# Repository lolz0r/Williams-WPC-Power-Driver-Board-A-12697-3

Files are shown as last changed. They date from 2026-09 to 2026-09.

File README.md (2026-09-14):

# Williams WPC power/driver replacement

> **WARNING: These are unverified, experimental boards. Use at your own risk.**
> No variant has been physically validated or qualified for production. Simulation
> results, CAD checks and manufacturing files do not establish safe or reliable
> operation. Errors may damage the board, connected equipment or pinball machine.
> Independently review the design and complete first-article testing before use.

This project develops a modern replacement for the Williams **A-12697-3 WPC
Power/Driver Board**, with **Star Trek: The Next Generation L7** as the documented
compatibility and emulation target. It provides rectified supplies, regulated
5 V and 12 V rails, 28 coil/flasher outputs, an 8×8 lamp matrix and five general
illumination triac channels. The board has no firmware. Compatibility with every
A-12697 installation has not been established.

## Variants and sourcing options

| Location | What it contains | Quantity and status |
| --- | --- | --- |
| [JLC-100](variants/jlcpcb-100/README.md) | Latest separate native KiCad variant, derived from JLC-3 with stocked alternative parts, mixed SMT/through-hole assembly files and connector-orientation guides. | Electronics selected for **100 boards plus spares**, using dated JLCPCB inventory snapshots. Experimental; software checks pass, physical and assembler acceptance gates remain open. |
| [JLC-3](variants/jlcpcb/README.md) | Earlier JLCPCB prototype with TPS552892 buck-boost supplies. Its CAD and exports are independent of JLC-100. | Prototype revision with procurement shortfalls. Its standard upload pair covers SMT; through-hole/manual parts and hardware use separate lists. |
| [DigiKey one-board sourcing proposal](variants/jlcpcb-100/output/digikey-1/README.md) | Alternative procurement BOM and itemized USD pricing based on the JLC-100 design. **This is not another released PCB or CPL.** | **One board, no production spares.** Some parts are proposed substitutes requiring engineering review; F115 remains unresolved and unpriced. |
| [Original cost-reduced project](docs/RELEASE_STATUS.md) at the repository root | Preserved parent CAD, earlier regulator design, simulation work and release-candidate exports. | Earlier engineering candidate with its own unresolved verification gates. Root `output/` does not contain the JLC-100 variant. |

Choose the variant first, then use its matching CAD, Gerbers, BOM and CPL.
Substitutions, packages and placement rotations differ between variants.
JLC-1/JLC-2 archives under `variants/jlcpcb/output/` are historical snapshots.

## JLC-100: Gerbers, BOM and centroids

For the latest JLCPCB variant, start with these files:

| File | Purpose |
| --- | --- |
| [Gerbers and drills ZIP](variants/jlcpcb-100/output/release-candidate/gerbers-and-drills.zip) | Bare-board fabrication layers and plated/non-plated drills. |
| [Combined electronics BOM.csv](variants/jlcpcb-100/output/release-candidate/jlcpcb-assembly/BOM.csv) | JLCPCB upload BOM covering all SMT and through-hole electronics, holders and fuse cartridges. |
| [Matching CPL.csv](variants/jlcpcb-100/output/release-candidate/jlcpcb-assembly/CPL.csv) | Matching component centers and corrected supplier placement rotations. Use with the combined BOM above. |
| [BOM/CPL bundle ZIP](variants/jlcpcb-100/output/wpc-JLC-100-BOM-CPL.zip) | Combined upload pair with assembly reference material. |
| [Complete prototype package ZIP](variants/jlcpcb-100/output/wpc-sttng-JLC-100-prototype.zip) | Native CAD, fabrication and assembly outputs, sourcing and recorded verification evidence. |
| [Complete components BOM](variants/jlcpcb-100/output/release-candidate/bom/all-components.csv) | Human-readable assembly/procurement record, including external hardware and zero-quantity DNP/board features. |
| [100-board electronics purchase BOM](variants/jlcpcb-100/output/release-candidate/bom/jlc-electronics-purchase.csv) | Order quantities and stock evidence, including procurement spares. This is not the upload BOM. |
| [External hardware BOM](variants/jlcpcb-100/output/release-candidate/bom/external-hardware.csv) | Heatsinks, screws, nuts and thermal paste for separate procurement and manual fitting. |
| [Native KiCad PCB](variants/jlcpcb-100/wpc_power_driver_cost.kicad_pcb), [schematic](variants/jlcpcb-100/wpc_power_driver_cost.kicad_sch) and [assembly preview](variants/jlcpcb-100/output/release-candidate/3d/perspective.png) | Source design and nominal assembled geometry. |

The combined upload pair describes **one board**. Select the production quantity
in the assembly order; do not multiply CPL entries or include purchasing spares
as placements. There are **440 electronic pieces per board: 345 SMT, 82 soldered
through-hole pieces and 13 inserted fuse cartridges**, grouped into 69 catalog
parts. J115 is purchased as two six-position headers. Separate fuse holders and
cartridges account for the other expanded references.

Read the [upload and manual-assembly instructions](variants/jlcpcb-100/docs/JLCPCB_UPLOAD.md)
and provide the [PCBA remarks](variants/jlcpcb-100/output/release-candidate/jlcpcb-assembly/PCBA-remark.txt).
The cartridge CPL entries use a documented 0.3 mm selection offset for stacked
parts; their physical centers remain at the holders. Heatsinks, fasteners and
paste are in the complete BOM but require separate sourcing and assembly
agreement. An accepted electronics upload alone does not establish complete
mechanical assembly.

Use the [connector orientation guide](variants/jlcpcb-100/output/release-candidate/jlcpcb-assembly/connector-orientation-guide.pdf)
and [preview review notes](variants/jlcpcb-100/docs/CONNECTOR_PREVIEW_REVIEW.md)
to resolve supplier-library discrepancies. The current CPL includes U1 = 90°,
U2/U3 = 270°, J110 = 180° and J113 = 90°; do not apply those offsets again.
J120/J121/J126 are present as C592598 / TE 1-640445-3 and need explicit part
selection and the documented header preparation. Several connector and rectifier
orientations still require assembler review.

For SMT-only work, use the separate [SMT BOM](variants/jlcpcb-100/output/release-candidate/bom/jlc-smt-bom.csv)
and [SMT CPL](variants/jlcpcb-100/output/release-candidate/assembly/jlc-smt-cpl.csv),
with the [through-hole/manual BOM](variants/jlcpcb-100/output/release-candidate/bom/jlc-through-hole-manual.csv)
for the remaining electronics. Generic engineering position reports are not the
assembly upload pair.

The JLC-100 fabrication specification is **four layers, 1.6 mm nominal FR-4,
2 oz finished outer copper / 1 oz inner copper** (70/35/35/70 µm), ENIG and at
least 20 µm finished plated-hole barrel copper. The outline is
449.152 × 272.910 mm. See [FABRICATION.txt](variants/jlcpcb-100/output/release-candidate/FABRICATION.txt)
and [READINESS.json](variants/jlcpcb-100/output/release-candidate/READINESS.json)
for the exact requirements and outstanding gates.

## DigiKey: one-board BOM and pricing

- [DigiKey BOM.csv](variants/jlcpcb-100/output/digikey-1/DigiKey-BOM.csv): original
  and proposed parts, order numbers, references, required/purchase quantities,
  through-hole parts, hardware and substitution notes.
- [Itemized pricing.csv](variants/jlcpcb-100/output/digikey-1/DigiKey-pricing.csv):
  per-part USD prices, quantity breaks, stock snapshots, product source links,
  extended costs and subtotal/complete-total rows.
- [Totals.csv](variants/jlcpcb-100/output/digikey-1/DigiKey-totals.csv): category
  subtotals, minimum-purchase overhead and missing-cost status.
- [DigiKey package ZIP](variants/jlcpcb-100/output/DigiKey-one-board.zip) and
  [sourcing explanation](variants/jlcpcb-100/output/digikey-1/README.md).

The September 14, 2026 estimate has a **$405.60 USD priced purchase subtotal**,
including minimum hardware purchase quantities. Parts allocated to one board
account for $363.30, including one complete thermal-paste syringe; $42.30 is
minimum-purchase excess. Freight, taxes, tariffs, PCB fabrication and assembly
are additional.

**This is a partial estimate: 78 of 79 required procurement lines are priced.**
F115's 0.75 A ceramic time-delay fuse remains required and unpriced, so the final
complete-BOM total is blank. The 28 priced candidate/accessory lines require
engineering review; the JLC-100 SPICE results do not qualify these substitutions.
No DigiKey-specific PCB, Gerbers or CPL has been released.

## Verification and reproduction

JLC-100 retains 230 passing ngspice engineering cases and recorded CAD,
manufacturing, inventory and assembly-file checks. These use engineering models,
including an averaged supply controller. They do not establish physical thermal,
fault, startup, harness-fit or production performance. Stock snapshots are not
reservations. Supplier part selection and manual operations remain review items.

See the variant's [simulation scope](variants/jlcpcb-100/docs/SPICE_SCOPE.md),
[inventory and assembly notes](variants/jlcpcb-100/docs/INVENTORY_AND_ASSEMBLY.md),
[first-article procedure](variants/jlcpcb-100/docs/FIRST_ARTICLE.md), and
[accepted verification manifest](variants/jlcpcb-100/output/release-candidate/reports/verification-manifest.json).
The later [native connector-tab audit](variants/jlcpcb-100/output/verification/revision/native-connector-tabs.json)
checks 37 single-row connector wall directions in nominal CAD; J113 and physical
cable compatibility retain the documented limitations. That audit and the
DigiKey proposal are additional repository records outside the existing complete
prototype ZIP.

Each variant's routed native PCB is authoritative. Open it with its adjacent
schematics, local symbols, footprints and models. Historical placement generators
and one-time migrations must not overwrite the routed source. Follow the chosen
variant's README and verification instructions when regenerating exports.

The large catalog-search cache is retained as lossless gzip; see the
[research storage notes](variants/jlcpcb-100/research/README.md) to unpack it.

The DigiKey CSVs can be regenerated from their saved pricing facts at the
repository root:

```sh
python3 variants/jlcpcb-100/tools/build_digikey_one_board.py
```

For the preserved parent project, use its [release status](docs/RELEASE_STATUS.md),
[verification instructions](docs/VERIFICATION.md), [Gerbers](output/release-candidate/gerbers-and-drills.zip),
[purchase BOM](output/release-candidate/bom/purchase-bom.csv),
[schematic PDF](output/release-candidate/schematic/schematic.pdf) and
[fabrication specification](output/release-candidate/FABRICATION.txt).
Older root exports directly under `output/` are superseded by the parent's
`output/release-candidate/`. The [historical design narrative](docs/HISTORICAL_DESIGN.md)
records earlier selections and estimates.

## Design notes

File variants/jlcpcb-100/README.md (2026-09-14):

# JLC-100 inventory variant

> **WARNING: These are unverified, experimental boards. Use at your own risk.**
> No physical board has been validated or qualified for production. Passing
> simulation and CAD checks do not establish safe or reliable operation. Errors
> can damage connected equipment; independently review and test a first article.

See the [repository overview](../../README.md) for the preserved parent project,
the earlier [JLC-3 prototype](../jlcpcb/README.md), and the separate
[one-board DigiKey sourcing proposal](output/digikey-1/README.md).

An independent KiCad variant of JLC-3, with electronics selected from public JLCPCB stock for **100 boards plus spares**. The original source files are preserved. Gerbers, drills, BOMs, centroids, schematic/assembly PDFs and a STEP assembly are generated from the updated native design.

**Status: software-checked engineering prototype.** The electronics stock audit passes; required heatsinks, fasteners and thermal paste are external purchases. These items are included in the complete assembly BOM, with heatsinks and fasteners represented in the assembly models. No stock is reserved, and no order has been placed. Physical first-article qualification remains necessary before committing the full run.

- [Complete package](output/wpc-sttng-JLC-100-prototype.zip)
- [Gerbers and drills](output/release-candidate/gerbers-and-drills.zip)
- **[JLCPCB combined SMT + through-hole BOM](output/release-candidate/jlcpcb-assembly/BOM.csv)** and **[matching CPL](output/release-candidate/jlcpcb-assembly/CPL.csv)**
- [BOM/CPL download bundle](output/wpc-JLC-100-BOM-CPL.zip) and [upload/manual assembly instructions](docs/JLCPCB_UPLOAD.md)
- [Complete procurement and hardware record](output/release-candidate/bom/all-components.csv)
- [100-board electronics purchasing BOM](output/release-candidate/bom/jlc-electronics-purchase.csv)
- [Optional SMT-only BOM](output/release-candidate/bom/jlc-smt-bom.csv) and [SMT centroids](output/release-candidate/assembly/jlc-smt-cpl.csv)
- [Through-hole/manual BOM](output/release-candidate/bom/jlc-through-hole-manual.csv) and [engineering placement details](output/release-candidate/assembly/electronics-placement-details.csv)
- [Native board](wpc_power_driver_cost.kicad_pcb), [schematic](wpc_power_driver_cost.kicad_sch) and [assembly preview](output/release-candidate/3d/perspective.png)

For the requested complete electronics assembly, use the combined BOM/CPL pair above. It describes one board and contains 440 matching references, including both J115 headers and separate fuse cartridges/holders. Select 100 boards in the assembly order; procurement spares are not extra placements. Copy [PCBA-remark.txt](output/release-candidate/jlcpcb-assembly/PCBA-remark.txt) into the order remarks: the cartridge CPL entries have a documented 0.3 mm selection offset for stacked assembly. The prior `all-electronics-positions.csv` filename now aliases the valid combined CPL; it must be paired with the new combined BOM. The [local upload audit](output/release-candidate/reports/jlc-assembly-check.json) checks file coverage, centers and library orientation evidence; live JLCPCB import and assembly acceptance have not been tested.

The design has **426 populated electronic references: 345 SMT and 81 through-hole**. Purchasing includes **440 electronic pieces per board**, accounting for separate fuse holders and the two-piece J115 header. Of the SMT placements, **204 are Basic**. All 69 electronic catalog codes pass a quantity check of 100 times per-board usage plus the larger of 10 pieces or 5% spares. The September 13, 2026 Pacific / September 14 UTC snapshots use the smaller of public stock and orderable quantity. The estimated electronics cost including spares is **US$8,524.49**; PCB fabrication, assembly, external hardware, shipping and tax are additional.

In assembly terms, those 440 purchased pieces are **345 SMT, 82 soldered
through-hole pieces and 13 inserted fuse cartridges**. The 81 native through-hole
references combine some holders/cartridges and represent J115 as one reference.
The [external hardware BOM](output/release-candidate/bom/external-hardware.csv)
adds heatsinks, fasteners and thermal paste; these require separate procurement
and agreement on fitting them.

The [connector orientation guide](output/release-candidate/jlcpcb-assembly/connector-orientation-guide.pdf)
and [preview review notes](docs/CONNECTOR_PREVIEW_REVIEW.md) explain the remaining
supplier-library/manual assembly gates. Current CPL rotations include U1 = 90°,
U2/U3 = 270°, J110 = 180° and J113 = 90°. The subsequent
[native connector-tab audit](output/verification/revision/native-connector-tabs.json)
checks 37 single-row headers in nominal CAD; J113 and physical cable fit retain
the documented limitations. This later audit is in the repository, outside the
existing complete prototype ZIP.

## Separate DigiKey estimate: one board

- [DigiKey BOM.csv](output/digikey-1/DigiKey-BOM.csv)
- [Itemized prices and total rows.csv](output/digikey-1/DigiKey-pricing.csv)
- [Cost breakdown.csv](output/digikey-1/DigiKey-totals.csv)
- [DigiKey ZIP](output/DigiKey-one-board.zip) and [scope/limitations](output/digikey-1/README.md)

This procurement proposal assumes **one board with no production spares**. Its
priced purchase subtotal is **$405.60 USD**, including minimum hardware order
quantities. It prices 78 of 79 required lines; F115's 0.75 A ceramic time-delay
fuse remains unresolved and unpriced. Proposed substitutes are flagged for
engineering review and are not qualified by the JLC-100 simulations. The proposal
does not change this variant's PCB, Gerbers or JLCPCB BOM/CPL.

## Recorded verification

The accepted verification contains **230 passing ngspice engineering cases**, covering supply startup/load/restart/prebias and tolerances, replayed drivers, GI, blanking, capacitor ripple and rectifier startup. Native ERC has zero violations. PCB DRC has zero errors, zero unconnected items and zero schematic parity issues; 178 warnings have documented dispositions. Independent Gerber/drill/BOM checks pass 7,909 checks; the inventory design audit passes 219 and the controller land-pattern audit passes 152. The mechanical review reports no collisions or missing models. Eight simultaneous rectifier thermal sensitivity cases pass their stated screening targets (SMT maximum 119.4°C; through-hole maximum 141.2°C at 50°C ambient).

The stiffest simulated crest-start case reaches **244.8 A in one rectifier leg against its 250 A single-pulse rating**. Real winding impedance, hot/cold starts, current sharing, loaded supply waveforms, thermal boundaries and harness fit require measurement. The SPICE models are engineering fits, including an averaged supply controller; they do not establish production qualification. Several stocked connectors need documented trimming/key preparation, and F112 is a soldered time-lag fuse.

Read [inventory and assembly instructions](docs/INVENTORY_AND_ASSEMBLY.md), [simulation scope](docs/SPICE_SCOPE.md), [first-article procedure](docs/FIRST_ARTICLE.md), [DRC warning review](docs/DRC_WARNING_REVIEW.md) and [original project audit](docs/ORIGINAL_PROJECT_AUDIT.md). The package contains dated stock evidence, exact model/deck/log files and checksums. `output/release-candidate/reports/verification-manifest.json` identifies accepted evidence; earlier rejected trials in the working tree are not accepted results.

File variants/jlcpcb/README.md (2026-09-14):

# JLC-3 prototype revision

> **WARNING: These are unverified, experimental boards. Use at your own risk.**
> No physical board has been validated or qualified for production. Simulation
> and CAD checks do not establish safe operation; errors can damage connected
> equipment. Complete independent review and first-article testing before use.

This is the earlier JLC-3 prototype. The separate [JLC-100 variant](../jlcpcb-100/README.md)
contains the later 100-board inventory selection and combined SMT/through-hole
BOM/CPL. See the [repository overview](../../README.md) for all variants and the
[one-board DigiKey proposal](../jlcpcb-100/output/digikey-1/README.md) for separate pricing.
Use files from one variant together; this directory's SMT pair is not the
JLC-100 mixed-assembly pair.

The current board uses TPS552892 buck-boost supplies and a reworked regulator layout.
See [prototype build and verification](docs/PROTOTYPE_JLC3.md) and
[release status](docs/RELEASE_STATUS.md).

Use these matching current exports:

- [Complete JLC-3 prototype package](output/wpc-sttng-JLC-3-prototype.zip)
- [Gerbers and drills](output/release-candidate/gerbers-and-drills.zip)
- [JLCPCB SMT BOM](output/release-candidate/bom/jlc-smt-bom.csv)
- [JLCPCB SMT centroids / CPL](output/release-candidate/assembly/jlc-smt-cpl.csv)
- [Through-hole/manual parts](output/release-candidate/bom/jlc-through-hole-manual.csv)
- [Complete components BOM](output/release-candidate/bom/all-components.csv),
  [electronics purchase BOM](output/release-candidate/bom/jlc-electronics-purchase.csv)
  and [external heatsinks/fasteners/paste](output/release-candidate/bom/external-hardware.csv)

`READINESS.json` and `SHA256.json` identify the exact validated output.
Older JLC-1/JLC-2 archives are historical. The original project at the repository root remains preserved.

For JLC-3 export/verification, run `tools/export_release.py`,
`tools/export_jlc_bom.py`, `tools/verify_release.py`,
`tools/verify_variant_source.py`, `tools/verify_regulator_fixtures.py`,
`tools/summarize_prototype.py`, `tools/verify_ryq.py`, then
`tools/package_prototype.py` with the project dependencies installed.
The simulator evidence is retained under `output/verification/prototype-readiness`.
Old generator and packaging commands in the historical section below describe JLC-2.

JLCPCB assembly needs the [flagged short-stock parts](output/release-candidate/bom/procurement-shortfalls.csv)
sourced before assembly. The bare-board fabrication package is complete.

---

## Historical JLC-2 notes

The following describes the previous revision. Links into `output/release-candidate/`
now resolve to the current JLC-3 export; use the dated JLC-2 archives for the older
snapshot. Historical quantities and component choices below do not describe JLC-100.

# WPC power/driver board — JLC-2

**JLCPCB electronics redesign, 2026-09-11. Engineering review candidate; not production qualified.**

This is a separate version of the STTNG L7 / Williams A-12697-3 replacement. All populated electronics have purchasable JLCPCB catalog matches. Heatsinks, fasteners and thermal paste retain their existing specifications and may come from other suppliers, as requested. The parent board and schematics are preserved.

JLC-2 includes the flasher-clamp correction found in the additional pre-spin review. **Hold an assembled prototype order:** regulator voltage/backfeed findings and lamp-matrix numerical convergence remain unresolved. The [latest analog-review addendum](docs/CONTINUED_ANALOG_REVIEW.md) establishes convergence of the selected coil replay and adds source-headroom and CPU switch-margin checks. The [earlier verification report](docs/PRESPIN_VERIFICATION.md) retains the original results and failures. Physical fit, thermal and fault qualification also remain open.

## Files to use

- [Native KiCad board](wpc_power_driver_cost.kicad_pcb), [project](wpc_power_driver_cost.kicad_pro) and [schematic](wpc_power_driver_cost.kicad_sch). Project-local symbols, footprints and STEP models are included.
- [Complete review archive](output/JLC-2-review.zip) and [native CAD archive](output/JLC-2-native-cad.zip).
- [Schematic PDF](output/release-candidate/schematic/schematic.pdf), [assembly drawing](output/release-candidate/assembly/assembly.pdf), [STEP assembly](output/release-candidate/3d/board.step), [top](output/release-candidate/3d/top.png) and [perspective](output/release-candidate/3d/perspective.png) renders.
- [Electronic purchase BOM](output/release-candidate/bom/jlc-electronics-purchase.csv). Upload the [SMT BOM](output/release-candidate/bom/jlc-smt-bom.csv) together with the [SMT placement file](output/release-candidate/assembly/jlc-smt-cpl.csv). Through-hole/manual parts and external hardware have separate lists in the same BOM directory.
- [Gerbers and drills](output/release-candidate/gerbers-and-drills.zip), [fabrication specification](output/release-candidate/FABRICATION.txt), [readiness](output/release-candidate/READINESS.json) and [verification report](docs/VERIFICATION.md).

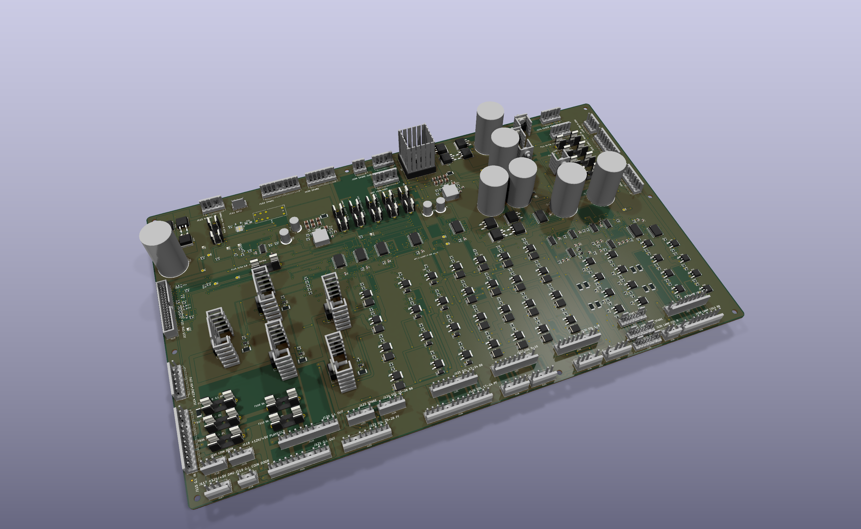
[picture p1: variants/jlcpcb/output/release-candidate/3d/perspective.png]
JLC-2 perspective


## What changed

| Change | Reason |
|---|---|
| SR1/SR2 replaced by R310–R325, sixteen Basic 4.7 kΩ 0805 resistors | Remove the Extended SIP arrays while preserving all sixteen used pull-up connections. The two unused array elements are omitted. New routing connects to the existing bus and +5 V copper. |
| Common 0805 resistors, 100 nF/10 nF/33 nF capacitors, LEDs and signal diodes use Basic parts | Preserve the required values, ratings and packages. |
| Eight flasher clamp diodes use Basic MDD M7 | Retain 1 A / 1000 V SMA rectifiers; additional SPICE wiring-inductance and temperature sensitivities included. |
| R192 changes from 270 Ω to Basic 470 Ω | Reuse an existing Basic value; +5 V LED current remains 4.95–7.74 mA over the checked voltage/tolerance range. Expect reduced brightness. |
| HCT buffers/latches use TI SN74HCT240DWR / SN74HCT574DWR | JLCPCB sourcing while retaining TTL input thresholds. HC parts are not equivalent at this interface. TI worst-case timing was checked. |
| C2/C4/C9/C12 use Panasonic EEU-FR1E331B | The **B suffix provides factory-formed 5 mm lead spacing**, matching the PCB. The 8 × 11.5 mm body model replaces the oversized model; pad positions and the conservative 10 mm courtyard are retained. |
| Molex ordering-number aliases resolved to purchasable listings | Same connector identities and geometry; consignment-only listings were rejected. |
| SOL21–SOL28 diode cathodes connected to +20 V on the board | STTNG leaves these tieback pins open. The added copper prevents the flasher harness from relying on MOSFET avalanche. No components added. |
| JLC-2 labels and portable libraries/models | Clearly identify the new revision and open it without the old Mac installation. |

Existing components retain their positions and pad geometry. JLC-2 merges SOL21–SOL28_TB into +20 V; other existing pad nets remain unchanged. The board remains 449.152 × 272.910 mm, four layers, 1.6 mm nominal, with **70/35/35/70 µm finished copper**, ENIG and at least 20 µm finished plated-barrel copper. Mounting geometry and the cooling arrangement are retained. R319 was relocated after an independent 3D check detected contact with the conservative fuse-holder envelope; the final model has no reported intersections.

## Sourcing result

| Inventory | Count |
|---|---:|
| Populated electronic references in the native design | 405 |
| SMT placements | 330 |
| Basic placements / distinct Basic codes | 194 / 15 |
| Extended SMT placements | 136 |
| Distinct Extended codes, including through-hole parts | 54 |
| Total distinct JLCPCB codes | 69 |
| Purchased electronic units, including separate fuse clips | 435 |

All 69 public listings were checked for `isBuyComponent=1`, exact normalized ordering-number match and Basic/Extended classification. A listing is not a reservation or assembly quote. **Twelve types need preorder or replenishment for one board**, including the 28 solenoid MOSFETs, large reservoir capacitors, bridge diodes and 32 fuse clips. Quantities, snapshot stock, dates and catalog links are recorded in the purchase BOM and [sourcing audit](output/release-candidate/reports/jlc-sourcing.json).

Extended parts remain where a suitable Basic replacement was not established: the 100 V logic-level power MOSFETs, rated rectifiers and reservoirs, HCT logic, regulators, precision feedback/UVLO resistors, C0G compensation capacitors, exact connectors and fuses. The Basic 470 pF candidates found were X7R, not the selected C0G compensation part. This is a documented selection, not a proof of the lowest possible cost across every future catalog entry.

## Assembly and qualification

The SMT upload pair covers only the 330 SMT references. Use [through-hole/manual BOM](output/release-candidate/bom/jlc-through-hole-manual.csv), [32 clip centers](output/release-candidate/assembly/fuse-clip-centers.csv) and [external hardware BOM](output/release-candidate/bom/external-hardware.csv) for the remaining assembly. F101/F102 take two clips each and **no cartridge**; F103–F116 take two clips plus the specified cartridge. There are fourteen cartridges total. Do not double-count the clips from the generic BOM.

JLCPCB's actual assembly preview must confirm rotation, polarity, pin 1, body centers and exposed-pad stencil treatment. CPL coordinates use the same absolute origin as the Gerbers, with negative Y and normalized native KiCad rotations. No order, upload or supplier message has been submitted.

Follow the retained [connector-key schedule](docs/ASSEMBLY_NOTES.md) and [first-article procedure](docs/ASSEMBLY_AND_FIRST_ARTICLE.md). **STTNG only:** J122 pins 5, 6, 8, 9 and J126 pins 10–13 now carry +20 V as flasher-clamp returns. These pins are unused in the STTNG harness; J126 pin 9 remains the key. Do not connect a different-voltage tieback harness. J106/J111 also retain the parent design's differences; this is not a universal A-12697 replacement. Nominal or conservative CAD envelopes cannot establish cabinet fit, harness access, screw engagement or tolerance clearance. The generic fuse-holder envelope is deliberately conservative and is not an exact Keystone 3517 solid model.

The routed native PCB is authoritative. Do not rerun the historical placement/project generators or one-time migration tools over it. `parts-selection-draft.json`, research alternatives and `docs/baseline/` are historical working material, not the purchasing or release authority.

Primary substitution references: [Panasonic formed-lead capacitor](https://industrial.panasonic.com/tw/products/pt/aluminum-cap-lead/models/EEUFR1E331B), [MDD M7](https://www.microdiode.com/uploadfiles/PDF/M1-THRU-M7-SMA.pdf), [TI HCT240](https://www.ti.com/lit/ds/symlink/sn74hct240.pdf), [TI HCT574](https://www.ti.com/lit/ds/symlink/sn74hct574.pdf). Every selected JLCPCB listing is linked in the purchase BOM.

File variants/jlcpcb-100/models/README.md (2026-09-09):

# Mechanical models

`tools/make_mechanical_models.py` generates project STEP envelopes using OpenCascade.
They are dimensional review aids, not manufacturer production CAD. Fin slots, lead
bends, fastener threads and nut profiles are simplified. Native KiCad component
models are resolved from the installed KiCad library; those models retain their
upstream licenses. No manufacturer CAD or vendor SPICE redistribution is implied.

Controlled dimensions come from TDK B41252, Nichicon LLS, Bourns SRP1265A, Molex
SDA-41791 and Boyd board-level cooling drawings. Current selected heatsinks are
577202B00000G, 7020BG and 6223BG. Older 7019/6224/5771 envelopes are historical
experiments and are not selected by the current board. Hardware envelopes include
M3×8, M3×12 and M4×16 screws/nuts. The native TO-220 leads are untrimmed.

The 3.96 mm headers now use dimensioned KK396 envelopes instead of scaled KK254
models. Stock full-pin headers still need OEM key-pin preparation. Models describe
nominal geometry; component tolerance, cabinet fit, solder and mating-harness access
are separate checks. See `docs/ASSEMBLY_AND_FIRST_ARTICLE.md`.

J113 uses the project N2534-6002-RB nominal envelope, including solder standoff.
`tools/connector_keys.py --models` makes keyed header variants by removing the
specified pin column. KK254 variants derive from the installed KiCad Connector_Molex
models; KK396 variants derive from the project dimensioned envelopes.
The original full-pin models remain available as manufacturing stock-part references.

The M4 hardware head envelope (7.6 mm diameter × 3.0 mm) conservatively bounds the selected Kanebridge MJ416MPP head (6.75 × 2.60 mm); shaft remains M4 × 16 mm.

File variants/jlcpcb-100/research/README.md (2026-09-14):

# Research snapshots

The selected-part evidence, inventory searches, orientation records and DigiKey
pricing facts are retained here. These are dated research inputs, not stock
reservations or component qualification.

The broad catalog-search cache is stored losslessly as
[search-index.json.gz](search-index.json.gz), because its uncompressed JSON exceeds
GitHub's regular-Git file-size limit. [search-index-storage.json](search-index-storage.json)
records both sizes and SHA-256 hashes. The uncompressed local copy is ignored.

To restore the JSON when needed, run from the repository root:

```sh
gzip -dk variants/jlcpcb-100/research/search-index.json.gz
```

The committed release artifacts and their selected-part evidence retain their
existing names and hashes. The compressed cache does not change the PCB, BOM,
CPL, Gerbers or recorded simulation results.

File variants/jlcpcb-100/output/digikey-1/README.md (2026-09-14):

# DigiKey sourcing estimate — one board

> **WARNING: These are unverified, experimental boards. Use at your own risk.**
> This sourcing proposal does not qualify the board or its substitute components.
> Independent engineering review and physical first-article testing are required.

Prepared 2026-09-14 in USD for **one populated board, without production spares**,
using the current `variants/jlcpcb-100` design as the source. The original variant
name does not change this quote's board quantity.

- [DigiKey-BOM.csv](DigiKey-BOM.csv): quantities, original and selected parts,
  DigiKey order numbers, all electronic references, hardware, and review notes.
- [DigiKey-pricing.csv](DigiKey-pricing.csv): itemized prices and purchase costs,
  followed by a priced subtotal and the unresolved complete-total row.
- [DigiKey-totals.csv](DigiKey-totals.csv): category subtotals, minimum-purchase
  overhead, exclusions, and completeness status.
- [source-reference-coverage.csv](source-reference-coverage.csv): maps every row
  in the source BOM to this sourcing BOM.
- [validation.json](validation.json): quantity, price and coverage checks, with
  hashes of the unchanged PCB and release inputs.

## Cost and completeness

| Amount | USD |
| --- | ---: |
| Priced electronics, including candidates | 300.65 |
| Hardware purchase quantities | 78.24 |
| One 3mL thermal-paste syringe | 14.33 |
| Added fuse-holder covers | 12.38 |
| **Priced purchase subtotal** | **405.60** |
| Parts allocated to one board, including the full paste syringe | 363.30 |
| Minimum-purchase excess included in the purchase subtotal | 42.30 |
| **Complete BOM total** | **Unresolved** |

**78 of 79 required procurement lines are priced. F115 is still required and
unpriced.** The specified Reomax 5.250.0750A is a 0.75A ceramic time-delay 5x20mm
fuse. No DigiKey replacement matching that requirement was verified. The
Littelfuse 0239.750TXP has a glass body and only 35A breaking capacity, so it was
excluded. Its price is not silently used to fill the gap. Compare the
[original Reomax specification](https://wmsc.lcsc.com/wmsc/upload/file/pdf/v2/lcsc/2303300930_Reomax-BTC0750_C5381743.pdf)
with the [DigiKey listing for the rejected fuse](https://www.digikey.com/en/products/detail/littelfuse-inc/0239-750TXP/3424896).

Prices are estimates from public DigiKey US product pages retrieved on
2026-09-14. The pages are cached, and their crawl ages are recorded per line.
They are not a live checkout quote or reserved inventory. All 78 priced lines
show sufficient stock for their purchase quantities in the recorded snapshots.
Every item includes its supporting product URL. Tax, tariffs, freight, fees,
PCB fabrication, assembly labor, tooling, and other process consumables are
excluded.

The five screw/nut lines have lowest published price tiers of 100 pieces. Their
purchase quantities are 100 each, even though the board uses only 1–9 of each.
The excess is reusable hardware stock. Other lines use the exact required
quantity, without rounding up to obtain price breaks. Cut tape is selected for
SMT parts; no Digi-Reel fee is included. Line amounts are rounded to cents using
decimal arithmetic before totals are summed.

## Design coverage and substitution limits

The source design has 440 purchased electronic units: **345 SMT, 82 soldered
through-hole units, and 13 fuse cartridges**. The BOM also includes 30 original
hardware pieces and one thermal-paste syringe provision. J115 buys two headers,
represented as J115A and J115B. There are 23 DNP or fabricated board features
shown with zero purchase quantity; those are excluded from pricing.

The proposed SCHURTER 0031.8201 holders need **15 separate 0853.0551 covers**,
including covers for the two empty holders. Their pairing is documented in the
[SCHURTER OGN drawing](https://media.digikey.com/pdf/Data%20Sheets/Schurter%20PDFs/DS_486_Fuseholders.pdf).
Fit to the existing Hongju footprint and surrounding parts still needs review.

There are 28 priced candidate/accessory lines and one unresolved requirement.
Candidates include replacement resistors, capacitors, diodes, LEDs, a transistor,
triacs, fuses, fuse holders, the J113 header, and the M4 screw. Their original
parts remain visible alongside the proposed DigiKey parts. The detailed review
requirements are in the BOM's Notes column.

Specific sourcing decisions:

- The original 10uF Samsung capacitor has zero stock in the retrieved product
  snapshot; a Taiyo Yuden 10uF/50V/X7R/1210 candidate is priced.
- The original BTA08-600CRG product page showed two units, despite a conflicting
  search snapshot showing 2002. The quote instead prices five BTA08-800CRG
  candidates. Review all trigger quadrants, pin/tab drawing and thermal ratings.
- F112 uses the proposed Bel Fuse 0680H7000-05, rated 7A and 125VAC/125VDC, with a
  slow-blow response. Time-current and protection coordination remain unverified.
  The initially considered Littelfuse 0454007.MR was rejected because its AC
  rating is 72V.
- D101–D104 use a proposed STPS40150CT 150V Schottky pair. Forward-loss and thermal
  performance must be checked against the original 100V part and its heatsink.
- Existing connector trimming/key-pin preparation and BR3 lead forming remain
  necessary where the original selected part is retained. The different J113
  housing needs its own fit and cable check.

This is a **sourcing proposal**, not a new released PCB variant. The existing
SPICE results qualify the existing modeled design and do not establish that
these proposed substitutions are equivalent. No PCB, Gerber, JLC BOM, or CPL was
changed, and no new DigiKey-specific CPL is implied. Engineering review and any
necessary design changes precede using these candidates for assembly.

Regenerate from the saved sourcing facts with:

```sh
python variants/jlcpcb-100/tools/build_digikey_one_board.py
```

Research inputs are in `variants/jlcpcb-100/research/digikey-1/`.

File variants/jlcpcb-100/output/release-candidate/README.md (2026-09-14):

# JLC-100 engineering prototype package

For complete SMT and through-hole electronics assembly, upload `jlcpcb-assembly/BOM.csv` and `jlcpcb-assembly/CPL.csv` with `gerbers-and-drills.zip`. The matching pair contains all 440 electronic pieces per board (345 SMT plus 95 THT/inserted parts). Use `jlcpcb-assembly/PCBA-remark.txt` and `placement-map.csv` for separate fuse holders/cartridges and prepared connectors. Read `docs/JLCPCB_UPLOAD.md` before confirming the assembly preview. JLCPCB live import/assembly acceptance has not been tested here.

The complete September 14 orientation audit changes 76 SMT and 18 further connector angles relative to the last uploaded CPL. U1=90°, U2/U3=270°, J110=180° (inward friction wall), J113 remains 90°. `jlcpcb-assembly/connector-orientation-guide.pdf` shows all 39 purchased headers, physical pin 1, tab/notch direction and removed key posts. `component-orientation-check.csv` covers all 440 entries / 69 purchased codes. `orientation-change-log.csv` records the exact delta. The corrected native connector models retain unused posts and remove only the explicit key post.

Unresolved supplier data is explicitly flagged: 15 headers have conflicting pad/model orientations, ten C505166 headers lack 3D housings, three C592598 headers have no public library, D101–D104 have invalid supplier 3D frames, and BR3 requires native polarity/formed-lead placement. The assembler must resolve these against the native guide before manufacture. J120/J121/J126 also require selection of the matched C592598 row and manual preparation. See `docs/CONNECTOR_PREVIEW_REVIEW.md`.

`bom/all-components.csv` is the human-readable complete assembly record, including external heatsinks/fasteners/paste. The 100-board purchasing list is `bom/jlc-electronics-purchase.csv`. These procurement records are not the upload BOM. Heatsinks and fasteners also appear in CAD assembly models; their procurement and fitting require a manual quotation. SMT-only exports remain available under `bom/jlc-smt-bom.csv` and `assembly/jlc-smt-cpl.csv`.

Read `READINESS.json`, `docs/INVENTORY_AND_ASSEMBLY.md`, `docs/SPICE_SCOPE.md` and `reports/verification-manifest.json`. This package passes the recorded software checks; it is not qualified for an untested 100-board production run. Stock is a public dated snapshot, not a reservation. No order has been placed.

The `cad/` project contains the actual selected parts, including all through-hole parts, individually annotated parallel capacitors, fuseholder fields and the two-piece J115. Library footprints/models are local. The accepted simulation reports retain their original run hashes and explicit engineering-model limitations.

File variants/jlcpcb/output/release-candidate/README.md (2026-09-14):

# JLC-3 controlled prototype

Upload the matching `gerbers-and-drills.zip`, `bom/jlc-smt-bom.csv` and
`assembly/jlc-smt-cpl.csv` to JLCPCB. See `READINESS.json` and
`docs/PROTOTYPE_JLC3.md` for build scope, settings and first-article checks.
Through-hole/manual parts and hardware are listed separately in `bom/`.
Editable KiCad 10 sources, libraries and models are in `cad/`.
This package supports building a test prototype; physical qualification remains to be performed.

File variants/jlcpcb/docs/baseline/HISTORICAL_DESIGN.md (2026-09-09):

# Historical design narrative — superseded

Use [RELEASE_STATUS.md](RELEASE_STATUS.md) for current parts, limits and verification.
The following narrative is retained as development history, not build instructions.

# WPC Power Driver Board - cost-optimised modern version

**Current revision (2026-09-08): [release status and verification evidence](RELEASE_STATUS.md).**
The schematic/PCB mismatches have been repaired and the board now specifies **2 oz finished outer / 1 oz inner copper**.
Updated manufacturing files and native 3D renders are in `output/release-candidate/`.
**This is an unreleased engineering candidate:** regulator reverse-current, thermal and physical qualification gates remain open.
The complete review archive is `output/wpc-sttng-engineering-candidate.zip`; see
[reproduction instructions](VERIFICATION.md) and [component sourcing](SOURCING_REVIEW.md).
J106 and J111 differences prevent a universal drop-in compatibility claim.

The remaining sections document the original cost-reduction design and earlier revisions;
component choices, dimensions and verification claims below are superseded where the current release status differs.

A cost-reduced variant of `../wpc_power_driver_modern/` (the modern-component functional replacement for the Williams WPC Power Driver
Board **A-12697-3**).  Same 449.2 x 272.9 mm outline, every connector, fuse, bridge rectifier, big capacitor and mounting hole in its
original position and with the original pin-outs, so it still drops into a WPC cabinet with the original harness.  The design goal was a
**quantity-100 parts cost of about 105-115 USD** with **no Chinese-brand parts** (DigiKey/Mouser-stocked Infineon, TI, Nexperia, Vishay,
Diodes Inc, Toshiba, ST, Rubycon, Nichicon, Panasonic, Molex, 3M, Littelfuse, Keystone, Bourns, Yageo, Samsung, Lite-On) and **robust
margins kept** (SPICE-verified, see below).

**Machine-level review (2026-09-06)**: the board was then checked against the real WPC interface of a *Star Trek: The Next Generation*
machine - the WPC schematic manual 16-9834.2, the STTNG operations manual, pinwiki, PinMAME and FreeWPC (`docs/WPC_INTERFACE_FINDINGS.md`,
every fact with its source).  Four of the design's interface assumptions were wrong and have been corrected: the ribbon data bus is
**active low**, the **J113 pin-out** was invented, the **"+50 V" rail is ~70 V DC**, and the **+12 V topology** (regulated from +20 V through the
3/4 A fuse to everything) did not match the machine.  See "Interface findings and corrections" below.

Everything is script-generated with the same tool-chain as the modern board: `python3 tools/gen_project.py` (schematics, `.kicad_pro`,
netlist), `NO_ZONES=1 python3 tools/gen_pcb.py` (placed board), `python3 tools/bom_report.py` (BOM + cost roll-up),
`flatpak run --command=python3 org.kicad.KiCad tools/spice/run_all.py` and `python3 tools/spice/compare.py` (SPICE suite + comparison).
Design: `tools/design_cost.py`, sourcing table: `tools/sourcing.py`, placement: `tools/placement_cost.py`.

## What changed versus the modern board, and why

| block | modern board | cost board | why / effect |
|---|---|---|---|
| solenoid / flasher MOSFETs (28) | IRLB4030PBF TO-220 (100 V, 4.3 mOhm) | **Infineon IRLR3110ZTRPBF** DPAK (100 V, 14 mOhm @10 V / 16 mOhm @4.5 V, logic level), same 100 R gate / 10 k pull-down / SMA-SMC tie-back | reel-priced SMD part, ~40 % of the modern MOSFET cost; drop 0.23 V instead of 0.07 V at 12 A (still 7x better than the 1993 TIP36C) |
| lamp rows (8) | IRLZ44NPBF TO-220 (22 mOhm) | **Infineon IRLR024NTRPBF** DPAK (55 V, 65 mOhm @10 V / 78 mOhm @5 V) | cheapest logic-level DPAK from an allowed brand that is in stock; row drop 0.62 V incl. the 0.22 R sense (was 0.51 V) |
| lamp columns (8) | IRF9Z34NPBF TO-220 (100 mOhm) | **Infineon IRFR5305TRPBF** P-DPAK (-55 V, 65 mOhm @-10 V) | cheaper and lower Rds(on): column drop 0.12 V (was 0.20 V) |
| bridges | 4 x GBPC3510 (35 A block) + GBU4J-BP (MCC) | BR3 +50 V: **GBPC3510W-E4/51** (wire leads) under a Boyd 6224BG basket heatsink; the +18 V, +20 V, +5 V raw and +12 V power bridges are **discrete Schottky bridges of four ST STPS20M100SG-TR** (100 V, 20 A, D2PAK) each: D101-D104, D109-D112, D105-D108, D113-D116 (2026-09-07 thermal review, `docs/THERMAL_AND_PROTECTION.md`) | a GBJ1510 block dissipated 15 W at full lamp load with no way to heat-sink it on the board; the Schottky bridge halves the loss and spreads it over four D2PAK tabs cooled by 2-10 cm2 pours; +0.5 V on every low-voltage rail |
| big electrolytics | 4 x 15000 uF / 35 V (Rubycon 25 x 45 mm) | C5, C6, C7, C11: **Rubycon 25USC10000MEFCSN25X25** (10000 uF / 25 V, 25 x 25 mm); C8/C32 2 x 2200 uF / 100 V kept | rails are 9-20 V so 25 V parts have the same 20-25 % margin the 35 V parts had at 20 V; one part number for all four |
| +5 V / +12 V bucks | 2 x TPS54560BDDAR (5 A) | 2 x **TI TPS54360BDDAR** (60 V, 3.5 A, same HSOP-8 pin-out); +5 V rated 3 A, +12 V 2 A; same SRP1265A-100M / B560C | the CPU/DMD/sound loads are < 3 A; feedback (10.5 k / 28 k over 2 k, Vref 0.8 V), RT (240 k -> 405 kHz) and compensation recomputed from the TPS54360B datasheet (below) |
| fuses | 3AG (6.3 x 32 mm), Littelfuse 313/312 + 102071 clips | **5 x 20 mm**: Littelfuse **239 series Slo-Blo** 0239007 / 0239005 / 0239003 / 0239.750 and **0217008** (8 A fast) in **Keystone 3517** clips; each fuse centred on the original 3AG position (see below) | clip + fuse cost roughly halves |
| test points TP1-TP9 | Keystone 5000 | plain 2.0 mm plated pads (`TestPoint_THTPad_D2.0mm_Drill1.0mm`), no purchased part | -9 parts |
| **interface corrections (machine-level review, see below)** | true data bus, invented J113 map, 36 VAC solenoid winding, +12 V buck from +20 V feeding J114-J118 via F115, active-low zero cross, triac MT1 grounded | **U9 74HCT240** data inverter + **SR2** pull-ups, real J113 map, 51 VAC / ~70 V decks with 2 x 15 k bleeder and S3M tie-backs on the coil groups, **+12 V digital buck from +18 V -> F115 -> J114 only**, **+12 V power (BR5 GBU8J, C30 10000 uF) -> J116/J117/J118**, active-high zero cross, **GI_RET** return bus with W1, J111 GPIO, TP6/TP8 names | +3.4 USD at qty 100; without them the board would have fired every coil on a 0x00 write, clocked the wrong groups and lost the switch matrix with the coin door open |
| everything else | | unchanged: 74HCT574 / 74HCT74 / LM339 logic, TBD62083A column driver, BTA16-600CRG triacs with MMBT4401 emitter-follower drive, all connectors and pin-outs, 0805 / 2512 passives, SMA / SMC / SOD-123 diodes, LEDs, relay option (DNP), 4-layer stack, netclasses | |

## Interface findings and corrections (machine-level review)

Full record with sources: `docs/WPC_INTERFACE_FINDINGS.md`.  Summary of what the machine really does and what changed:

| item | what the machine does (source) | design before | now |
|---|---|---|---|
| BLANKING (J113-31) | HIGH = every 74LS374 tri-stated (OC pin 1), pulled up on the driver board (R227 4.7 k), driven low by an open-collector 2N3904 on the CPU board only while the ASIC watchdog is kicked; on for ~1-3 s at power-up (LED D19) - pinwiki, schematic 16-9834.2 | HIGH = disabled on the 74HCT574 /OE, 470 R pull-up | unchanged polarity, SR1 = 4.7 k |
| J113 ribbon | 7 /LMP ROW, 8 /LMP COL, **9 /SOL 2 = sol 17-24, 10 /SOL 4 = sol 1-8, 11 /SOL 3 = sol 9-16, 12 /SOL 1 = sol 25-28**, 13 /TRIAC, 15-29 odd = D7-D0, 31 BLANKING, 34 ZERO CROSS; 1/3/5/32/33 = flipper-opto sense of the -1 board (N/C on -3), 2 N/C, other even = GND - schematic sheet 1 + 3 (wire-traced) | strobes on odd 1-13 in a guessed order, ZC on 33 | real map |
| data polarity | the CPU board drives the ribbon data through a 74LS240 (U12): **active low**; the driver latches take it directly (LOW = on through the PNP pre-drivers), only the column latch U18 re-inverts it (U9 74LS240 + ULN2803); firmware writes 1 = on (PinMAME, FreeWPC) | true bus into 74HCT574 (a 0x00 write would have turned all 28 MOSFETs on) | U9 = 74HCT240 inverts /D0-/D7 into the board's true bus, SR2 4.7 k pull-ups (OEM: SR1 470 R on the data lines) |
| zero cross (J113-34) | the D38 half-wave sample of the F113-fused 9 VAC leg on U6A pin 7 (+) against a 0.45 V reference (sheet 1 at 600 dpi; U6C on the other leg is redundant): **a 60 Hz square wave, HIGH while that leg is positive (~8 ms), one edge per crossing** - a real TP4 measures ~8.1 ms pulses (Pinside topic 22018); PinMAME's 120/s flag = both edges | active-low 1.3 ms pulse, then (wrongly) an active-high 120 Hz pulse | corrected 2026-09-06: R197 samples the fused 9 VAC leg (AC9_AF) into U6A + with the 0.26 V reference on -, R198 DNP -> 60 Hz square wave, 7.3 ms high, edges 0.5 ms after / before the crossing |
| solenoid supply | 51.4 VAC winding (STTNG measured 55.2 VAC unloaded): **"+50 V" is 70-75 V DC** (pinwiki TP6) | 36 VAC / 50 V in every deck | decks at 72.7 V peak: AE-23-800 draws 16.6 A, IRLR3110Z 0.31 V / 5.2 W per pulse (+2.8 C per pulse, +52 C at 20 % duty); bleeder 2 x 15 k 2512 (0.7 W); S3M tie-backs on sol 9-16 / 25-28 (PWM-held coils freewheel 1.3 A average); 100 V MOSFETs / diodes / capacitors keep >= 17 V of margin at the 83 V high-line peak; TP6 = +50 V, TP8 = +18 V as on the factory schematic |
| +12 V | regulated "+12 V digital" comes from the **+18 V lamp rail** (7812, F115 3/4 A) and feeds only J114 (CPU switch matrix, Fliptronic, 8-driver); **J116/J117/J118 pin 2 carry the unregulated "+12 V power"** (BR5, C30 15000 uF, F116) for motors, optos, coin door and DMD - STTNG's two gun motors sit on J118 - pinwiki, schematic, manual wire colours; the coin-door interlock kills +20 V and +50 V | buck from +20 V -> F115 -> J114 + J116/J117/J118 (the gun motors through a 3/4 A fuse; switch matrix dead with the coin door open) | U21 from +18 V -> F115 -> J114 only; BR5 = GBU8J, C30 = 10000 uF/25 V, +12VU -> J116/J117/J118 pin 2 (pin 4 = +5 V as on the original) |
| G.I. | hot ends J115-2..6 -> one fuse each -> strings; returns -> triac MT2, **MT1 -> J115-7/8/10/11/12 (winding return), J115-1 = GND REF** | MT1 and all return pins on the ground plane | GI_RET bus (5 x MT1 + 5 return pins) tied to logic ground by the 0 R link W1: the 25 A of string return current stays off the ground plane |
| lamp matrix timing | one column at a time, **2 ms per column, 16 ms frame** (FreeWPC lamp.c); bit = 1 selects the column / lights the row | 2 ms / 16 ms already used in the trip deck | new `lamp_strobe` deck (thermal #555 filaments): column DPAK 8 A peak / 0.23 W, row 1 A peak / 0.08 W, lamps see 6.17 V RMS (original Darlington board: 5.53 V, rating 6.3 V) |
| G.I. dimming | IRQ (976 Hz) writes the triac latch on and immediately off N ms after the crossing, level = 7 - N, the triac conducts to the next crossing (FreeWPC triac.c, PinMAME) | continuous gate drive only | new `gi_dim` deck: 5 us latch pulse -> 78 mA gate current -> string RMS 96 / 84 / 34 % at levels 6 / 4 / 1, both half-cycles (quadrant IV), no DC component |
| solenoid timing | 4 ms refresh slots, pulses of n x 4 ms, PWM holds 1/8..8/8 (FreeWPC sol.c); "most solenoids don't have a holding coil so the software simulates it by pulsing" (PinMAME) | 40 ms pulses | `sol_hold` deck: 100 % hold 4.8 A / 0.43 W (+21 C), 50 % PWM 3.2 A average / 0.27 W, diode 1.3 A average |
| J111 | G.I. latch bits T5-T7 on pins 1-3, key 4, GND 5 (GPIO, shot-clock drive on later games) | N/C | wired |
| +5 V load | CPU + DCS sound (J114) + DMD controller/display (J117) + Fliptronic + 8-driver: 2.2-2.6 A estimated, original LM323K rated 3 A behind a 5 A fuse | 3 A buck (4.5 A minimum current limit) | unchanged, 15-35 % margin over the estimate |

Agreement with the modern-board review: same conclusion on the active-low data bus (implemented there with 74HCT564 latches, here with one
74HCT240), on ZERO CROSS = pin 34, BLANKING = 31, data on 15-29, on the strobe map (7 / 8 / 9 / 10 / 11 / 12 / 13 - both generators agree since the
coordinator's re-read of J211) and on the data-line pull-ups.  The one disagreement that survived - the zero-cross waveform - was settled
2026-09-06 in favour of the modern board's reading (60 Hz square wave; see `docs/VERIFICATION_MATRIX.md` section 16) and this board was changed.

Still unverified / open before a first article: the J115 pin-to-string order (hot pins 2-6 / return pins 7-12 are certain, the order is
not - the manual's colour table is inconsistent), the 239-series 7 A melting I2t (313 value as stand-in; every inrush result is < 5 % of it),
the real +5 V and +12 V power currents of a given machine, the J111 GPIO polarity (N/C on STTNG), the D2PAK Rth on 2 oz copper (the ST curve
is for 35 um; the +18 V bridge diodes are estimated at ~120 C with all 64 incandescent lamps lit and ~75 C on an LED machine), and the
solenoid MOSFET drain copper (rated for <= 10 % duty of an AE-23-800; larger drain pours do not fit the 2 mm component spacing).

### Buck converter values (TPS54360B, datasheet SNVSB93 section 8.2.2)

gm(ea) = 350 uA/V, gm(ps) = 12 A/V (TPS54560B: 17 A/V), Vref = 0.8 V, current limit 4.5 A minimum / 5.5 A typical, fsw = 405 kHz with
RT = 240 k (Rt = 101756 x fsw^-1.008).  Output filter 2 x 330 uF Panasonic FR (45 mOhm each) + 10 uF = 670 uF / 22 mOhm.

| | fp_mod = Iout / (2 pi Vout Cout) | fz_mod = 1 / (2 pi Resr Cout) | fco = sqrt(fp_mod x fsw/2) (eq. 47) | Rc (eq. 48) | Cc (eq. 49) | Cp (eq. 50) | EN/UVLO divider |
|---|---|---|---|---|---|---|---|
| +5 V, 3 A (U20) | 142 Hz | 10.7 kHz | 5.3 kHz | 33.2 k | 33 nF | 470 pF | 118 k / 29.4 k: start 5.9 V, stop 5.5 V nominal (see "UVLO thresholds" below) |
| +12 V, 2 A (U21, input = +18 V lamp rail) | 40 Hz | 10.7 kHz | 2.8 kHz | 42.2 k | 100 nF | 390 pF | 130 k / 20 k: start 8.8 V, stop 8.4 V nominal |

The datasheet's other crossover option (eq. 46, geometric mean of modulator pole and ESR zero: 1.2 kHz / 650 Hz) was simulated first: with the
large electrolytic output filter it gave Rc 7.68 k / Cc 150 nF and 10 k / 470 nF, a 4.69 V dip on a 1 -> 3 A step and a +12 V rail that
needed > 10 ms to reach its set point after soft-start.  Eq. 47 keeps the crossover below fsw/10 and between the modulator pole and the ESR
zero, as the method requires, and gives 4.90 V / 11.80 V on the load steps (U21 now simulated from 13.5 V, the +18 V rail at full lamp load).

### UVLO thresholds (brownout analysis)

TPS54360B EN pin: threshold Vena = 1.2 V (1.1-1.3 V), the pin *sources* 1.2 uA below and 4.6 uA above the threshold, so
Vstart = Vena + R1 (Vena/R2 - 1.2 uA) and Vstop = Vena + R1 (Vena/R2 - 4.6 uA) (datasheet eq. 40/41).  The raw +5 V rail (9 VAC winding,
GBU8J, C5 = 10000 uF) was swept with the averaged buck model (`tools/spice/uvlo_sweep.py`, table in `output/spice/uvlo_sweep.md`):

| mains | 100 % | 90 % | 88 % | 85 % |
|---|---|---|---|---|
| raw minimum at 2 A (V) | 9.10 | 7.67 | 7.38 | 6.93 |
| raw minimum at 3 A (V) | 8.34 | 6.80 | 6.48 | 5.98 |
| raw ripple p-p at 3 A (V) | 1.03 | 1.17 | 1.20 | 1.26 |

The converter regulates 5.0 V down to Vin = 5.6 V.  A divider like the modern board's first attempt (start 7.2 V) would switch the +5 V
off in any brownout below ~92 % at 3 A; even the modern board's final 82 k / 20 k (stop 5.74 V nominal, 6.25 V at Vena = 1.3 V) leaves
only 0.23 V worst-case margin at 88 % / 3 A because the cost board's raw rail is ~0.6 V lower (10000 uF, higher-Rs GBU8J).  Chosen: **118 k /
29.4 k -> start 5.9 V / stop 5.5 V nominal (6.4 / 6.0 V at Vena = 1.3 V, 5.4 / 5.0 V at 1.1 V)**: the stop level sits just below the
5.6 V regulation limit, so in a deep brownout the converter droops (Vout = 0.97 Vin - 0.5) instead of shutting down, and at 88 % / 3 A the raw
minimum (6.48 V) is 1.0 V above the nominal and 0.5 V above the worst-case stop level; at 85 % / 3 A (5.98 V) it reaches the regulation
limit anyway.  +12 V: **130 k / 20 k -> start 8.8 V / stop 8.4 V** (9.5 / 9.1 V worst case), well under the 10.3 V that the +18 V rail keeps at
88 % mains with all 64 lamps lit; the +12 V digital then droops to 9.5 V rather than dropping out (the original 7812 would have delivered ~7 V
there).  The stress decks model both stop levels with a smooth 0.5 (1 + tanh((Vin - Vstop) 40)) factor (5.6 V / 8.5 V, i.e. the Vena = 1.22 V values).

### Fuse position check

`tools/gen_pcb.py` places every footprint by its pad centroid.  The Keystone 3517 footprint (pads at 0 / 6.76 / 16.35 / 23.11 mm, centroid
11.555 mm) and the 3AG 102 clip footprint (0 / 7.62 / 26.59 / 34.21 mm, centroid 17.105 mm) both have their centroid at the fuse centre, so
every 5 x 20 mm fuse sits centred on the original 3AG position; `.scratch/placed.json` of both projects agrees to <= 0.12 mm for all
sixteen positions (F106-F108 moved 0.12 mm during the courtyard relaxation).  Fuses, bridges, connectors and the C5/C6/C7/C11/C30
capacitors are now anchored (`fixed`) in the relaxation so they cannot drift.

## Cost

`output/bom/BOM-cost.md` (one DigiKey link per line item, qty-1 and qty-100 columns, cost by group) and `output/bom/bom_*.csv`
(`kicad-cli sch export bom` with Reference, Value, Footprint, Manufacturer, MPN, Link, Price, Price100, Description).  Qty-1 prices are the
DigiKey/Mouser single-unit prices seen during sourcing where they were visible (a `~` marks the 266 small parts - mostly 0805 passives -
that carry an estimate so the roll-up is complete).  Qty-100 prices are estimates for buying 100 boards' worth (reel / 1000-piece breaks
for the parts used 8-32 times per board, 100-piece breaks otherwise; where no break was visible: 0.55-0.7x qty-1 for semiconductors,
0.3x passives, 0.6x connectors / electromechanical).  Fuse clips (32) and the five triac heatsinks are included as synthetic lines.

| group | parts | per board, qty 1 (USD) | per board, qty 100 (USD) |
|---|---|---|---|
| MOSFETs (44 DPAK) | 44 | 77.20 | 32.48 |
| Connectors (KK-396 / KK-254 / box header) | 38 | 30.96 | 20.04 |
| Electrolytic capacitors | 7 | 21.70 | 13.65 |
| Fuses + clips (16 positions) | 46 | 27.67 | 10.00 |
| Buck converters (IC, inductor, diode) | 6 | 14.48 | 9.30 |
| Bridge rectifiers (BR3 GBPC3510W + 16 x STPS20M100S) | 17 | 32.28 | 13.02 |
| Triacs + gate transistors + heatsinks (5 x 7019BG, 6224BG + M3 / M4 hardware) | 28 | 26.10 | 17.33 |
| Logic / comparators / driver (incl. U9) | 15 | 9.42 | 5.25 |
| SMD passives (incl. SR1/SR2, 0.1 % +5 V feedback divider) | 195 | 26.10 | 4.73 |
| Diodes + LEDs (S3M on the coil groups) | 37 | 13.82 | 5.11 |
| Misc (test points) | 15 | 2.98 | 1.32 |
| **components per board** | **448** | **282.71** | **132.23** |

The qty-100 total (**~132 USD**: 115 USD before the 2026-09-07 thermal review, which replaced the four low-voltage bridges by 16 STPS20M100S Schottky
diodes (+8.3 USD net of the GBJ / GBU parts) and added real Boyd heatsinks and hardware for the triacs and BR3 (+7.9 USD net of the 1.75 USD of clip-on
sinks, `docs/THERMAL_AND_PROTECTION.md`) - the chassis heatsink of the original board was never in the cost target; 112 USD before the interface corrections: +0.42 U9, +0.35 SR2, +1.2 C30 10000 uF, -0.2 BR5 GBU8J, +1.56 S3M x 12,
+0.16 bleeder/link) sits at the top of the 105-115 USD target of `../wpc_power_driver_modern/output/bom/COST-ESTIMATE-Q100.md`.
The biggest uncertainties are the 28 IRLR3110Z (0.78 USD assumed at reel quantity; every 0.10 USD moves the board by 2.80 USD) and the
connectors (18 USD; the five N/C spare headers J108/J109/J110/J111/J123 could be omitted for another ~2.5 USD).  Not included: the bare
4-layer PCB, assembly, thermal compound, M4 hardware for the mounting holes.

## SPICE verification

`flatpak run --command=python3 org.kicad.KiCad tools/spice/run_all.py` runs twenty-one ngspice decks (`tools/spice/decks/`) and writes
`output/spice/RESULTS.md` (**211 / 211 checks pass** after the 2026-09-07 thermal review `docs/THERMAL_AND_PROTECTION.md`, which turned the
four low-voltage bridges into STPS20M100S Schottky bridges and raised the +5 V set point to 5.10 V; see the table and `docs/VERIFICATION_MATRIX.md`,
which maps every machine integration point to its evidence and check) plus waveform CSVs; `python3 tools/spice/compare.py` writes `output/spice/COMPARISON.md`
(modern vs cost).  Model notes: level-1 MOSFET fits to the DPAK datasheets (IRLR3110Z ~18 mOhm at the 4.6 V HCT gate drive, IRLR024N ~80 mOhm
at 4.6 V, IRFR5305 65 mOhm at -10 V), a TPS54360B behavioural peak-current-mode model (12 A/V, 4.5 A minimum current limit, 400 kHz), bridge
elements with a higher series resistance than the 35 A block (GBJ15 60 mOhm, GBU8 80 mOhm, Vf ~1.3 V modelled at rated current - pessimistic),
and - since the machine-level review - the real WPC interface: the 51.4 VAC solenoid winding (72.7 V peak, 0.6 ohm per leg; the STTNG transformer
measured 55.2 VAC unloaded), the "9.8 VAC" +12 V power winding at its measured 12.47 VAC unloaded (0.25 ohm per leg), 2 ms lamp column strobes
with thermal #555 filaments, IRQ-timed 5 us triac writes, 4 ms PWM coil holds, the +12 V digital buck on the +18 V rail, the active-high zero
cross, BLANKING as the CPU drives it, and switch-on inrush against the Littelfuse melting I2t.  Every limit in `run_all.py` carries its
justification.  Machine-level decks and their key numbers:

| deck | what it proves | key numbers (limit) |
|---|---|---|
| `powerup` | +5 V soft-start with random latch contents, BLANKING high for 200 ms as the CPU holds reset, then released with the latches holding 1, then written 0 | coil / G.I. / column current while blanked 13 nA / 10 uA / 0.1 nA (<= 10 / 50 / 10 mA), BLANKING never below 5.0 V (>= 4 V), then 16.6 A coil / 6.6 A string / 5.3 A column when released, 0 after the write |
| `sol_high` | AE-23-800 (4.2 ohm) 40 ms pulse on the 70 V rail | 16.6 A, Vds 0.31 V (<= 0.45), 5.2 W during the pulse (<= 7.5), 0.185 J (<= 0.3), +2.8 C per pulse (<= 6, Zth 0.6 C/W), +52 C at 20 % duty (<= 75 on 1 sq. in. copper) |
| `sol_low` | AE-26-1200 (10.8 ohm) pulse | 6.5 A, 0.12 V, 0.77 W (<= 1.5) |
| `sol_hold` | 100 % hold of a 14.5 ohm coil for 3 s; FreeWPC 50 % PWM hold (4 ms / 4 ms) of an AE-26-1200 | 4.8 A / 0.43 W / +21 C (<= 40); PWM 3.2 A average, 5.5 A peak, 0.9 A minimum (continuous), 0.27 W, S3M freewheel 1.28 A average (<= 2, IF(AV) 3 A), 7.6 A peak |
| `lamp_strobe` | 8 columns x 2 ms, 8 lamps per column, thermal filaments; row with all 8 lamps lit; the original Darlington path for comparison | column IRFR5305 8.0 A peak / 0.67 A average / 0.43 V / 0.23 W (+12 C), row IRLR024N 1.0 A peak / 0.51 A average / 0.08 W, sense 0.19 V (no false trip), cold first strobe 2.3 A, lamp RMS 6.17 V (5.5-6.6; original board 5.53 V) |
| `gi_dim` | the board's own zero-cross detector + an ASIC edge model + firmware timing (levels 0 / 3 / 7, gate held vs 8 us pulse), both half-cycles, BTA16-600C Q IV | level 0 4.68 A rms; level 7 pulsed 0.69 A rms (1.35 / -3.70 A peaks), no DC component; a bit held through the crossing re-fires (as on the OEM) |
| `zero_cross` | the corrected detector on the F113-fused 9 VAC leg (GBU8J + 10000 uF at 3 A) | 60 Hz square wave, 7.3 ms high, edges +0.53 / -0.50 ms from the true crossings, 5.0 V / 0.16 V, 4 us rise |
| `gi_gate` (checks added) | gate drive, triac on-state (Vt0 0.85 V / 25 mOhm) dissipation and junction temperature with the Boyd 7019BG bolt-on heatsink (thermal review 2026-09-07) | 78 mA gate, 3.3 W; junction rise 51 C (61 C at the 4.5 A string of `gi_string`) with the 11 C/W 7019BG - the earlier 577002 clip is a 32 C/W part and would have given 114 C |
| `bridge_loss` (new, 2026-09-07) | conduction loss and junction temperature of the bridges: four STPS20M100S Schottky diodes per low-voltage rail on 2-15 cm2 pours (per-diode loss 0.425 IF(AV) + 0.0088 IF(RMS)^2), BR3 GBPC3510W under a 6224BG basket, at the sustained design loads and the fuse-limit loads | +18 V diodes 1.92 W each / 107 C with all 64 incandescent lamps lit (a GBJ1510 block was 15 W / 208 C), +20 V 73 C, +5 V raw 67 C, +12 V power 75 C, BR3 117 C at 3 A; DPAK checks re-based on the as-routed 110 C/W (tab pad only): 20 % duty machine-gun 163 C (< 175 C absolute) |
| `gi_string` (new) | 18 x #44 cold start through F106 (239 5 A) and the triac, fired at the peak | 39 A peak, 9.2 A2s = 3 % of the 302.8 A2s melting I2t, 4.54 A rms steady |
| `ribbon` (new) | 6809E write -> ASIC 375 ns strobe -> 74LS240 (active-low) -> ribbon (4.7 k pull-ups) -> U9 74HCT240 -> 74HCT574 (XSPICE) -> IRLR3110Z; unplugged; BLANKING high | setup 145 ns / hold 154 ns (needs 20 / 5), write 1 -> ON, write 0 -> OFF, latch tri-stated (< 2 nA) when unplugged or blanked |
| `psu` | rails with the real windings (Schottky bridges) | "+50 V" idle 69.2 V (66-74), 41.6 V average / 35.5 V minimum during the 16 A pulse; +18 V 15.3 V; +5 V raw 10.0 V minimum, +5 V 5.10 V (4.86 V at the CPU with 3 A through 80 mOhm); +12 V digital 12.00 V from +18 V; +20 V 17.8 V minimum under a 4 A flasher burst |
| `psu_maxload` | everything on | +18 V 11.9 V minimum with 64 lamps -> +12 V digital 11.0 V (>= 10.5; original 7812 ~10 V); +12 V power 10.5 V at 2.5 A (>= 10); +20 V 12.1 V during the 54 A flasher inrush; six coils at once 37.8 A, rail 14.1 V, bridge 37 A (400 A surge); BR5 GBU8J 7.2 A peaks |
| `psu_brownout` | 88 % mains | +5 V raw 6.48 V (>= 6.0), +5 V 5.00 V; +18 V 10.3 V -> +12 V digital 9.5 V (>= 9); +12 V power 9.1 V (>= 8.5) |
| `psu_12vu` | +12 V power rail | 10.5 V minimum / 11.1 V average / 1.06 V ripple at 2.5 A; 15.9 V unloaded maximum (25 V capacitor); 9.3 V with the manual's nominal 9.8 VAC (pessimistic) |
| `inrush` | switch-on at the mains peak into every capacitor | fuse peaks F113 33 A, F114 52 A, F111 47 A, F116 25 A, F112 53 A; I2t 1.5 / 7.1 / 4.1 / 1.2 / 6.7 A2s = 0.5 / 3.6 / 1.3 / 0.6 / 1.9 % of the melting I2t (239 5 A 302.8 A2s, 217 8 A 198 A2s, 313 3 A / 7 A 200 / 347 A2s as stand-ins) - all <= 20 %; bridge peaks far below GBU8J 200 A / GBJ1510 240 A / GBPC3510 400 A |
| `buck_5v`, `buck_12v` | switching-model loops | 4.90 V undershoot on 1 -> 3 A, 3.65 A peak inductor current (< 4.5 A limit); +12 V from 13.5 V: 11.80 V on 1 -> 2 A, 3.23 A peak |
| `flasher`, `lamp_matrix`, `lamp_matrix_trip`, `gi_gate` | block-level checks from the modern suite | unchanged: 6.6 A cold flasher inrush, 0.12 V column / 0.62 V row drop, 8.4 A row fault cleared 0.16 ms after the strobe, 78 mA triac gate |

What the interface corrections cost in margin: the 70 V rail triples the pulse dissipation of the high-power DPAKs (5.2 W for 40 ms instead of
2.9 W; still +2.8 C per pulse, and +52 C for a coil machine-gunning at 20 % duty on 1 sq. in. of copper), the +12 V digital rail follows the
+18 V lamp rail down to 11.0 V with all lamps lit (original: ~10 V) and 9.5 V at 88 % mains, and the +12 V power rail sits at 10.5-11 V with
2.5 A of motors and optos on 10000 uF (a 15000 uF C30 like the original would add ~0.4 V).  Lamps run brighter than on the 1993 board
(6.17 V RMS vs 5.53 V, rating 6.3 V), so incandescent #555 life is roughly a third - irrelevant with LEDs.

## Sourcing notes

* **IRLR024NPBF** (tube) is out of stock at DigiKey with no back-orders; the tape-and-reel **IRLR024NTRPBF** (DigiKey 812549, "ships today";
  Mouser 1.02 USD) is used.  Alternatives checked and rejected: IRLR2905 (3000-piece minimum / back-order), onsemi NTD/NVD5867NL (obsolete).
* **IRFR5305PBF** (tube) is out of stock; **IRFR5305TRPBF** (DigiKey 811407, Mouser 1.98 USD) is used.
* **Nichicon LGN1E682MELZ** does not exist at DigiKey; the 6800 uF / 25 V candidates that do (Nichicon LLS1E682MELZ 22 x 30 mm, Rubycon
  25USC6800MEFCSN22X25) are both out of stock / back-order, so C5 uses the same in-stock **Rubycon 25USC10000MEFCSN25X25** as C6/C7/C11
  (more capacitance on the buck input, one part number for four positions).
* **VS-KBPC2510 / GBPC2510** for BR3: the Vishay GBPC2510-E4/51 is more expensive (8.35 USD) than the GBPC3510-E4/51 (6.36 USD, 4.26 USD at
  100), the Diodes GBPC2510 is obsolete and the stocked KBPC2510 alternatives are Chinese brands (Comchip, SMC), so BR3 keeps the 35 A Vishay
  block - as the **wire-lead GBPC3510W-E4/51** (DigiKey 605926; the lug-terminal GBPC3510-E4/51 listed until 2026-09-07 does not fit the wire-lead footprint).
  The GBJ1510-F / GBU8J-E3/51 entries below are no longer used: since the thermal review the +18 V / +20 V / +5 V raw / +12 V power bridges are four
  **ST STPS20M100SG-TR** (100 V, 20 A Schottky, D2PAK, DigiKey 2122461: 1.58 USD @1, 0.52 @1000) each - a GBJ1510 at 15 W could not be cooled on the board.  Diodes Inc **GBJ1510-F** (1.22 USD at 100) is used for BR1/BR4; the GBJ package has no KiCad library footprint, so
  `footprints/wpc_cost.pretty/Diode_Bridge_GBJ.kicad_mod` was written from the Diodes DS21221 outline (30 x 20 x 4 mm, leads `+ ~ ~ -` at
  10.0 / 7.5 / 7.5 mm, 1.3 mm drills) and registered in `fp-lib-table`.
* **GBU4J-BP** (MCC) was first replaced by Vishay GBU4J-E3/51 (Chinese-brand rule); after the machine-level review BR5 became a **GBU8J-E3/51** (the +12 V power rail feeds motors and optos, up to the 3 A of F116).
* **Fuses**: the Littelfuse 218 series (IEC, 250 V) has no 7 A, 3 A or 3/4 A ratings (6.3 / 3.15 / 0.8 A only), so the UL **239 Slo-Blo**
  series with the exact original ratings is used: 0239007.MXP (7 A, 125 V), 0239005.MXP (5 A, 125 V), 0239003.MXP (3 A, 250 V),
  0239.750MXP (3/4 A, 250 V); the 8 A fast fuse is 0217008.MXP (217 series, 250 V).  125 V is ample for the <= 36 VAC / 50 VDC secondaries;
  the 239 series is rated 10 kA interrupting at 125 V.  Clips: Keystone **3517** (0.32 USD at 1, 0.18 at 100, 0.13 at 5000) instead of the
  Littelfuse 520-series clip (no PCB-clip part number could be verified).
* **TPS54360BDDAR**: DigiKey 10434703, 4.52 USD at 1.
* DigiKey product pages block automated fetches, so prices come from search-result snippets and distributor listings; qty-100 prices are
  estimates (see `tools/sourcing.py` for the rule used per part).  Nothing on the BOM is from a Chinese brand.

## Board

* Same outline, stack-up (4-layer, In1.Cu GND plane), mounting holes and keep-out drawings as the modern board; **2 oz outer copper** is now a
  requirement (`docs/FABRICATION_NOTES.md`).
* `DEOVERLAP_MARGIN=2.0 PLANE_ONLY=1 python3 tools/gen_pcb.py` writes the placed board; `wpc_power_driver_cost.kicad_pcb` as delivered is
  **fully routed and production-finished (2026-09-07)**: `kicad-cli pcb drc` with the project net classes reports **0 violations,
  0 unconnected items** (`output/reports/drc.rpt`; the remaining warnings are short dangling pad-entry stubs, seven small isolated pour
  islands, six hole-to-hole spacings and the intended bolt hole H9 inside BR3's courtyard); ERC: 0 errors (`output/reports/erc.rpt`).
* **Power distribution copper (2026-09-07 rework)**: a copper audit of the first routed board found the +5 V, +18 V, "+50 V", G.I. and
  return paths on 1.6 mm / 1.0 mm tracks partly on the 1 oz inner layer (+5 V buck-to-J114 78 mOhm, +50 V bridge-to-capacitor 42 mOhm,
  the whole G.I. return on one 1.6 mm track and a single via).  The router (`../wpc_power_driver_modern/tools/fastroute.py`) got two new
  classes that are confined to the 2 oz outer layers - **Bus** 3.0 mm (+18V, +50V, +20V, +5V, +5V raw, +12V power, all AC legs, G.I.
  strings) and **Heavy** 5.0 mm (G.I. return) with a 1.6 / 0.8 / 0.4 mm neck-down chain at 0.4 mm clearance - plus a 1.6 mm outer-layer
  **Coil** class for the 28 solenoid outputs, a board-edge keep-out and a per-cell width rule (a wide track may not end inside another
  net's clearance zone).  Measured on the finished board (`copper_resistance.py`, DC, 20 C): +5 V C4 -> J114 **52 mOhm** (was 78),
  +18 V bridge -> column MOSFET sources **14.8 mOhm** (27), bridge -> C6 8.4 mOhm, +20 V bridge -> J107/J106 5.1 mOhm, +12 V power
  bridge -> J116/J117/J118 21 mOhm (67), G.I. string J115 -> fuse 2.8 mOhm (17), G.I. return J115 -> triac MT1 4.0 mOhm.
* **Discrete Schottky bridges**: BR1/BR2/BR4/BR5 are four D2PAK STPS20M100SG each (`docs/THERMAL_AND_PROTECTION.md` section 8), on the old
  bridge spots (BR1 quad at x 350/363 y 40/61, BR2 quad below C8 at x 290/311 y 114/128, BR4 at x 281/302 y 12/26, BR5 at x 17/30 y 19/40;
  `tools/placement_cost.py` POS_MM).  Project footprint `wpc_cost:D2PAK_Schottky_AKA` (tab = pad 1 = cathode, both leads = pad 2 = anode
  as in the ST drawing "A K A").  Each tab sits on a 2 oz heat-spreading pour on F.Cu and B.Cu joined by a 3 x 3 via array
  (`tools/rail_pours.py`; filled area F+B: +18 V 9.6 cm2 shared by D101/D102, AC13 legs 7.8 / 8.7 cm2, +20 V 4.5, AC16 legs 3.8 / 10.3,
  +5 V raw 3.3, AC9 legs 2.4 / 2.3, +12 V power 6.4, AC98 legs 3.4 / 3.4).  With the ST Rth(j-a) curve (35 um copper, 2 oz taken as
  0.9x) the +18 V diodes reach about 120 C at the full 64-incandescent-lamp load (1.9 W each) and 75 C with 3 A (LED machine, or half
  the lamps); the other three bridges stay below 90 C at their fuse ratings.  BR3 (+50 V) keeps the GBPC3510W block with the Boyd 6224BG
  basket heatsink and the new 5.5 mm bolt hole H9.
* Placement changes versus the A-12697-3 drawing, all connectors kept: **U1 rotated 180 deg** (see below), **J129 2.5 mm left** (its housing sat inside mounting hole H6's courtyard), **B13** (U13 bypass) moved left of U13, **C21** (10 nF zero-cross
  filter, had no drawing position and was missing from the first board) next to U6, three SMT **fiducials** FID1-FID3, silkscreen legend
  with fuse ratings and connector functions (`tools/legend.py`).
* Interface corrections from `docs/INTERFACE_PARITY.md` applied to the copper: J125 key at pin 4, J128/J129/J131/J132 added at their
  drawing positions, J105 = copy of J104, J120/J121 carry all five G.I. strings, J123 = sol 25-28, J126-10..13 = SOL21..24_TB,
  J103-3/4 grounded, J107-5 = +20V, J108 = fused +50V.  Net-list changes are applied to the routed board with
  `../wpc_power_driver_modern/tools/update_nets.py` (rename-aware, strips only the changed nets' copper) and re-routed incrementally.
* U1 (the G.I. / triac latch) is rotated 180 deg relative to the original board: with GI_BIT5 / GI_BIT6 -> J111 its pins 13/14 had to
  cross GI5_L inside the U1 channel, where the CPU data-bus lines on In2.Cu leave no via slot and D7 / BLANKING occupy B.Cu.
* Hand-routed links (after the router gave up): the U21 buck EN pin, D6 into U1, the U13 clock/D0/ROWCLR1 knot (clock fed through pin 3
  and an under-body link to pin 11), D4 into U11, SOL21_L, the +12 V power link into R250, two GND stitches at J103.
* Flow: `tools/pipeline.sh` (generate, stitch, route, repair, finish, export) or, for a routed board, `tools/finalize.sh` (GND stitch vias,
  rail pours + thermal vias, `finish_board.py`: dedupe, PowerPAD via arrays, outer GND pours, refill, dangling-stub trimming, legend,
  final DRC) followed by `bash tools/export.sh`.

## Renders (`output/3d/`)

`kicad-cli pcb render --quality high` of the placed board: `wpc_power_driver_cost-top-4k.png` (3840 x 2160, zoom 1.05),
`wpc_power_driver_cost-perspective-4k.png` (`--perspective --rotate "-35,0,20" --zoom 1.15 --floor`), `wpc_power_driver_cost-bottom-4k.png`
and `wpc_power_driver_cost-top-1080p.png`.  3D models: the project GBJ footprint carries the KiCad Diotec 32 x 17 mm bridge model scaled to the
GBJ body (30 x 20 x 4 mm); four library footprints reference STEP files that are not shipped in this KiCad 3D package and get stand-ins in
`tools/kicad_pcb.py` (render only): Keystone 3517 clips -> Schurter 0031.8201 open 5 x 20 mm holder (with fuse), SRP1245A -> Bourns SRR1260
(scaled 1.04), Texas HSOP-8 -> generic HSOP-8-1EP, Omron G2RL-2 (DNP) -> G2RL.  The KK-396 headers use the KK-254 model scaled 1.56 as on the
modern board.  Only the eight M4 mounting holes and the nine plated test pads have no model (nothing to show).

Renders and Gerbers were regenerated from the routed board on 2026-09-06.  Also not verified: live DigiKey prices (see above), the GBJ footprint against a physical part (the coordinator's note quoted a 21.5 x 20 mm / 5 mm-pitch GBJ; Diodes DS21221, read directly, gives 30 x 20 x 4 mm with 10 / 7.5 / 7.5 mm lead gaps - the footprint follows the datasheet), the thermal behaviour of the DPAK
solenoid drivers on the final copper (the SPICE limits assume ~1 sq. in. of copper per DPAK tab), and the TPS54360B loop on a first article.

## Verification audit (2026-09-06)

`docs/VERIFICATION_MATRIX.md` lists every integration point with the rest of the machine with its evidence and check (211 / 211 checks after
the Schottky-bridge change of `docs/THERMAL_AND_PROTECTION.md`, which also flags the 1.6 mm GI_RET return bus and the +18 V winding tracks as
layout items for the re-route).  Two real design errors were found on this board and corrected in `tools/design_cost.py` (schematic regenerated,
ERC 0; no footprint added or removed - R198 is now DNP - so the placed board only needs its rat's nest refreshed):

* the zero-cross detector produced a 120 Hz active-high pulse; it now reproduces the OEM 60 Hz square wave
  (`R197-1: AC98_A -> AC9_AF`, `R198-1: AC98_B -> AC9_B` + DNP, `U6-4 <-> U6-5` swapped so the sample is on +);
* J104 carried the unfused 51 VAC winding; it now carries the F112-fused leg on pin 1 and the F111-fused 16 VAC leg on pin 4
  (`J104-1 ACSOL_A_F, -2 ACSOL_B, -4 AC16_A_F, -5 AC16_B`; F113-2 / BR2-3 = `AC9_AF`, F112-2 / BR3-3 = `ACSOL_A_F`, F111-2 / BR4-3 = `AC16_A_F`
  are now global nets, same copper).

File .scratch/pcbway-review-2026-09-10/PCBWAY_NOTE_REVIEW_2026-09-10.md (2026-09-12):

# PCBWay note review — 2026-09-10

Source: `T-1P16W167063A-5units-purchase-bom(2026-09-10).xls`, Sheet1, column M. All 11 nonempty note rows are covered. Item numbers below are column A; worksheet row numbers are also provided.

All 107 quoted part lines match the current [purchase BOM](../output/release-candidate/bom/purchase-bom.csv) for reference, MPN, quantity and footprint. The 17 direct electronic references on noted rows also match the native PCB and schematic MPNs. Fuse clip counts were checked against all 16 native fuse footprints. Mechanical decisions use the current [assembly instructions](ASSEMBLY_AND_FIRST_ARTICLE.md) and [hardware model source](../tools/make_mechanical_models.py).

These are recommended actions and draft replies, not sent confirmations or purchase commitments. Five-board quantities exclude separately agreed spares. The original workbook and design files are unchanged.

| Item (XLS row) | Component / assembly | PCBWay note | Design comparison | Recommended action |
| --- | --- | --- | --- | --- |
| 1 (row 3) | BR3 — GBPC3510W-E4/51 | This part is in short supply. Please confirm ASAP. | Native BR3 PCB and schematic specify GBPC3510W-E4/51. The wire-lead package, metal base and separate 6223BG heatsink are part of the design. | Retain GBPC3510W-E4/51, 1 per board / 5 total. Ask PCBWay to allocate the quoted stock and confirm delivery. Do not change to a terminal-lug GBPC package. |
| 11 (row 13) | D101 D102 D103 D104 — STPS20M100ST | The quoted part number is [STPS20M100ST], not [577202B00000G] as specified in description; Reference designator [D101,D102,D103,D104] is duplicated in other lines,pls confirm. | D101-D104 are four STPS20M100ST diodes. Each native footprint includes a separate Boyd 5772 heatsink model and an M3x8 hardware model. The physical diode leads are A-K-A; PCB pad numbers are 2-1-2. | Keep 4 STPS20M100ST diodes AND 4 Boyd 577202B00000G heatsinks per board. The repeated diode references identify the heatsink attachment sites. Label the mechanical line HS_D101 through HS_D104 in the procurement worksheet, with the attachment mapping retained. Keep all four live-cathode heatsinks separate. |
| 14 (row 16) | F111 F113 F106 F107 F108 F109 F110 — 0239005.MXP | This part is in short supply. Please confirm ASAP. | F106-F110, F111 and F113 all specify Littelfuse 0239005.MXP, 5 A Slo-Blo, in the native PCB and schematic. Seven fuses per board is correct. | Retain 0239005.MXP and request allocation of 35 pieces. Keep the specified 239-series time-delay characteristic and 5x20 mm size; a fast-acting 5 A fuse is not an equivalent. |
| 15 (row 17) | F112 — 0239007.MXP | Only 20pcs total in stock, please confirm ASAP. | F112 specifies 0239007.MXP, 7 A Slo-Blo, one per board. PCBWay reports 20 pieces in stock; the five-board build requires five before any separately agreed spares. | Retain the exact part and request allocation of 5 pieces. The reported stock is sufficient for this build; do not buy all 20 solely because they are available. |
| 58 (row 60) | U9 — 74HCT240D,653 | The part we can get here was made in the year of 2023. | U9 requires 74HCT240D,653, the HCT inverting buffer in wide SO20, matching the native PCB. As of 2026-09-10, 2023 stock is within four years. Nexperia’s 2026 letter states up to 48 months shelf life under specified storage and soldering conditions; its two-year shipment limit is a separate manufacturer shipping policy. [Nexperia, 10 March 2026](https://www.nexperia.com/dam/jcr:fd376cfd-eac6-4325-87b3-944530721a58/Product%20Shelf%20Life%20Guarantee%202026.pdf). | Accept genuine, unused 2023-date-code stock if PCBWay confirms traceable sourcing, proper storage, intact leads and suitable solderability. Request the actual date/lot label. If storage or condition cannot be established, source newer stock of the same MPN. No blanket age-based bake instruction is needed. |
| 79 (row 81) | U19 — TBD62083AFWG,EL | The quoted part number is [TBD62083AFWG,EL], not [ULN2803] as specified in description | The native U19 PCB and schematic explicitly specify TBD62083AFWG,EL in SOIC-18W. ULN2803 appears only as a pin-compatibility comparison in the description; it is not the selected part. | Retain TBD62083AFWG,EL. Remove the ULN2803 comparison from the procurement description to eliminate ambiguity. Do not substitute a Darlington ULN2803. |
| 87 (row 89) | F101 F102 — 3517 | There is a discrepancy between the quantity of reference designators listed [2] and the specified quantity [4]. Please confirm. | F101 and F102 each have four solder holes accommodating two individual two-pin Keystone 3517 clips. The assembly instructions require clips at both locations with no fuse cartridges fitted. | Keep quantity 4 per board / 20 total: 2 clips at F101 and 2 at F102. Leave both fuse positions empty of cartridges. Optional procurement identifiers: F101_CLIP1, F101_CLIP2, F102_CLIP1, F102_CLIP2. |
| 98 (row 100) | F103-F116 clips — 3517 | There is a discrepancy between the quantity of reference designators listed [14] and the specified quantity [28]. Please confirm. | The fourteen F103-F116 footprints each accept two individual Keystone 3517 clips. Their fuse cartridges are separate BOM items 13-17. | Keep quantity 28 per board / 140 total. Combined with item 87, order 32 clips per board / 160 total. Ask PCBWay to consolidate purchasing and reconcile the different quoted unit prices for the same 3517 MPN, while retaining both assembly mappings. |
| 102 (row 104) | BR1 hardware — MPMS 003 0008 PH | The quoted part number is [MPMS 003 0008 PH], not [M3X8] as specified in description; There is a discrepancy between the quantity of reference designators listed [2] and the specified quantity [4]. Please confirm.; Reference designator [BR1,hardware] is duplicated in other lines,pls confirm. | MPMS 003 0008 PH is the selected M3x8 Phillips pan-head screw. Four separate D101-D104 heatsink assemblies need one screw each; BR1 hardware is an assembly label. The matching four M3 nuts are included in the nine-per-board MHNZ 003 line, item 103. | Keep 4 screws per board / 20 total. M3X8 is the size/value, not another MPN. Relabel this mechanical line SCREW_D101 through SCREW_D104 to prevent reference-token counting and duplicate-reference warnings. Retain the separate nuts. |
| 104 (row 106) | Assembly consumable; one syringe per build batch — 8616-3ML | [It's out of stock. Please recommend substitutes or you can supply this part to us.] | The design specifies MG Chemicals 8616 grease as a batch consumable at all ten device/heatsink interfaces per board. The current manufacturer datasheet lists 8616-85ML as the same 8616 material in a tube. The modeled interface allowance still requires assembly validation. [MG Chemicals, 19 March 2026](https://mgchemicals.com/downloads/tds/tds-8616.pdf). | Request a quote for 8616-85ML, one tube shared across the batch, as a packaging-only replacement for 8616-3ML. Use a thin continuous film at all specified interfaces. If unavailable, source the original 8616 externally. Do not omit paste or substitute an unspecified adhesive/pad. Supplier stock and price for the alternate remain to be confirmed. |
| 106 (row 108) | BR3/H9 hardware — MJ416MPP | [It's out of stock. Please recommend substitutes or you can supply this part to us.] | The selected screw is M4x16 JIS-B1111 Phillips pan, zinc-plated steel; the BOM lists a 6.75 mm head diameter and 2.60 mm height. The native hardware model bounds a 7.6 mm diameter x 3.0 mm head, with a 4 mm shaft. BR3 uses a separate H9 5.5 mm PCB hole and a 6223BG heatsink with a 4.14 mm hole. MHNZ 004 nuts remain in item 107. | Ask PCBWay to quote a local equivalent: M4x0.7 thread, 16 mm under-head length, zinc-plated steel, JIS-B1111 small Phillips pan head matching the original dimensions. Require a supplier drawing before selecting the actual substitute; head maximum must stay within the existing 7.6 mm diameter x 3.0 mm CAD envelope. Verify free passage through the 4.14 mm heatsink hole, clamping, nut engagement and underside clearance during assembly. An unspecified M4x16 screw is insufficient. |

## Draft customer replies

Copy these into column N only when ready to communicate the selected dispositions. No reply has been sent.

| XLS row / item | Draft reply |
| --- | --- |
| 3 / 1 | Please retain Vishay GBPC3510W-E4/51: 1 per board, 5 pieces for this order. Please confirm allocation and delivery. The W wire-lead package is required; its 6223BG heatsink is purchased separately in item 100. |
| 13 / 11 | STPS20M100ST is correct for D101-D104: 4 diodes per board, 20 total. 577202B00000G is the separate heatsink in item 101: 4 per board, 20 total. Both lines are required. The shared references identify the attachment sites, not duplicate diodes; item 101 may be labelled HS_D101, HS_D102, HS_D103, HS_D104. Fit one separate heatsink to each diode, using item 102 screws and item 103 nuts. Follow the A-K-A footprint and live-cathode heatsink assembly instructions. |
| 16 / 14 | Please retain Littelfuse 0239005.MXP, 5 A Slo-Blo 5x20 mm: 7 per board, 35 total, for F106-F110, F111 and F113. Please confirm allocation and delivery. No fuse-family or speed substitution. |
| 17 / 15 | Please retain Littelfuse 0239007.MXP: 1 per board, 5 total. Your reported 20-piece stock covers the five-board requirement; please allocate 5 and confirm delivery. Retain the 7 A Slo-Blo 5x20 mm specification. |
| 60 / 58 | 2023 date code is acceptable for the five U9 devices provided they are genuine, unused Nexperia 74HCT240D,653, traceably sourced and properly stored, with sound leads and solderability. Please confirm these conditions and provide the lot/date label. Use the wide SO20 HCT part specified in the BOM. If the storage history or condition cannot be established, please quote newer stock of the same MPN. |
| 81 / 79 | Toshiba TBD62083AFWG,EL is correct: 1 per board, 5 total. Please use this exact DMOS driver. ULN2803 was only a pin-compatibility comment and is not a requested component or an approved substitute. Please remove that comparison from the procurement description. |
| 89 / 87 | Quantity 4 is correct: each of the two fuse positions F101 and F102 uses two individual Keystone 3517 clips. Supply 4 clips per board, 20 total. Fit the clips and leave F101/F102 without fuse cartridges. Each 3517 is one clip, not a complete two-clip holder. |
| 100 / 98 | Quantity 28 is correct: F103-F116 are 14 fuse positions, each needing 2 individual Keystone 3517 clips. Supply 28 per board, 140 total, in addition to item 87. Total 3517 requirement across both lines is 32 per board / 160 pieces. Fuse cartridges are separate items 13-17. Please consolidate purchasing of the 160 identical clips and reconcile the two quoted unit prices without losing the assembly mappings. |
| 104 / 102 | MPMS 003 0008 PH is correct; M3X8 describes the screw size, not a second part number. Quantity 4 per board / 20 total is correct: one screw for each D101-D104 heatsink assembly. BR1 hardware is an assembly label, not two reference designators. Please label these SCREW_D101, SCREW_D102, SCREW_D103, SCREW_D104. The four corresponding M3 nuts are included in item 103 along with five triac nuts; those are separate required parts. |
| 106 / 104 | Please quote MG Chemicals 8616-85ML as the packaging alternative to 8616-3ML; the formulation must remain 8616. One tube is a shared consumable for the entire five-board build, not one tube per PCB. Apply a thin continuous film at the four D101-D104, five triac and one BR3 heatsink interfaces on each board. Please confirm availability and price. If the 8616 formulation is unavailable in either package, leave this sourcing item open for external supply rather than fitting the heatsinks dry. |
| 108 / 106 | Please quote a locally sourced equivalent to MJ416MPP: zinc-plated steel M4x0.7 x 16 mm machine screw (length measured under the head), JIS-B1111 small Phillips pan head matching the original 6.75 mm diameter / 2.60 mm height specification. Provide the actual part drawing for review; the maximum head dimensions must remain within 7.6 mm diameter x 3.0 mm height. Quantity is 1 per board / 5 total. Retain MHNZ 004 nuts in item 107. Confirm free fit through the 6223BG 4.14 mm hole and verify clamping, nut engagement and underside clearance at assembly. Do not assume any M4x16 head style is interchangeable. |

The two unavailable lines have no quoted component price. Request a revised quote after the grease package and screw are selected. The exact original or replacement stock remains for PCBWay to confirm. The hardware substitution remains subject to its actual drawing and fit check.

Editable table: [Excel](../output/pcbway-review-2026-09-10/pcbway-actions.xlsx); [CSV](../output/pcbway-review-2026-09-10/pcbway-actions.csv).

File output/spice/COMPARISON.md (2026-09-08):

# Modern vs cost-optimised board - SPICE comparison

| quantity | modern board | cost board | note |
|---|---|---|---|
| +5V minimum under full load | 5 V | 5 V | modern: 5 A TPS54560B / cost: 3 A TPS54360B |
| +5V buck input minimum (headroom, buck needs ~5.6 V) | 7.541 V | 8.336 V | 15000 uF / 5 A -> 10000 uF / 3 A, GBU8J instead of GBPC3510 |
| +12V digital minimum (buck from the +18V lamp rail, 2.8 A of lamps) | 12 V | 12 V | both boards now feed U21 from +18V as the original 7812 does (the +20V rail is cut by the coin-door interlock); the modern board was corrected 2026-09-06 |
| +20V minimum during the flasher burst | 16.78 V | 16.47 V | 15000 uF -> 10000 uF, GBJ1510 instead of GBPC3510 |
| +18V lamp rail average (5 ohm load) | 13.48 V | 13.76 V | 2 x 15000 uF -> 2 x 10000 uF, GBJ1510 |
| +18V ripple p-p | 0.6483 V | 0.9925 V |  |
| "+50V" rail idle | 67.67 V | 69.21 V | both suites use the real 51.4 VAC winding (~70 V) |
| +50V average during a coil pulse | 45.43 V | 41.64 V | modern: 4 ohm coil, 0.35 R + 0.5 mH winding model; cost: AE-23-800 (4.2 ohm), 0.6 R winding model |
| +50V minimum during the pulse | 39.95 V | 35.53 V |  |
| peak 4-ohm coil current in the PSU sim | 13.45 A | 13.07 A |  |
| high-power driver drop while ON | 0.09988 V | 0.3106 V | IRLB4030 4.3 mOhm -> IRLR3110Z (18 mOhm modelled at 4.6 V), both on the 70 V rail |
| high-power driver dissipation while ON | 1.745 W | 5.154 W | TO-220 -> DPAK; pulsed duty keeps the average low |
| high-power coil current | 17.48 A | 16.59 A | modern: 4 ohm; cost: AE-23-800 4.2 ohm; both on 70 V |
| low-power driver drop while ON | 0.04434 V | 0.1194 V |  |
| low-power driver dissipation while ON | 0.3446 W | 0.7725 W |  |
| current the latch must sink/source per output | 0.0004536 A | 0.0004536 A | unchanged (MOSFET gate) |
| flasher driver drop | 0.006334 V | 0.02035 V |  |
| lamp column driver drop | 0.1994 V | 0.1205 V | IRF9Z34N 100 mOhm -> IRFR5305 65 mOhm (better) |
| lamp row driver drop incl. 0.22 R sense | 0.5104 V | 0.6228 V | IRLZ44N 22 mOhm -> IRLR024N 65-80 mOhm |
| column MOSFET Vgs | -10.79 V | -10.8 V | same 1k/1.5k divider |
| row over-current shutdown time | 0.03308 s | 0.03316 s |  |
| row fault current before shutdown | 15.09 A | 8.365 A | higher Rds(on) limits the fault current a little |
| row current after shutdown | 0.022 A | 0.002529 A |  |
| triac gate current | 0.07841 A | 0.07841 A | unchanged |
| ZERO CROSS period | 0.01667 s | 0.01667 s | both boards: 60 Hz square wave with one edge per crossing (A-12697 U6A pin 7 = D38 sample); the cost board earlier produced a 120 Hz pulse, corrected 2026-09-06 |
| ZERO CROSS time HIGH per cycle | 0.007392 s | 0.007306 s | real TP4: ~8.1 ms (Pinside Arduino measurement) |
| ZC edge delay after the true crossing | 0.0004704 s | 0.0005266 s | modern: two half-wave detectors, 27k feedback; cost: one half-wave sample, no feedback |
| +5V buck output ripple (switching model) | 0.02396 V | 0.02705 V | TPS54560B 17 A/V -> TPS54360B 12 A/V, recomputed compensation |
| +5V buck undershoot on a load step | 4.801 V | 4.898 V | modern: 1 -> 5 A step; cost: 1 -> 3 A step |
| +5V buck peak inductor current at full load | 6.499 A | 3.65 A | cost: must stay below the 4.5 A minimum current limit |
| +12V buck undershoot on a 1 -> 2 A step | n/a  | 11.8 V | cost: from 13.5 V (+18V rail at full lamp load) |
| coil current while BLANKING is high at power-up | n/a  | 1.312e-08 A | cost-board machine-level deck |
| RMS lamp voltage with 2 ms strobes | 4.932 V | 6.174 V | cost-board machine-level deck (original Darlington board: 5.53 V) |
| G.I. string RMS at level 7 (8 us gate pulse) - modern deck | 0.6801 A | n/a  | the cost deck gi_dim now runs the same machine-level model with its own detector (l7p_rms below) |
| G.I. string RMS at level 7 (8 us gate pulse) - cost deck | n/a  | 0.688 A |  |
| triac conduction loss at a full 18-lamp string | 3.265 W | 3.265 W | same BTA16-600C; the specified 25 C/W clip heatsink fails the Tj check on both boards (tj_rise_clip) |
| G.I. string cold-start I2t through F106 | 9.188 A2s | 9.188 A2s | modern: 313 5 A (140 A2s); cost: 239 5 A (302.8 A2s) |
| switch-on I2t through F112 (+50V, 4400 uF) | 9.911 A2s | 6.663 A2s | modern: 313 7 A (347 A2s) at 78 V peak; cost: 239 7 A (stand-in 347 A2s) at 72.7 V peak |
| switch-on I2t through the fast 8 A F114 | 10.88 A2s | 7.07 A2s | modern: 312 8 A (166 A2s, 2 x 15000 uF); cost: 217 8 A (198 A2s, 2 x 10000 uF) |
| data setup at the latch before the strobe edge | 1.702e-07 s | 1.438e-07 s | modern: 74HCT564 direct; cost: through the 25 ns 74HCT240 |
| data hold after the strobe edge | 3.529e-08 s | 1.544e-07 s | cost: the 74HCT240 delay and the 4.7 k ribbon pull-up lengthen it |
| +12V power (J116/J117/J118) minimum at 2.5 A | 10.68 V | n/a  | modern: C30 15000 uF; cost: 10000 uF - both GBU8J, both the OEM topology now |

Both suites: ngspice transient runs, generic functional models (see each project's `tools/spice/`).  Modern results: `../wpc_power_driver_modern/output/spice/RESULTS.md`; cost board: `output/spice/RESULTS.md`.

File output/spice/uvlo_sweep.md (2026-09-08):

# +5V raw rail vs mains and load (averaged TPS54360B model, C5 = 10000 uF, GBU8J)

| mains | 9 VAC peak (V) | +5V load (A) | raw minimum (V) | raw average (V) | raw ripple p-p (V) | +5V minimum (V) |
|---|---|---|---|---|---|---|
| 100% | 12.70 | 2 | 9.10 | 9.45 | 0.69 | 5.000 |
| 100% | 12.70 | 3 | 8.34 | 8.86 | 1.03 | 5.000 |
| 90% | 11.43 | 2 | 7.67 | 8.06 | 0.77 | 5.000 |
| 90% | 11.43 | 3 | 6.80 | 7.40 | 1.17 | 5.000 |
| 88% | 11.18 | 2 | 7.38 | 7.78 | 0.79 | 5.000 |
| 88% | 11.18 | 3 | 6.48 | 7.10 | 1.20 | 5.000 |
| 85% | 10.79 | 2 | 6.93 | 7.36 | 0.83 | 5.000 |
| 85% | 10.79 | 3 | 5.98 | 6.64 | 1.26 | 5.000 |

The buck regulates 5.0 V down to Vin = 5.6 V (0.97 Vin - 0.5 = 5.0); the UVLO stop level must sit below the raw-rail minimum of the
worst case that the board has to survive (88 % mains, 3 A) with margin for the EN threshold spread (1.1-1.3 V, i.e. +/- 8 % on the stop level).

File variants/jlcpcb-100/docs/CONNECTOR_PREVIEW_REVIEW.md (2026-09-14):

# Connector preview review — September 14, 2026

The reported JLCPCB preview showed J113 perpendicular to its PCB footprint, bare holes at J120/J121/J126, and gray blocks at several other headers. The user confirmed that the C592598 row was matched but unchecked with a warning; the exact warning was no longer available. The files contained all connectors. The selection state explains the three excluded headers; the specific reason for the warning is still unknown.

## Full orientation audit

The user confirmed the latest CPL (J113 = 90°), with no manual rotations. The earlier check preserved native SMT angles and checked connector pad numbers; it did not establish correct supplier orientation for all parts or validate friction walls. This audit supersedes that claim.

All **69 purchased codes / 440 placements** now have an entry in `component-orientation-check.csv`. Compared with that last CPL, **76 SMT and 18 connector rotations change**. The SMT-only CPL receives the same corrections. Raw native angles are kept separately in `assembly/native-smt-positions.csv`; they are not the JLC upload file.

| Parts | Offset from native KiCad angle |
| --- | ---: |
| SN74HCT574NSR C2878759 (U1–U5, U18), SN74HCT240NSR C6772 (U9) | −90° |
| SN74HCT74DR C352961, LM339DR C7948, TBD62083AFWG C165895 | −90° |
| AOD66923 C485687, IRFR5305 C2624, MMBT2222A C8512 | +180° |
| IRLR024N C3007 | +90° |
| MBRB20H100CT C235758 (D105–D116) | −90° |
| XFCN C5200275 (J113) | −90° (retained correction) |
| Molex C505166, TE C94118 | +180° (retained corrections) |
| TE C86500/C305801/C305802; Molex C588986 (J111) | +180° for inward tab; **manual model/pad conflict** |
| TE C592598 (J120/J121/J126) | +180° inferred from TE family; **manual placement, no public library** |

**U1 = 90°, U2/U3 = 270°, J110 = 180°, J113 = 90°.** J110's tab faces down/toward the board interior in the native board top view. Its key is post 5. Retain every other post, including unused posts. The same inward-tab rule applies to the single-row J headers; the PDF provides a separate top-view detail for all 39 purchased headers.

### Evidence and remaining manual gates

`connector-orientation-guide.pdf` shows native pin-1 coordinates, physical key-post locations and tab/notch directions. `placement-map.csv` records native angle, applied offset and final CPL angle. Functional pad comparisons account for the native rectifier symbol's duplicated anodes and C3007's library drain pin 4 versus native drain pin 2. U20/U21 retain 0° offset: all 21 RYQ lands match. Diodes, LEDs, polarized capacitors and remaining nonpolarized axes were included; 15 resistor positions have no public library and retain their electrically symmetric native orientation. Fuse cartridges are manual insertions into their separately placed holders.

**A supplier model is not always consistent with its own pad labels.** TE C86500/C305801/C305802 and Molex C588986 have a 180° disagreement between numbered pads and housing orientation. The CPL follows the inward friction wall; these 15 placements require the assembler to resolve the library conflict against the native pin/key guide. They are not counted as successfully verified numbered-pad placements. TE's drawing labels post 1 on the opposite end from the public 3.96 mm pad library when the locking wall is aligned. Never rewire the board to follow erroneous library labels.

C505166's numbered pads support its retained 180° correction, but its public library has no 3D housing; its ten inward tabs require manual confirmation. C592598's three placements have no public library. D101–D104 C5143116 have symmetric anodes and a supplier 3D model framed below the PCB; a CPL Z rotation cannot fix that model. Retain their native tab-to-heatsink direction and confirm manually. BR3 has no public placement library and requires its documented polarity/lead forming. These limitations remain explicit assembly gates.

The public library sources are exact-code LCSC-owned results from `https://lceda.cn/api/products/<C-code>/components`. JSON, retrieval metadata, supplier preview meshes and source hashes are archived in `cad/research/jlc-placement-libraries/` and `cad/research/jlc-preview/`. Public data does not prove the current private JLCPCB job uses the same model. [JLCPCB explains](https://jlcpcb.com/help/article/pcb-assembly-faqs-part-2) that its red/pink dot is an orientation mark and is not necessarily pin 1.

The original Williams STTNG Operations Manual, PDF page 61 / printed 2-9, controls the inward friction walls and key schedule. [TE 640445 drawing](https://www.te.com/commerce/DocumentDelivery/DDEController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) and [TE 640456 drawing](https://www.te.com/commerce/DocumentDelivery/DDEController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) control the replacement header envelopes. Native TE/Molex generated models now put the wall on the inward side, use corrected housing centers, and remove only the explicit key post. The old TE generator incorrectly removed every unconnected post. Native PCB pads, electrical pin numbering and copper remain unchanged. Simplified envelopes do not certify molded detail or cable fit.

J113's 34 absolute library pin positions still coincide with the native drilled holes at 90°. Pin 1 is X=8.220, Y=−128.459 mm, bottom/right of the array in board top view. The notch faces right, toward the board interior. Other checks compare centered functional land patterns and separate physical housing centers; they do not claim all supplier body origins match the live placement job.

## C592598 selection and replacement search

J120/J121/J126 remain one BOM group containing three TE 1-640445-3 headers per board. The public stock recheck returned 371 physical and 371 orderable pieces, sufficient for 300 build pieces plus 15 spares. Stock is not reserved. The library endpoint returned `success:false, code:404` for C592598; this explains why a public footprint could not be checked, but does not establish the cause of the user's warning.

The user requested a replacement if possible. The same-day search found:

| Candidate | Available quantity | Decision |
| --- | ---: | --- |
| TE 1-640445-1, C592644, exact 11-position | 0 physical; negative orderable value | Insufficient for 200 build pieces plus spares |
| Molex 26604110, C17541501, exact 11-position | 0 | Insufficient |
| Molex 0026604130, C17226055, exact 13-position | 89 | Insufficient for 100 build pieces plus spares |
| TE 1-640445-2, C592597, 12-position for trimming | 28 orderable | Insufficient |
| Other longer TE 640445 headers | 0 | Insufficient |
| Stocked 11-/13-position VH-family headers | Some meet quantity | Matching 3.96 mm pitch does not establish compatibility with existing KK/MTA cable plugs; no mating-compatible substitute qualified |

The release retains the stocked C592598 and its existing preparation instructions. Search queries and results are archived with the full package.

On JLCPCB **Select Parts**, review the warning, confirm C592598 / 1-640445-3, then check the row. All three references must appear in the selected assembly list. [JLCPCB's matching instructions](https://jlcpcb.com/help/article/common-bom-and-cpl-matching-issues-and-explanations) explain that a matched but unchecked component is not selected for assembly. CSV content cannot acknowledge this existing order-page warning.

For manual assembly, trim J120/J121 from 13 to 11 positions by removing positions 12–13, preserve pin 1 and the friction wall, and remove key post 4. J126 stays 13 positions with key post 9 removed. Send `PCBA-remark.txt`, `placement-map.csv`, and `connector-keys.csv` with the quotation. Gray blocks in the screenshot appear to be placeholders; verify selected part codes and the final assembly drawing rather than inferring omission from the model appearance.

The PCB, schematic, nets, Gerbers, purchased part quantities and electrical simulation models are unchanged by these upload corrections. The previously accepted SPICE results remain applicable within their documented engineering-model scope; no new simulation run is claimed.

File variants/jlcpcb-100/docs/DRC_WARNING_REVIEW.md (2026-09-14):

# Native DRC warning review

Reviewed 178 warnings from native-final3; zero errors, zero opens, zero schematic parity issues.

| Warning | Count | Disposition |
|---|---:|---|
| lib_footprint_mismatch | 6 | Intentional local silkscreen clipping on six footprints after pad/package changes. Native pad geometry and net parity checked; embedded PCB is manufacturing authority. |
| missing_courtyard | 1 | Inherited non-purchased board feature; independent complete 3D assembly has no missing models or inter-component collisions. |
| npth_inside_courtyard | 1 | Intentional BR3/H9 mounting axis and bridge/basket hardware assembly; physically review stack and torque. |
| silk_over_copper | 11 | Some native body/polarity outlines intersect mask openings. Manufacturing exporter subtracts solder mask from silk; assembly Fab outlines remain complete. Reference labels remain visible. |
| track_dangling | 75 | Existing/local fanout tails remain after package rerouting. Native final connectivity and clearances pass. Retained copper tails are not assembly parts; do not remove entire reported tracks blindly, because mid-track branches may carry functional connections. |
| track_not_centered_on_via | 74 | Copper overlaps plated via land away from its center. Native geometric connection/clearance checks pass. Manufacturing electrical test remains required. |
| via_dangling | 10 | Retained nonessential stitching/legacy drill sites. Connectivity does not depend on an unrouted item; final DRC reports zero opens. |

These are recorded dispositions, not suppressed rules. Independent Gerber/drill verification checks exported geometry. Production still requires fabricator DFM and first-article electrical, mechanical and thermal testing.

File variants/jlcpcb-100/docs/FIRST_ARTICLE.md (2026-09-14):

# First-article acceptance before the 100-board build

The inventory audit covers 100 boards plus the documented spares. It does not replace first-article qualification. Complete a small engineering build before committing the remaining quantity.

1. Have the fabricator review the four-layer stack, finished outer/inner copper, drill plating, native polarity and SMT orientation previews. Agree on the entire through-hole/manual BOM, prepared connector work and the soldered F112 fuse. Obtain the externally sourced mechanical hardware. Do not silently omit holders, cartridges, screws, nuts or heatsinks.
2. Inspect the received parts against exact manufacturer numbers and footprints. Verify the prepared TE headers against the actual keyed mating housings. Confirm J115's two-piece seam and J113 latch/cable clearance. Use a forming fixture and a meter to verify BR3's +, − and AC terminals against the new pad numbering before soldering. Inspect all capacitor polarities and ratings.
3. Inspect shorts, clearances, fuse values, solder joints and exposed-pad wetting. Verify heatsink interfaces, screw engagement/torque and live-tab clearance. Check cabinet and underside clearance with the actual assembled board and harnesses.
4. Bring up with protected, current-limited sources and the intended transformer connections. Measure rail startup, shutdown, prebias/restart, the loaded 5.1 V/3 A and 12 V/0.75 A rails, CPU-end voltage/reset margin and supply switching/loop waveforms. Check the high rail at measured worst mains regulation. Do not assume the behavioral model predicts switching overshoot or protection timing.
5. Exercise the real lamp, motor, flasher, coil and GI loads, including channels absent from the recorded trace. Confirm blanking inhibits outputs and that each GI triac commutates and triggers in the required quadrants. Measure drain overshoot and gate voltages at the actual harness loads.
6. Measure capacitor ripple and temperatures, semiconductor case/estimated junction temperatures, copper/connector temperatures and all ten heatsink temperatures after thermal soak in the cabinet. Correlate against the engineering thermal model and measured local ambient. Confirm MOT thermal resistance with the supplier or measured case data; do not treat the assumed 4°C/W junction-to-case value as a specification.
7. Qualify cold and hot starts, repeated start cycles, real Fliptronic branch loading and representative protected fault cases with the actual transformer. Check F112's temperature derating, interruption capability and coordination, and the REOMAX cartridge time-current behavior. Typical I²t comparisons alone are not acceptance evidence. Preserve the specified fuse ratings.

Record serial numbers, part lots, actual line/transformer impedances, harness configuration, instruments, waveforms and test results. Resolve failures by revising the design and regenerating the source-bound manufacturing package.

For the selected onsemi rectifiers, the worst simulated20V crest start at0.05Ω loop resistance reaches244.752A in one leg. Measure effective secondary impedance and crest energization with the actual capacitor bank; validate hot starts and leg sharing. The250A per-leg single-pulse limit leaves little margin in that artificial stiff-source corner. The0.1Ω loop case is substantially lower. Do not treat the I²t comparison as repetitive-surge or fault qualification.

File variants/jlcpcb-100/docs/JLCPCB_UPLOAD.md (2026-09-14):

# JLCPCB mixed SMT and through-hole assembly upload

Upload **`jlcpcb-assembly/BOM.csv` and `jlcpcb-assembly/CPL.csv` together**, with the existing `gerbers-and-drills.zip`. Both CSVs describe one board; select 100 boards in the order. Do not multiply the placement entries by 100 or include procurement spares as placements.
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

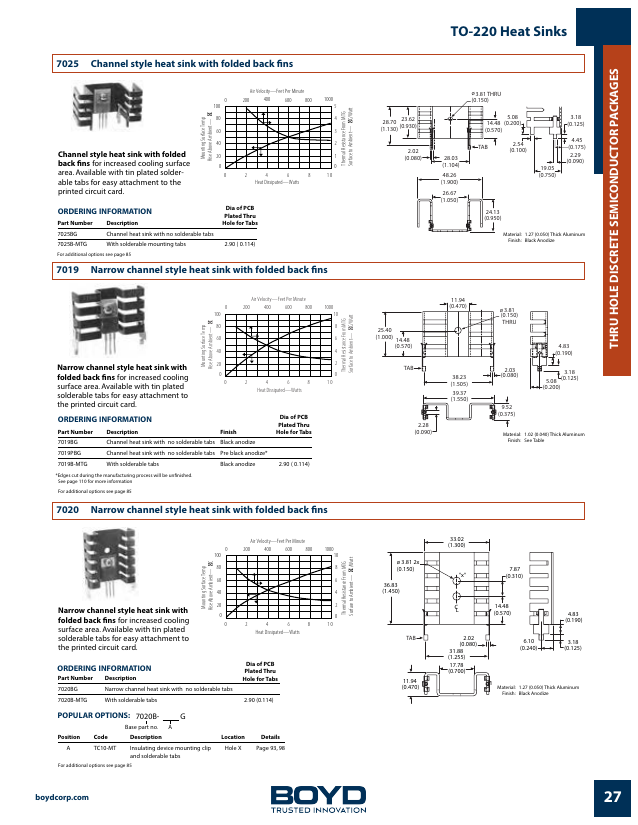
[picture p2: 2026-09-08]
.scratch/thermal/pg_7019BG-029.png

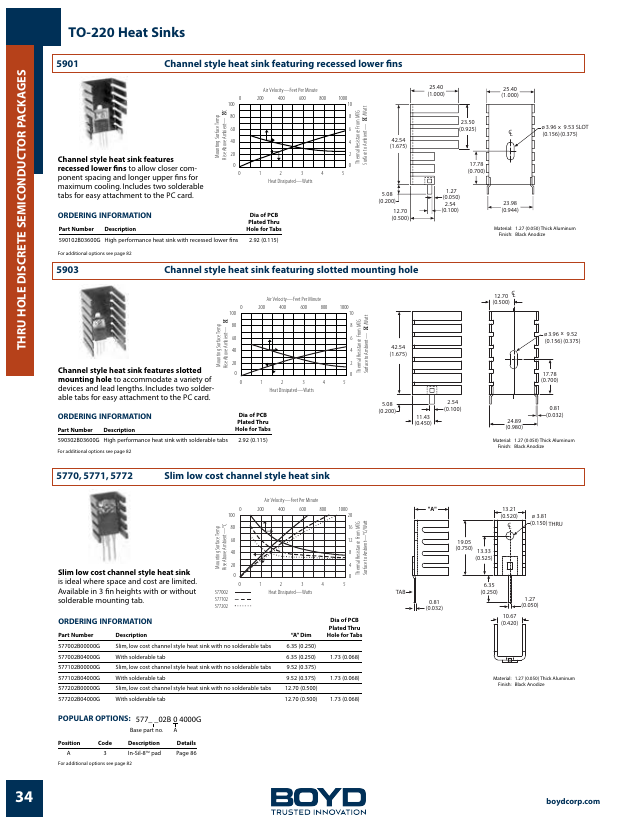
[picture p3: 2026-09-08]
.scratch/thermal/pg_577002B00000G-036.png

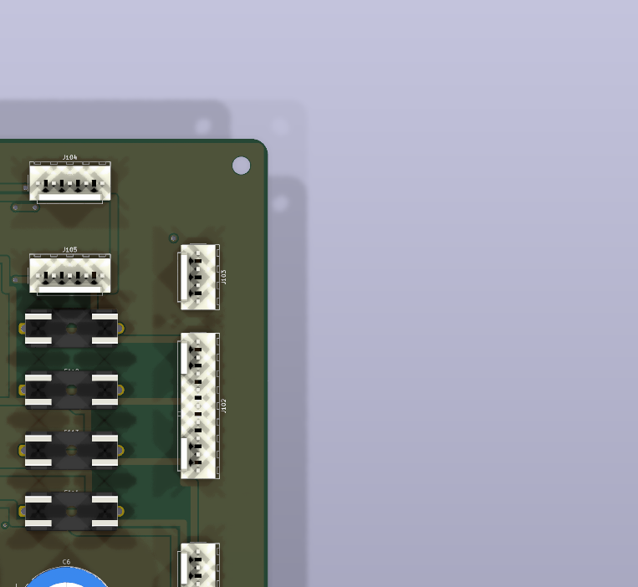
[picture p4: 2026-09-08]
.scratch/thermal/crop_br1.png

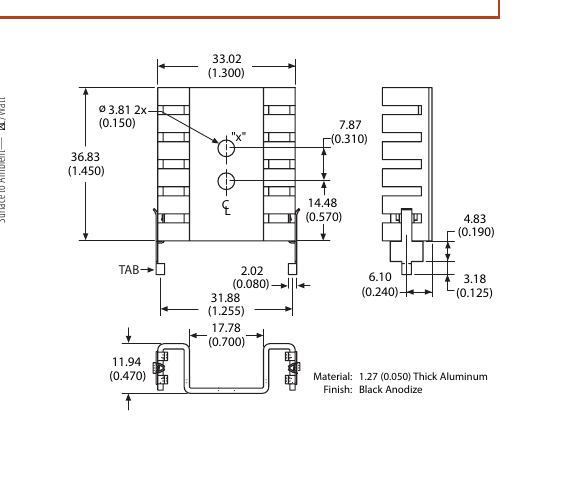
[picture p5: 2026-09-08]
.scratch/thermal/d_7020.png

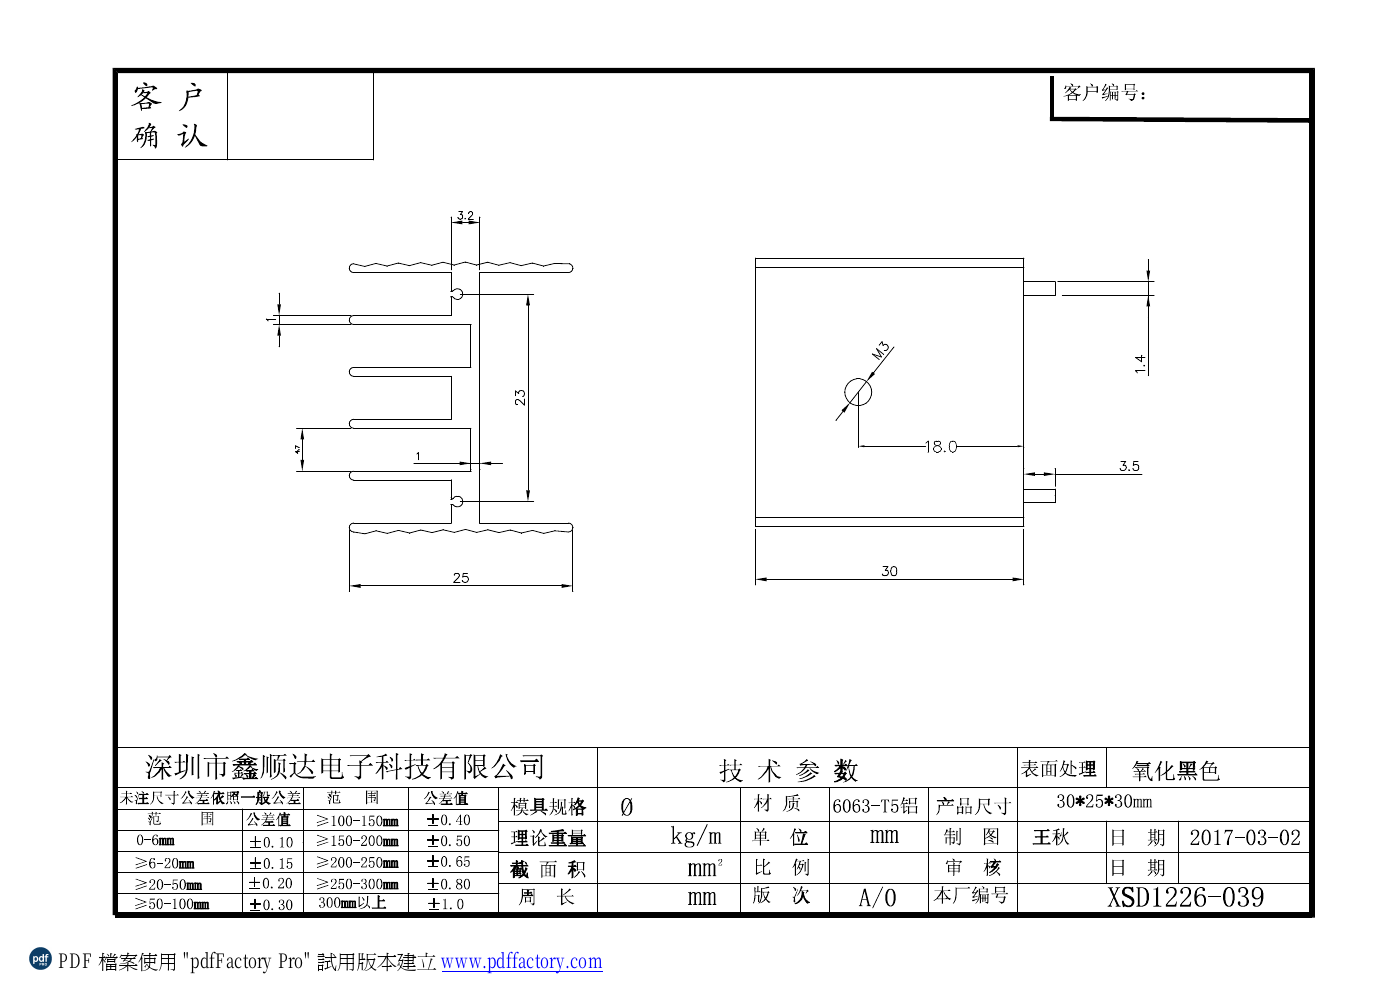
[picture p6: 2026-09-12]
variants/jlcpcb/research/C32487.png

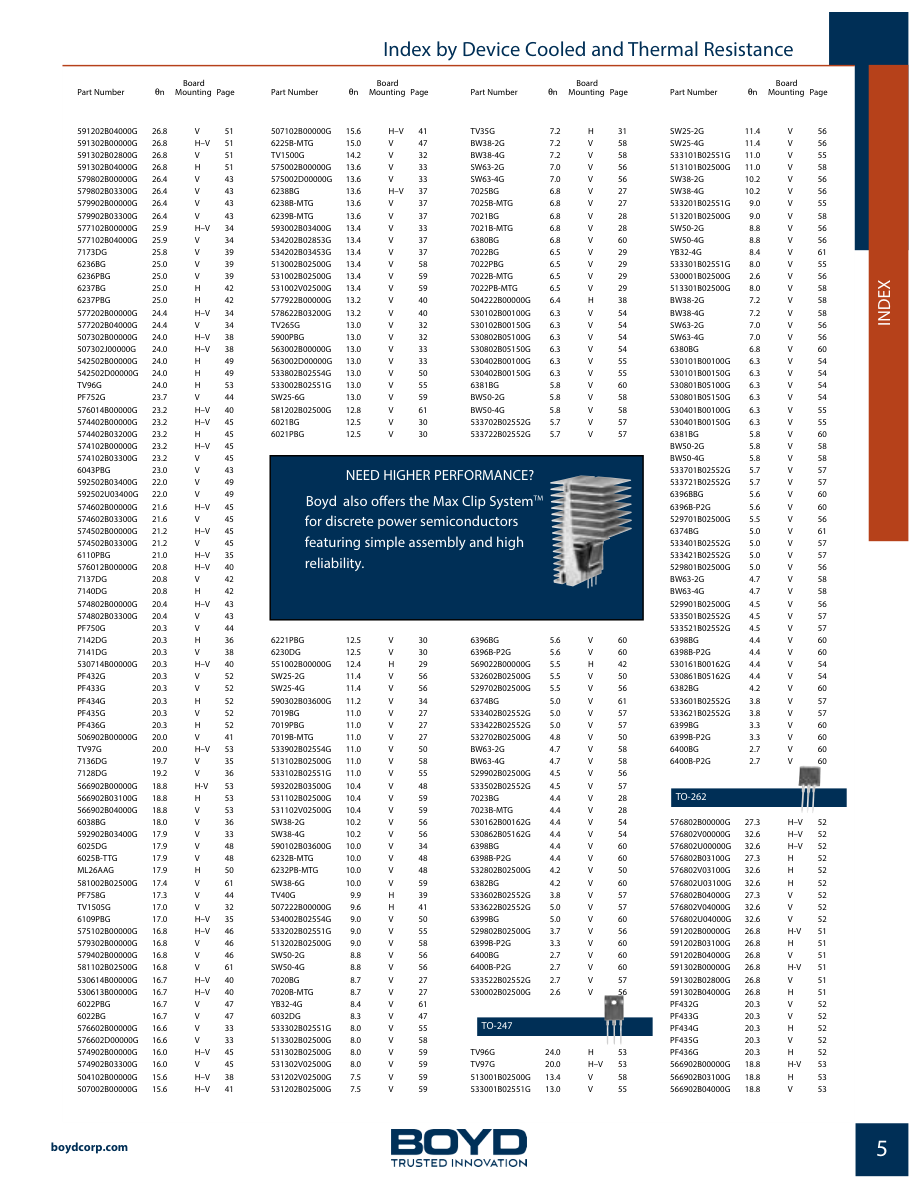
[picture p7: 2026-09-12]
variants/jlcpcb/research/Boyd-5.png

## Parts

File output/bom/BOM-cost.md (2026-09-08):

# Bill of materials - WPC Power Driver Board (cost-optimised modern version)

One line per orderable part.  Links are DigiKey product pages (product IDs seen in Sep 2026 searches) or DigiKey exact part-number searches for passives / connector variants.
Unit $ (1) = DigiKey (Mouser for the IRLR024N / IRFR5305 DPAK parts) single-unit price where it was visible during sourcing; `~` marks an estimate used so that the roll-up is complete.
Unit $ (100) = estimated unit price when buying for 100 boards (100 x the per-board quantity, i.e. reel / 1000-piece breaks for the parts used 8-32 times per board).

| Qty | Refs | Value | Manufacturer | MPN | Description | Footprint | Unit $ (1) | Ext $ (1) | Unit $ (100) | Ext $ (100) | DNP |
|---|---|---|---|---|---|---|---|---|---|---|---|
| 1 | TP1 | TP1 +12VU |  |  | Test point +12VU | TestPoint_THTPad_D2.0mm_Drill1.0mm | 0.00 | 0.00 | 0.00 | 0.00 |  |
| 1 | TP2 | TP2 +5V |  |  | Test point +5V | TestPoint_THTPad_D2.0mm_Drill1.0mm | 0.00 | 0.00 | 0.00 | 0.00 |  |
| 1 | TP3 | TP3 +12V |  |  | Test point +12V regulated | TestPoint_THTPad_D2.0mm_Drill1.0mm | 0.00 | 0.00 | 0.00 | 0.00 |  |
| 1 | TP4 | TP4 ZC |  |  | Test point ZC | TestPoint_THTPad_D2.0mm_Drill1.0mm | 0.00 | 0.00 | 0.00 | 0.00 |  |
| 1 | TP5 | TP5 GND |  |  | Test point GND | TestPoint_THTPad_D2.0mm_Drill1.0mm | 0.00 | 0.00 | 0.00 | 0.00 |  |
| 1 | TP6 | TP6 +50V |  |  | Test point +50V | TestPoint_THTPad_D2.0mm_Drill1.0mm | 0.00 | 0.00 | 0.00 | 0.00 |  |
| 1 | TP7 | TP7 +20V |  |  | Test point +20V | TestPoint_THTPad_D2.0mm_Drill1.0mm | 0.00 | 0.00 | 0.00 | 0.00 |  |
| 1 | TP8 | TP8 +18V |  |  | Test point +18V | TestPoint_THTPad_D2.0mm_Drill1.0mm | 0.00 | 0.00 | 0.00 | 0.00 |  |
| 1 | TP9 | TP9 +5V_RAW |  |  | Test point +5V raw (buck input) | TestPoint_THTPad_D2.0mm_Drill1.0mm | 0.00 | 0.00 | 0.00 | 0.00 |  |
| 1 | J111 | J111 G.I. latch spare bits T5-T7 (GPIO as on the original board, e.g. shot-clock drive; N/C on STTNG) | Molex | [0022232051](https://www.digikey.com/en/products/result?keywords=0022232051) | J111 G.I. latch spare bits T5-T7 (GPIO as on the original board, e.g. shot-clock drive; N/C on STTNG) | Molex_KK-254_AE-6410-05A_1x05_P2.54mm_Vertical | ~0.45 | ~0.45 | 0.28 | 0.28 |  |
| 3 | J133, J134, J135 | J133 lamp rows (cabinet) | Molex | [0022232091](https://www.digikey.com/en/products/result?keywords=0022232091) | J133 lamp rows (cabinet) | Molex_KK-254_AE-6410-09A_1x09_P2.54mm_Vertical | ~0.75 | ~2.25 | 0.45 | 1.35 |  |
| 3 | J108, J119, J136 | J108 +50V (F103/F104/F105) to cabinet (N/C on STTNG) | Molex | [0026604003](https://www.digikey.com/en/products/result?keywords=0026604003) | J108 +50V (F103/F104/F105) to cabinet (N/C on STTNG) | Molex_KK-396_A-41791-0003_1x03_P3.96mm_Vertical | ~0.55 | ~1.65 | 0.35 | 1.05 |  |
| 4 | J103, J116, J117, J118 | J103 ground to 8-driver board (all four pins grounded as on A-12697 sheet 1, no key) | Molex | [0026604004](https://www.digikey.com/en/products/result?keywords=0026604004) | J103 ground to 8-driver board (all four pins grounded as on A-12697 sheet 1, no key) | Molex_KK-396_A-41791-0004_1x04_P3.96mm_Vertical | ~0.62 | ~2.48 | 0.40 | 1.60 |  |
| 10 | J104, J105, J106, J112, J123, J124, J128, J129, J131, J132 | J104 fused 51VAC (F112, pins 1/2) to Fliptronic II J901 and fused 16VAC (F111, pins 4/5), as A-12697 sheet 1 | Molex | [0026604005](https://www.digikey.com/en/products/result?keywords=0026604005) | J104 fused 51VAC (F112, pins 1/2) to Fliptronic II J901 and fused 16VAC (F111, pins 4/5), as A-12697 sheet 1 | Molex_KK-396_A-41791-0005_1x05_P3.96mm_Vertical | ~0.70 | ~7.00 | 0.45 | 4.50 |  |
| 1 | J107 | J107 +50V (F103/F104/F105) and +20V (pins 5,6) to playfield | Molex | [0026604006](https://www.digikey.com/en/products/result?keywords=0026604006) | J107 +50V (F103/F104/F105) and +20V (pins 5,6) to playfield | Molex_KK-396_A-41791-0006_1x06_P3.96mm_Vertical | ~0.78 | ~0.78 | 0.50 | 0.50 |  |
| 3 | J101, J109, J114 | J101 xformer 9VAC (Red) / 13VAC (Blu-Wht) | Molex | [0026604007](https://www.digikey.com/en/products/result?keywords=0026604007) | J101 xformer 9VAC (Red) / 13VAC (Blu-Wht) | Molex_KK-396_A-41791-0007_1x07_P3.96mm_Vertical | ~0.85 | ~2.55 | 0.55 | 1.65 |  |
| 8 | J102, J110, J122, J125, J127, J130, J137, J138 | J102 xformer 16VAC (Wht-Red) / solenoid ~51VAC (Blk-Yel) | Molex | [0026604009](https://www.digikey.com/en/products/detail/molex/0026604090/79784) | J102 xformer 16VAC (Wht-Red) / solenoid ~51VAC (Blk-Yel) | Molex_KK-396_A-41791-0009_1x09_P3.96mm_Vertical | 0.95 | 7.60 | 0.65 | 5.20 |  |
| 2 | J120, J121 | J120 G.I. strings 1-5 (backbox harness uses strings 2,3) | Molex | [0026604011](https://www.digikey.com/en/products/result?keywords=0026604011) | J120 G.I. strings 1-5 (backbox harness uses strings 2,3) | Molex_KK-396_A-41791-0011_1x11_P3.96mm_Vertical | ~1.20 | ~2.40 | 0.78 | 1.56 |  |
| 1 | J115 | J115 G.I. 6.3VAC from transformer: 2-6 string hot ends (one fuse each), 7/8/10/11/12 winding return ends (triac MT1), 1 = GND REF | Molex | [0026604012](https://www.digikey.com/en/products/result?keywords=0026604012) | J115 G.I. 6.3VAC from transformer: 2-6 string hot ends (one fuse each), 7/8/10/11/12 winding return ends (triac MT1), 1 = GND REF | Molex_KK-396_A-41791-0012_1x12_P3.96mm_Vertical | ~1.30 | ~1.30 | 0.82 | 0.82 |  |
| 1 | J126 | J126 Sol 17-24 drive (playfield flashers) + tie-back cathodes of sol 21-24 on pins 10-13 (A-12697 D9-D12; N/C on STTNG) | Molex | [0026604013](https://www.digikey.com/en/products/result?keywords=0026604013) | J126 Sol 17-24 drive (playfield flashers) + tie-back cathodes of sol 21-24 on pins 10-13 (A-12697 D9-D12; N/C on STTNG) | Molex_KK-396_A-41791-0013_1x13_P3.96mm_Vertical | ~1.40 | ~1.40 | 0.88 | 0.88 |  |
| 1 | F114 | 8A | Littelfuse | [0217008.MXP](https://www.digikey.com/en/products/detail/littelfuse-inc/0217008-MXP/777551) | Fuse 8A 5x20 mm (Keystone 3517 clips), +18V lamp matrix supply (13.3 VAC); also feeds the +12V digital buck U21 | Fuseholder_Clip-5x20mm_Keystone_3517_Inline_P23.11x6.76mm_D1.70mm_Horizontal | 0.57 | 0.57 | 0.32 | 0.32 |  |
| 1 | F115 | 3/4A S.B. | Littelfuse | [0239.750MXP](https://www.digikey.com/en/products/result?keywords=0239.750MXP) | Fuse 3/4 A Slo-Blo 5x20 mm (Keystone 3517 clips), +12V switch matrix | Fuseholder_Clip-5x20mm_Keystone_3517_Inline_P23.11x6.76mm_D1.70mm_Horizontal | 1.00 | 1.00 | 0.60 | 0.60 |  |
| 4 | F103, F104, F105, F116 | 3A S.B. | Littelfuse | [0239003.MXP](https://www.digikey.com/en/products/detail/littelfuse-inc/0239003-MXP/778224) | Fuse 3 A Slo-Blo 5x20 mm (Keystone 3517 clips), +50V to J107-1 sol 25-28 / 8-driver | Fuseholder_Clip-5x20mm_Keystone_3517_Inline_P23.11x6.76mm_D1.70mm_Horizontal | 1.15 | 4.60 | 0.40 | 1.60 |  |
| 7 | F106, F107, F108, F109, F110, F111, F113 | 5A S.B. | Littelfuse | [0239005.MXP](https://www.digikey.com/en/products/detail/littelfuse-inc/0239005-MXP/778232) | Fuse 5 A Slo-Blo 5x20 mm (Keystone 3517 clips), G.I. string #5 | Fuseholder_Clip-5x20mm_Keystone_3517_Inline_P23.11x6.76mm_D1.70mm_Horizontal | 1.48 | 10.36 | 0.38 | 2.66 |  |
| 1 | F112 | 7A S.B. | Littelfuse | [0239007.MXP](https://www.digikey.com/en/products/detail/littelfuse-inc/0239007.MXP/778234) | Fuse 7A S.B. 5x20 mm (Keystone 3517 clips), +50V solenoid supply (51 VAC winding -> ~70 V DC, 78 V peak unloaded) | Fuseholder_Clip-5x20mm_Keystone_3517_Inline_P23.11x6.76mm_D1.70mm_Horizontal | ~0.90 | ~0.90 | 0.50 | 0.50 |  |
| 2 | D33, D34 | 1N4148W | Diodes Inc | [1N4148W-7-F](https://www.digikey.com/en/products/result?keywords=1N4148W-7-F) | Small-signal diode 75 V 150 mA, SOD-123 | D_SOD-123 | ~0.12 | ~0.24 | 0.03 | 0.06 |  |
| 5 | C5, C6, C7, C11, C30 | 10000uF 25V | Rubycon | [25USC10000MEFCSN25X25](https://www.digikey.com/en/products/detail/rubycon/25USC10000MEFCSN25X25/3565219) | Capacitor 10000 uF 25 V snap-in 25x25 mm, 85C 3000 h (USC) | CP_Radial_D25.0mm_P10.00mm_SnapIn | ~2.90 | ~14.50 | 1.85 | 9.25 |  |
| 1 | J113 | 34-pin ribbon to CPU J211 | 3M | [30334-5002HB](https://www.digikey.com/en/products/detail/3m/30334-5002HB/1237402) | J113 34-pin 2x17 box header (ribbon to CPU J211) | IDC-Header_2x17_P2.54mm_Vertical | ~1.10 | ~1.10 | 0.65 | 0.65 |  |
| 2 | SR1, SR2 | 9x4.7K SIP | Bourns | [4610X-101-472LF](https://www.digikey.com/en/products/result?keywords=4610X-101-472LF) | Pull-ups for the seven latch strobes and BLANKING | R_Array_SIP10 | ~0.55 | ~1.10 | 0.35 | 0.70 |  |
| 1 | U9 | 74HCT240 | Nexperia | [74HCT240D,653](https://www.digikey.com/en/products/result?keywords=74HCT240D%2C653) | J113 data-bus inverter: the CPU board drives the ribbon data through a 74LS240 (active low) | SOIC-20W_7.5x12.8mm_P1.27mm | ~0.75 | ~0.75 | 0.42 | 0.42 |  |
| 6 | U1, U2, U3, U4, U5, U18 | 74HCT574 | Nexperia | [74HCT574D,653](https://www.digikey.com/en/products/detail/nexperia-usa-inc/74HCT574D-653/763412) | G.I. / relay latch | SOIC-20W_7.5x12.8mm_P1.27mm | ~0.75 | ~4.50 | 0.42 | 2.52 |  |
| 2 | D36, D37 | B560C | Diodes Inc | [B560C-13-F](https://www.digikey.com/en/products/detail/diodes-incorporated/B560C-13-F/768773) | Catch diode B560C 5 A 60 V Schottky SMC | D_SMC | ~0.62 | ~1.24 | 0.30 | 0.60 |  |
| 5 | Q10, Q12, Q14, Q16, Q18 | BTA16-600CRG | STMicroelectronics | [BTA16-600CRG](https://www.digikey.com/en/products/detail/stmicroelectronics/BTA16-600CRG/669145) | Triac 16 A 600 V, 4-quadrant (Igt 25/50 mA), insulated TO-220AB | TO-220-3_Vertical | ~1.45 | ~7.25 | 0.95 | 4.75 |  |
| 1 | C21 | 10nF | Samsung | [CL21B103KBANNNC](https://www.digikey.com/en/products/result?keywords=CL21B103KBANNNC) | Capacitor 10 nF (ZC filter) | C_0805_2012Metric | ~0.10 | ~0.10 | 0.01 | 0.01 |  |
| 27 | B1, B2, B3, B4, B5, B6, B9, B10, B11, B12, ... (27 total) | 100nF | Samsung | [CL21B104KBCNNNC](https://www.digikey.com/en/products/detail/samsung-electro-mechanics/CL21B104KBCNNNC/3886661) | Bypass 100 nF 50 V X7R 0805 | C_0805_2012Metric | ~0.10 | ~2.70 | 0.01 | 0.27 |  |
| 1 | C36 | 33nF | Samsung | [CL21B333KBANNNC](https://www.digikey.com/en/products/result?keywords=CL21B333KBANNNC) | Compensation Cc 33nF (zero at the modulator pole, eq. 49) | C_0805_2012Metric | ~0.10 | ~0.10 | 0.01 | 0.01 |  |
| 1 | C43 | 390pF | Samsung | [CL21C391JBANNNC](https://www.digikey.com/en/products/result?keywords=CL21C391JBANNNC) | Compensation Cp 390pF (ESR-zero cancellation, eq. 50) | C_0805_2012Metric | ~0.10 | ~0.10 | 0.01 | 0.01 |  |
| 1 | C37 | 470pF | Samsung | [CL21C471JBANNNC](https://www.digikey.com/en/products/result?keywords=CL21C471JBANNNC) | Compensation Cp 470pF (ESR-zero cancellation, eq. 50) | C_0805_2012Metric | ~0.10 | ~0.10 | 0.01 | 0.01 |  |
| 6 | C33, C34, C38, C39, C40, C44 | 10uF | Samsung | [CL32B106KBJNNWE](https://www.digikey.com/en/products/detail/samsung-electro-mechanics/CL32B106KBJNNWE/3889046) | Input capacitor 10 uF 50 V X7R 1210 | C_1210_3225Metric | ~0.45 | ~2.70 | 0.12 | 0.72 |  |
| 4 | C2, C4, C9, C12 | 330uF | Panasonic | [EEU-FR1E331](https://www.digikey.com/en/products/detail/panasonic-electronic-components/EEU-FR1E331/2433549) | Output capacitor 330 uF 25 V low ESR | CP_Radial_D10.0mm_P5.00mm | ~0.62 | ~2.48 | 0.30 | 1.20 |  |
| 1 | RLY1 | G2RL-2 12V (DNP) | Omron | [G2RL-2 DC12](https://www.digikey.com/en/products/result?keywords=G2RL-2 DC12) | Relay DPDT 12 V coil (DNP - Fliptronic games) | Relay_DPDT_Omron_G2RL-2 | ~3.20 |  | 2.20 |  | DNP |
| 1 | BR3 | GBPC3510 | Vishay | [GBPC3510W-E4/51](https://www.digikey.com/en/products/detail/vishay-semiconductor-diodes-division/GBPC3510W-E4-51/605926) | Bridge rectifier 35 A 1000 V, GBPC-W (28.6 mm square block, wire leads, #10 centre hole, metal base up when PCB-mounted) | Diode_Bridge_28.6x28.6x7.3mm_P18.0mm_P11.6mm | ~7.00 | ~7.00 | 4.70 | 4.70 |  |
| 8 | Q91, Q92, Q93, Q94, Q95, Q96, Q97, Q98 | IRFR5305TRPBF | Infineon | [IRFR5305TRPBF](https://www.digikey.com/en/products/detail/infineon-technologies/IRFR5305TRPBF/811407) | P-MOSFET -55 V -31 A 65 mOhm @-10 V, DPAK (TO-252) | TO-252-2 | 1.98 | 15.84 | 0.88 | 7.04 |  |
| 8 | Q83, Q84, Q85, Q86, Q87, Q88, Q89, Q90 | IRLR024NTRPBF | Infineon | [IRLR024NTRPBF](https://www.digikey.com/en/products/detail/infineon-technologies/IRLR024NTRPBF/812549) | N-MOSFET 55 V 17 A 65 mOhm @10 V / 40 mOhm @4.5 V logic-level, DPAK (TO-252) | TO-252-2 | 1.02 | 8.16 | 0.45 | 3.60 |  |
| 28 | Q20, Q22, Q24, Q26, Q28, Q30, Q32, Q34, Q36, Q38, ... (28 total) | IRLR3110ZTRPBF | Infineon | [IRLR3110ZTRPBF](https://www.digikey.com/en/products/detail/infineon-technologies/IRLR3110ZTRPBF/1928415) | N-MOSFET 100 V 63 A 14 mOhm @10 V / 16 mOhm @4.5 V logic-level, DPAK (TO-252) | TO-252-2 | 1.90 | 53.20 | 0.78 | 21.84 |  |
| 1 | Q3 | IRLR3110ZTRPBF (DNP) | Infineon | [IRLR3110ZTRPBF](https://www.digikey.com/en/products/detail/infineon-technologies/IRLR3110ZTRPBF/1928415) | Relay driver MOSFET (DNP) | TO-252-2 | 1.90 |  | 0.78 |  | DNP |
| 2 | C8, C32 | 2200uF 100V | Nichicon | [LLS2A222MELA](https://www.digikey.com/en/products/detail/nichicon/LLS2A222MELA/2548962) | Capacitor 2200 uF 100 V snap-in 25x40 mm | CP_Radial_D25.0mm_P10.00mm_SnapIn | ~3.60 | ~7.20 | 2.20 | 4.40 |  |
| 3 | U6, U15, U16 | LM339DR | Texas Instruments | [LM339DR](https://www.digikey.com/en/products/detail/texas-instruments/LM339DR/276657) | Quad comparator, SOIC-14 | SOIC-14_3.9x8.7mm_P1.27mm | 0.29 | 0.87 | 0.12 | 0.36 |  |
| 7 | LED1, LED2, LED3, LED4, LED5, LED6, LED7 | LED red | Lite-On | [LTST-C170KRKT](https://www.digikey.com/en/products/detail/liteon/LTST-C170KRKT/386779) | LED red 0805, +12V indicator | LED_0805_2012Metric | 0.18 | 1.26 | 0.07 | 0.49 |  |
| 5 | Q9, Q11, Q13, Q15, Q17 | MMBT4401 | Diodes Inc | [MMBT4401-7-F](https://www.digikey.com/en/products/detail/diodes-incorporated/MMBT4401-7-F/775841) | NPN emitter follower (triac gate drive) | SOT-23 | ~0.12 | ~0.60 | 0.05 | 0.25 |  |
| 36 | R22, R26, R30, R34, R38, R42, R46, R50, R54, R58, ... (36 total) | 100 | Yageo | [RC0805FR-07100RL](https://www.digikey.com/en/products/result?keywords=RC0805FR-07100RL) | Resistor 100R 1% 0.125 W, 0805 | R_0805_2012Metric | ~0.10 | ~3.60 | 0.01 | 0.36 |  |
| 1 | R202 | 100 (DNP) | Yageo | [RC0805FR-07100RL](https://www.digikey.com/en/products/result?keywords=RC0805FR-07100RL) | Resistor 100R 1% 0.125 W, 0805 | R_0805_2012Metric | ~0.10 |  | 0.01 |  | DNP |
| 53 | R3, R4, R6, R9, R12, R15, R18, R21, R23, R27, ... (53 total) | 10K | Yageo | [RC0805FR-0710KL](https://www.digikey.com/en/products/result?keywords=RC0805FR-0710KL) | Resistor 10K 1% 0.125 W, 0805 | R_0805_2012Metric | ~0.10 | ~5.30 | 0.01 | 0.53 |  |
| 2 | R198, R209 | 10K | Yageo | [RC0805FR-0710KL](https://www.digikey.com/en/products/result?keywords=RC0805FR-0710KL) | Resistor 10K 0805 - DNP (the A-12697 waveform is a half-wave sample of one leg; populating R198 would make a 120 Hz full-wave sample) | R_0805_2012Metric | ~0.10 |  | 0.01 |  | DNP |
| 1 | R261 | 118K | Yageo | [RC0805FR-07118KL](https://www.digikey.com/en/products/result?keywords=RC0805FR-07118KL) | EN/UVLO divider top 118K (start 5.9 V / stop 5.5 V) | R_0805_2012Metric | ~0.10 | ~0.10 | 0.01 | 0.01 |  |
| 1 | R267 | 130K | Yageo | [RC0805FR-07130KL](https://www.digikey.com/en/products/result?keywords=RC0805FR-07130KL) | EN/UVLO divider top 130K (start 8.8 V / stop 8.4 V) | R_0805_2012Metric | ~0.10 | ~0.10 | 0.01 | 0.01 |  |
| 16 | R176, R178, R180, R182, R184, R186, R188, R190, R194, R196, ... (16 total) | 1.5K | Yageo | [RC0805FR-071K5L](https://www.digikey.com/en/products/result?keywords=RC0805FR-071K5L) | Resistor 1K5 1% 0.125 W, 0805 | R_0805_2012Metric | ~0.10 | ~1.60 | 0.01 | 0.16 |  |
| 18 | R154, R156, R158, R160, R162, R164, R166, R168, R170, R177, ... (18 total) | 1K | Yageo | [RC0805FR-071KL](https://www.digikey.com/en/products/result?keywords=RC0805FR-071KL) | Resistor 1K 1% 0.125 W, 0805 | R_0805_2012Metric | ~0.10 | ~1.80 | 0.01 | 0.18 |  |
| 1 | R268 | 20K | Yageo | [RC0805FR-0720KL](https://www.digikey.com/en/products/result?keywords=RC0805FR-0720KL) | EN/UVLO divider bottom 20K | R_0805_2012Metric | ~0.10 | ~0.10 | 0.01 | 0.01 |  |
| 2 | R263, R269 | 240K | Yageo | [RC0805FR-07240KL](https://www.digikey.com/en/products/result?keywords=RC0805FR-07240KL) | RT/CLK 240K -> 405 kHz (Rt = 101756 x fsw^-1.008) | R_0805_2012Metric | ~0.10 | ~0.20 | 0.01 | 0.02 |  |
| 1 | R192 | 270 | Yageo | [RC0805FR-07270RL](https://www.digikey.com/en/products/result?keywords=RC0805FR-07270RL) | LED series resistor 270 | R_0805_2012Metric | ~0.10 | ~0.10 | 0.01 | 0.01 |  |
| 1 | R206 | 27K | Yageo | [RC0805FR-0727KL](https://www.digikey.com/en/products/result?keywords=RC0805FR-0727KL) | Resistor 27K 1% 0805 (ZC threshold ~0.26 V) | R_0805_2012Metric | ~0.10 | ~0.10 | 0.01 | 0.01 |  |
| 1 | R270 | 28K | Yageo | [RC0805FR-0728KL](https://www.digikey.com/en/products/result?keywords=RC0805FR-0728KL) | Feedback top 28K (Vout = 0.8 V x (1 + Rtop/Rbot)) | R_0805_2012Metric | ~0.10 | ~0.10 | 0.01 | 0.01 |  |
| 1 | R262 | 29.4K | Yageo | [RC0805FR-0729K4L](https://www.digikey.com/en/products/result?keywords=RC0805FR-0729K4L) | EN/UVLO divider bottom 29.4K | R_0805_2012Metric | ~0.10 | ~0.10 | 0.01 | 0.01 |  |
| 1 | R271 | 2K | Yageo | [RC0805FR-072KL](https://www.digikey.com/en/products/result?keywords=RC0805FR-072KL) | Feedback bottom 2K | R_0805_2012Metric | ~0.10 | ~0.10 | 0.01 | 0.01 |  |
| 1 | R266 | 33.2K | Yageo | [RC0805FR-0733K2L](https://www.digikey.com/en/products/result?keywords=RC0805FR-0733K2L) | Compensation Rc 33.2K (TPS54360B eq. 48) | R_0805_2012Metric | ~0.10 | ~0.10 | 0.01 | 0.01 |  |
| 1 | R272 | 42.2K | Yageo | [RC0805FR-0742K2L](https://www.digikey.com/en/products/result?keywords=RC0805FR-0742K2L) | Compensation Rc 42.2K (TPS54360B eq. 48) | R_0805_2012Metric | ~0.10 | ~0.10 | 0.01 | 0.01 |  |
| 5 | R8, R11, R14, R17, R20 | 470 | Yageo | [RC0805FR-07470RL](https://www.digikey.com/en/products/result?keywords=RC0805FR-07470RL) | Resistor 470R 1% 0.125 W, 0805 | R_0805_2012Metric | ~0.10 | ~0.50 | 0.01 | 0.05 |  |
| 1 | W1 | 0R | Yageo | [RC2512JK-070RL](https://www.digikey.com/en/products/result?keywords=RC2512JK-070RL) | 0 R link 2512: G.I. return bus (triac MT1 / J115 returns) to the logic ground reference (OEM: J115-1 GND REF at the transformer) | R_2512_6332Metric | ~0.30 | ~0.30 | 0.08 | 0.08 |  |
| 2 | R259, R260 | 15K | Yageo | [RC2512JK-0715KL](https://www.digikey.com/en/products/result?keywords=RC2512JK-0715KL) | Resistor 15K 1 W 2512 bleeder (parallel to R260) | R_2512_6332Metric | ~0.30 | ~0.60 | 0.08 | 0.16 |  |
| 5 | R7, R10, R13, R16, R19 | 27 | Yageo | [RC2512JK-0727RL](https://www.digikey.com/en/products/result?keywords=RC2512JK-0727RL) | Resistor 27 R 5% 1 W 2512 (triac gate) | R_2512_6332Metric | ~0.30 | ~1.50 | 0.08 | 0.40 |  |
| 8 | R150, R151, R152, R153, R172, R173, R174, R175 | 0.22R | Yageo | [RL2512FK-070R22L](https://www.digikey.com/en/products/detail/yageo/RL2512FK-070R22L/2827691) | Resistor 0.22 R 1% 1 W current sense, 2512 | R_2512_6332Metric | ~0.35 | ~2.80 | 0.12 | 0.96 |  |
| 1 | R264 | 11.3K | Yageo | [RT0805BRD0711K3L](https://www.digikey.com/en/products/result?keywords=RT0805BRD0711K3L) | Feedback top 11.3K (Vout = 0.8 V x (1 + Rtop/Rbot), 0.1 % thin film) | R_0805_2012Metric | ~0.25 | ~0.25 | 0.06 | 0.06 |  |
| 1 | R265 | 2.1K | Yageo | [RT0805BRD072K1L](https://www.digikey.com/en/products/result?keywords=RT0805BRD072K1L) | Feedback bottom 2.1K, 0.1 % thin film | R_0805_2012Metric | ~0.25 | ~0.25 | 0.06 | 0.06 |  |
| 8 | D1, D2, D3, D9, D10, D11, D12, D38 | S1M-13-F | Diodes Inc | [S1M-13-F](https://www.digikey.com/en/products/detail/diodes-incorporated/S1M-13-F/804909) | Rectifier 1 A 1000 V, SMA (tie-back) | D_SMA | 0.19 | 1.52 | 0.07 | 0.56 |  |
| 1 | D35 | S1M (DNP) | Diodes Inc | [S1M-13-F](https://www.digikey.com/en/products/detail/diodes-incorporated/S1M-13-F/804909) | Relay coil diode (DNP) | D_SMA | 0.19 |  | 0.07 |  | DNP |
| 20 | D5, D6, D7, D8, D17, D18, D19, D20, D21, D22, ... (20 total) | S3M-13-F | Diodes Inc | [S3M-13-F](https://www.digikey.com/en/products/detail/diodes-incorporated/S3M-13-F/725029) | Rectifier 3 A 1000 V, SMC (tie-back) | D_SMC | 0.54 | 10.80 | 0.20 | 4.00 |  |
| 4 | U10, U11, U12, U13 | 74HCT74 | Texas Instruments | [SN74HCT74DR](https://www.digikey.com/en/products/detail/texas-instruments/SN74HCT74DR/276479) | Dual D flip-flop with preset/clear, SOIC-14 | SOIC-14_3.9x8.7mm_P1.27mm | ~0.55 | ~2.20 | 0.30 | 1.20 |  |
| 2 | L1, L2 | 10uH | Bourns | [SRP1265A-100M](https://www.digikey.com/en/products/detail/bourns-inc/SRP1265A-100M/4876620) | Inductor 10 uH 10 A (SRP1265A-100M) | L_Bourns_SRP1245A | ~2.10 | ~4.20 | 1.30 | 2.60 |  |
| 16 | D101, D102, D103, D104, D105, D106, D107, D108, D109, D110, ... (16 total) | STPS20M100S | STMicroelectronics | [STPS20M100SG-TR](https://www.digikey.com/en/products/detail/stmicroelectronics/STPS20M100SG-TR/2122461) | Schottky rectifier 100 V 20 A D2PAK - discrete bridge element +18V lamp matrix supply, AC_A -> + | D2PAK_Schottky_AKA | 1.58 | 25.28 | 0.52 | 8.32 |  |
| 1 | U19 | TBD62083AFWG | Toshiba | [TBD62083AFWG,EL](https://www.digikey.com/en/products/detail/toshiba-semiconductor-and-storage/TBD62083AFWG-EL/5514124) | 8-ch DMOS sink driver (ULN2803 pin-compatible), SOIC-18W | SOIC-18W_7.5x11.6mm_P1.27mm | ~1.10 | ~1.10 | 0.75 | 0.75 |  |
| 2 | U20, U21 | TPS54360BDDAR | Texas Instruments | [TPS54360BDDAR](https://www.digikey.com/en/products/detail/texas-instruments/TPS54360BDDAR/10434703) | +5.1 V 3 A buck converter | Texas_HSOP-8-1EP_3.9x4.9mm_P1.27mm | 4.52 | 9.04 | 3.05 | 6.10 |  |
| 32 | F101-F116 (2 per position) | clip | Keystone | [3517](https://www.digikey.com/en/products/detail/keystone-electronics/3517/316010) | Fuse clip 5 x 20 mm PCB mount, 15 A, tin (2 per fuse) - 16 positions incl. F101/F102 (clips only) | Fuseholder_Clip-5x20mm_Keystone_3517 | 0.32 | 10.24 | 0.14 | 4.32 |  |
| 5 | Q10, Q12, Q14, Q16, Q18 (mechanical) | heatsink | Boyd (Aavid) | [7019BG](https://www.digikey.com/en/products/result?keywords=7019BG) | Heatsink TO-220 bolt-on narrow channel with folded-back fins, 11.0 C/W, 39.4 x 9.5 x 25.4 mm, no PCB tabs (device screw only) - G.I. triacs, bolted to the insulated TO-220 tab | - | ~1.75 | ~8.75 | 1.15 | 5.75 |  |
| 1 | BR3 (mechanical) | heatsink | Boyd (Aavid) | [6224BG](https://www.digikey.com/en/products/result?keywords=6224BG) | Heatsink square basket for bridge rectifiers, 9.4 C/W, 26.92 mm sq x 31.75 mm, 4.77 mm hole (M4), sits on the metal base of the GBPC block - GBPC3510W, on the upward-facing metal base, M4 through the centre hole | - | ~8.50 | ~8.50 | 6.20 | 6.20 |  |
| 5 | Q10-Q18 hardware | hardware | B&F Fastener Supply | [MPMS 003 0012 PH](https://www.digikey.com/en/products/result?keywords=MPMS 003 0012 PH) | Screw M3 x 12 mm pan head Phillips, zinc (heatsink to TO-220 / GBJ / GBU) - with M3 nut; thread-lock | - | ~0.10 | ~0.50 | 0.04 | 0.20 |  |
| 5 | Q10-Q18 hardware | hardware | B&F Fastener Supply | [MHNZ 003](https://www.digikey.com/en/products/result?keywords=MHNZ 003) | Hex nut M3, zinc | - | ~0.06 | ~0.30 | 0.02 | 0.10 |  |
| 1 | BR3 hardware | hardware | B&F Fastener Supply | [MPMS 004 0016 PH](https://www.digikey.com/en/products/result?keywords=MPMS 004 0016 PH) | Screw M4 x 16 mm pan head Phillips, zinc (6224BG basket through the GBPC3510W centre hole) - captive under the block (no PCB hole in this revision) | - | ~0.12 | ~0.12 | 0.05 | 0.05 |  |
| 1 | BR3 hardware | hardware | B&F Fastener Supply | [MHNZ 004](https://www.digikey.com/en/products/result?keywords=MHNZ 004) | Hex nut M4, zinc | - | ~0.08 | ~0.08 | 0.03 | 0.03 |  |

**448 placed parts (incl. 32 fuse clips, 6 heatsinks and 12 screws / nuts) in 89 line items.  Parts cost per board: 282.71 USD at qty 1 (286 parts priced by estimate), 132.23 USD at qty 100; 0 parts without any price.**

## Cost by group

| group | parts | per board, qty 1 (USD) | per board, qty 100 (USD) |
|---|---|---|---|
| MOSFETs | 44 | 77.20 | 32.48 |
| Electrolytic capacitors | 7 | 21.70 | 13.65 |
| Connectors | 38 | 30.96 | 20.04 |
| Bridge rectifiers | 17 | 32.28 | 13.02 |
| Fuses + clips | 46 | 27.67 | 10.00 |
| Buck converters (IC, inductor, diode) | 6 | 14.48 | 9.30 |
| Logic / comparators / driver | 15 | 9.42 | 5.25 |
| SMD passives | 195 | 26.10 | 4.73 |
| Diodes + LEDs | 37 | 13.82 | 5.11 |
| Triacs + gate transistors + heatsinks | 28 | 26.10 | 17.33 |
| Misc / test points | 15 | 2.98 | 1.32 |
| **total components per board** | 448 | **282.71** | **132.23** |

Not included: the bare 4-layer 449 x 273 mm PCB, assembly, thermal compound for the six bolted heatsinks, M4 hardware for the 8 mounting holes, shipping / tax / attrition.  Heatsinks: docs/THERMAL_AND_PROTECTION.md (the OEM chassis bracket is replaced by device-mounted Boyd heatsinks on the triacs and BR3; the +18V / +20V / +5V raw / +12V power bridges are discrete D2PAK Schottky diodes cooled by board copper).

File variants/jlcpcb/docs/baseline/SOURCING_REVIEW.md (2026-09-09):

# Sourcing review — observations retrieved 2026-09-08

The current purchase BOM is generated from fresh schematic XML, plus explicit
heatsinks, screws/nuts, fuse clips and thermal paste. No order has been placed.
Stock figures below are web-page observations, sometimes from cached pages, not
reserved inventory or a binding quote. Reconfirm exact MPN, packaging, quantity,
authorized channel and delivery before purchasing. The historical `price100`
fields in `tools/sourcing.py` are estimates, not current production pricing.

## Changed selections

| Selection | Reason and compatibility | Availability evidence |
|---|---|---|
| IPD90N10S4L06ATMA1 | 100 V logic-level DPAK; 8.1 mΩ maximum at 4.5 V; improved output-driver thermal margin | [DigiKey: 4,523](https://www.digikey.com/en/products/detail/infineon-technologies/IPD90N10S4L06ATMA1/5960270); [Infineon active/preferred](https://www.infineon.com/part/IPD90N10S4L-06) |
| B41252A7109M000 ×5 | 10,000 µF/35 V; high ripple at ≤60 °C local ambient; 25.4×45 mm, 10 mm pitch, 6±1 mm leads; replaces the shorter-lead M067 selection | [DigiKey: 1,463](https://www.digikey.com/en/products/detail/tdk/B41252A7109M000/3493689) |
| STPS20M100ST ×4 | BR1 TO-220 A-K-A; new project footprint, routing and four separate heatsinks | [DigiKey: 624](https://www.digikey.com/en/products/detail/stmicroelectronics/STPS20M100ST/2122463) |
| Boyd 577202B00000G ×4 | BR1 sink, 13.21×12.70×19.05 mm, 24.4 °C/W catalogue natural convection | [DigiKey: 58,431](https://www.digikey.com/en/products/detail/boyd-laconia-llc/577202B00000G/108322) |
| Boyd 7020BG ×5 | Replaces poorly stocked 7019BG; 33.02×11.94×36.83 mm, 8.7 °C/W; CAD and thermal model updated | [DigiKey: 2,256](https://www.digikey.com/en/products/detail/boyd-laconia-llc/7020BG/1625705) |
| Boyd 6223BG ×1 | Replaces poorly stocked 6224BG; same 26.92 mm square/31.75 mm high, 9.4 °C/W; 4.14 mm hole requires actual M4 fit check | [DigiKey: 2,212](https://www.digikey.com/en/products/detail/boyd-laconia-llc/6223BG/1625608) |
| 3M N2534-6002-RB | Active vertical 34-pin IDC; old 30334-5002HB was obsolete and right angle; 50.50×8.59 mm body, 0.90 mm finished PCB holes | [DigiKey: 2,137](https://www.digikey.com/en/products/detail/3m/N2534-6002-RB/755183); [3M drawing](https://multimedia.3m.com/mws/media/330367O/3m-four-wall-header-2500-series-ts-0770.pdf?fn=ts0770_R10.pdf) |
| C0805C333K5RACTU | KEMET 33 nF, ±10%, 50 V, X7R, 0805; replaces obsolete Samsung CL21B333KBANNNC | [DigiKey: 112,623](https://www.digikey.com/en/products/detail/kemet/C0805C333K5RACTU/411440); [manufacturer specification](https://search.kemet.com/download/specsheet/C0805C333K5RACTU) |
| C0805C471J5GACTU | KEMET 470 pF, ±5%, 50 V, C0G, 0805; replaces obsolete CL21C471JBANNNC | [DigiKey: 74,684](https://www.digikey.com/en/products/detail/kemet/C0805C471J5GACTU/411132); [manufacturer specification](https://search.kemet.com/download/specsheet/C0805C471J5GACTU) |
| C0805C391J5GACTU | KEMET 390 pF, ±5%, 50 V, C0G, 0805; same electrical specification, available replacement | [Mouser: 5,673](https://www.mouser.com/es/ProductDetail/KEMET/C0805C391J5GACTU?qs=Z8iU%252BYX8GzEXY6S0ID4LXw%3D%3D); [manufacturer specification](https://search.kemet.com/download/specsheet/C0805C391J5GACTU) |
| C0805C103K5RACTU | KEMET 10 nF, ±10%, 50 V, X7R, 0805; available replacement | [DigiKey: 1,532,160](https://www.digikey.pl/pl/products/detail/kemet/C0805C103K5RACTU/411157); [manufacturer specification](https://search.kemet.com/component-documentation/download/specsheet/C0805C103K5RACTU) |

KEMET nominal bodies are 2.0×1.25×0.78 mm, maximum thickness 0.88 mm;
standard 0805 pads remain appropriate. Capacitance, dielectric and tolerance
assumptions in the loop/transient tests are unchanged. Catalogue thermal resistance
requires the stated mounting/airflow; a stock check does not validate thermal performance.

## Connector ordering-code correction

All 33 KK396 fields used transposed ordering digits. The corrected family is
`0026604NN0`, where NN is the position count. This is a catalogue correction,
with unchanged pin pitch and routing. Full-pin stock requires key-pin removal
as documented in [ASSEMBLY_NOTES.md](ASSEMBLY_NOTES.md); an NC pin is not itself
a key designation. The native models now depict the specified removed pins.

| Ways / MPN | Distributor observation |
|---|---|
| 3 / 0026604030 | [DigiKey: 32,525](https://www.digikey.com/en/products/detail/molex/0026604030/96502) |
| 4 / 0026604040 | [DigiKey: 59,962](https://www.digikey.com.br/en/products/detail/molex/0026604040/197447) |
| 5 / 0026604050 | DigiKey related-product listing showed 9,556; reconfirm exact current stock |
| 6 / 0026604060 | [TTI: 4,297](https://www.tti.com/content/ttiinc/en/apps/part-detail.html?mfgShortname=MOL&partsNumber=0026604060) |
| 7 / 0026604070 | [DigiKey: 17,033](https://www.digikey.com/en/products/detail/molex/0026604070/97339) |
| 9 / 0026604090 | [DigiKey active listing](https://www.digikey.com/en/products/detail/molex/0026604090/79784); quantity not retained |
| 11 / 0026604110 | [DigiKey: 774](https://www.digikey.com.au/en/products/detail/molex/0026604110/193997) |
| 12 / 0026604120 | [DigiKey active listing](https://www.digikey.com/en/products/detail/molex/0026604120/193986); quantity not retained |
| 13 / 0026604130 | [DigiKey: 2,482](https://www.digikey.com/en/products/detail/molex/0026604130/3044429) |

## Retained parts checked

| Part | Evidence |
|---|---|
| TPS54360BDDAR | TI active; DigiKey search showed 963; vendor-model testing uses TI's compatible transient model |
| STPS20M100SG-TR | [Mouser: 1,847](https://www.mouser.com/en/ProductDetail/STMicroelectronics/STPS20M100SG-TR?qs=5HwTSiuA5HCdrjP2dKfpog%3D%3D) |
| GBPC3510W-E4/51 | [Mouser: 1,657](https://www.mouser.com/ProductDetail/Vishay-Semiconductors/GBPC3510W-E4-51?qs=AvlKB63p5SkfiLMdbYKoSQ%3D%3D) |
| BTA16-600CRG | [DigiKey: 5,836](https://www.digikey.com/en/products/detail/stmicroelectronics/BTA16-600CRG/669145) |
| IRFR5305TRPBF | [DigiKey: 35,543](https://www.digikey.com/en/products/detail/infineon-technologies/IRFR5305TRPBF/812554) |
| IRLR024NTRPBF | Infineon active; DigiKey search showed 52,569 |
| 74HCT574D,653 | Mouser search showed 20,221; DigiKey 1,750 |
| 74HCT240D,653 | [DigiKey: 1,359](https://www.digikey.com/en/products/detail/nexperia-usa-inc/74HCT240D-653/1230746) |
| SN74HCT74DR | [DigiKey: 5,161](https://www.digikey.com/en/products/detail/texas-instruments/SN74HCT74DR/276854) |
| LM339DR | [DigiKey: 23,050](https://www.digikey.com/en/products/detail/texas-instruments/LM339DR/276657); 0–70 °C ambient grade |
| TBD62083AFWG,EL | Avnet search showed 2,000; retain Toshiba DMOS array, not a Darlington pin-compatible assumption |
| B560C-13-F | [DigiKey: 140,710, active](https://www.digikey.com/en/products/detail/diodes-incorporated/B560C-13-F/768773) |
| S3M-13-F | [DigiKey: 3,895, active](https://www.digikey.com/en/products/base-product/diodes-incorporated/31/S3M/4379) |
| LLS2A222MELA | [DigiKey: 187](https://www.digikey.com/en/products/detail/nichicon/LLS2A222MELA/2548962) |
| EEU-FR1E331 | [DigiKey: 3,304, active](https://www.digikey.jp/ja/products/detail/panasonic-industry/EEU-FR1E331/2433549) |
| SRP1265A-100M | [DigiKey: 21,314](https://www.digikey.com/en/products/detail/bourns-inc/SRP1265A-100M/4876620) |
| CL32B106KBJNNWE | [DigiKey: 4,997, active](https://www.digikey.com/en/products/detail/samsung-electro-mechanics/CL32B106KBJNNWE/3889046) |
| CL21B104KBCNNNC | [DigiKey: 5,413,821, active](https://www.digikey.com/en/products/detail/samsung-electro-mechanics/CL21B104KBCNNNC/3886661) |
| LTST-C170KRKT | [DigiKey: 489,785, active](https://www.digikey.com/en/products/detail/liteon/LTST-C170KRKT/386779) |
| RT0805BRD0711K3L | [DigiKey substitute table: 5,160](https://www.digikey.com/en/products/detail/panasonic-industry/ERA-6AEB1132V/2025757); retain exact part; Panasonic ERA-6AEB1132V is an available same-value alternative, not installed in this BOM |
| RT0805BRD072K1L | [DigiKey substitute table: 2,604](https://www.digikey.com/en/products/detail/yageo/AT0805DRD072K1L/5910684) |
| RC0805FR-0728KL | [DigiKey: 12,282, active](https://www.digikey.com/en/products/detail/yageo/RC0805FR-0728KL/730735) |
| RL2512FK-070R22L | [Mouser listing: 14,928](https://www.mouser.com/c/passive-components/resistors/current-sense-resistors-smd/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); use exact 1% part, account for TCR |
| 4610X-101-472LF | [DigiKey: 24,276, active](https://www.digikey.ca/en/products/detail/bourns-inc/4610X-101-472LF/1089205) |
| 0022232091 | [DigiKey: 3,292](https://www.digikey.com/en/products/detail/molex/0022232091/26681) |
| 0022232051 | [TTI: 85,175](https://www.tti.com/content/ttiinc/en/apps/part-detail.html?mfgShortname=MOL&partsNumber=22-23-2051) |
| 0239005.MXP | [DigiKey: 2,238, active](https://www.digikey.com/en/products/detail/littelfuse-inc/0239005-MXP/778232) |
| MG 8616-3ML | [DigiKey: 83](https://www.digikey.com/en/products/detail/mg-chemicals/8616-3ML/4899944) |
| M3×8 MPMS 003 0008 PH | [DigiKey: 45,707](https://www.digikey.com/en/products/detail/bfirst-industrial/MPMS-003-0008-PH/274954) |

The remaining procurement task is an order-time quotation covering all quantities,
minimum pack sizes, exact packaging and delivery. Stock observations below close
additional catalogue checks; they do not reserve inventory. Fuse DC breaking
capacity and time-current coordination require application review independently
of availability. Any substitution requires a specification and footprint review.

Additional retained-value observations: [118 kΩ: 15,904](https://www.digikey.in/en/products/detail/yageo/RC0805FR-07118KL/727566),
[29.4 kΩ: 46,881](https://www.digikey.ca/en/products/detail/yageo/RC0805FR-0729K4L/727796),
[240 kΩ: in stock](https://uk.rs-online.com/web/p/surface-mount-resistors/2426949),
[33.2 kΩ: 11,066](https://www.mouser.com/ProductDetail/YAGEO/RC0805FR-0733K2L?qs=QrWOOBGzeCbCvHLaHT4sLQ%3D%3D),
[130 kΩ: 92,932](https://www.digikey.in/en/products/detail/yageo/RC0805FR-07130KL/727590),
[42.2 kΩ: 16,375](https://www.digikey.com/en/products/detail/yageo/RC0805FR-0742K2L/727949),
[27 Ω 2512: 4,201](https://www.digikey.com/en/products/detail/yageo/RC2512JK-0727RL/12708610),
[0 Ω 2512: 69,260](https://www.mouser.com/en/ProductDetail/YAGEO/RC2512JK-070RL?qs=Fz%2FrpjPuTcGb5uCYF3SHgw%3D%3D),
[Keystone 3517: 66,018](https://www.newark.com/keystone/3517/fuse-holder/dp/74R7981).
These are the exact YAGEO MPNs in the corresponding BOM rows, not generic value substitutions.

C5 also uses B41252A7109M000. Its previous Rubycon selection exceeded the
conservative 50 Hz ripple bound by 1.5% in one modeled corner. The common TDK
replacement preserves 10,000 µF and 10 mm lead pitch; the taller body is included
in the current nominal mechanical review.

## Further catalogue closure

| Exact MPN | Observed stock |
|---|---|
| RC0805FR-07100RL | [DigiKey: 893,630](https://www.digikey.com/en/products/detail/yageo/RC0805FR-07100RL/727543) |
| RC0805FR-0710KL | [DigiKey: 2,318,254](https://www.digikey.com/en/products/detail/yageo/RC0805FR-0710KL/727535) |
| RC0805FR-071K5L | [DigiKey: 622,689](https://www.digikey.com/en/products/detail/yageo/RC0805FR-071K5L/727496) |
| RC0805FR-071KL | [DigiKey: 895,275](https://www.digikey.com/en/products/detail/yageo/RC0805FR-071KL/730391) |
| RC0805FR-0720KL | [DigiKey: 22,085](https://www.digikey.com/en/products/detail/yageo/RC0805FR-0720KL/730667) |
| RC0805FR-07270RL | [DigiKey: 137,783](https://www.digikey.com/en/products/detail/yageo/RC0805FR-07270RL/727783) |
| RC0805FR-0727KL | [DigiKey: 46,879](https://www.digikey.com/en/products/detail/yageo/RC0805FR-0727KL/727780) |
| RC0805FR-072KL | [DigiKey: 785,611](https://www.digikey.com/en/products/detail/yageo/RC0805FR-072KL/727664) |
| RC0805FR-07240KL | [DigiKey: 31,229](https://www.digikey.com/en/products/detail/yageo/RC0805FR-07240KL/727762) |
| RC0805FR-07470RL | [DigiKey: 229,402](https://www.digikey.com/en/products/detail/yageo/RC0805FR-07470RL/727976) |
| RC2512JK-0715KL | [DigiKey: 1,933](https://www.digikey.com/en/products/detail/yageo/RC2512JK-0715KL/5922492) |
| 0239003.MXP | [DigiKey: 2,949](https://www.digikey.com/en/products/detail/littelfuse-inc/0239003-MXP/778224) |
| 0239007.MXP | [DigiKey: 3,891](https://www.digikey.com/en/products/detail/littelfuse-inc/0239007-MXP/778234) |
| 0239.750MXP | [DigiKey: 871](https://www.digikey.com/en/products/detail/littelfuse-inc/0239-750MXP/778208) |
| 0217008.MXP | [DigiKey: 6,063](https://www.digikey.com/en/products/detail/littelfuse-inc/0217008-MXP/777551) |
| S1M-13-F | [DigiKey: 2,671](https://www.digikey.com/en/products/detail/diodes-incorporated/S1M-13-F/804883) |
| 1N4148W-7-F | [DigiKey: 1,395,759](https://www.digikey.com/en/products/detail/diodes-incorporated/1N4148W-7-F/815280) |
| MPMS 003 0012 PH | [DigiKey: 2,122](https://www.digikey.com/en/products/detail/bfirst-industrial/MPMS-003-0012-PH/274955) |
| MHNZ 003 | [DigiKey: 43,616](https://www.digikey.com/en/products/detail/bfirst-industrial/MHNZ-003/274973) |
| MHNZ 004 | [DigiKey: 6,132](https://www.digikey.com/en/products/detail/bfirst-industrial/MHNZ-004/274974) |

MMBT4401-7-F is active; [DigiKey exact-part substitute listing](https://www.digikey.com/en/products/detail/diodes-incorporated/MMBT4401-7-F-W/27803722)
showed 98,504 of the exact -7-F part. The -W suffix is not substituted.
[KK396 nine-way stock](https://www.digikey.com/en/products/detail/molex/0026604090/79784)
was 1,145, and [12-way stock](https://www.digikey.com/en/products/detail/molex/0026604120/193986)
was 5,330.

The unconfirmed M4 screw ordering code has been replaced with **Kanebridge
MJ416MPP**, confirmed in the [manufacturer catalogue](https://legacy.kanebridge.com/kaneprls.asp?SellCode=MJ-MPP).
[DigiKey/Fix Supply](https://www.digikey.com/en/products/detail/kanebridge/MJ416MPP/21635726)
lists 60,000, but a 3,000-piece carton minimum: do not interpret the one-board BOM
quantity as the seller's minimum. Seek split packs from the manufacturer's
resellers when obtaining the procurement quotation. This is zinc steel, M4×16,
JIS-B1111 Phillips pan, 6.75 mm head diameter and 2.60 mm height. The existing
7.6×3.0 mm CAD head envelope conservatively bounds it; shaft and engagement remain
unchanged. The old MPMS 004 0016 PH catalogue entry is not qualified for ordering.

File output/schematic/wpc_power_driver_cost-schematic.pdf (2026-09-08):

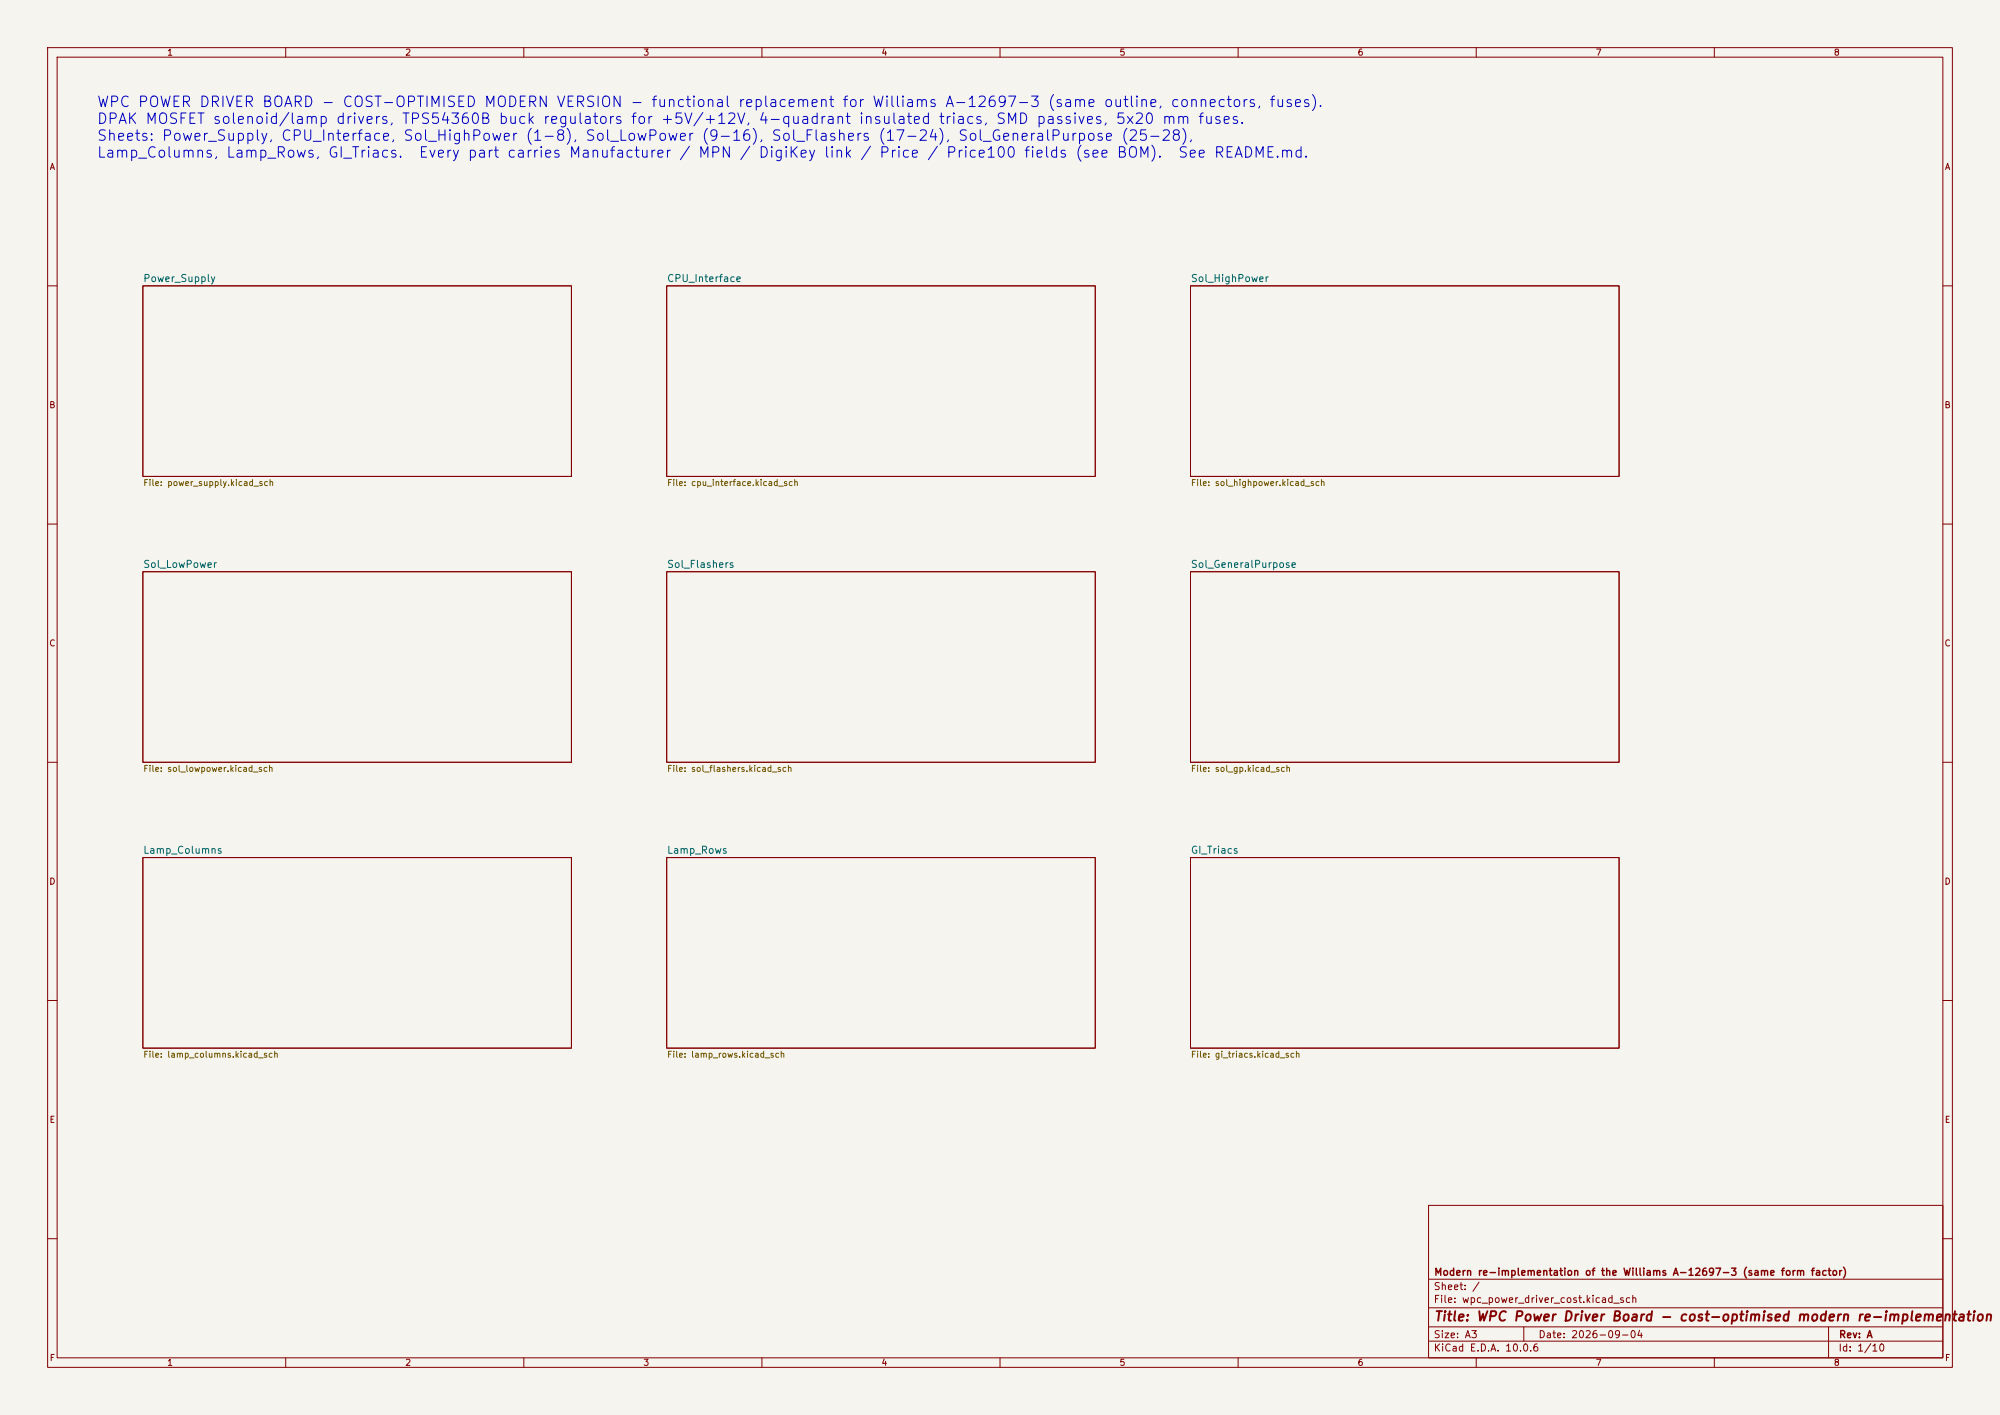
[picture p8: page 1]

WPC POWER DRIVER BOARD - COST-OPTIMISED MODERN VERSION - functional replacement for Williams A-12697-3 (same outline, connectors, fuses).
DPAK MOSFET solenoid/lamp drivers, TPS54360B buck regulators for +5V/+12V, 4-quadrant insulated triacs, SMD passives, 5x20 mm fuses.
Sheets: Power_Supply, CPU_Interface, Sol_HighPower (1-8), Sol_LowPower (9-16), Sol_Flashers (17-24), Sol_GeneralPurpose (25-28),
Lamp_Columns, Lamp_Rows, GI_Triacs. Every part carries Manufacturer / MPN / DigiKey link / Price / Price100 fields (see BOM). See README.md.

Modern re-implementation of the Williams A-12697-3 (same form factor)
Sheet: /
File: wpc_power_driver_cost.kicad_sch
Title: WPC Power Driver Board - cost-optimised modern re-implementation

Size: A3 | Rev: A | F Date: 2026-09-04
KiCad E.D.A. 10.0.6 | Id: 1/10

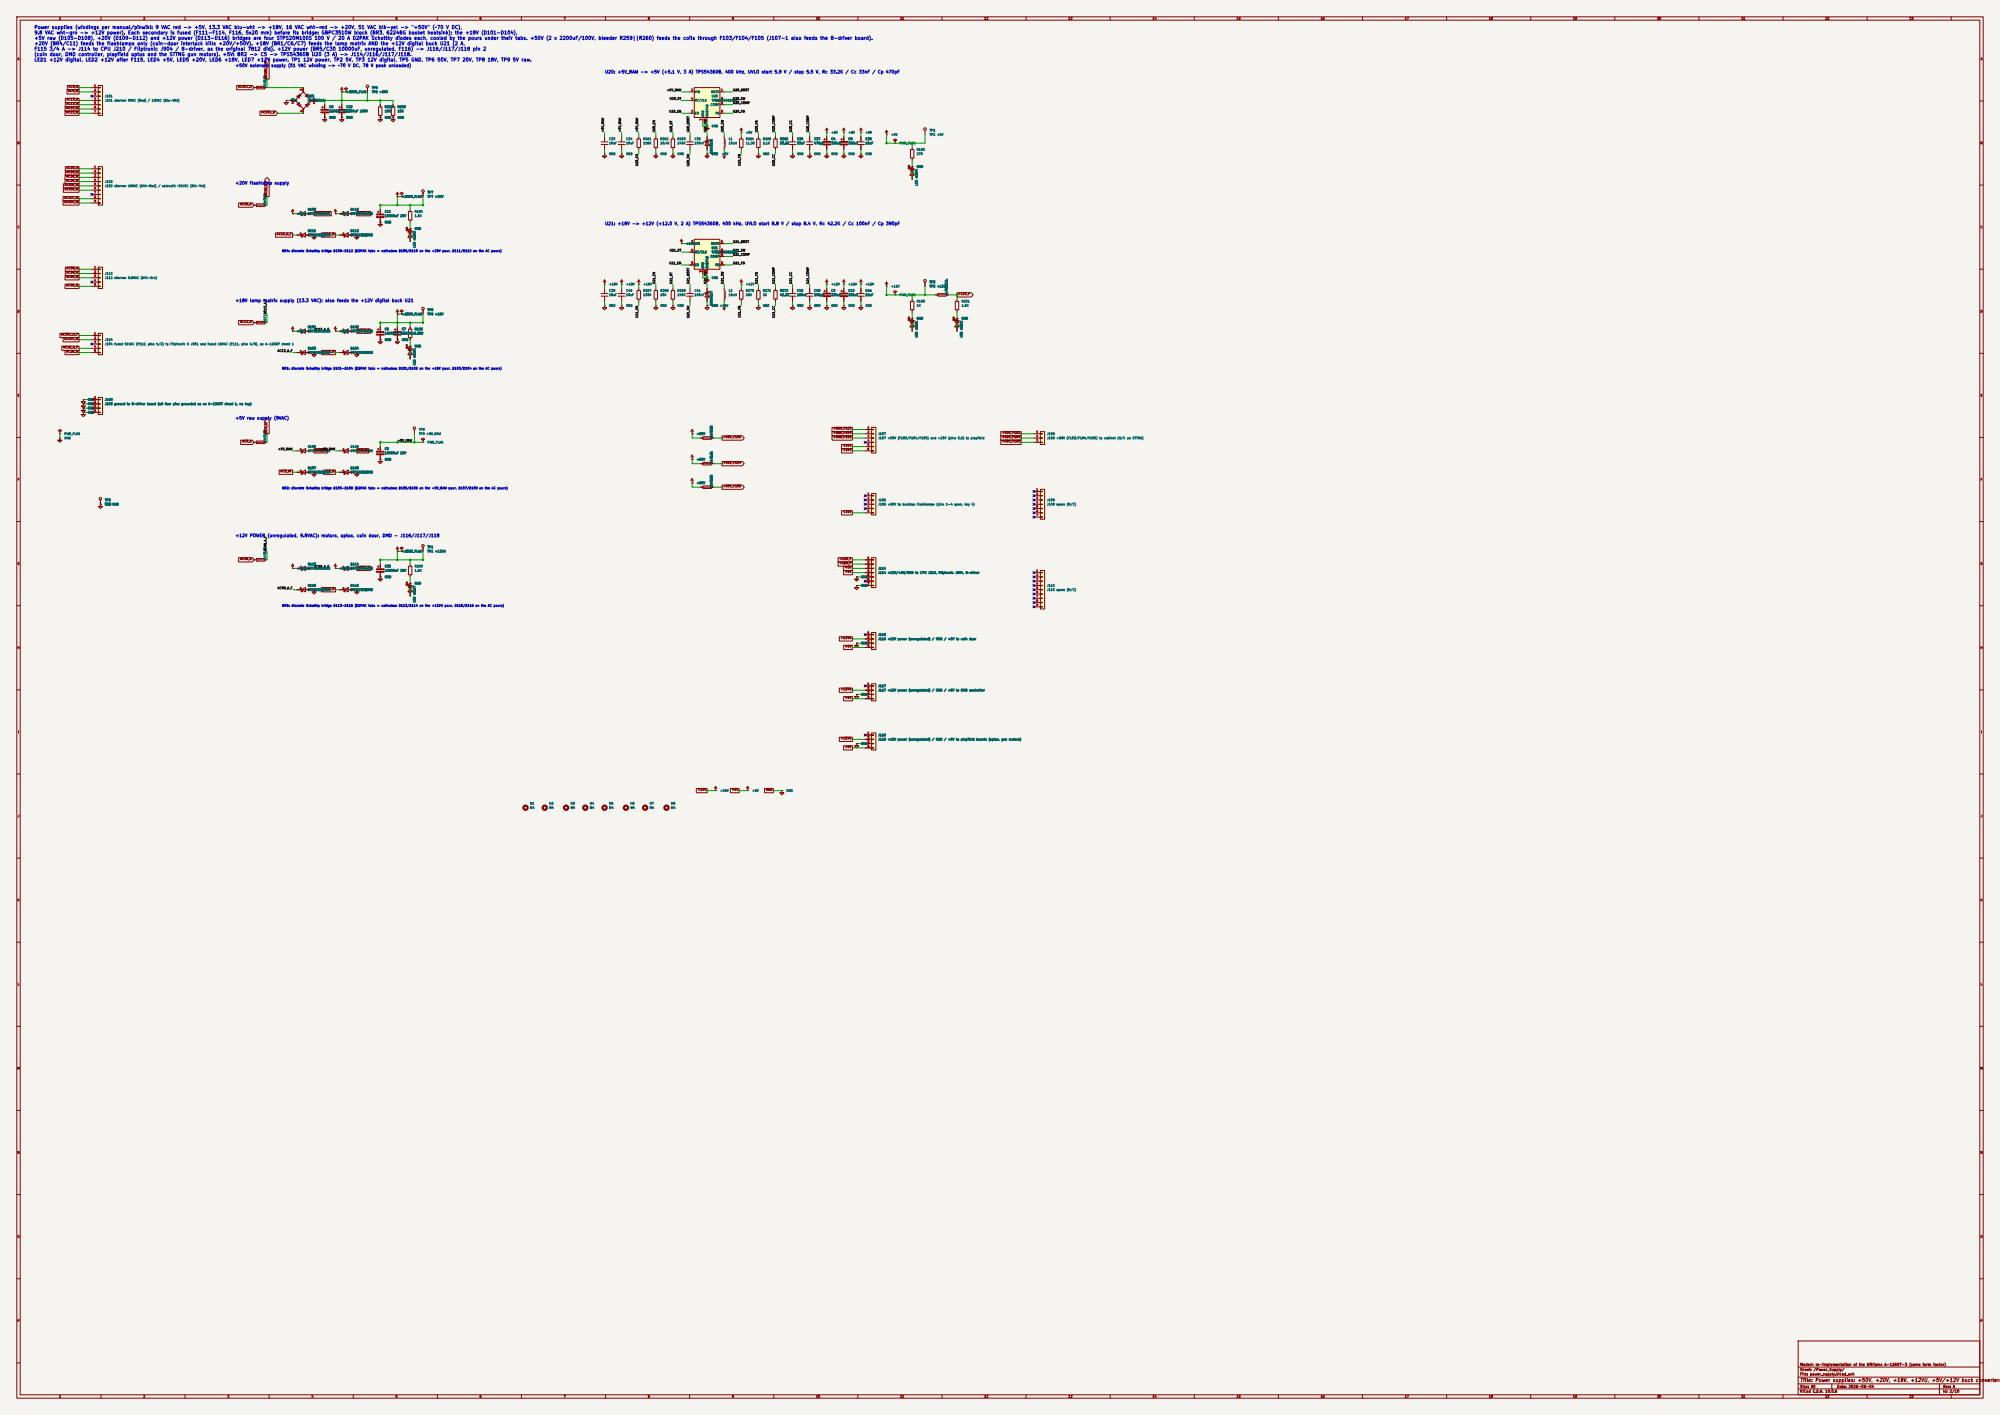
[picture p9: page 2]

Power supplies (windings per manual/pinwiki: 9 VAC red -> +5V, 13.3 VAC blu-wht -> +18V, 16 VAC wht-red -> +20V, 51 VAC blk-yel -> "+50V" (~70 V DC),
9.8 VAC wht-grn -> +12V power). Each secondary is fused (F111-F114, F116, 5x20 mm) before its bridge: GBPC3510W block (BR3, 6224BG basket heatsink); the +18V (D101-D104),
+5V raw (D105-D108), +20V (D109-D112) and +12V power (D113-D116) bridges are four STPS20M100S 100 V / 20 A D2PAK Schottky diodes each, cooled by the pours under their tabs. +50V (2 x 2200uF/100V, bleeder R259||R260) feeds the coils through F103/F104/F105 (J107-1 also feeds the 8-driver board).
+20V (BR4/C11) feeds the flashlamps only (coin-door interlock kills +20V/+50V). +18V (BR1/C6/C7) feeds the lamp matrix AND the +12V digital buck U21 (2 A,
F115 3/4 A -> J114 to CPU J210 / Fliptronic J904 / 8-driver, as the original 7812 did). +12V power (BR5/C30 10000uF, unregulated, F116) -> J116/J117/J118 pin 2
(coin door, DMD controller, playfield optos and the STTNG gun motors). +5V: BR2 -> C5 -> TPS54360B U20 (3 A) -> J114/J116/J117/J118.
LED1 +12V digital, LED2 +12V after F115, LED4 +5V, LED5 +20V, LED6 +18V, LED7 +12V power. TP1 12V power, TP2 5V, TP3 12V digital, TP5 GND, TP6 50V, TP7 20V, TP8 18V, TP9 5V raw.

+50V solenoid supply (51 VAC winding -> ~70 V DC, 78 V peak unloaded)
2200uF 100V GND

U20: +5V_RAW -> +5V (+5.1 V, 3 A) TPS54360B, 400 kHz, UVLO start 5.9 V / stop 5.5 V, Rc 33.2K / Cc 33nF / Cp 470pF

J101 xformer 9VAC (Red) / 13VAC (Blu-Wht)

U21: +18V -> +12V (+12.0 V, 2 A) TPS54360B, 400 kHz, UVLO start 8.8 V / stop 8.4 V, Rc 42.2K / Cc 100nF / Cp 390pF

BR1: discrete Schottky bridge D101-D104 (D2PAK tabs = cathodes: D101/D102 on the +18V pour, D103/D104 on the AC pours) BR4: discrete Schottky bridge D109-D112 (D2PAK tabs = cathodes: D109/D110 on the +20V pour, D111/D112 on the AC pours)

+18V lamp matrix supply (13.3 VAC); also feeds the +12V digital buck U21

J104 fused 51VAC (F112, pins 1/2) to Fliptronic II J901 and fused 16VAC (F111, pins 4/5), as A-12697 sheet 1 F114 8A

GND LED2 LED redLED1 LED red GND

J103 ground to 8-driver board (all four pins grounded as on A-12697 sheet 1, no key) 1

GND

J107 +50V (F103/F104/F105) and +20V (pins 5,6) to playfield

J108 +50V (F103/F104/F105) to cabinet (N/C on STTNG)

BR5: discrete Schottky bridge D113-D116 (D2PAK tabs = cathodes: D113/D114 on the +12VU pour, D115/D116 on the AC pours) BR2: discrete Schottky bridge D105-D108 (D2PAK tabs = cathodes: D105/D106 on the +5V_RAW pour, D107/D108 on the AC pours)

J106 +20V to backbox flashlamps (pins 1-4 open, key 4)

+12V POWER (unregulated, 9.8VAC): motors, optos, coin door, DMD - J116/J117/J118

J114 +12V/+5V/GND to CPU J210, Fliptronic J904, 8-driver

J116 +12V power (unregulated) / GND / +5V to coin door

J117 +12V power (unregulated) / GND / +5V to DMD controller 1

J117 +12V power (unregulated) / GND / +5V to DMD controller

J118 +12V power (unregulated) / GND / +5V to playfield boards (optos, gun motors) 1

J118 +12V power (unregulated) / GND / +5V to playfield boards (optos, gun motors)

Modern re-implementation of the Williams A-12697-3 (same form factor)
Sheet: /Power_Supply/
File: power_supply.kicad_sch
Title: Power supplies: +50V, +20V, +18V, +12VU, +5V/+12V buck converters, distribution

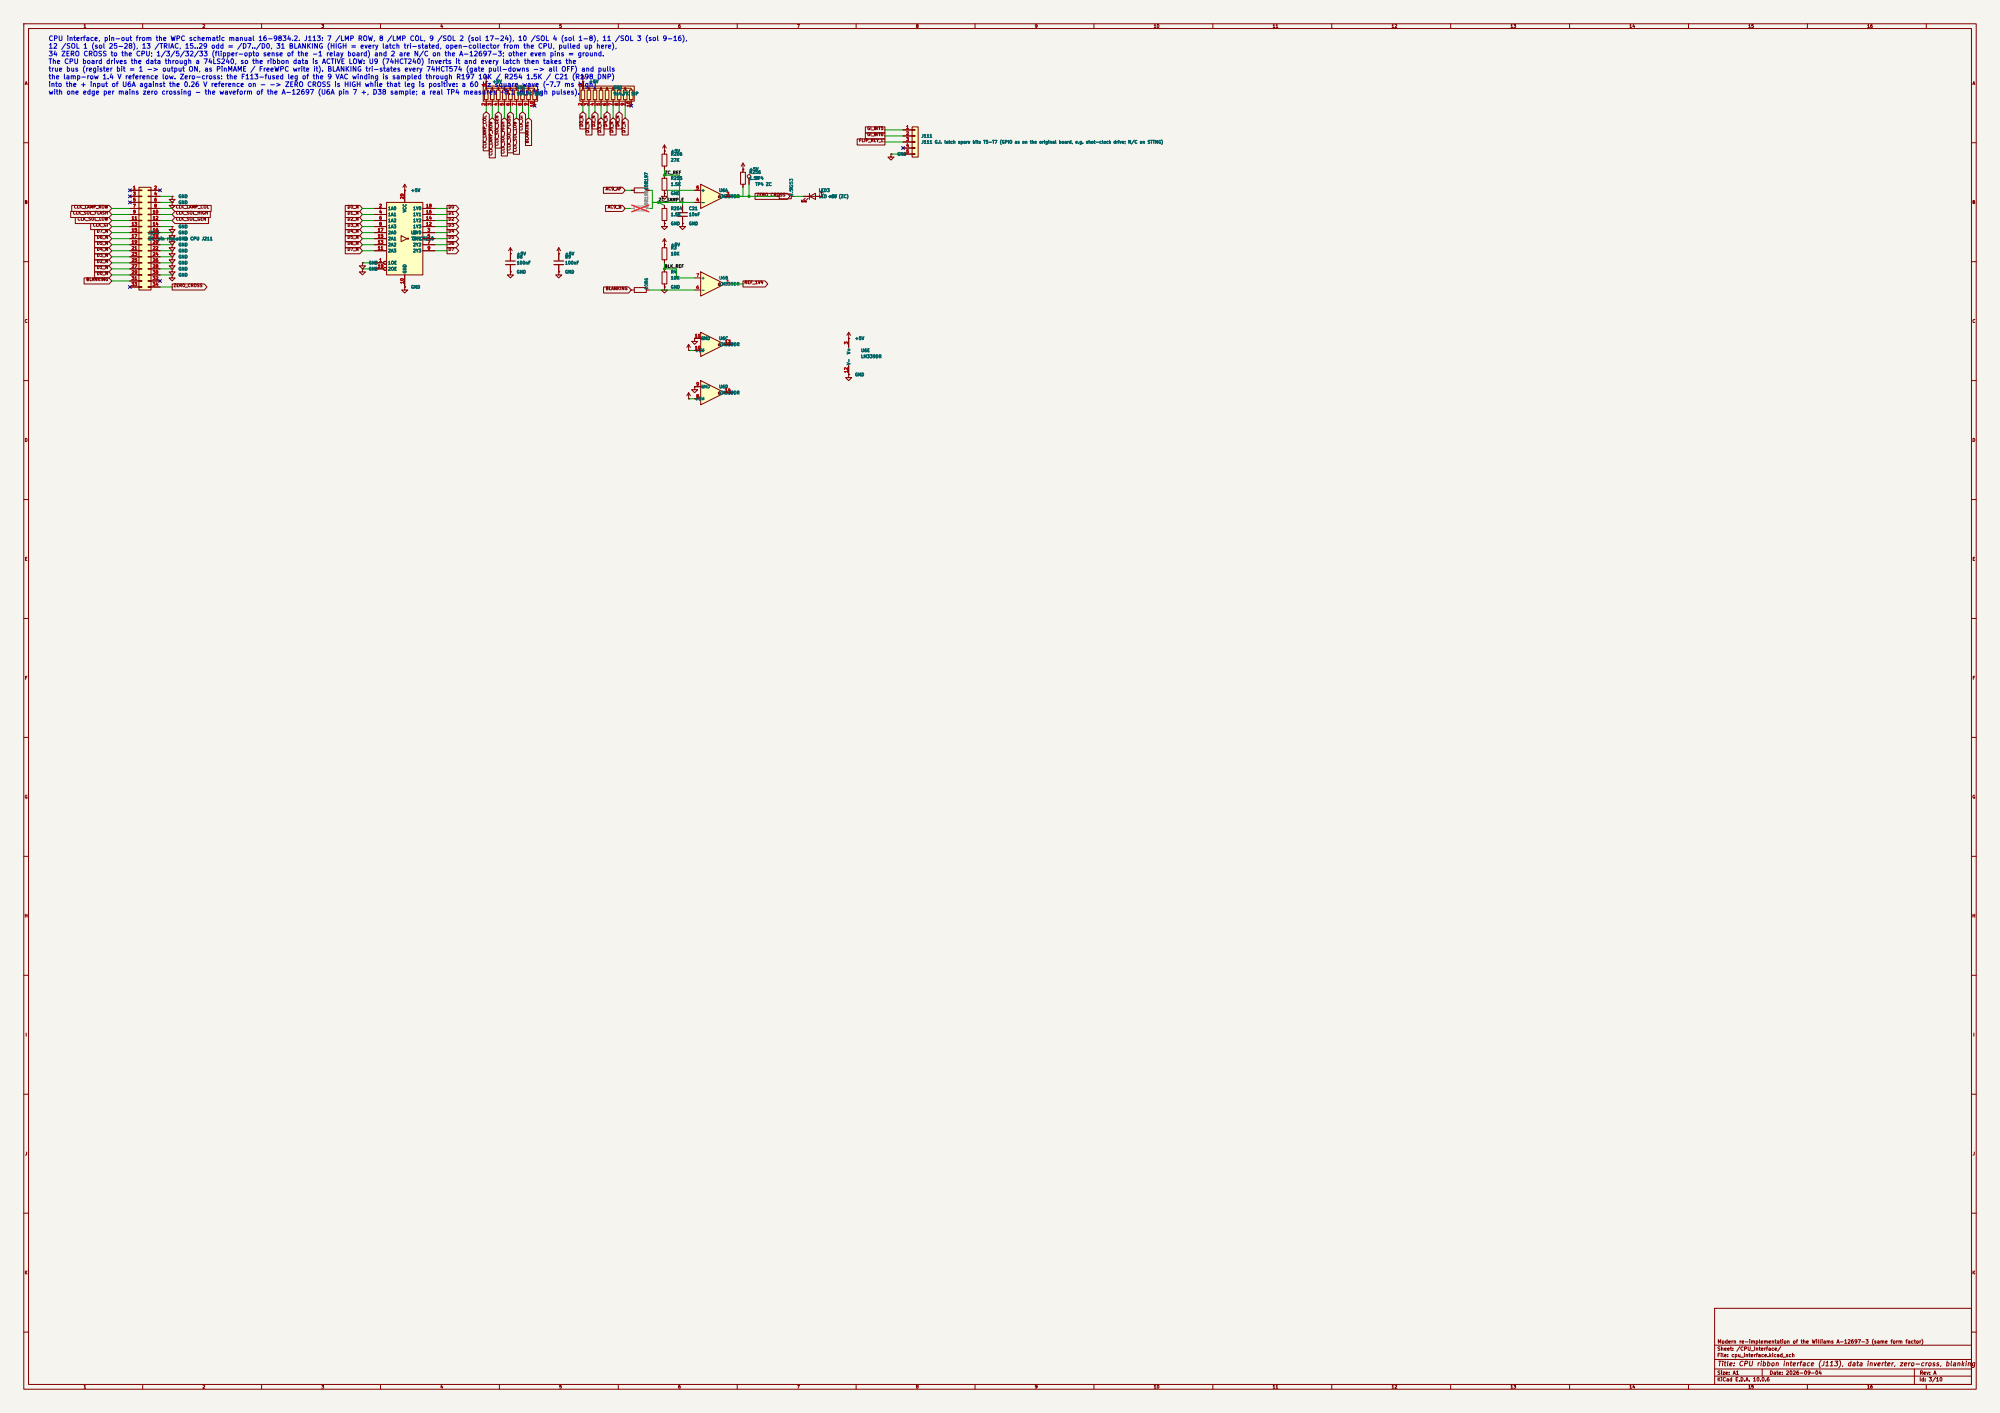
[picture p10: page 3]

ZC_REF ZC_SAMPLE BLK_REF CPU interface, pin-out from the WPC schematic manual 16-9834.2. J113: 7 /LMP ROW, 8 /LMP COL, 9 /SOL 2 (sol 17-24), 10 /SOL 4 (sol 1-8), 11 /SOL 3 (sol 9-16),
12 /SOL 1 (sol 25-28), 13 /TRIAC, 15..29 odd = /D7../D0, 31 BLANKING (HIGH = every latch tri-stated, open-collector from the CPU, pulled up here),
34 ZERO CROSS to the CPU; 1/3/5/32/33 (flipper-opto sense of the -1 relay board) and 2 are N/C on the A-12697-3; other even pins = ground.
The CPU board drives the data through a 74LS240, so the ribbon data is ACTIVE LOW: U9 (74HCT240) inverts it and every latch then takes the
true bus (register bit = 1 -> output ON, as PinMAME / FreeWPC write it). BLANKING tri-states every 74HCT574 (gate pull-downs -> all OFF) and pulls
the lamp-row 1.4 V reference low. Zero-cross: the F113-fused leg of the 9 VAC winding is sampled through R197 10K / R254 1.5K / C21 (R198 DNP)
into the + input of U6A against the 0.26 V reference on - -> ZERO CROSS is HIGH while that leg is positive: a 60 Hz square wave (~7.7 ms high)

J111 G.I. latch spare bits T5-T7 (GPIO as on the original board, e.g. shot-clock drive; N/C on STTNG) 1

J111 G.I. latch spare bits T5-T7 (GPIO as on the original board, e.g. shot-clock drive; N/C on STTNG) GND

34-pin ribbon to CPU J211 GND

34-pin ribbon to CPU J211

Sheet: /CPU_Interface/
File: cpu_interface.kicad_sch
Title: CPU ribbon interface (J113), data inverter, zero-cross, blanking

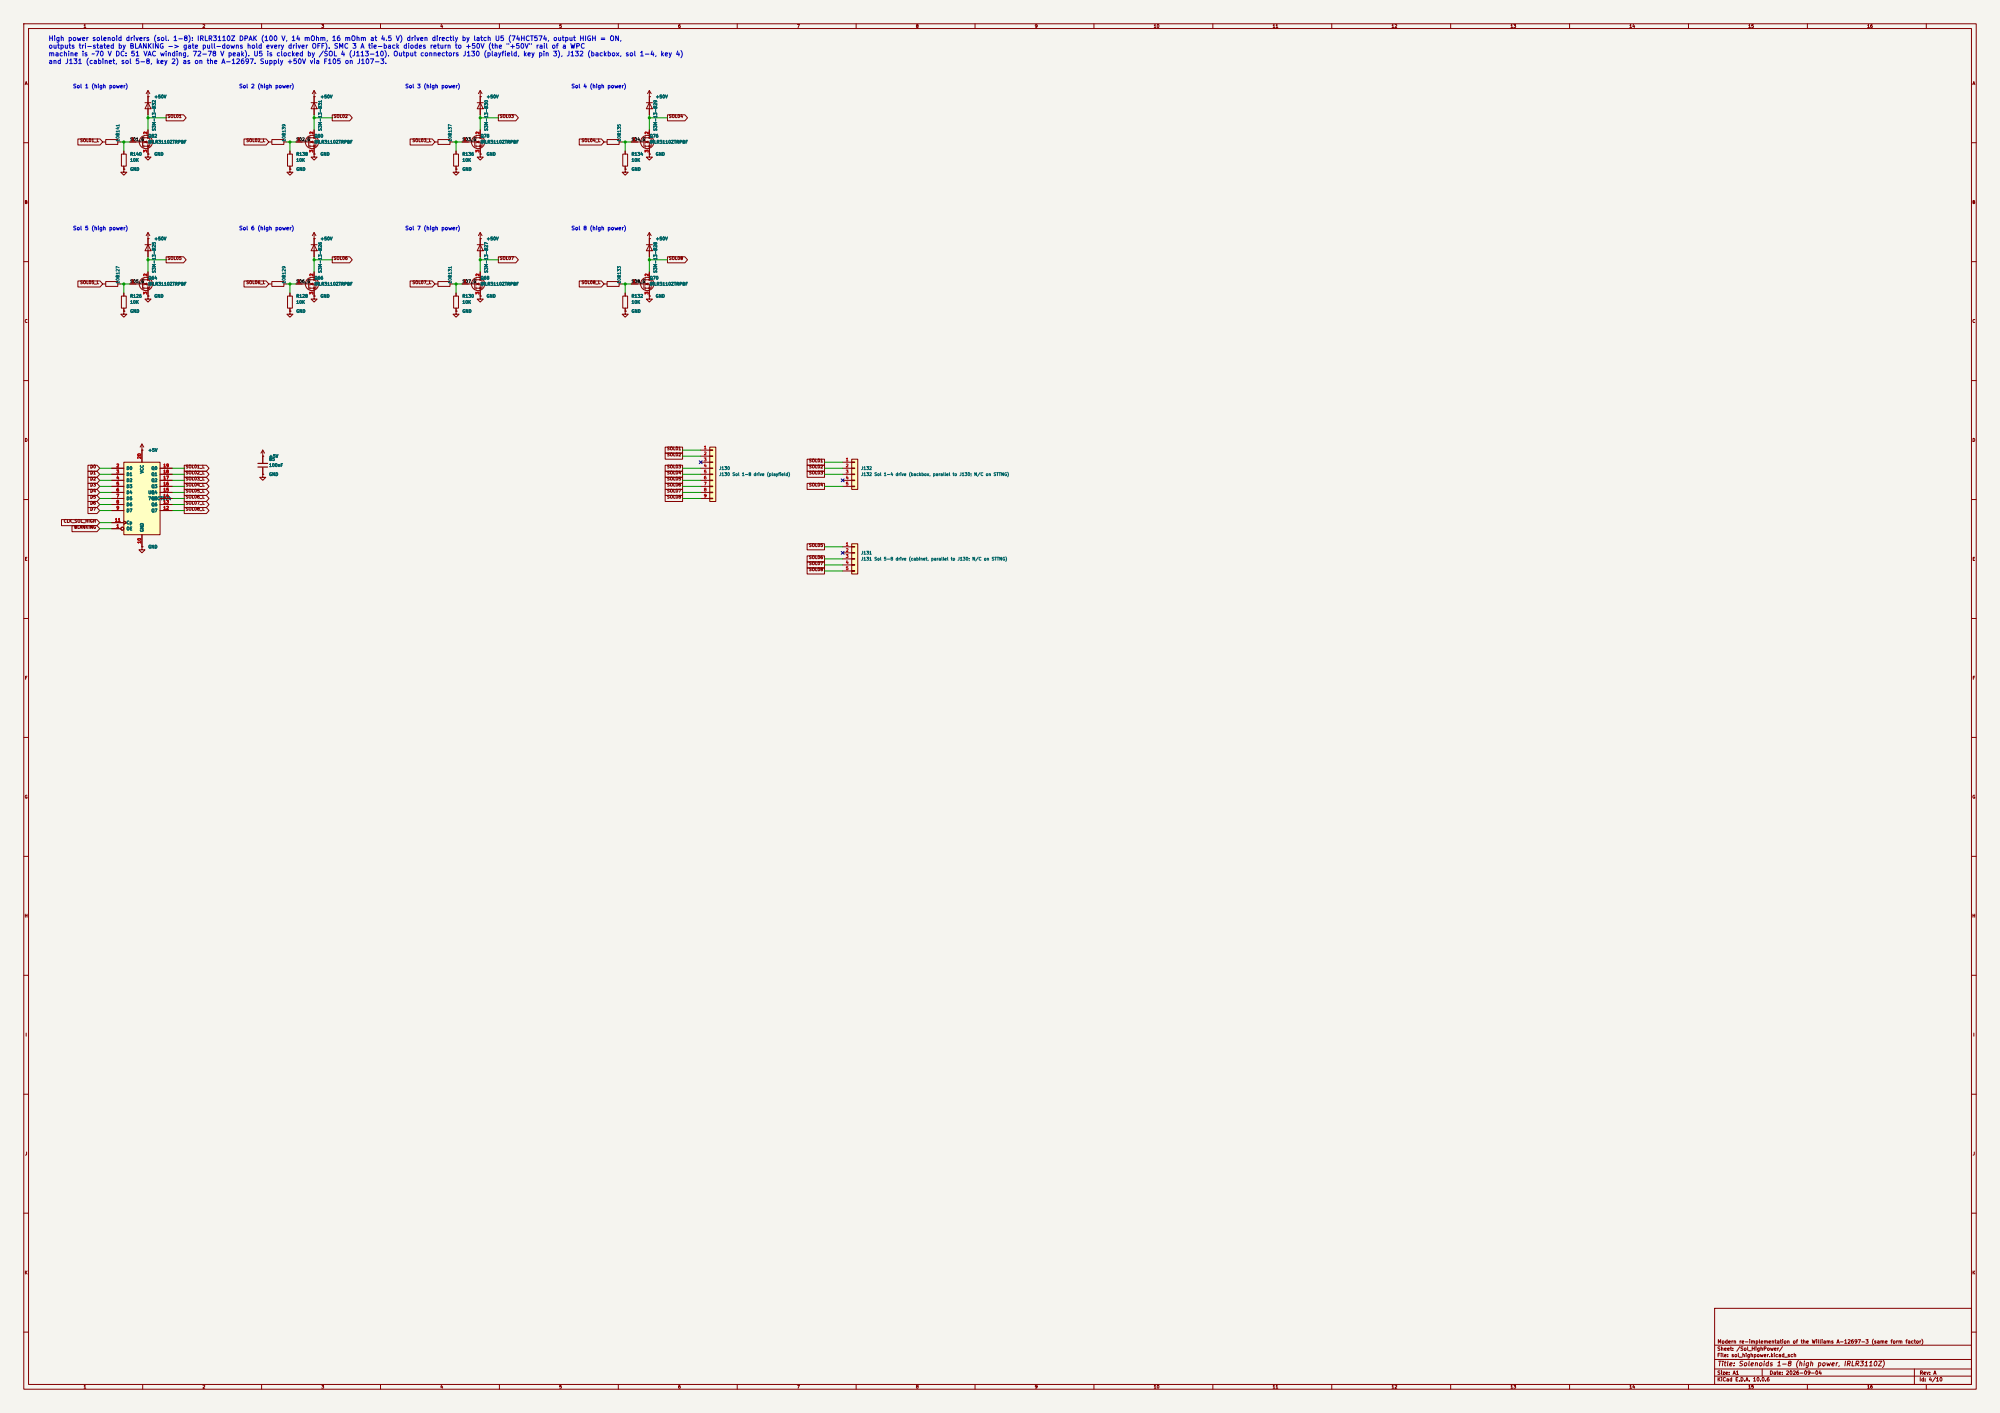
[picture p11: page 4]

High power solenoid drivers (sol. 1-8): IRLR3110Z DPAK (100 V, 14 mOhm, 16 mOhm at 4.5 V) driven directly by latch U5 (74HCT574, output HIGH = ON,
outputs tri-stated by BLANKING -> gate pull-downs hold every driver OFF). SMC 3 A tie-back diodes return to +50V (the "+50V" rail of a WPC
machine is ~70 V DC: 51 VAC winding, 72-78 V peak). U5 is clocked by /SOL 4 (J113-10). Output connectors J130 (playfield, key pin 3), J132 (backbox, sol 1-4, key 4)
and J131 (cabinet, sol 5-8, key 2) as on the A-12697. Supply +50V via F105 on J107-3. Q80

J132 Sol 1-4 drive (backbox, parallel to J130; N/C on STTNG) 1

Sheet: /Sol_HighPower/
File: sol_highpower.kicad_sch
Title: Solenoids 1-8 (high power, IRLR3110Z)

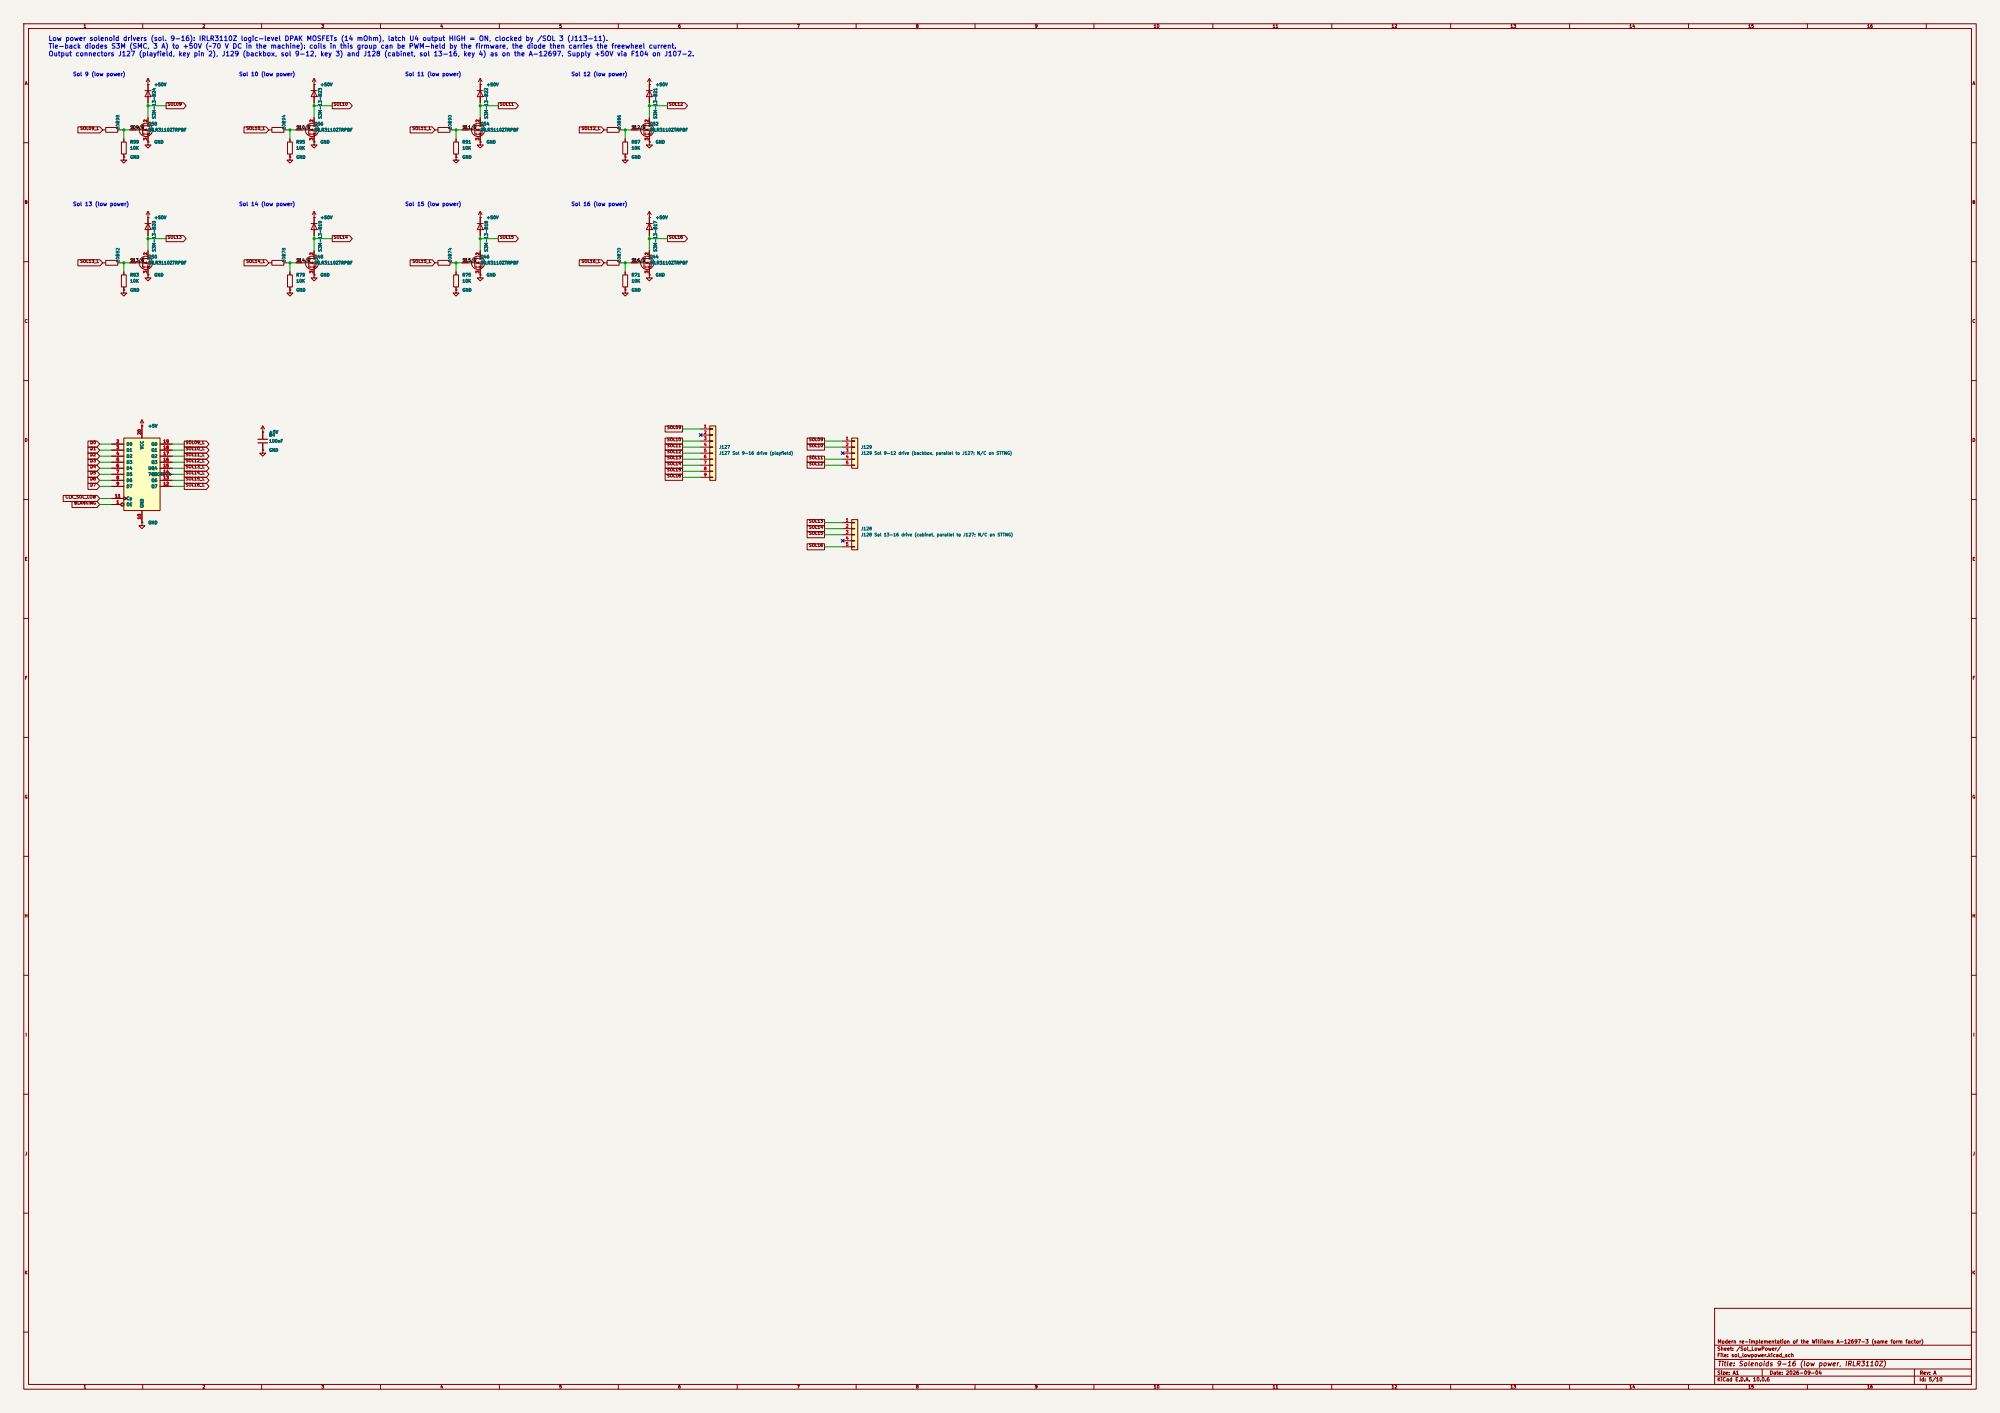
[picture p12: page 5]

Low power solenoid drivers (sol. 9-16): IRLR3110Z logic-level DPAK MOSFETs (14 mOhm), latch U4 output HIGH = ON, clocked by /SOL 3 (J113-11).
Tie-back diodes S3M (SMC, 3 A) to +50V (~70 V DC in the machine): coils in this group can be PWM-held by the firmware, the diode then carries the freewheel current.
Output connectors J127 (playfield, key pin 2), J129 (backbox, sol 9-12, key 3) and J128 (cabinet, sol 13-16, key 4) as on the A-12697. Supply +50V via F104 on J107-2. D23 S3M-13-F Q56

Modern re-implementation of the Williams A-12697-3 (same form factor) D22 S3M-13-F +50V D18 S3M-13-F GND

Sheet: /Sol_LowPower/
File: sol_lowpower.kicad_sch
Title: Solenoids 9-16 (low power, IRLR3110Z)

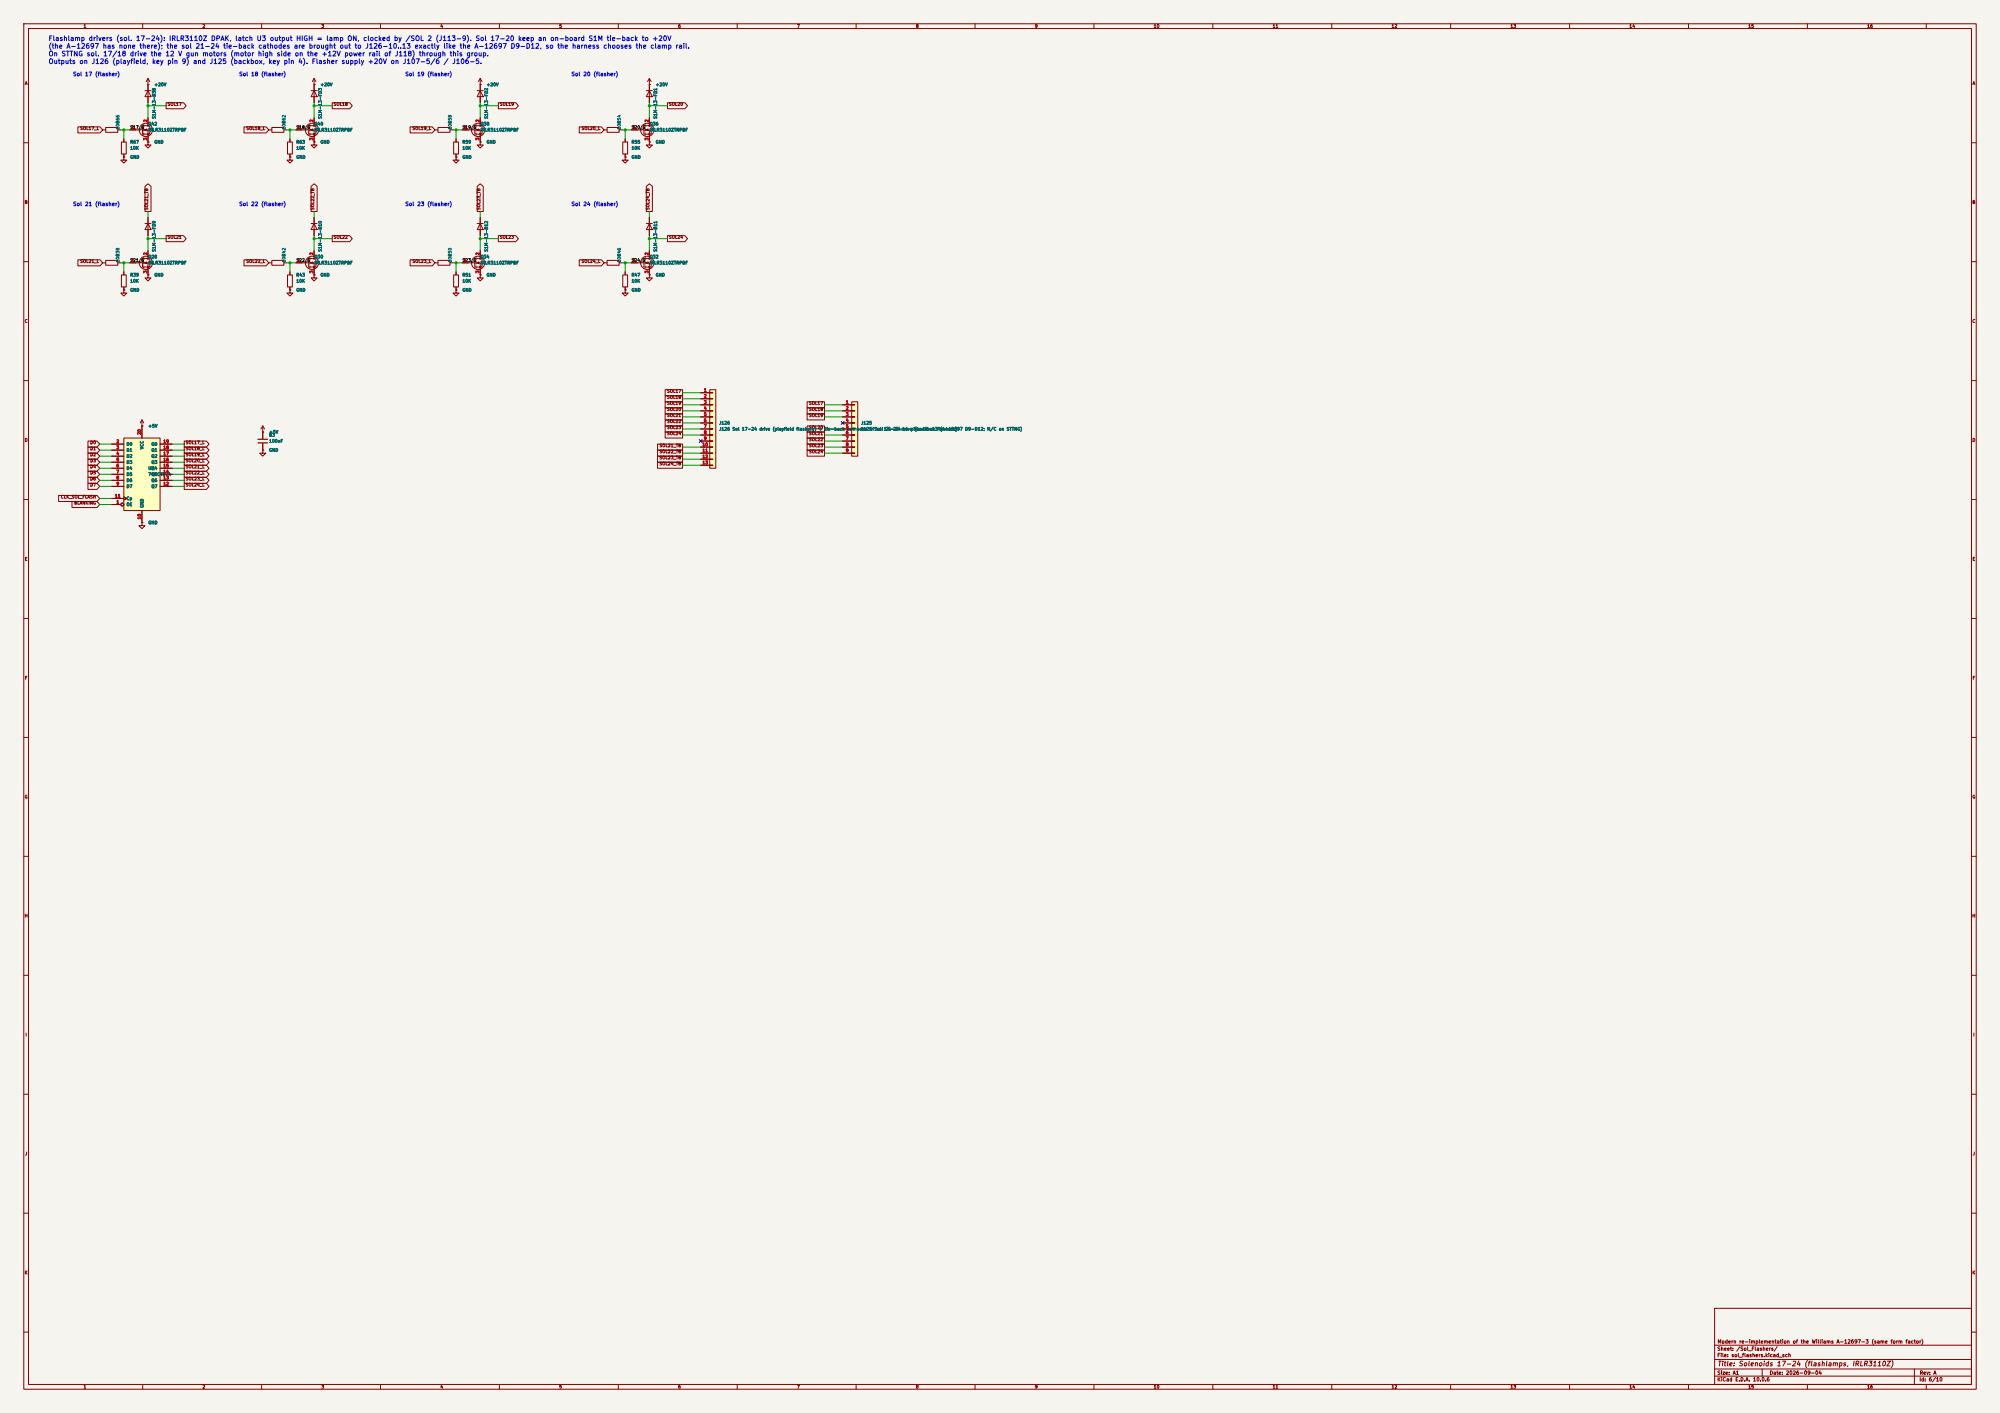
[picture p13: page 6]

Flashlamp drivers (sol. 17-24): IRLR3110Z DPAK, latch U3 output HIGH = lamp ON, clocked by /SOL 2 (J113-9). Sol 17-20 keep an on-board S1M tie-back to +20V
(the A-12697 has none there); the sol 21-24 tie-back cathodes are brought out to J126-10..13 exactly like the A-12697 D9-D12, so the harness chooses the clamp rail.
On STTNG sol. 17/18 drive the 12 V gun motors (motor high side on the +12V power rail of J118) through this group.
Outputs on J126 (playfield, key pin 9) and J125 (backbox, key pin 4). Flasher supply +20V on J107-5/6 / J106-5.

J125 Sol 17-24 drive (backbox flashers) 1

J126 Sol 17-24 drive (playfield flashers) + tie-back cathodes of sol 21-24 on pins 10-13 (A-12697 D9-D12; N/C on STTNG) GND

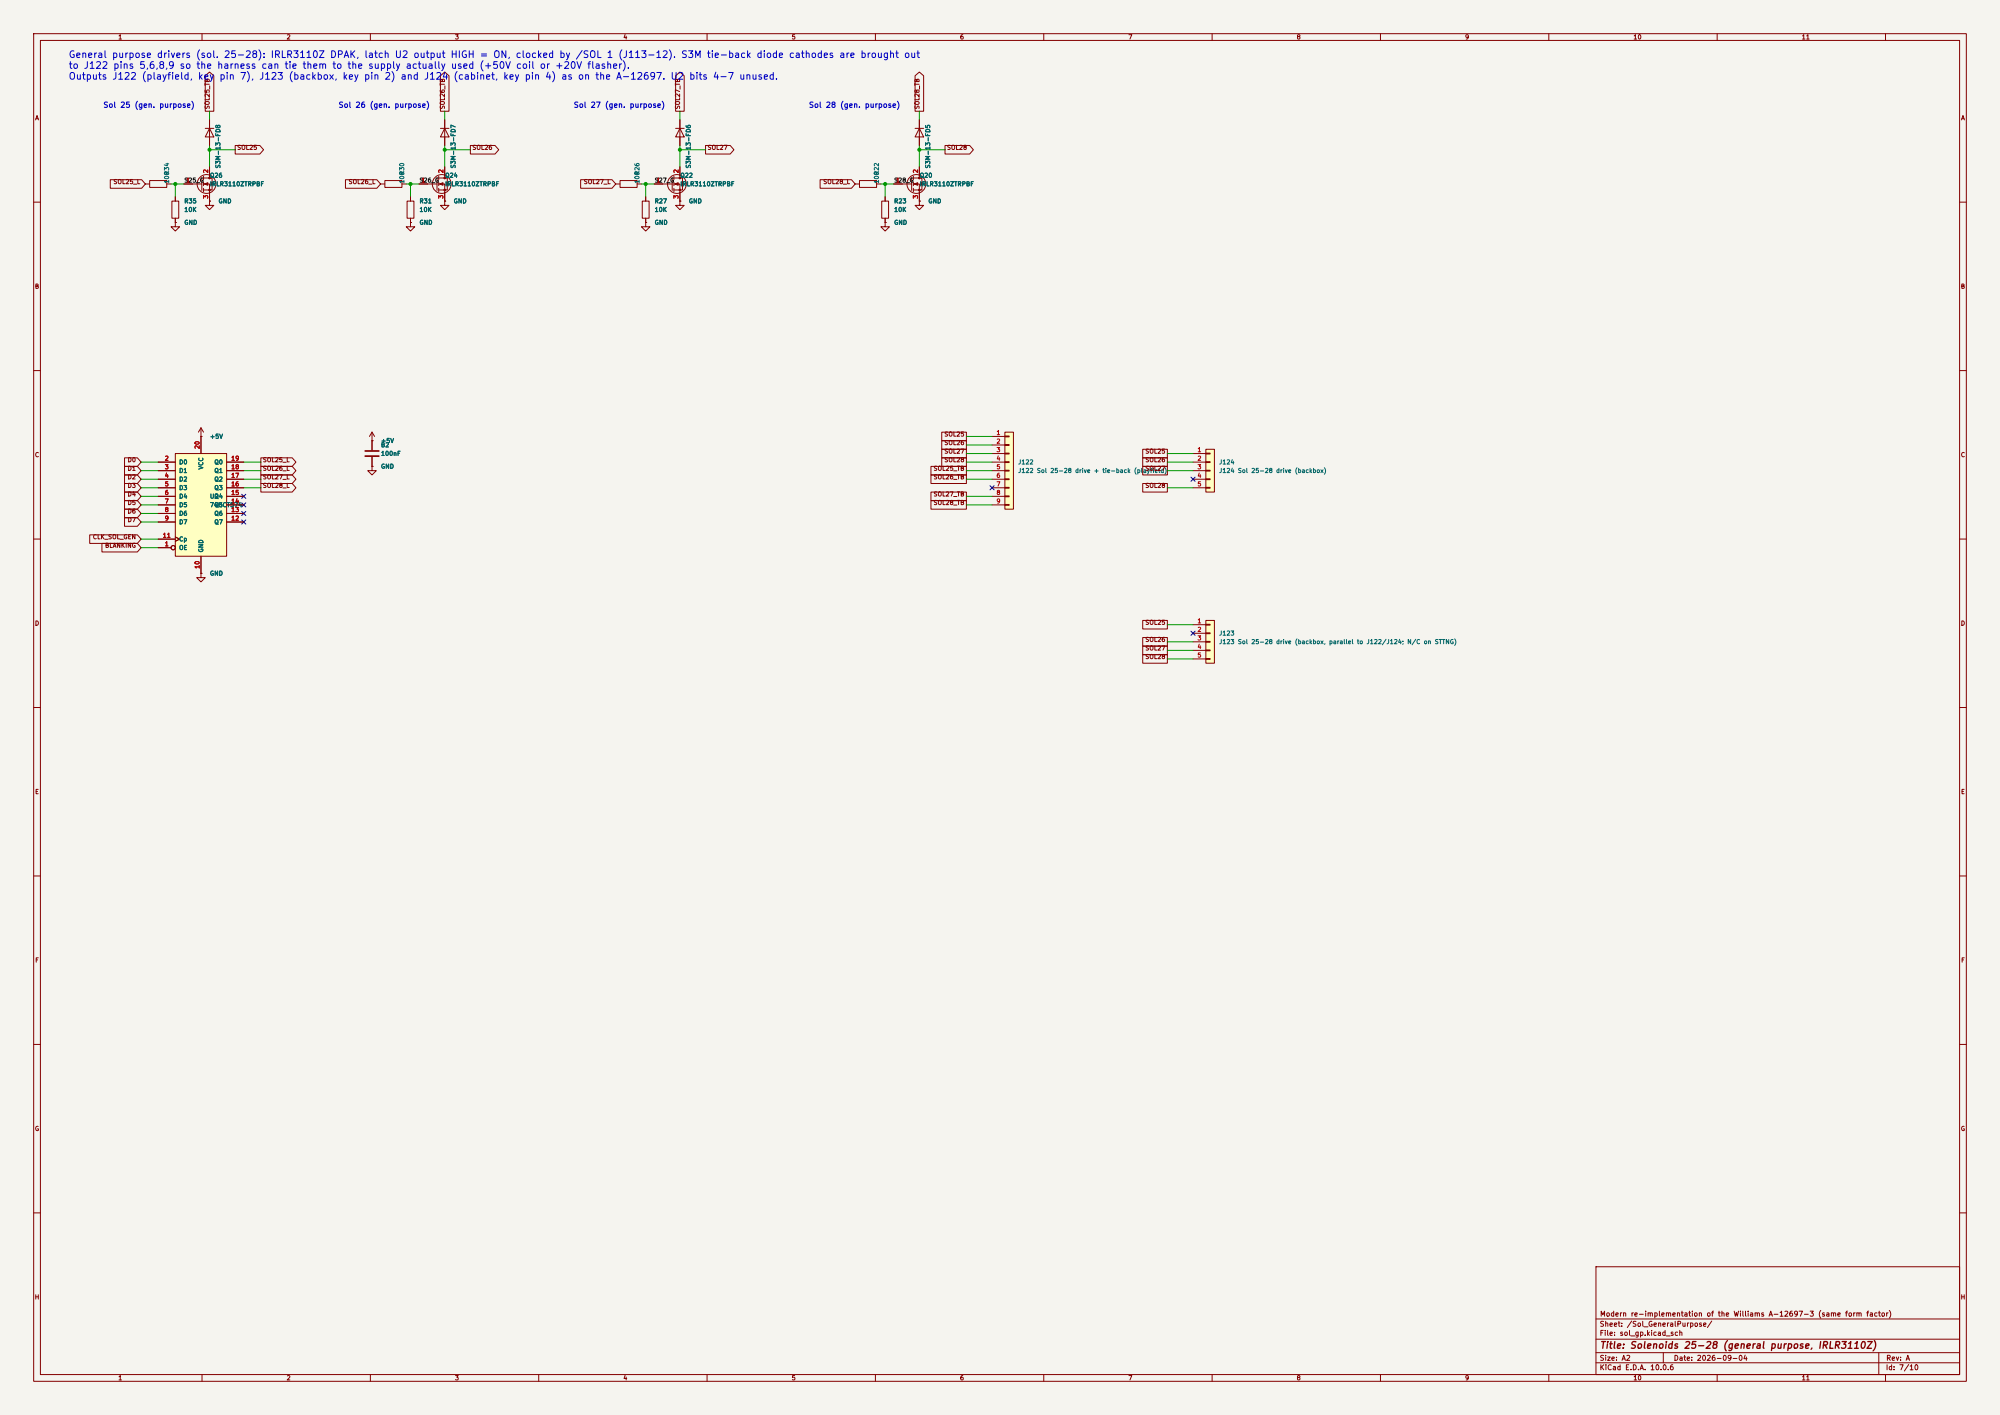
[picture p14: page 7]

General purpose drivers (sol. 25-28): IRLR3110Z DPAK, latch U2 output HIGH = ON, clocked by /SOL 1 (J113-12). S3M tie-back diode cathodes are brought out
to J122 pins 5,6,8,9 so the harness can tie them to the supply actually used (+50V coil or +20V flasher).
Outputs J122 (playfield, key pin 7), J123 (backbox, key pin 2) and J124 (cabinet, key pin 4) as on the A-12697. U2 bits 4-7 unused.

J123 Sol 25-28 drive (backbox, parallel to J122/J124; N/C on STTNG)

Sheet: /Sol_GeneralPurpose/
File: sol_gp.kicad_sch
Title: Solenoids 25-28 (general purpose, IRLR3110Z)

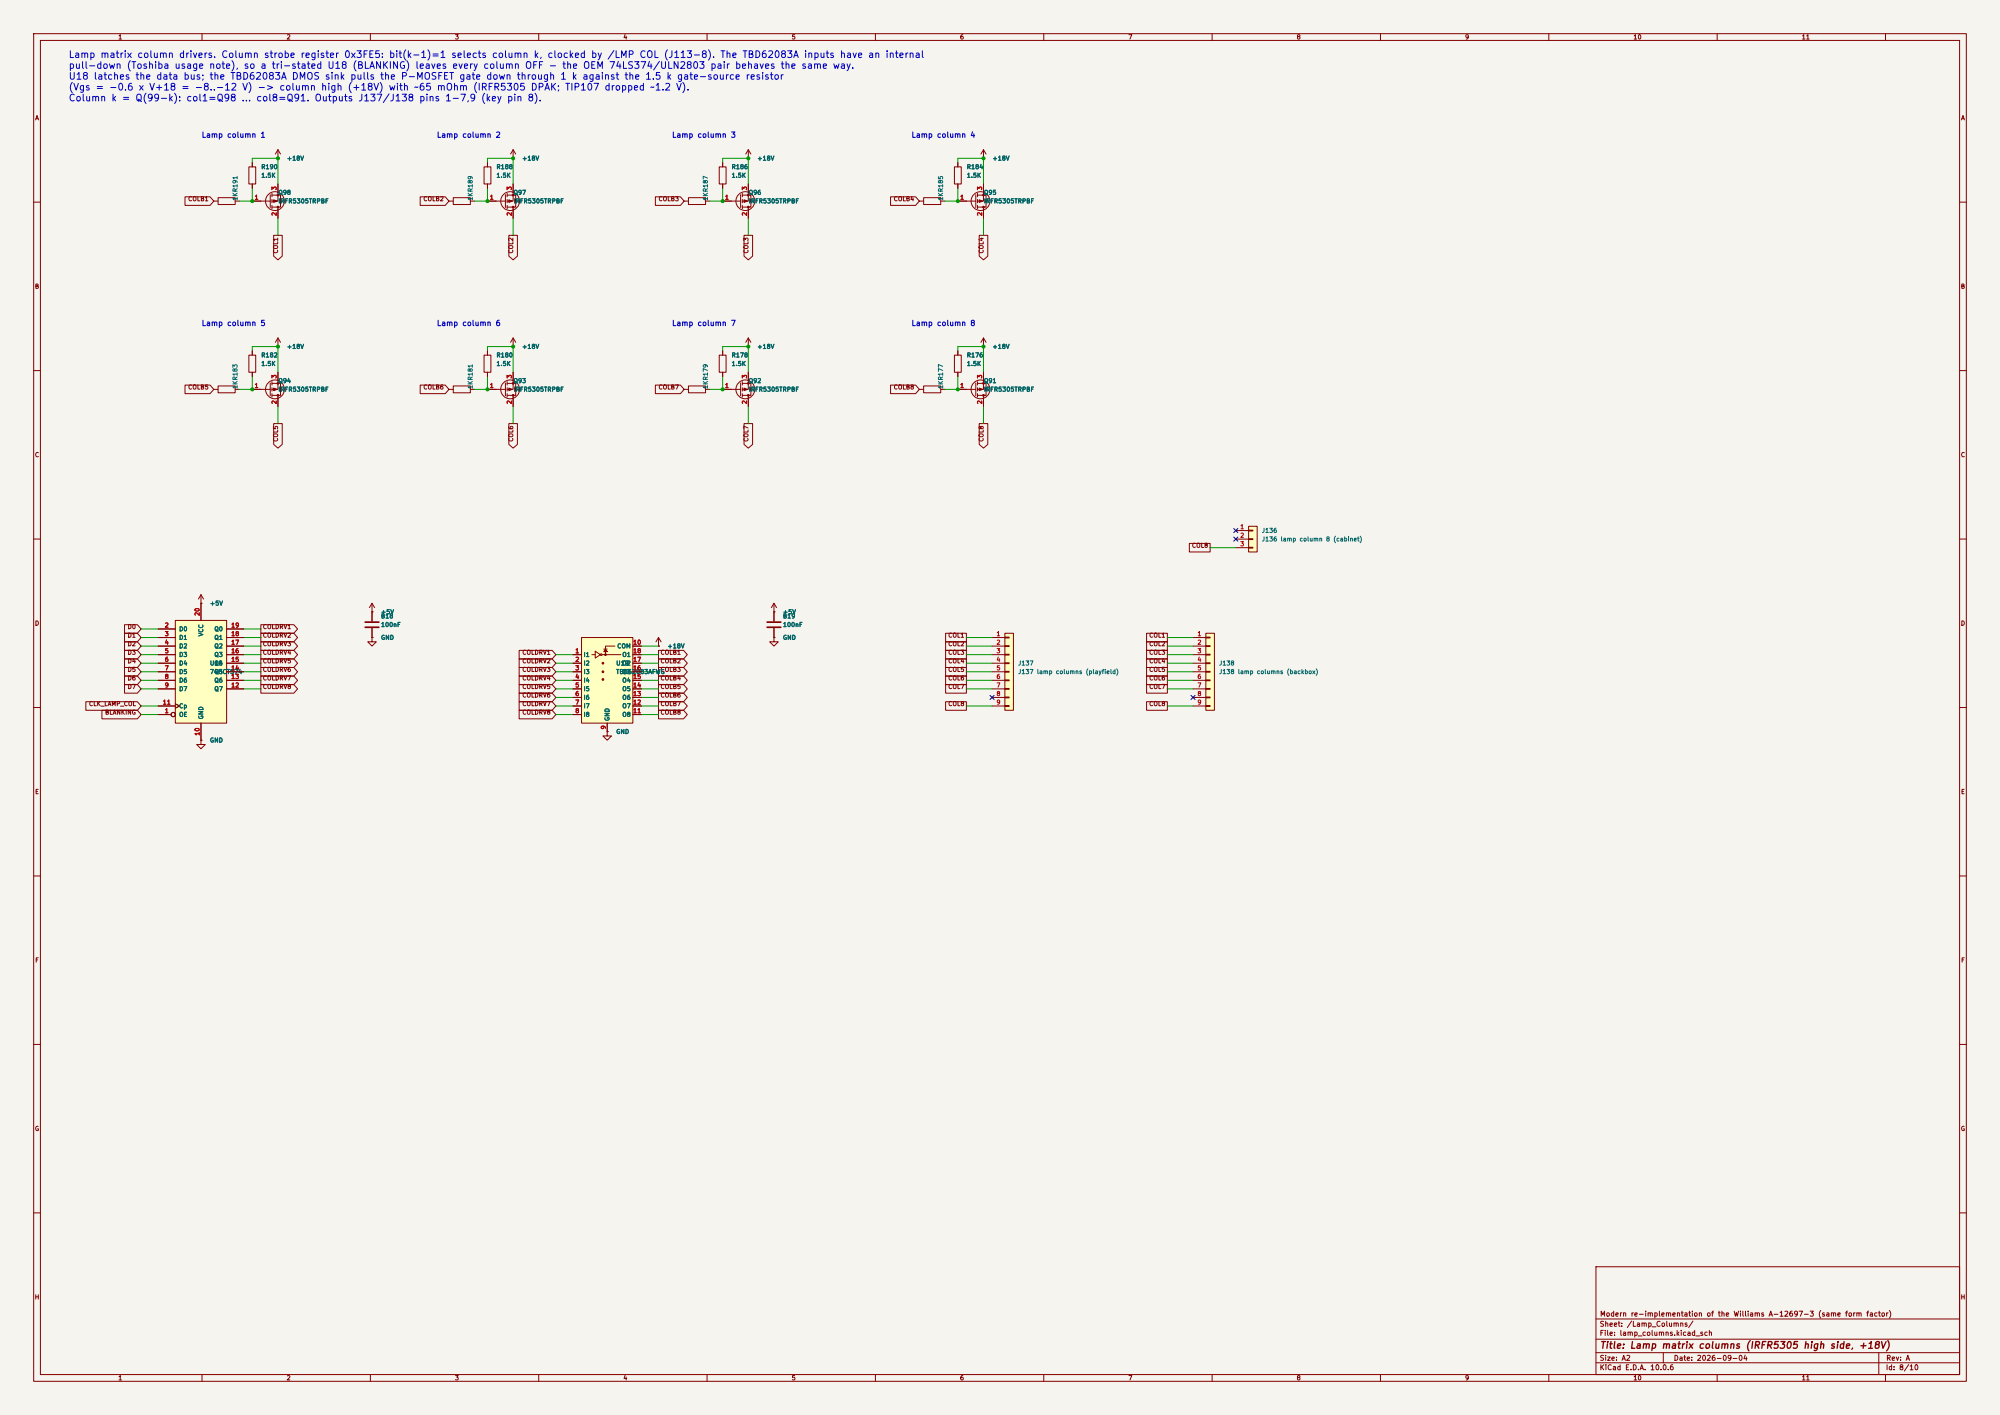
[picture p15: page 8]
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

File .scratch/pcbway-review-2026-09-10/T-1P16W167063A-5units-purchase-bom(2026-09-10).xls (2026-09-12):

PCBWay Bom Quotation, Product No.:T-1P16W167063A
Item # | *Designator | *Qty | Manufacturer | *Mfg Part # | Description / Value | Vendor Part # | *Package/Footprint | Mounting Type | *Unit Price(5 units) | *Total | *Delivery Time | *PCBWay Note | Customer Reply | PCBWay Update
1 | BR3 | 1 | Vishay | GBPC3510W-E4/51 | GBPC3510『 』Bridge rectifier 35 A 1000 V, GBPC-W (28.6 mm square block, wire leads, #10 centre hole, metal base up when PCB-mounted) | https://www.digikey.com/en/products/detail/vishay-semiconductor-diodes-division/GBPC3510W-E4-51/605926 | Diode_THT:Diode_Bridge_28.6x28.6x7.3mm_P18.0mm_P11.6mm |  | $11.599 | $57.995 |
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

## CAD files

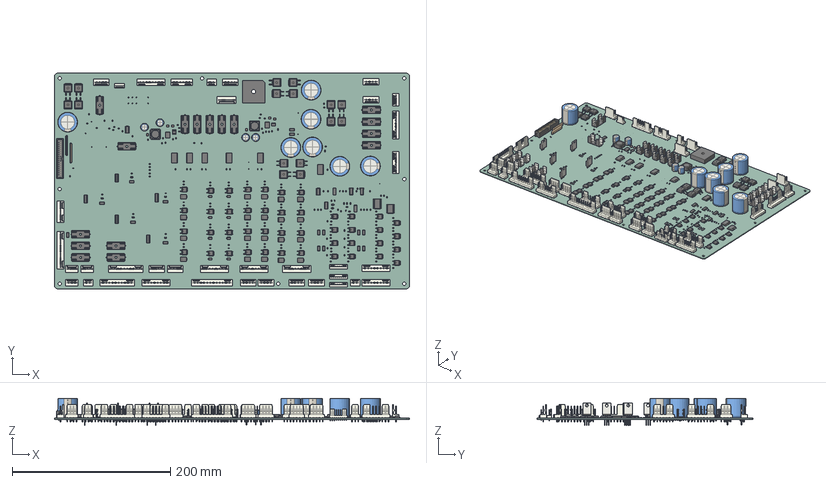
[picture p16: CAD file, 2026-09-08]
output/3d/wpc_power_driver_cost.step
449.2 x 272.9 x 34.8 mm
Molex_AE_6410_09A x 11
D_SMC x 22
R_0805_2012Metric x 142
SOT-23 x 5
Molex_AE_6410_12A
SOIC-14_3.9x8.7mm_P1.27mm x 7
A_Schurter_0031_8201 x 16
Molex_AE_6410_04A x 4
C_0805_2012Metric x 31
C_1210_3225Metric x 6
CP_Radial_D250mm_P1000mm_SnapIn x 7
R_2512_6332Metric x 16
SOIC-20W_7.5x12.8mm_P1.27mm x 7
D_SOD-123 x 2
932d09b3-9c39-11ed-93f0-dde97e994e83_part x 44
932d09b4-9c39-11ed-93f0-dde97e994e83_part x 44
932d09b5-9c39-11ed-93f0-dde97e994e83_part x 44
Molex_AE_6410_03A x 3
a3dd6ad7-9c39-11ed-93f0-dde97e994e83_part x 16
a3dd6ad8-9c39-11ed-93f0-dde97e994e83_part x 16
a3dd6ad9-9c39-11ed-93f0-dde97e994e83_part x 16
LED_0805_2012Metric x 7
TO-220-3_Vertical x 5
SRR1260 x 2
D_SMA x 8
CP_Radial_D100mm_P500mm x 4
Molex_AE_6410_07A x 3
Molex_AE_6410_05A x 11
Molex_AE_6410_11A x 2
R_Array_SIP10 x 2
Molex_AE_6410_06A
IDC_Header_2x17_P254mm_Vertical
SOIC-18W_7.5x11.6mm_P1.27mm
HSOP-8-1EP_3.9x4.9mm_P1.27mm_EP2.41x3.1mm x 2
Diode_Bridge_28.6x28.6x7.3mm_P18.0mm_P11.6mm
Molex_AE_6410_13A
wpc_power_driver_cost_PCB

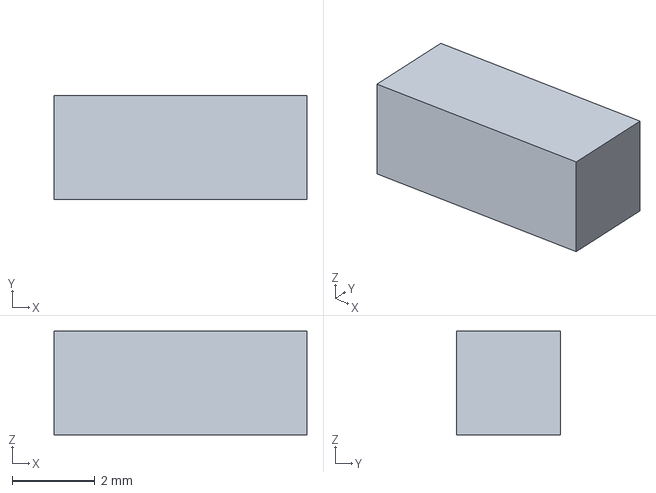
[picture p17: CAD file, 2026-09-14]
variants/jlcpcb-100/models/inventory/TLC_TA7.step
6.10 x 2.50 x 2.50 mm

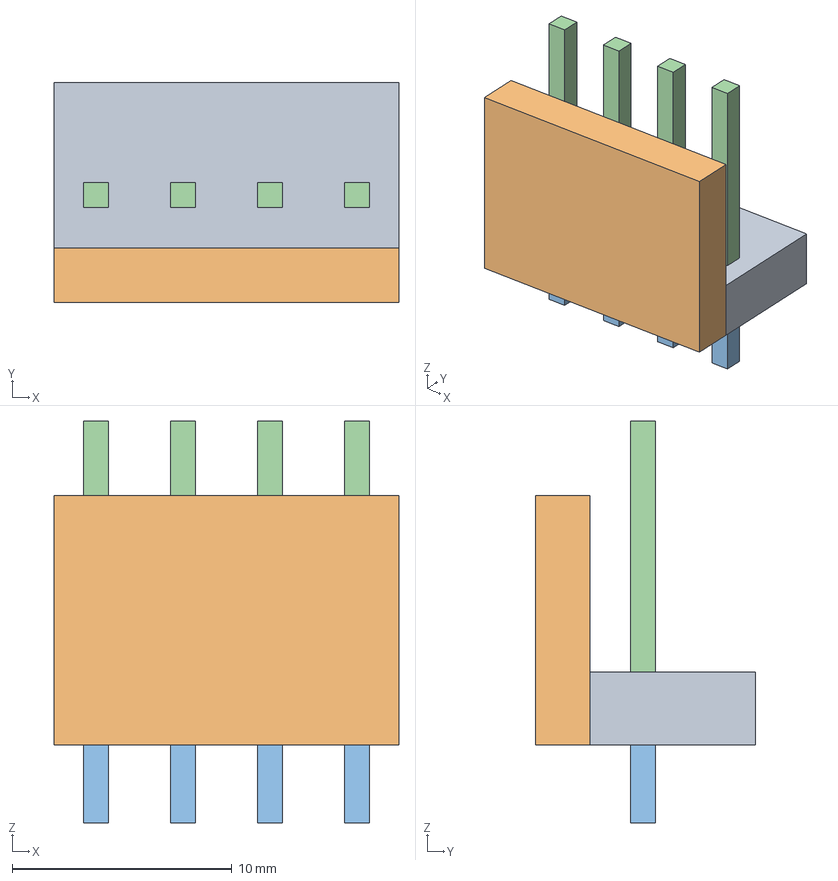
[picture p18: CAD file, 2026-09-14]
variants/jlcpcb-100/models/Molex_KK396_04_envelope.step
15.7 x 10.0 x 18.3 mm

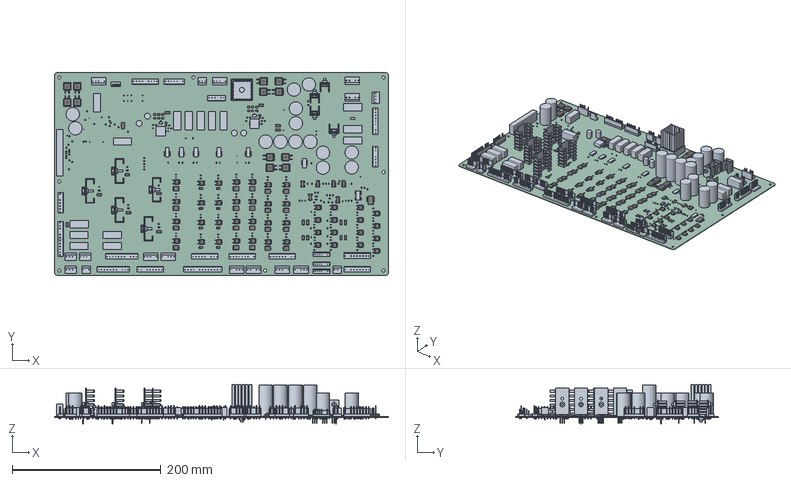
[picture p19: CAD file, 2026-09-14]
variants/jlcpcb-100/output/release-candidate/3d/board.step
449.2 x 272.9 x 52.9 mm
D_SMC x 20
R_0805_2012Metric x 158
SOT-23 x 5
C_0805_2012Metric x 29
C_1210_3225Metric x 14
SOIC-14_3.9x8.7mm_P1.27mm x 7
R_2512_6332Metric x 18
D_SOD-123 x 2
932d09b3-9c39-11ed-93f0-dde97e994e83_part x 44
932d09b4-9c39-11ed-93f0-dde97e994e83_part x 44
932d09b5-9c39-11ed-93f0-dde97e994e83_part x 44
TO-220-3_Vertical x 9
C_0402_1005Metric x 8
a3dd6ad7-9c39-11ed-93f0-dde97e994e83_part x 12
a3dd6ad8-9c39-11ed-93f0-dde97e994e83_part x 12
a3dd6ad9-9c39-11ed-93f0-dde97e994e83_part x 12
LED_0805_2012Metric x 7
D_SMA x 8
SOIC-18W_7.5x11.6mm_P1.27mm
wpc_power_driver_cost_PCB

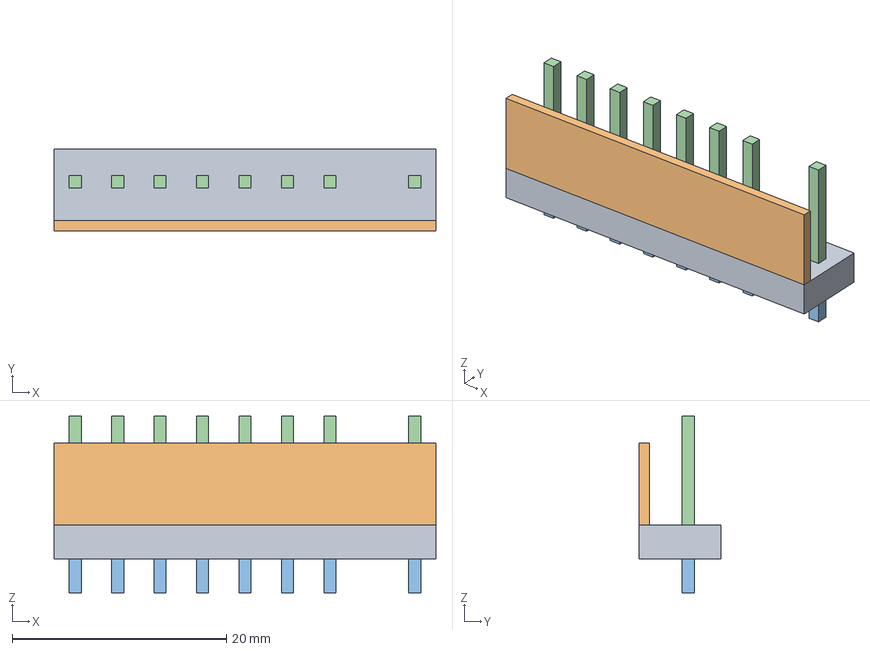
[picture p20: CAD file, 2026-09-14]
variants/jlcpcb-100/output/release-candidate/cad/models/inventory/TE_J138.step
35.6 x 7.62 x 16.5 mm

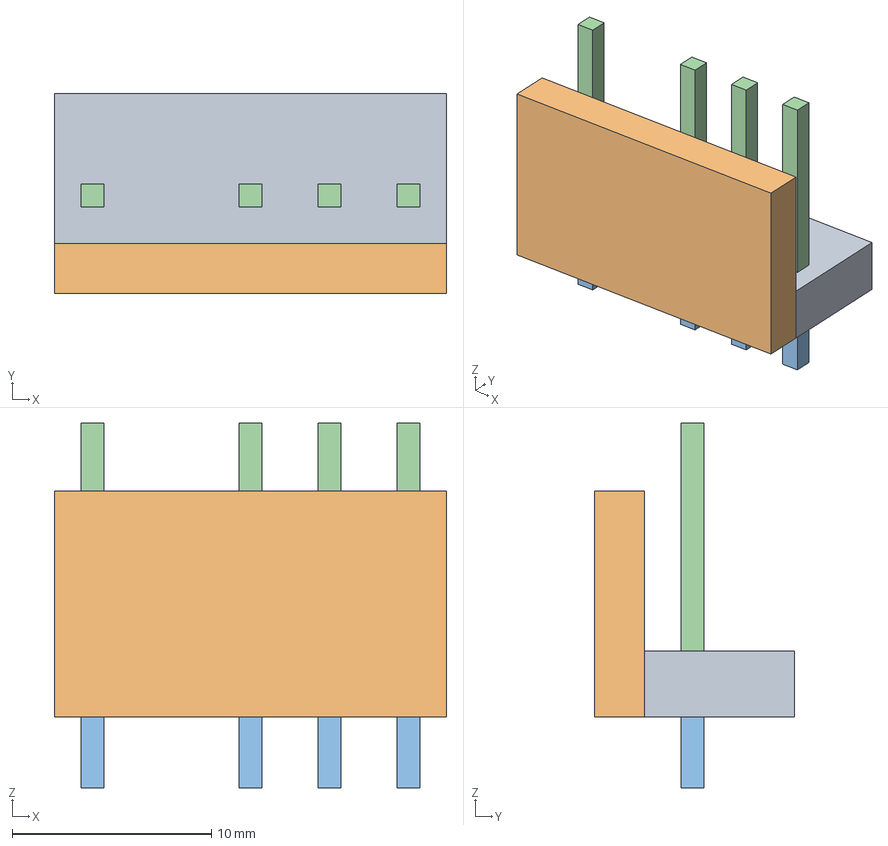
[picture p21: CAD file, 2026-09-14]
variants/jlcpcb-100/output/release-candidate/cad/models/Molex_KK396_05_envelope_key02.step
19.7 x 10.0 x 18.3 mm

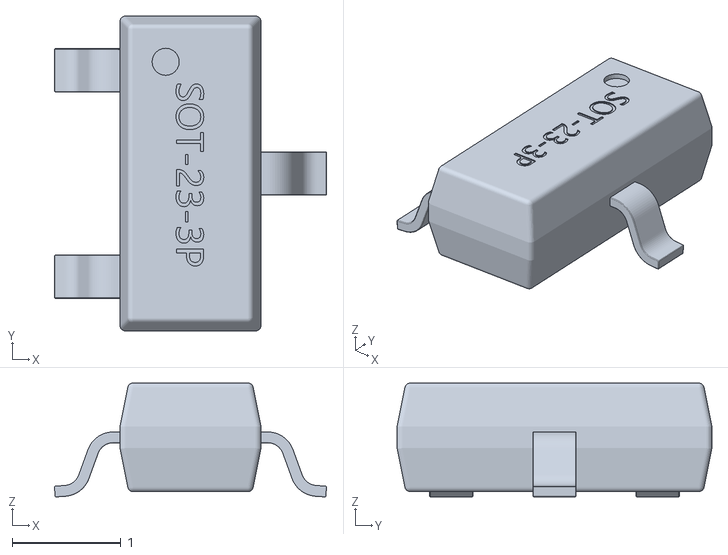
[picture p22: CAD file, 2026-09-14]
variants/jlcpcb-100/research/jlc-placement-libraries/C8512-supplier.obj
2.51 x 2.90 x 1.05

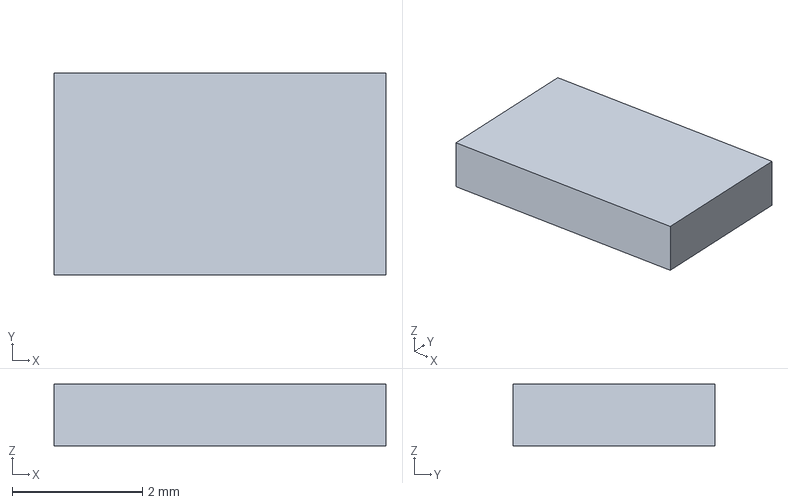
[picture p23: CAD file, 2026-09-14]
variants/jlcpcb/models/TI_RYQ0021B_envelope.step
5.10 x 3.10 x 0.95 mm

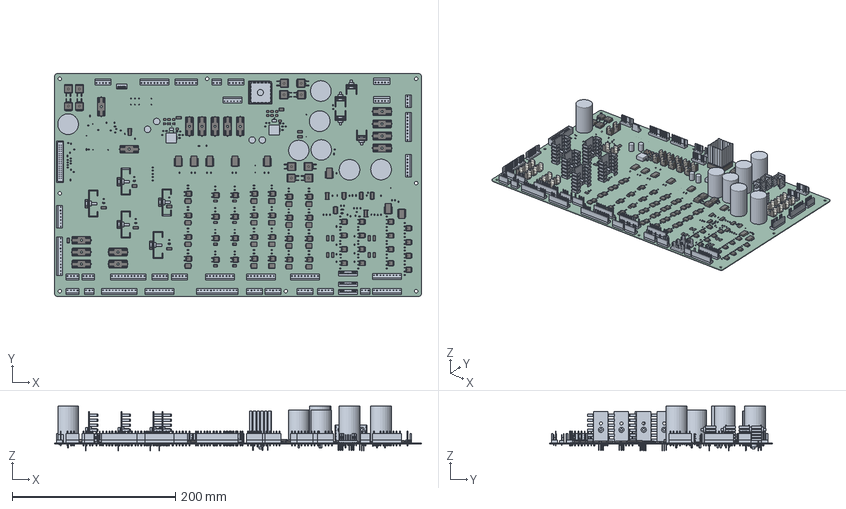
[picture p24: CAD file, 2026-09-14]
variants/jlcpcb/output/release-candidate/3d/board.step
449.2 x 272.9 x 54.8 mm
D_SMC x 20
R_0805_2012Metric x 158
SOT-23 x 5
C_0805_2012Metric x 29
C_1210_3225Metric x 14
SOIC-14_3.9x8.7mm_P1.27mm x 7
A_Schurter_0031_8201 x 16
R_2512_6332Metric x 18
SOIC-20W_7.5x12.8mm_P1.27mm x 7
D_SOD-123 x 2
932d09b3-9c39-11ed-93f0-dde97e994e83_part x 44
932d09b4-9c39-11ed-93f0-dde97e994e83_part x 44
932d09b5-9c39-11ed-93f0-dde97e994e83_part x 44
TO-220-3_Vertical x 9
C_0402_1005Metric x 8
a3dd6ad7-9c39-11ed-93f0-dde97e994e83_part x 12
a3dd6ad8-9c39-11ed-93f0-dde97e994e83_part x 12
a3dd6ad9-9c39-11ed-93f0-dde97e994e83_part x 12
LED_0805_2012Metric x 7
D_SMA x 8
SOIC-18W_7.5x11.6mm_P1.27mm
Diode_Bridge_28.6x28.6x7.3mm_P18.0mm_P11.6mm
wpc_power_driver_cost_PCB

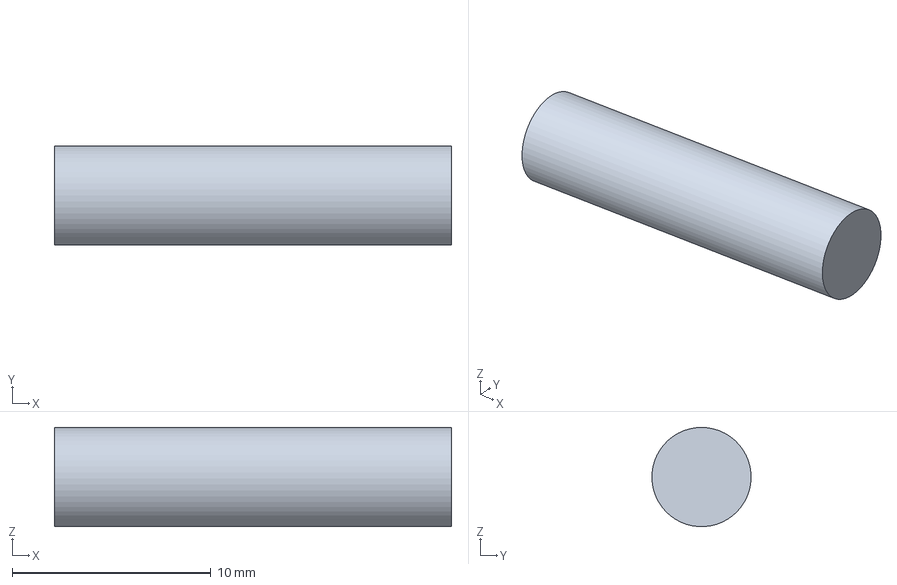
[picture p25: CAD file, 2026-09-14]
variants/jlcpcb-100/models/inventory/Fuse_5x20_cartridge.step
20.0 x 5.00 x 5.00 mm

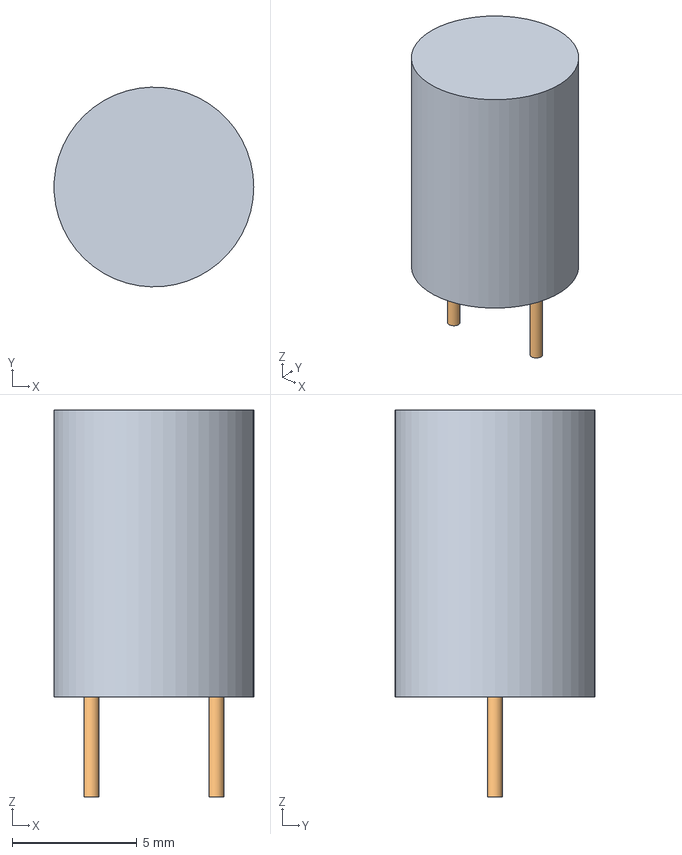
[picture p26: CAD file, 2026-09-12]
variants/jlcpcb/output/release-candidate/cad/models/Panasonic_EEUFR1E331B_envelope.step
7.99 x 8.00 x 15.5 mm

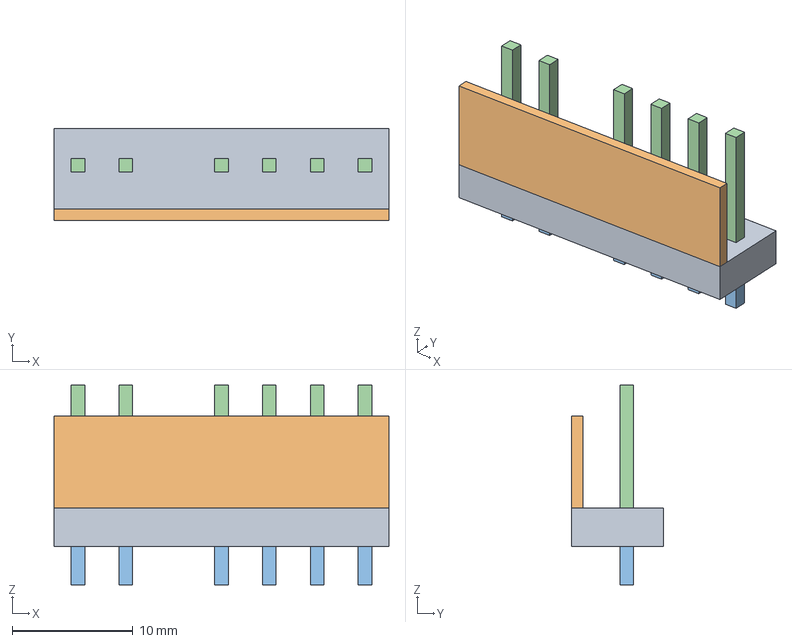
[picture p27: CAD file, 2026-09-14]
variants/jlcpcb-100/models/inventory/TE_J101.step
27.7 x 7.62 x 16.5 mm

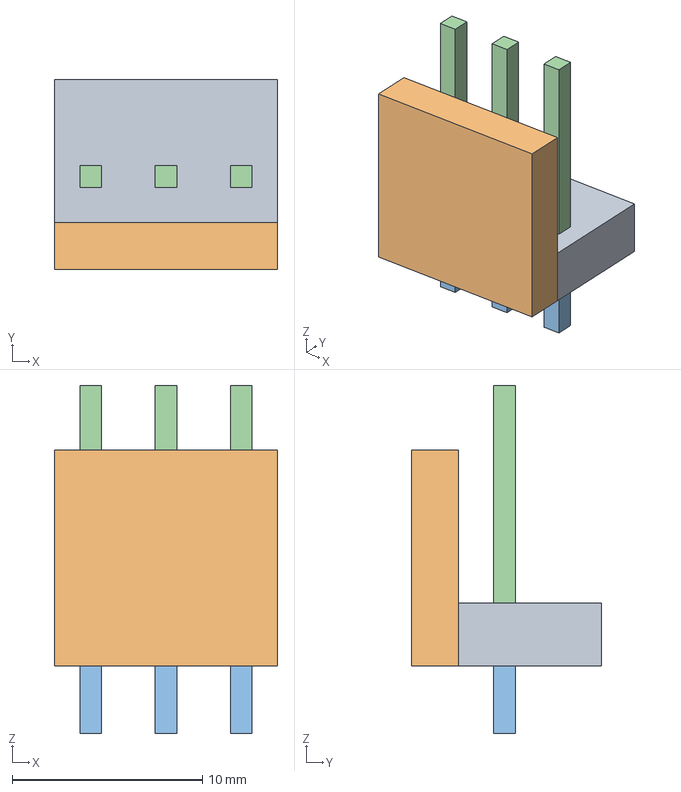
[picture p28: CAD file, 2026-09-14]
variants/jlcpcb-100/models/Molex_KK396_03_envelope.step
11.7 x 10.0 x 18.3 mm

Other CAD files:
variants/jlcpcb-100/models/Molex_KK396_05_envelope_key03.step
variants/jlcpcb-100/output/release-candidate/cad/models/inventory/TE_J137.step
output/release-candidate/3d/board.step
variants/jlcpcb-100/models/3M_N2534_6002_RB_envelope.step
variants/jlcpcb-100/models/Bourns_SRP1265A_envelope.step
variants/jlcpcb-100/models/Boyd_5771_simplified.step
variants/jlcpcb-100/models/Boyd_5772_simplified.step
variants/jlcpcb-100/models/Boyd_6223_simplified.step
variants/jlcpcb-100/models/Boyd_6224_simplified.step
variants/jlcpcb-100/models/Boyd_7019_simplified.step
variants/jlcpcb-100/models/Boyd_7020_simplified.step
variants/jlcpcb-100/models/M3x12_TO220_hardware_envelope.step
variants/jlcpcb-100/models/M3x8_TO220_hardware_envelope.step
variants/jlcpcb-100/models/M4x16_BR3_hardware_envelope.step
variants/jlcpcb-100/models/Molex_KK-254_AE-6410-05A_1x05_P2.54mm_Vertical_key04.step
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

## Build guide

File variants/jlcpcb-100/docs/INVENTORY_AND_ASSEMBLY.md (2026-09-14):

# JLC-100 component and assembly decisions

This is a separate variant of JLC-3. The original variant is preserved. Public JLCPCB catalog snapshots were fetched on 2026-09-14 UTC (2026-09-13 in Los Angeles). Stock is not reserved. A 100-board build requires the per-board quantity times 100, plus 5% spares with a minimum of ten extra units per catalog code. The inventory test uses the smaller of warehouse stock and orderable stock. Pre-order MOQ is recorded separately: this design uses public stock for assembly, not an out-of-stock pre-order. JLCPCB explains that distinction in its [pre-order service documentation](https://jlcpcb.com/help/article/what-is-jlcpcb-parts-pre-order-service).

The complete `bom/all-components.csv` contains every purchased electronic component and the additional hardware. It also identifies unpopulated components and fabricated test/mounting features. `jlc-electronics-purchase.csv` aggregates shared codes across the whole board before applying the 100-board reserve. All through-hole electronic parts have JLCPCB catalog codes. Heatsinks, fasteners and thermal paste are separately identified external procurement items; their inventory is not covered by the JLCPCB stock check. The assembly models include these mechanical assemblies on their parent footprints.

**Use `jlcpcb-assembly/BOM.csv` and `jlcpcb-assembly/CPL.csv` for complete SMT and through-hole electronics assembly.** Both describe the same 440 individual purchased units. Follow [JLCPCB_UPLOAD.md](JLCPCB_UPLOAD.md) and include `PCBA-remark.txt` for fuse insertion, prepared headers and mechanical completion. `bom/all-components.csv` is the complete human-readable assembly/procurement record; the separate `jlc-smt-bom.csv` and `jlc-smt-cpl.csv` files cover SMT only. The old `all-electronics-positions.csv` filename now contains the valid combined CPL; the richer engineering table is `electronics-placement-details.csv`. Catalog availability does not guarantee acceptance for a particular JLCPCB assembly process: arrange THT/manual assembly and the connector preparations below in the assembly quotation. No orders or messages have been sent.

| Circuit | Selected substitution | Reason and consequence |
|---|---|---|
| U20/U21 | TPS552872QWRYQRQ1, C22397842 | Same RYQ21 pins; model uses guaranteed minimum 3.3 A average inductor limit. Output targets remain 5.1 V/3 A and 12 V/0.75 A. R266 becomes Basic 33 kΩ. |
| 28 solenoid/flasher/general power switches | AOD66923, C485687 | 100 V, 4.5 V specified logic drive, same DPAK pinout. Hot resistance and replayed load transients checked. |
| U1–U5/U18, U9 | SN74HCT574NSR C2878759, SN74HCT240NSR C6772 | Preserve HCT thresholds and functions; new 5.3 mm SO-20 body requires the changed routing. |
| Q9/Q11/Q13/Q15/Q17 | Basic MMBT2222A1P C8512 | Same B-E-C SOT-23 footprint; trigger-current low-drive corner checked. |
| Q10/Q12/Q14/Q16/Q18 | BTA08-600CRG C9102 | 8 A, four-quadrant triac with 50 mA worst-quadrant IGT. Rated current is lower than the old 16 A device; use the modeled 5 A GI-string envelope and original fuse values. Retain all five Boyd 7020BG sinks. |
| D101–D104 | MOT MBR40100A C5143116 | Dual 20 A legs in parallel, A-K-A physical leads. Retain separate electrically live Boyd 577202B00000G sinks and direct tab interfaces. |
| D105–D116 | onsemi MBRB20H100CTT4G C235758 | Dual10A,100V,175°C;250A surge per leg. Maximum6mA leakage/leg at125°C. Outer anodes parallel on A, tab/center cathode on K; same5.08mm outer lead spacing. Final thermal and startup fixtures use this part. |
| BR3 | onsemi GBPC2506W C906984 | Wire-lead version; new diagonal DC terminal pattern and thicker case. Follow the dedicated footprint and instructions below. |
| Five low-voltage reservoirs | Ten EGPD350ELL472MM30H C443892 | Each old 10,000 µF capacitor becomes two individually annotated 4,700 µF capacitors. Four on +18 V, two on +5V_RAW, two on +20 V, two on +12VU. |
| High-voltage reservoir | Four NHA100V1000M18*40 LO C3445915 | C8/C32/C64/C65 total 4,000 µF, replacing 4,400 µF. Each rated 2.02 A at 120 Hz. Unequal sharing and mains-frequency ripple checked. |
| C2/C4/C9/C12 | Rubycon 25ZLH330MEFC8X11.5 C109394 | Retain 330 µF/25 V; use the actual 3.5 mm lead spacing. |
| Small capacitors and shunts | C307331, C138687, C875839 | Basic 0402 100 nF/50 V X7R; 1210 10 µF/50 V X7R; eight 0.22 Ω 2512 1 W shunts. |

The Basic library was searched for suitable alternatives. The design retains higher voltage ratings, X7R input capacitors, appropriate power packages and HCT logic thresholds where a Basic substitute was unsuitable.

## Fuse assemblies

There are **15 HONGJU FH1-200CK-G holders, C268204**, each including its cover. F101 and F102 are empty holders as in the original variant; do not insert unspecified fuses. The other thirteen holders have separately listed cartridges. Holder metadata is present in both schematic and PCB fields, so the complete BOM is generated from the design rather than a handwritten count. Holder lead pitch is 22.6 mm, finished holes 1.7 mm. Former clip holes retained as plated vias are copper features, not additional purchased clips.

F106–F110, F111 and F113 use REOMAX 5.250.1500A, C5381754, 5 A time-lag ceramic 5×20 mm. F115 uses REOMAX 5.250.0750A, C5381743, 0.75 A time-lag. F103/F104/F105/F116 retain their specified 3 A time-lag cartridges; F114 retains its specified 8 A fast cartridge. Never increase a fuse rating to satisfy a simulated continuous overload.

**F112 changes service method:** it is a soldered TLC TA7, C3014110, 7 A time-lag 2410 fuse with 125 VAC/200 A interruption rating. It has no holder and requires desoldering for replacement. Manufacturer recommended lands are 2.5×3.0 mm, centers 5.5 mm apart. F112 feeds the coil AC supply and external Fliptronic AC branch at J104. The inrush simulation explicitly includes an assumed external reservoir; the 139.419 A²s figure is typical pre-arcing data, not guaranteed repetitive endurance or fault coordination. Qualify cold/hot starts and actual external loads before a production run.

## Prepared connectors

Maintain every original connector number, electrical pin number, friction-wall direction, pin-1 marking and removed key post. The CAD models omit keyed posts; PCB holes remain in place. Use `connector-keys.csv` with the assembly drawings. A cut-to-length or composite header is a prepared assembly, not an unmodified drop-in MPN.

- J107: one TE 640445-6 C86500. J101/J109/J114: 640445-7 C305801. Eight 9-position headers use 640445-9 C305802. J126 uses 1-640445-3 C592598.
- J120/J121: trim 13-position 1-640445-3 to 11 positions by removing positions 12–13 at the far end. Deburr and retain pin 1 and the friction wall. Purchase one 13-position header for each connector.
- **J115 purchases two 640445-6 headers.** J115A covers electrical pins 1–6; J115B covers 7–12. Align both walls and post rows; lightly dress the mating body ends if required. The complete BOM counts two pieces. Key position 9 means removing post 3 of J115B. Prove the combined header fits the actual 12-position housing without interference before preparing the batch.
- J133/J134/J135: trim TE 1-640456-0 C94118 from 10 to 9 positions, removing only position 10. Preserve the existing keyed post position and 2.54 mm pitch.
- J113: XFCN EH254V-12-34P C5200275, 34 positions, 2.54 mm pitch, with ejector latches. Match the notch and pin 1 to the assembly drawing. Closed body is 62.38 mm long and 16.9 mm high; allow 27.5 mm open-latch height and cable/tool access. This is longer than the old 3M body.

TE MTA-156 posts are 1.14 mm square and use 1.8 mm finished PCB holes. A nominal 3.96 mm CAD pitch approximates 0.156 inch (3.9624 mm); the small accumulated difference is within the supplied lead-hole clearance. Confirm connector mating, retention and gauge compatibility on a first article.

## BR3 and mechanical hardware

BR3 uses the **GBPC2506W wire-lead version**, not the Faston-lug version. The new footprint places DC positive at pad 1 and DC negative at diagonally opposite pad 2; pads 3 and 4 are AC. Check markings on every bridge. Form the flexible wire leads to the 18×18 mm pad pattern using a support fixture without loading the package seals. The onsemi outline allows lead-position variation; verify the forming fixture with received parts.

The body envelope is 29×29×11.23 mm maximum, with 0.12 mm nominal standoff. The Boyd 6223BG basket sits on the metal base. Use the listed **M4×20 screw**, replacing M4×16 to accommodate the thicker bridge. The native model includes the new bridge, raised basket, screw and nut. Preserve the H9 axis and check underside clearance.

Ten heatsinks, ten mounting screw/nut sets and thermal paste are included in the complete BOM and assembly models. Paste quantity is consumption based; a syringe is an initial batch provision, not a validated yield for 100 boards. All parent references and hardware counts are explicit in `external-hardware.csv`.

Mechanical models include simplified manufacturer-dimension envelopes. They do not establish cabinet fit, assembly tolerances, tool access, harness retention or thermal performance by themselves.

JLCPCB hardware catalog searches are retained in `research/search-hardware-results.json`: the exact 577202B00000G returned zero stock, and no exact 7020BG, 6223BG or MJ420MPP stock listing was found. Consequently this is an all-JLCPCB **electronics** selection, not an all-JLCPCB mechanical procurement package. The external hardware remains required and must not be omitted from the assembly.

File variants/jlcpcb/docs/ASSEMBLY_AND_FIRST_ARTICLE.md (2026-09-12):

> JLC-2 retains this mechanical and connector assembly scheme. Use the current [JLC-2 report](../README.md) and `output/release-candidate/bom/` for electronic part numbers and readiness. Physical first-article qualification remains open.
**JLC-2 electrical change — STTNG only:** flasher diode cathodes for SOL21–SOL28 now return to +20 V on the PCB. J122 pins 5/6/8/9 and J126 pins 10/11/12/13 are therefore +20 V; J126 pin 9 remains the key. These cathode contacts are unused in STTNG. Verify the actual harness before mating; another game may use a different tieback voltage.

# Assembly and first-article qualification

This is a prototype engineering procedure. No physical steps below have been performed.
Use the current `output/release-candidate` files together; older exports are obsolete.

## Assembly

1. Fabricate the saved four-layer design with **70/35/35/70 µm copper**: 2 oz
   finished outer layers, 1 oz inner layers. Nominal dielectric layers are
   0.200/0.990/0.200 mm, total finished board thickness 1.6 mm. Require at least
   20 µm finished plated-hole barrel copper and bare-board electrical testing
   against the included IPC-D-356 file. The Edge.Cuts centerline is
   **449.152 × 272.910 mm**; it controls dimensions over rounded prose labels.
2. Use the purchase BOM and placement file. F101/F102 are clip-only positions;
   each takes two Keystone 3517 clips. F103–F116 each require two clips plus the
   specified fuse. Total: **32 clips**, with 14 populated fuses. Do not substitute
   fast and slow fuse families based only on current rating. DNP parts remain DNP.
3. Fit four separate Boyd **577202B00000G** heatsinks to D101–D104. These
   STPS20M100ST devices have physical **A–K–A** leads; the project footprint
   numbers them **2–1–2**. Their tabs and heatsinks are electrically live cathodes.
   Keep all four heatsinks separate. Use M3×8 pan-head screws and M3 nuts.
4. Fit Boyd **7020BG** to Q10/Q12/Q14/Q16/Q18 with M3×12 screws and M3 nuts,
   using the lower mounting hole. BTA16-600CRG has an insulated tab; a non-insulated
   BTB variant is not an automatic substitute. Fit **6223BG** to BR3 with M4×16
   and M4 nut through H9. Its 4.14 mm hole is close clearance for M4: verify the
   actual screw passes freely before assembly. Do not drill the heatsink in place.
5. Apply a thin, continuous MG Chemicals **8616** thermal-paste film at each
   device/heatsink interface. The modeled 0.5 °C/W interface allowance must be
   validated with actual surface finish, clamping and torque. Set torque from
   the device mounting instructions and fastener specification; no unverified
   numerical torque has been assigned. Support devices while tightening to avoid
   bending leads or loading solder joints. Check retention under cabinet vibration.
6. Verify capacitor polarity and diode orientation against the assembly drawing
   and netlist. C5/C6/C7/C11/C30: TDK B41252A7109M000, nominal 25.4×45 mm,
   worst-case body 26.4×47 mm. C8/C32: Nichicon LLS2A222MELA, nominal 25×40 mm.
   Allow space above every pressure vent, following the capacitor instructions.
   Check maximum envelopes against the backbox, shields, wiring and service access.
   Native TO-220 models currently show untrimmed leads; cut soldered leads to the
   assembly process specification. The BR3 mounting screw also projects below the
   board; measure standoff clearance rather than relying on an unclipped CAD view.
7. Full-pin stock headers require removal of **only the OEM key pins**, as listed
   in the [connector-key schedule](ASSEMBLY_NOTES.md). A no-connect schematic pin is not automatically
   a key, especially on J113. Match friction-lock side, pin 1, key position and
   housing orientation to an OEM board/harness before inserting connectors.

## Acceptance records

Create a record for each serial number containing BOM revision, PCB hash, fabricator
stackup certificate, bare-board electrical-test result, assembly inspection, applied
loads, instrument settings, waveforms, thermal images, and pass/fail disposition.
A fabricated board is not a qualified replacement until these records exist.

| Stage | Exercise and required observations |
|---|---|
| Mechanical | Compare all mounting holes, outline, connector centers, lock directions and keys with an OEM A-12697-3. Trial fit with power disconnected; check mating access, maximum capacitor/vent envelope, heatsinks, fasteners and rear clearance. |
| Unpowered inspection | Inspect solder joints and thermal pads, polarity, fuse identities and clips. Measure isolation between unrelated supplies and live heatsinks; verify ground and intended GI-return jumper. Check for shorts with the reservoir capacitors discharged. |
| Supply bring-up | Use isolated, current-limited secondary sources and dummy loads, beginning with the raw-input paths. Observe +5 V, +12 V, raw rails, switch nodes and input/output currents. Do not inject power into regulated outputs while raw inputs are held low: reverse-power survival is not qualified. |
| Regulation | Sweep declared secondary voltages, ±10% high line, 50/60 Hz, capacitor tolerance and intended loads. Target +5 V at the receiving CPU connector, including harness/contact/ground drop; board-only DC analysis does not include those losses. Check startup, shutdown, short recovery, minimum load, load steps, UVLO and repeated interruptions. |
| Stability | Measure loop gain with a suitable injection fixture at low/high input and load. Compare with the analytical corner model; confirm phase/gain margin and time-domain damping including pulse-skipping operation. |
| CPU interface | Scope ribbon data/strobes, inversion, setup/hold, ZERO_CROSS and BLANKING at both boards. Verify reset/watchdog, disconnected ribbon, partial supplies and loss of ground do not leave unintended drivers active. |
| Output loads | Start with current-limited resistive/inductive loads. Check all 28 outputs, 64 lamp addresses and five GI strings, including cold-lamp inrush. Measure actual coil/motor R/L, flyback voltage, gate voltage, current and repeated pulse temperature. Verify external tie-back diodes and motor suppression in the real harness. |
| Thermal | Reach equilibrium at worst line/load and intended cabinet temperature with enclosure closed. Record rectifier/triac/MOSFET/regulator/inductor/connector temperatures and local capacitor ambient. TDK ripple qualification assumes local ambient ≤60 °C. Correlate board and heatsink models instead of treating modeled temperatures as measurements. |
| Faults | On appropriately contained sacrificial hardware, verify shorted rows, stuck outputs, missing flyback paths, repeated faults and fuse clearing. Record current, duration, energy and resulting damage. SPICE and a fuse rating alone do not establish containment or semiconductor SOA. |
| Cabinet validation | Run service diagnostics and gameplay with the actual STTNG harness, checking every mechanism. Include ball search, tilt/slam, multiball, gun motors, long service tests and power interruptions. Emulator coverage is not physical mechanism coverage. |
| Production | Establish fixture limits and coverage; retain golden-board waveforms. Perform appropriate EMC/ESD and vibration/temperature testing for the intended product/environment. |

Relevant manufacturer sources: [ST rectifier](https://www.st.com/resource/en/datasheet/stps20m100s.pdf),
[TI reverse-power guidance](https://e2e.ti.com/support/power-management-group/power-management/f/power-management-forum/1308507/tps54360b-power-output-without-input-in-test-environment),
[TDK B41252](https://www.tdk-electronics.tdk.com/inf/20/30/db/aec/B41252.pdf),
[Nichicon LLS](https://www.nichicon.com/en-us/part/lls2a222mela/13160/).

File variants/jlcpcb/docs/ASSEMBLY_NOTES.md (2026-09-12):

> JLC-2 retains this mechanical and connector assembly scheme. Use the current [JLC-2 report](../README.md) and `output/release-candidate/bom/` for electronic part numbers and readiness. Physical first-article qualification remains open.
**JLC-2 electrical change — STTNG only:** flasher diode cathodes for SOL21–SOL28 now return to +20 V on the PCB. J122 pins 5/6/8/9 and J126 pins 10/11/12/13 are therefore +20 V; J126 pin 9 remains the key. These cathode contacts are unused in STTNG. Verify the actual harness before mating; another game may use a different tieback voltage.

# Assembly notes - cost-optimised WPC Power Driver Board (A-12697-3 replacement)

Current fabrication/assembly status: [RELEASE_STATUS.md](RELEASE_STATUS.md).

## Connector key pins

The Williams harness plugs (Molex KK 396 / KK 254 housings) carry a blocked position; the matching header pin must be **omitted** (pull
the pin out of the header before soldering, or use a header ordered with that position removed).  The positions below were taken from the
A-12697-1 silkscreen film (STTNG manual p.2-9), cross-checked with the manual's connector map (p.3-33, whose printed pin numbers are
mirrored on J104/J105/J106/J113) and with a photographed board (pinwiki `WPC_Power_-Driver_Board.jpg`, blocked slot visible on every header).
"Pin 1 end" is the physical end of the header on this PCB, which matches the original board (verified against the photo).  Board orientation
as in the manual's connector map: transformer connectors J101-J103 on the right edge, J113/J114/J115 on the left edge, J116-J138 along the bottom.

| connector | header | pins | omit pin (key) | pin 1 end | note |
|---|---|---|---|---|---|
| J101 | KK 396 | 7 | 3 | top | 9 VAC (1, 2) / 13 VAC (4-7) |
| J102 | KK 396 | 9 | 7 | top | 16 VAC (1-4) / 51 VAC (5, 6, 8, 9) |
| J103 | KK 396 | 4 | none | top | all four pins GND, plug has no key |
| J104 | KK 396 | 5 | 3 | left | fused 51 VAC to the Fliptronic II board |
| J105 | KK 396 | 5 | 3 | left | copy of J104, empty on STTNG |
| J106 | KK 396 | 5 | **4** | left | the 16-9057 symbol says 2; film, map and photo say 4 - follow 4 (pins 1-4 are open on this board) |
| J107 | KK 396 | 6 | 4 | left | +50 V branches 1-3, +20 V on 5 and 6 |
| J108 | KK 396 | 3 | none | left | +50 V branches, empty on STTNG |
| J109 | KK 396 | 7 | 6 | left | option header, all pins open |
| J110 | KK 396 | 9 | 5 | left | option header, all pins open |
| J111 | KK 254 (0.100") | 5 | 4 | left | T5-T7 GPIO, empty on STTNG |
| J112 | KK 396 | 5 | 4 | left | 9.8 VAC |
| J113 | 2 x 17 0.100" | 34 | none | bottom end, inner column | see below |
| J114 | KK 396 | 7 | 6 | bottom | +12 V digital (1, 2), +5 V (3, 4), GND (5, 7) -> CPU J210 |
| J115 | KK 396 | 12 | 9 | bottom | G.I. secondary: 1 GND REF, 2-6 hot, 7/8/10/11/12 returns |
| J116 | KK 396 | 4 | 1 | right | +12 V power / GND / +5 V (coin door) |
| J117 | KK 396 | 4 | 1 | right | idem (DMD controller) |
| J118 | KK 396 | 4 | 1 | right | idem (playfield) |
| J119 | KK 396 | 3 | 2 | right | G.I. string 5 to the coin door |
| J120 | KK 396 | 11 | 4 | right | G.I. (all five strings; STTNG uses 2, 3, 8, 9) |
| J121 | KK 396 | 11 | 4 | right | G.I. (all five strings; STTNG uses 1, 5, 6, 7, 10, 11) |
| J122 | KK 396 | 9 | 7 | right | sol 25-28 + tie-back cathodes 5, 6, 8, 9 |
| J123 | KK 396 | 5 | 2 | right | sol 25-28 (backbox), empty on STTNG |
| J124 | KK 396 | 5 | 4 | right | sol 25-28 (cabinet) |
| J125 | KK 396 | 9 | **4** | right | backbox flashers; the 16-9057 symbol draws the key at 5, the film/map/photo show 4 - the board is wired for 4 (sol 20 on pin 5) |
| J126 | KK 396 | 13 | 9 | right | playfield flashers; 10-13 = sol 21-24 tie-back cathodes |
| J127 | KK 396 | 9 | 2 | right | sol 9-16 |
| J128 | KK 396 | 5 | 4 | right | sol 13-16 (cabinet), empty on STTNG |
| J129 | KK 396 | 5 | 3 | right | sol 9-12 (backbox), empty on STTNG |
| J130 | KK 396 | 9 | 3 | right | sol 1-8 |
| J131 | KK 396 | 5 | 2 | right | sol 5-8 (cabinet), empty on STTNG |
| J132 | KK 396 | 5 | 4 | right | sol 1-4 (backbox), empty on STTNG |
| J133 | KK 254 (0.100") | 9 | 3 | right | lamp rows (cabinet) |
| J134 | KK 254 (0.100") | 9 | 3 | right | lamp rows (spare) |
| J135 | KK 254 (0.100") | 9 | 3 | right | lamp rows (playfield) |
| J136 | KK 396 | 3 | 1 | right | lamp column 8 (cabinet) |
| J137 | KK 396 | 9 | 8 | right | lamp columns (playfield) |
| J138 | KK 396 | 9 | 8 | right | lamp columns (playfield/backbox) |

J121 key 4 was rechecked directly against the manufacturer manual, PDF page 61
(printed 2-9), on 2026-09-08; the earlier key-3 entry was a transcription error.

Header pins that are electrically open but not key positions (J106-1..3, J109, J110, J111-1..3 on STTNG, ...) stay in place - the plug
expects a pin there or has no plug at all.

### J113 ribbon header - orientation

* Pin 1 is at the **bottom end of the header (the end nearest J114), in the inner column** (toward the board centre); pin 2 is beside it in
  the outer column, pins 33/34 are at the top end.  This is the position printed on the original board ("2 1" at the bottom, "34 33" at the
  top - the connector map on manual p.3-33 prints it upside down).  The ribbon's red stripe (pin 1) therefore goes to the bottom end, exactly
  as on the original board; the CPU end (J211) is unchanged.
* The footprint is a **shrouded IDC box header** (`wpc_cost:3M_N2534_6002_RB`): the polarising notch faces the board interior, i.e. the
  odd-pin row, which is the DIN 41651 convention that keyed IDC sockets follow - a standard keyed ribbon socket can only go on pin 1 to pin 1.
  The original used an unshrouded 2 x 17 header (Williams 5791-12516-00).  If a game's ribbon socket has its key bump on the other side (it
  will not seat in the shroud), fit an unshrouded 2 x 17 0.100" header instead - the pad layout is the same - and mind the stripe.
* Never plug the ribbon rotated: with the stripe at the top end, BLANKING lands on a ground pin and the strobes on data lines, which turns
  outputs on at random.

### Fuses

All positions take **5 x 20 mm** fuses in Keystone 3517 clips (not the original 3AG): F103/F104/F105 3 A S.B., F106-F110 5 A S.B.,
F111 5 A S.B., F112 7 A S.B., F113 5 A S.B., F114 8 A fast, F115 0.75 A S.B., F116 3 A S.B.; F101/F102 are empty clips (not used on
Fliptronic games).  Label the board so the operator does not fit 3AG spares.

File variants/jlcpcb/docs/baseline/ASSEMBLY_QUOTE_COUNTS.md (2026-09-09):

# Assembly quote counts

Counts for the current populated engineering candidate, excluding DNP parts,
test points, mounting holes and fiducials. These are quotation quantities;
the release limitations in [RELEASE_STATUS.md](RELEASE_STATUS.md) still apply.

| Form field | Count | Interpretation |
| --- | ---: | --- |
| Unique electronic parts | 70 | Distinct electronic MPNs, including fuse cartridges and clips |
| Unique full purchase BOM parts | 79 | Also includes mounting hardware and thermal paste |
| SMD components | 314 | Populated surface-mount component instances |
| SMT pads | 929 | Numbered copper pads, including exposed pads; excludes paste-only apertures |
| BGA/QFP components or pads | 0 | No BGA or QFP packages |
| Through-hole components | 93 | Individual physical soldered parts |
| Populated through-hole solder pins | 389 | Excludes 35 removed connector key pins |

Use **929** when the SMD field's unit is “total SMT pads,” and **314** when
it asks for components. Use **93** for through-hole parts or **389** for
through-hole solder pins.

The 77 through-hole footprint groups represent 93 physical parts because
16 fuseholder footprints each contain two separate clips. The through-hole
parts comprise 38 headers, 32 clips, 11 capacitors, five triacs, four TO-220
diodes, one bridge and two SIP resistor arrays. There are 424 numbered
through-hole PCB pads before subtracting the 35 connector key pins.

The 14 plug-in fuse cartridges are additional assembly items and are not
included in the soldered through-hole component count.

Sources: the routed PCB, `output/release-candidate/bom/purchase-bom.csv`,
and `output/verification/revision/connector-keys.csv`.

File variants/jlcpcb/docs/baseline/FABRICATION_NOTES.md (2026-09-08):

# Fabrication and assembly notes - WPC Power Driver replacement, cost-optimised board

Deliverables for the fab/assembler are in `output/` (regenerated by `bash tools/export.sh` from the routed board):
`wpc_power_driver_cost-gerbers.zip` (RS-274X Gerbers with Protel extensions + `.gbrjob`), `drill/` (Excellon, plated and non-plated,
plus drill maps), `assembly/` (position files, IPC-D-356 net-list `wpc_power_driver_cost.d356`, assembly drawing, per-layer PDFs),
`bom/` (grouped and flat BOM CSV; `BOM-cost.md` with manufacturer, MPN, distributor link and prices), `reports/` (ERC, DRC).

## Bare board

| item | specification |
|---|---|
| Outline | 449.2 x 272.9 mm, 4.0 mm corner radius (`Edge_Cuts`), single board, no panelisation required (specify a fab that handles > 400 mm boards) |
| Layers | 4: F.Cu (signal + power), In1.Cu (solid GND plane), In2.Cu (signal), B.Cu (signal + power + GND pour) |
| Thickness | 1.6 mm +/- 10 %, FR-4, Tg >= 150 C, UL 94V-0 |
| Copper | **outer layers 2 oz (70 um) finished**, inner layers 1 oz (35 um).  The high-current rails (+18 V lamps 8 A, "+50 V" solenoid pulses 16 A, G.I. strings 4.5 A rms, G.I. return up to 22 A, +5 V 3 A) are routed 3-5 mm wide on the outer layers only; do not substitute 1 oz outer copper |
| Minimum track / clearance | 0.4 mm / 0.2 mm (signal); 0.4 mm clearance on the HV classes; 0.5 mm copper-to-edge |
| Vias | 1.2 / 0.6 mm and 1.8 / 1.0 mm (power); 0.8 / 0.5 mm on a few hand-routed links; minimum annular ring 0.15 mm; through-hole only, tented both sides |
| Holes | smallest finished drill 0.5 mm; 8 x 4.3 mm non-plated mounting holes (M4) at the original A-12697-3 positions plus H9, a 5.5 mm non-plated hole under the BR3 bridge block for its M4 heatsink bolt; connector, fuse-clip and bridge holes plated |
| Surface finish | ENIG preferred (flat pads for the DPAK / HSOP parts); lead-free HASL acceptable |
| Solder mask | both sides, green, LPI; 0 mm mask-to-copper clearance as in the design files (library defaults); PowerPAD via arrays under U20/U21 and the 3 x 3 thermal-via arrays in the D2PAK tabs (D101-D116) are tented |
| Silkscreen | both sides, white; top carries reference designators, fuse ratings/purposes, connector functions, title, revision and the 70 V caution (`tools/legend.py`) |
| Fiducials | FID1 (5, 34), FID2 (443, 25), FID3 (5, 253) mm from the top-left corner: 1 mm copper / 2 mm mask openings, top side |
| Electrical test | 100 % net-list test against `assembly/wpc_power_driver_cost.d356` |
| Class | IPC-A-600 / IPC-6012 class 2 |
| Marking | fab date code and UL logo on the bottom side outside the component area (bottom silkscreen has the free title area near the centre) |

## Assembly

* All 375 placed components are on the **top side** (`assembly/wpc_power_driver_cost-pos.csv`; DNP parts are listed separately in
  `-pos-all-incl-dnp.csv`).  SMT reflow first (0805/1210/2512 passives, SMA/SMC/SOD-123 diodes, DPAK MOSFETs, SOIC logic, HSOP-8 bucks,
  SRP inductors, SOT-23 transistors, SMD LEDs), then through-hole: Molex KK connectors, the 2x17 box header J113, Keystone 3517 fuse clips
  (32 clips = 16 fuse positions), the five bridge rectifiers, the TO-220 triacs, the snap-in / radial electrolytics, the through-hole
  test-point pads.  Selective or wave soldering is fine; the 4.9 mm PowerPAD via arrays are on the top side only.
* **Connector key pins**: several harness plugs are keyed by a plugged position; the corresponding header pin must be omitted (or cut) so
  the original harness mates in the original orientation.  The list is in `docs/ASSEMBLY_NOTES.md` (connector key pins), derived from the
  STTNG manual's connector tables.
* **J113 orientation**: pin 1 of the 34-way box header is at the position shown on the assembly drawing (polarising notch as on the
  original board); the ribbon to CPU J211 is 1:1.
* **Schottky bridge diodes D101-D116** (D2PAK): the tab is the cathode and sits on a 2 oz heat-spreading pour with a 3 x 3 via array
  (tools/rail_pours.py); reflow with the tab fully wetted - the pours are the heatsink (no separate part).
* **Heatsinks**: the five G.I. triacs (Q6-Q10) and the bridge rectifiers need the heatsinks listed in `docs/THERMAL_AND_PROTECTION.md`
  and the BOM (thermal pad or paste, M3 hardware, torque 0.5-0.6 Nm for TO-220, 1.0 Nm for the GBJ/GBU tabs).  The original board
  bolts its bridge blocks to the chassis bracket; this board carries its own.
* **Fuses** are 5 x 20 mm (Littelfuse 239 Slo-Blo / 217 fast, ratings printed on the silkscreen next to each position); F101/F102 get
  clips only (no fuse) on Fliptronic games.  Ship with fuses fitted.
* **DNP**: the relay option K1 and its parts (marked DNP in the BOM), R198.  Do not populate.
* **Polarity**: the electrolytic capacitors' negative stripe follows the silkscreen mark; bridge rectifiers: "+" lead per the silkscreen;
  LEDs: cathode mark.
* **Conformal coating**: none (matches the original).  Clean no-clean flux residue around the fuse clips.

## Test before shipping

1. Visual: fuse clip alignment (a 5 x 20 mm fuse must seat in every position), key pins removed, heatsinks torqued, no bent DPAK tabs.
2. Power-up without the machine: apply the secondaries through the original fuses or a bench transformer set; check the rails at the test
   points: TP2 +5.0 V (+/- 2 %), TP1 +12 V power (unregulated, 10-16 V), +12 V digital (12.0 V) on J114-1/2, TP8 +18 V (~14-18 V unloaded),
   TP7 +20 V, TP6 "+50 V" (66-78 V DC).  Verify ZERO CROSS at J113-34 is a 5 V, 60 Hz square wave.
3. With BLANKING (J113-31) left open (pulled high on the board) no solenoid, flasher, lamp column or triac output may be active.
4. In the machine: run the STTNG solenoid, lamp and G.I. tests from the diagnostics menu.

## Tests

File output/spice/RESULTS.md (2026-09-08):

# SPICE verification results - cost-optimised board in the STTNG machine

ngspice (KiCad 10 bundled libngspice) transient runs of each circuit block; MOSFET/diode models in `tools/spice/models.lib` are level-1 fits to datasheet Rds(on)/Qg
(functional fidelity, not vendor-exact); the TPS54360B is a behavioural peak-current-mode model (12 A/V, 4.5 A minimum current limit, 400 kHz). Machine-level decks use the real WPC
interface: 51 VAC solenoid winding (~70 V rail), 2 ms lamp column strobes, IRQ-timed triac firing, PWM-held coils, the +12 V digital / +12 V power split, the active-high zero-cross pulse,
BLANKING as the CPU drives it at reset, and switch-on inrush against the Littelfuse 239/217 melting I2t (docs/WPC_INTERFACE_FINDINGS.md). Waveform CSVs are next to this file.
Each limit is explained in its description column (see also README.md).

## bridge_loss

| measurement | value | expected | result |
|---|---|---|---|
| BR1 +18V DC output current with all 64 lamps lit + the +12V digital buck at 0.75 A (A) - the everything-on case of psu_maxload (`iavg_18a`) | 6.447 | 5 … 8 | PASS |
| BR1 leg RMS current in that case (A): capacitor-input rectifier, crest factor ~1.6-2 (`irms_18a`) | 11.22 | 5 … 16 | PASS |
| per-diode loss of the +18V Schottky bridge (4 x STPS20M100S) with all lamps lit, datasheet equation 0.425 IF(AV) + 0.0088 IF(RMS)^2 (W) - the whole bridge is 4x this (was 15.2 W with the GBJ1510) (`pd_18a`) | 1.923 | 0 … 5 | PASS |
| Rth(j-a) each +18V diode needs for Tj <= 110 C at 50 C ambient with all lamps lit (C/W) - 31.2 C/W needed = 12 cm2 of 2 oz copper; specified 15 cm2 per diode = 29.7 C/W (D101/D102 share the +18V pour: 30 cm2; D103 on AC13_A_F and D104 on AC13_B 15 cm2 each) (`rthreq_18a`) | 31.19 | 25 … 200 | PASS |
| BR1 diode junction temperature with all 64 incandescent lamps lit (6.4 A DC, 11.2 A rms) on 15 cm2 of 2 oz copper per diode (29.7 C/W) at 50 C ambient (C): the case the GBJ1510 failed at 208 C (`tj_18a`) | 107.1 | 0 … 110 | PASS |
| BR1 diode junction temperature at 3.0 A DC (C) (`tj_18b`) | 73.53 | 0 … 110 | PASS |
| per-diode loss at the F114 rating 8 A DC (W) - informational: needs ~30 cm2 of 2 oz copper per diode for 110 C, i.e. the 8 A fuse limit is a short-term rating (`pd_18c`) | 2.494 | 0 … 5 | PASS |
| BR1 diode junction temperature at 8 A DC on the 15 cm2 pours (C): limit = the STPS20M100S absolute maximum 150 C (informational; 110 C would need ~30 cm2 per diode, so the F114 rating is a short-term bound) (`tj_18c`) | 124.1 | 0 … 150 | PASS |
| BR4 +20V diode junction temperature at 2.5 A DC sustained on 4 cm2 of 2 oz copper per diode (36 C/W) (C) (`tj_20a`) | 73.46 | 0 … 110 | PASS |
| BR4 diode junction temperature at the F111 rating 5 A DC on 4 cm2 (C): informational, limit = Tj max 150 C; 110 C needs ~10 cm2 per diode (`tj_20b`) | 102 | 0 … 150 | PASS |
| BR3 +50V GBPC3510W junction temperature at 3.0 A DC sustained (a held 14.5 ohm coil half the time plus play; flippers are rectified on the Fliptronic board) with the Boyd 6224BG basket heatsink bolted on the (upward-facing) metal base: 1.4 j-c + 0.5 + 9.4 x 1.05 = 11.8 C/W (C) (`tj_50a`) | 117.5 | 0 … 125 | PASS |
| BR3 dissipation at the F112 rating 7 A DC (W) - informational: sustained limit with the 6224BG is 3.4 A (`pds_50b`) | 14.88 | 0 … 60 | PASS |
| BR2 +5V raw diode junction temperature with the +5V buck at its rated 3 A output (~1.9 A DC in) on 2 cm2 of 2 oz copper per diode (41 C/W) (C) (`tj_5a`) | 66.83 | 0 … 110 | PASS |
| BR2 diode junction temperature at the estimated real +5V load 2.4 A (C) (`tj_5b`) | 62.96 | 0 … 110 | PASS |
| BR5 +12V power diode junction temperature at 2.5 A DC sustained on 2 cm2 of 2 oz copper per diode (41 C/W) (C) (`tj_12a`) | 74.7 | 0 … 110 | PASS |
| BR5 diode junction temperature at the F116 rating 3 A DC on 2 cm2 (C) - the 239 fuse carries 110 % for 4 h, so a sustained case (`tj_12b`) | 80.09 | 0 … 110 | PASS |
| cross-check: whole-bridge dissipation of BR1 with all lamps lit from the SPICE model power balance (AC-side minus DC-side power) (W) - the model is fitted to the 25 C typical Vf and so runs above the 125 C datasheet equation (`pmodel_18a`) | 10.95 | 0 … 40 | PASS |
| +18V rail average with all lamps lit and the Schottky bridge (V): was 12.6 V with the GBJ1510 (`vdc_18a`) | 14.33 | 12 … 20 | PASS |
| BR5 leg RMS current at 2.5 A DC (A): each diode carries Irms/sqrt(2) = 2.8 A rms (IF(RMS) rating 30 A) (`irms_12a`) | 4.021 | 0 … 8 | PASS |

## buck_12v

| measurement | value | expected | result |
|---|---|---|---|
| steady-state output at 1 A from the +18V rail at 13.5 V (V) (`vout_ss`) | 11.94 | 11.8 … 12.2 | PASS |
| output ripple p-p at 1 A (V) (`vout_ripple`) | 0.04068 | 0 … 0.1 | PASS |
| undershoot on a 1 -> 2 A load step (V): the real load behind F115 is <= 0.75 A; 11.4 V keeps the switch matrix / CPU +12V loads happy (`vout_step_min`) | 11.8 | 11.4 … 12.2 | PASS |
| overshoot on the 2 -> 1 A step (V) (`vout_step_max`) | 12.04 | 11.8 … 12.6 | PASS |
| peak inductor current at 2 A from 13.5 V (A): below the 4.5 A minimum current limit (`il_peak`) | 3.233 | 2 … 4.3 | PASS |
| output at 2 A (V) (`vout_2a`) | 11.9 | 11.8 … 12.2 | PASS |
| input current at 2 A out from 13.5 V (A) (`iin_2a`) | -1.812 | -2.6 … -1 | PASS |

## buck_5v

| measurement | value | expected | result |
|---|---|---|---|
| steady-state output at 1 A (V): 5.10 V set point (11.3 k / 2.1 k, Vref 0.8 V) (`vout_ss`) | 5.105 | 5 … 5.2 | PASS |
| output ripple p-p at 1 A (V) (`vout_ripple`) | 0.02824 | 0 … 0.08 | PASS |
| undershoot on a 1 -> 3 A load step (V): with the 5.10 V set point the dip stays >= 4.75 V at the board, i.e. > 4.70 V (MC34064 maximum threshold) at the CPU even through 80 mOhm... see docs/THERMAL_AND_PROTECTION.md section 9 (`vout_step_min`) | 5.004 | 4.75 … 5.2 | PASS |
| overshoot on the 3 -> 1 A step (V): stays below the 5.20 V no-load maximum at the connector (`vout_step_max`) | 5.194 | 5 … 5.5 | PASS |
| peak inductor current at 3 A (A): must stay below the 4.5 A minimum current limit of the TPS54360B (SRP1265A-100M rated 10 A) (`il_peak`) | 3.66 | 3 … 4.3 | PASS |
| output at 3 A (V) (`vout_3a`) | 5.091 | 5 … 5.2 | PASS |
| input current at 3 A out from 8 V (A, negative = drawn from Vin) (`iin_3a`) | -2.103 | -3 … -1.5 | PASS |

## flasher

| measurement | value | expected | result |
|---|---|---|---|
| cold-lamp inrush (A) (`ilamp_inrush`) | 6.615 | 3 … 8 | PASS |
| hot lamp current (A) (`ilamp_hot`) | 1.111 | 0.7 … 1.4 | PASS |
| IRLR3110Z Vds with the lamp on (V): 1.1 A x 18 mOhm = 0.02 V (`vsat`) | 0.02035 | 0 … 0.1 | PASS |

## gi_dim

| measurement | value | expected | result |
|---|---|---|---|
| ZERO CROSS period from the board detector inside this deck (s) (`zc_period`) | 0.01667 | 0.0163 … 0.017 | PASS |
| ZC rising edge after the true crossing (s) (`zc_rise_offset`) | 0.0004759 | 0 … 0.001 | PASS |
| ZC falling edge before the true crossing (s) (`zc_fall_offset`) | -0.0004456 | -0.001 … 0 | PASS |
| triac gate current (A) - above the 50 mA quadrant-IV Igt of the BTA16-600C (`ig_pk`) | 0.08003 | 0.06 … 0.13 | PASS |
| level 0 (full): positive half-cycle peak string current (A) (`l0_max`) | 6.621 | 5 … 8 | PASS |
| level 0: negative half-cycle peak (A) - fires in both half-cycles (`l0_min`) | -6.621 | -8 … -5 | PASS |
| level 0: |average| / rms of the string current - symmetric, no transformer DC (`l0_asym`) | 2.796e-08 | 0 … 0.02 | PASS |
| level 3, gate held to the next ZC edge: positive peak (A) (`l3h_max`) | 6.621 | 5 … 8 | PASS |
| level 3 held: negative peak (A) - both half-cycles fire (`l3h_min`) | -6.621 | -8 … -5 | PASS |
| level 3 held: |avg|/rms - asymmetry from the +/-0.3 ms edge offsets of the detector (same behaviour as the original board) (`l3h_asym`) | 0.1133 | 0 … 0.25 | PASS |
| level 3, 8 us gate pulse (FreeWPC style): positive peak (A) (`l3p_max`) | 6.621 | 5 … 8 | PASS |
| level 3 pulsed: negative peak (A) - the 50 mA-gate BTA16-600C latches on a few-us pulse in both quadrants (`l3p_min`) | -6.621 | -8 … -5 | PASS |
| level 7 (dimmest) with the bit HELD until the next ZC edge: positive peak (A) - informational: because the ZC edge comes after the crossing, a held gate re-fires the triac at the crossing and that half-cycle runs at full brightness; the firmware must pulse the bit or clear it before the crossing, exactly as with the original detector (`l7h_max`) | 6.621 | 1 … 8 | PASS |
| level 7 held: negative peak (A) (`l7h_min`) | -3.593 | -8 … -1 | PASS |
| level 7 pulsed: positive peak (A) (`l7p_max`) | 1.477 | 1 … 8 | PASS |
| level 7 pulsed: negative peak (A) (`l7p_min`) | -3.593 | -8 … -1 | PASS |
| level 7 pulsed: string rms current (A) - dimmest level (`l7p_rms`) | 0.6617 | 0.3 … 1.5 | PASS |
| level 0: string rms current (A) - full (18 x #44 = 4.5 A) (`l0_rms`) | 4.682 | 4 … 5.5 | PASS |

## gi_gate

| measurement | value | expected | result |
|---|---|---|---|
| triac gate current (A) - above the 50 mA worst-case Q IV Igt of the BTA16-600C (`ig_peak`) | 0.07841 | 0.06 … 0.13 | PASS |
| string current before trigger (A) (`istr_off`) | 6.092e-06 | 0 … 0.05 | PASS |
| string current while enabled (A peak) (`istr_on`) | 5.649 | 4 … 8 | PASS |
| string rms current while enabled (A) - 18 x #44 on 6.3 VAC, F106 is 5 A S.B. (`istr_rms`) | 3.887 | 3 … 5 | PASS |
| string current after latch released (A) (`istr_after`) | 8.9e-06 | 0 … 0.3 | PASS |
| MMBT4401 dissipation (W, SOT-23 limit 0.31 W) (`p_npn`) | 0.1245 | 0 … 0.25 | PASS |
| base current sourced by the 74HCT574 (A, negative = out of the latch) (`i_latch`) | -0.003665 | -0.004 … -0.0001 | PASS |
| BTA16-600C conduction loss with the datasheet on-state (Vt0 0.85 V, Rd 25 mOhm) at this string current (W) - the datasheet gives <= 5 W at 4.5 A rms (`p_triac`) | 3.265 | 0 … 5 | PASS |
| junction rise above ambient with the Boyd 7019BG bolt-on channel heatsink (11.0 C/W catalogue value at a 75 C rise, x1.15 for the ~50 C rise here) + Rth(j-c) 2.5 (BTA16 insulated TO-220) + 0.5 C/W interface = 15.65 C/W (C): limit Tj <= 125 C in a 50 C cabinet. The 7019BG (39.4 x 9.5 x 25.4 mm, M3 bolt-on, no PCB holes) fits all five triac positions on the tab side (docs/THERMAL_AND_PROTECTION.md section 2) (`tj_rise_sink`) | 51.09 | 0 … 75 | PASS |
| informational: the rise the previously specified Aavid 577002B00000G clip-on would give - it is a 32 C/W part per the Boyd catalogue (35 C/W junction-to-ambient), i.e. Tj ~165 C with an incandescent string; replaced by the 7019BG (C) (`tj_rise_clip`) | 114.3 | 0 … 200 | PASS |
| maximum sink-to-ambient thermal resistance that keeps Tj <= 125 C at 50 C ambient with this string (C/W) - informational, compare with the 12.65 C/W of the 7019BG in this cabinet (`rth_sa_needed`) | 19.97 | 0 … 100 | PASS |

## gi_string

| measurement | value | expected | result |
|---|---|---|---|
| cold-start peak current of an 18 x #44 string fired at the voltage peak (A) - BTA16-600C ITSM 160 A (8.3 ms) (`ipk`) | 38.84 | 0 … 160 | PASS |
| I2t through F106 (239 5 A S.B., 302.8 A2s nominal melting) during the whole cold start (A2s): <= 20 %, and far below the BTA16 I2t of 128 A2s (`i2t_f106`) | 9.188 | 0 … 60 | PASS |
| I2t in the first 30 ms (A2s) - the part the fuse sees as a surge (`i2t_30ms`) | 3.155 | 0 … 60 | PASS |
| steady string rms current (A) - 18 x #44 = 4.5 A on the 5 A slow-blow F106 (rated to carry 110 % continuously) (`irms_ss`) | 4.544 | 3.5 … 5 | PASS |
| steady triac dissipation with the datasheet on-state (W) - see gi_gate for the heatsink requirement (`p_triac`) | 3.913 | 0 … 5 | PASS |
| string current before the gate is driven (A) (`istr_pre`) | 1.107e-05 | 0 … 0.05 | PASS |
| junction rise with the Boyd 7019BG heatsink at the steady 4.5 A rms string (C): P x 15.65 C/W (2.5 j-c + 0.5 interface + 12.65 sink) - the worst of the two G.I. decks; Tj <= 125 C at 50 C ambient (`tj_rise_sink`) | 61.24 | 0 … 75 | PASS |

## inrush

| measurement | value | expected | result |
|---|---|---|---|
| peak inrush through F113 / BR2 (GBU8J, IFSM 200 A) into C5 at switch-on on the mains peak (A) (`ipk_f113`) | 55.12 | 0 … 60 | PASS |
| I2t through F113 in the first 250 ms (A2s): <= 20 % of the 302.836 A2s nominal melting I2t of the Littelfuse 239 5 A (239 datasheet / distributor specification, docs/THERMAL_AND_PROTECTION.md section 4) so the fuse never ages from switch-on (`i2t_f113`) | 2.824 | 0 … 60.5 | PASS |
| peak inrush through F114 / BR1 (GBJ1510, IFSM 240 A) into C6 + C7 (A) (`ipk_f114`) | 71.27 | 0 … 120 | PASS |
| I2t through the FAST 8 A F114 (A2s): <= 20 % of the 198.16 A2s of the Littelfuse 217 8 A (217 datasheet table, read directly) (`i2t_f114`) | 10.46 | 0 … 39.6 | PASS |
| peak inrush through F111 / BR4 (GBJ1510) into C11 (A) (`ipk_f111`) | 59.63 | 0 … 120 | PASS |
| I2t through F111 (239 5 A, 302.836 A2s) (A2s): <= 20 % (`i2t_f111`) | 5.458 | 0 … 60.5 | PASS |
| peak inrush through F116 / BR5 (GBU8J) into the 10000 uF C30 (A) (`ipk_f116`) | 35.52 | 0 … 100 | PASS |
| I2t through F116 (239 3 A) (A2s): <= 20 % of the real 239 3 A nominal melting I2t, 129.51 A2s (replaces the 313 3 A 200 A2s stand-in) (`i2t_f116`) | 1.94 | 0 … 25.9 | PASS |
| peak inrush through F112 / BR3 (GBPC3510, IFSM 400 A) into 2 x 2200 uF at 72.7 V peak (A) (`ipk_f112`) | 53.27 | 0 … 200 | PASS |
| I2t through F112 (239 7 A) (A2s): the 239 7 A row could not be retrieved (every host of the 239 datasheet blocks automated access; the 3 A / 5 A values 129.5 / 302.8 A2s extrapolate to ~530 A2s) - the limit stays at 20 % of the OEM 313 7 A (347 A2s), which is the more conservative reference (`i2t_f112`) | 6.663 | 0 … 69.4 | PASS |
| "+50V" reached after 250 ms (V) (`v50_final`) | 70.37 | 66 … 74 | PASS |
| +18V reached after 250 ms (V) (`v18_final`) | 17.5 | 14 … 20 | PASS |

## lamp_matrix

| measurement | value | expected | result |
|---|---|---|---|
| row current, normal lamp incl. cold inrush (A) (`irow_normal`) | 2.438 | 0.3 … 3.5 | PASS |
| sense voltage stays below the 1.4 V trip (V) (`vsense_normal`) | 0.5026 | 0 … 1.3 | PASS |
| 1.4 V reference (V) (`vref`) | 1.29 | 1.2 … 1.6 | PASS |
| column IRFR5305 drop with one lamp on (V): ~2 A x 65 mOhm = 0.13 V; 0.3 V = 150 mOhm (hot, low Vgs) (`vcol_drop`) | 0.1205 | 0 … 0.3 | PASS |
| row driver drop incl. the 0.22 R sense resistor (V): 2 A x (0.22 + 0.08) = 0.6 V; 0.8 V keeps > 17 V on the 18 V lamp string (`vrow_on`) | 0.6228 | 0 … 0.8 | PASS |
| comparator never clears the row flip-flop in normal operation (V) (`clr_min`) | 4.999 | 3 … 5.5 | PASS |
| column MOSFET Vgs from the 1k/1.5k divider (V): IRFR5305 needs <= -7 V for its rated 65 mOhm (`vgs_col`) | -10.8 | -13 … -7 | PASS |

## lamp_matrix_trip

| measurement | value | expected | result |
|---|---|---|---|
| shorted lamp: row current exceeds the 6.4 A trip (A) (`irow_fault`) | 8.365 | 6.4 … 80 | PASS |
| row flip-flop cleared (s): short applied at 32.5 ms, column strobe (fault current) starts at 33.0 ms -> cleared within 0.2 ms (`t_trip`) | 0.03316 | 0.033 … 0.0332 | PASS |
| row current after shutdown until the next strobe (A) (`irow_after`) | 0.002529 | 0 … 0.5 | PASS |
| fault current returns at the next strobe and trips again (A) - per-strobe shutdown as in the original (`irow_next`) | 8.365 | 2 … 80 | PASS |

## lamp_strobe

| measurement | value | expected | result |
|---|---|---|---|
| column IRFR5305 current at the start of a 2 ms strobe with 8 warm #555 lamps (A): ~1 A per lamp, 0.7 A once hot (`icol_peak`) | 8.022 | 4 … 12 | PASS |
| average column current over the 16 ms frame (A): x 8 columns = the ~5 A +18V load with every lamp lit (`icol_avg`) | 0.666 | 0.4 … 1 | PASS |
| column MOSFET drop at the 8 A strobe peak (V): 65-100 mOhm (`vcol_drop`) | 0.4342 | 0 … 0.8 | PASS |
| average column MOSFET dissipation, all 8 lamps lit (W): 2 ms of 8 A every 16 ms (`pcol_avg`) | 0.2349 | 0 … 0.6 | PASS |
| column DPAK junction rise (C): P x 110 C/W (IRFR5305 datasheet minimum footprint; the as-routed drain copper is the tab pad only) (`tj_rise_col`) | 25.84 | 0 … 75 | PASS |
| row IRLR024N current: one warm lamp per strobe (A) (`irow_peak`) | 1.023 | 0.5 … 2.5 | PASS |
| average row current with all 8 lamps of the row lit (A) (`irow_avg`) | 0.5139 | 0.2 … 1 | PASS |
| row MOSFET average dissipation (W) (`prow_avg`) | 0.08207 | 0 … 0.3 | PASS |
| row DPAK junction rise (C): P x 110 C/W (IRLR024N minimum footprint, as routed) (`tj_rise_row`) | 9.027 | 0 … 75 | PASS |
| sense voltage over 400 ms of strobing incl. the cold first strobes (V): stays below the 1.4 V trip (`vsense_max`) | 0.1917 | 0 … 1.2 | PASS |
| no false over-current trip during normal strobing (V) (`clr_min`) | 5 | 3 … 5.5 | PASS |
| cold-filament current at the very first strobe (A): 7 ohm filament on 18 V (`ilamp_first`) | 2.28 | 1.5 … 3.5 | PASS |
| RMS voltage across a #555 lamp over the 16 ms frame (V): rated 6.3 V; the MOSFET drops are 0.5 V instead of the 2.2 V of the 1993 Darlingtons, so the lamps run at ~98 % of their rating (brighter, about 3x shorter life than on the original board - irrelevant for LEDs) (`vlamp_rms`) | 6.174 | 5.5 … 6.6 | PASS |
| the same lamp behind the original TIP107/TIP102 drops (V) - reference for the comparison (`vlamp_old_rms`) | 5.531 | 5 … 6 | PASS |

## powerup

| measurement | value | expected | result |
|---|---|---|---|
| coil current while BLANKING is high (reset, +5V ramp, undefined latch content = 1) (A): the tri-stated 74HCT574 and the 10 k gate pull-down keep the IRLR3110Z off (`icoil_blank`) | 1.312e-08 | 0 … 0.01 | PASS |
| G.I. string current while blanked (A): 10 k base pull-down keeps the MMBT4401 / triac off (`istr_blank`) | 9.6e-06 | 0 … 0.05 | PASS |
| lamp column current while blanked with a row MOSFET randomly ON (A): the TBD62083A input pull-down keeps the column P-MOSFET off (`icol_blank`) | 1.36e-10 | 0 … 0.01 | PASS |
| solenoid gate voltage while blanked (V) (`vgate_blank`) | 0.0001365 | 0 … 0.5 | PASS |
| BLANKING never drops below 4 V while the CPU holds reset (V): SR1 pulls it up, the CPU 2N3904 is off (`blank_min`) | 5 | 4 … 5.5 | PASS |
| coil current after the CPU releases BLANKING with the latch holding 1 (A): the path works (`icoil_on`) | 16.6 | 10 … 20 | PASS |
| G.I. string current after release (A peak) (`istr_on`) | 6.621 | 4 … 8 | PASS |
| lamp column current after release (A) (`icol_on`) | 5.284 | 3 … 8 | PASS |
| coil current after the CPU writes 0 (A) (`icoil_after`) | 2.518e-09 | 0 … 0.01 | PASS |
| column current after the CPU writes 0 (A) (`icol_after`) | 0.0001061 | 0 … 0.01 | PASS |

## psu

| measurement | value | expected | result |
|---|---|---|---|
| +18V lamp rail average at 2.8 A / 5 ohm plus the 1 A +12V digital buck (V): the lamp matrix needs >= 13 V for full brightness (`v18_avg`) | 15.33 | 13 … 20 | PASS |
| +18V ripple p-p with 2 x 10000 uF (V): 3 V = 20 % of the rail, the largest brightness flicker acceptable at 120 Hz (`v18_ripple`) | 1.121 | 0 … 3 | PASS |
| +5V buck input minimum at 3 A output with 10000 uF (V): TPS54360B needs 5.6 V for 5 V out, the 6.0 V UVLO start + 0.5 V (`vin5_min`) | 9.974 | 6.5 … 14 | PASS |
| +5V raw ripple p-p (V) (`vin5_ripple`) | 1.008 | 0 … 3.5 | PASS |
| +5V minimum at 3 A load (V): set point 5.10 V (11.3 k / 2.1 k, 0.1 %) since the 2026-09-07 review (`v5_min`) | 5.1 | 5.05 … 5.15 | PASS |
| +5V at the CPU board with 3 A through 80 mOhm of board copper + harness (V): must stay above the 4.70 V maximum MC34064 reset threshold (with 5.00 V and 1 % feedback parts the worst case was 4.61 V) (`v5_cpu_worst`) | 4.86 | 4.7 … 5.2 | PASS |
| "+50V" idle (V): 51.4 VAC nominal winding -> 72.7 V peak minus two diode drops; pinwiki: TP6 measures 70-75 V (`v50_idle`) | 69.22 | 66 … 74 | PASS |
| "+50V" maximum at idle (V): the STTNG transformer measured 55.2 VAC unloaded = 78 V peak (83 V at +6 % line); 100 V capacitors and 100 V MOSFETs keep >= 17 V (`v50_max`) | 69.39 | 66 … 80 | PASS |
| "+50V" average during a 40 ms AE-23-800 pulse with 4400 uF (V): the original 100 uF board fell to the rectified sine (`v50_avg_pulse`) | 41.64 | 35 … 60 | PASS |
| "+50V" minimum during the pulse (V) (`v50_min_pulse`) | 35.53 | 28 … 60 | PASS |
| peak AE-23-800 coil current with the sagging rail (A) (`icoil_max`) | 13.07 | 11 … 18 | PASS |
| +20V minimum during a 4 A flasher burst with 10000 uF (V): flashers only on this rail now (`v20_min`) | 17.81 | 13 … 24 | PASS |
| +20V ripple p-p during the burst (V) (`v20_ripple`) | 2.194 | 0 … 3 | PASS |
| +12V digital minimum, buck fed from the +18V lamp rail at 2.8 A of lamps (V) (`v12_min`) | 12 | 11.95 … 12.05 | PASS |
| +12V digital maximum (V) (`v12_max`) | 12 | 11.95 … 12.05 | PASS |

## psu_12vu

| measurement | value | expected | result |
|---|---|---|---|
| +12V power minimum at 2.5 A, measured STTNG winding (12.47 VAC unloaded, 0.25 ohm/leg) (V) (`v12u_min`) | 11.61 | 10 … 16 | PASS |
| +12V power average at 2.5 A (V) (`v12u_avg`) | 12.22 | 10.5 … 16 | PASS |
| ripple p-p at 2.5 A with 10000 uF (V) (`v12u_ripple`) | 1.207 | 0 … 2 | PASS |
| BR5 GBU8J repetitive peak current (A): 4 x 8 A (`ibr5_peak`) | 8.227 | 0 … 32 | PASS |
| BR5 RMS current (A): GBU8J average rating 8 A (`ibr5_rms`) | 4.079 | 0 … 8 | PASS |
| maximum +12V power with only the LED load (V): C30 is a 25 V part - 20 V keeps 20 % margin (unloaded winding 17.6 V peak) (`v12u_max_unloaded`) | 16.7 | 0 … 20 | PASS |
| pessimistic bound: the manual's nominal 9.8 VAC winding at 2.5 A (V) - the real transformer is ~2 V higher (`v12u_min_nominal`) | 10.56 | 8.5 … 16 | PASS |

## psu_brownout

| measurement | value | expected | result |
|---|---|---|---|
| +5V buck input minimum at 88 % mains and the rated 3 A (V): must stay above the UVLO stop level - 5.5 V nominal, 6.0 V worst case (Vena 1.3 V) - so the converter keeps regulating (sweep: output/spice/uvlo_sweep.md) (`vraw_min`) | 8.275 | 6 … 12 | PASS |
| +5V holds through an 88 % brownout at 3 A (V) - the CPU reset chip (MC34064, 4.6 V) never trips; 5.10 V set point (`v5_min`) | 5.1 | 5.05 … 5.15 | PASS |
| +18V minimum at 88 % mains with all lamps lit (V) (`v18_min`) | 11.71 | 9.5 … 16 | PASS |
| +12V digital at 88 % mains with all lamps lit (V): droops with the +18V rail; 9 V still runs the CPU switch-matrix comparators; the original 7812 would have delivered ~7 V here (`v12_min`) | 10.86 | 9 … 12.05 | PASS |
| +12V power at 88 % mains with 2.5 A of motors / optos (V) (`v12u_min`) | 10.13 | 8.5 … 16 | PASS |
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

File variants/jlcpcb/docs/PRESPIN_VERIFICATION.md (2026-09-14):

> Historical JLC-2 investigation. For the current hardware and evidence, use [JLC-3 prototype report](PROTOTYPE_JLC3.md).

# Continued pre-spin verification — JLC-2

Subsequent results are in the [analog-review addendum](CONTINUED_ANALOG_REVIEW.md): the selected coil replay now has a completed convergence and energy-balance check. This page preserves the earlier review round, including its incomplete refinements. The regulator and lamp-matrix findings remain open.

This review follows the request to continue verification before a prototype order. Results below are software predictions under stated assumptions. No PCB, cabinet, harness, load or physical fault test has been performed.

**Recommendation: hold an assembled prototype order.** The flasher-clamp fault is corrected and the revised fabrication data passes consistency checks. Regulator voltage/backfeed findings and unresolved numerical convergence prevent a clean electrical sign-off. These need disposition before committing to the assembled board; physical qualification remains a separate later stage.

## Flasher correction

The Williams STTNG manual (printed 2-44 and 3-6/3-7) identifies outputs 20–28 as flashers, with one to four bulbs per channel. Outputs 17/18 are +12 V unregulated gun motors. The previous generic flasher check assumed a connected diode return; the STTNG harness leaves SOL21–SOL28 tieback contacts unused.

A new turn-off screen found that four hot lamps at 30 V with 100 µH of wiring inductance drove the original unclamped 100 V MOSFET model into avalanche, reaching 100.351 V. At 10 µH the same model reached 71.519 V. The assumed inductance range is a sensitivity, not a measurement of the user's harness; the avalanche model does not qualify device SOA.

JLC-2 connects the existing D5–D12 cathodes to +20 V with additional copper. The clamped four-lamp/100 µH comparison peaks at 31.429 V. No parts or footprints were added; sourcing and component placement remain unchanged. Native board, schematics and export labels now say JLC-2. The original JLC-1 archives are superseded.

**STTNG only:** J122 pins 5/6/8/9 and J126 pins 10/11/12/13 now carry +20 V. J126 pin 9 remains the key. This changes the accessible tieback contacts; do not use a harness that assigns another voltage to them. See `clamp-migration.json` for the exact net change. Original parent-project files remain preserved.

## Fresh ROM and logic coverage

PinMAME was built on this Linux machine from pinned commit `2e64cfa9f92955952489854a60ec23397294417e`, with only the passive register-write observer. The supplied `sttng_l7.zip` was used without ROM changes. The deterministic six-ball simulator ran for 240 seconds, completed normally and displayed gameplay with a score of 7,185,500 at 215 seconds. It exercised 25 used output channels, up to four at once, all seven driver registers and all five GI strings. No multiple-column lamp writes were observed. It is finite gameplay coverage, not every game mode or mechanical failure.

The separate 320-second MAME diagnostic trace exercises 27 used output channels. Channel 19 is unused on STTNG. An attempted ordinary MAME gameplay run remained in attract mode; its files are retained and it is not counted as gameplay verification.

`verify_rom_logic.py` walks the actual netlist connections through the active-low ribbon data, HCT240 inverter, clocked HCT574/HCT74 storage and transistor-drive resistor paths to external output pins. It compares 503,067 diagnostic writes and 454,826 gameplay writes with the independent WPC address/pin map. All 957,893 comparisons pass. Another 1,568 directed checks cover unknown latched contents under BLANKING, writes while blanked, disconnected CPU writes, release/clear ordering and individual asynchronous row clears.

PinMAME's `WPC_ZC_IRQ_ACK` implementation explicitly does not emulate the watchdog. The directed tests inject BLANKING and verify downstream behavior; they cannot establish that the physical CPU generates BLANKING correctly. Releasing BLANKING exposes retained latch contents, so firmware must clear outputs before enabling them. Power sequencing below the HCT guaranteed operating range remains a physical measurement gate.

## Expanded SPICE work

Reports and generated decks are under `output/verification/prespin/`.

| Area | Completed result | Practical scope |
|---|---|---|
| Active-load BLANKING | 8 cases / 96 checks pass | 4.5/5.2 V logic, 0.8/2.0 V threshold extremes, 50/60 Hz, 280 pF line/input allowance. Coil and column currents fall after disable; GI stops by the subsequent current zero. Explicit zero writes precede re-enable. |
| Gameplay coils | 14 active channels pass at 5 µs | Worst ten-second windows, 86 V, cold coil resistance, hot MOSFET fit. Finer-step heating investigation is recorded separately. |
| Flashers | 9 channels pass | Actual STTNG bulb counts, thermal heating/cooling envelope, 30 V and 100 µH wiring, corrected clamp returns. One four-bulb case repeated at 2.5 µs. |
| Gun motors | 16 cases pass | Two channels, 8/16 Ω, 0/8 V back EMF, two EMI choke assumptions (4.7 µH and 4.7 mH), 10 mH winding. The manual's EMI diode is in series, not a flyback diode. |
| GI | 20 cases pass | Five recorded gate streams, four AC phase offsets; 18-lamp engineering envelope, approximate triac model. Maximum modeled junction temperature about 104.45 °C. |
| Full 8×8 lamp matrix | 41 checks pass with KLU | Actual ROM row/column writes, 64 diode/thermal-filament paths, eight physical row and column driver models; monitored comparator clears. Initial duplicate-name fixture error and SPARSE convergence failure retained; electrical models unchanged. |
| Full-input regulator sequencing | 6 complete: 1 pass, 5 fail | TI switching model with AC secondary, winding resistance, four rectifiers, ESR and minimum reservoir capacitance; AC interruption/restart rather than an imposed sinking DC input. See the individual findings below. |

The 8 Ω simultaneous motor-stall envelope can exceed the shared 3 A fuse. Passing transistor stress does not mean indefinite stalled operation is supported. Motor R/L/back EMF and EMI choke values have not been measured. The flasher lamp resistance/thermal parameters likewise remain engineering envelopes.

The selected GI time window maximizes gate-command duty; it is not a proof of the hottest possible phase-control waveform. Four phase offsets sample the uncertainty between emulator timing and the physical zero-cross detector. Real trigger quadrant, commutation, EMI and heatsink temperature require measurement.

## Numerical convergence remains open

The initial 5 µs versus 2.5 µs gameplay comparison passes 11 of 12 criteria. Coil 1's modeled temperature changes from 80.585 °C to 76.535 °C, a 4.050 °C difference against the unchanged 4.029 °C limit. Its drain voltage and coil current agree closely. A completed 0.625 µs run gives 70.158 °C. This trend leaves a substantial screening margin below 125 °C, but does not establish converged dissipation or semiconductor SOA.

An independent closed-form R–L calculation passes for all fourteen active gameplay coil channels. It uses the same ROM edge times with a 15 mΩ hot MOSFET resistance assumption. Coil 1's peak is 22.661 A versus approximately 22.676 A in SPICE; its conduction-only loss is 0.1622 W. Maximum conduction-only temperature across the fourteen channels is 63.406 °C. Switching/recovery loss, saturation and mutual heating are excluded, so this cross-check does not close the total-loss convergence finding.

Separately measuring MOSFET channel and body-diode carrier loss, excluding reactive capacitor current, changes the estimated dissipation from 0.409674 W at 5 µs to 0.225823 W at 0.625 µs. Both measures are retained; the difference remains unresolved. Full-window 1.25 µs and 0.3125 µs runs and Gear/KLU alternatives abort. Extreme currents in aborted numerical trials are not treated as physical predictions.

Additional trials shorten only fully settled OFF intervals, preserving the actual ROM pulse widths and at least 100 ms between bursts, and average energy over the original ten seconds. These investigate timestep behavior without changing the circuit. They include the unmodified Diodes Inc S3M model as a separate comparison and tighter solver tolerances. Every completed and aborted trial is retained in `convergence-review.json`; partial-transient measurements cannot pass the completion gate.

The 0.078125 µs refinement was manually interrupted after confirmed numerical time stagnation: the stored point count grew from 36,141,862 to 37,007,060 while the last timestamp remained exactly 0.11920896100388931 s, short of the required 0.8062335 s. The separate manufacturer-diode comparison was also interrupted after approximately one hour, at 0.608892 s of 0.8062335 s. **That vendor-model run was still advancing**; its interruption is a runtime limit, not evidence of a solver or component failure. Both remain incomplete, with no full-window loss or temperature pass claimed. The interrupt records and original partial reports are retained in `replay-loss-segments/runtime-stops.json`.

The full lamp matrix completes at 2 µs with KLU and passes its 41 checks. Both the 1 µs refinement and its stricter-tolerance trial abort. The completed result is useful screening evidence, but **fine-step matrix convergence is not established**. No check limit or device parameter was relaxed to mark these refinements as passes.

## Regulator interruption and reverse power

The new full-input fixtures include the AC secondary, winding resistance, four Schottky rectifiers, ESR and minimum reservoir capacitance. They interrupt AC from 25 to 85 ms and run through 120 ms; the raw reservoir discharges through the circuit instead of being forcibly clamped by a sinking voltage source. Low line is 90% of the assumed nominal secondary, with 8,000 µF on the +5 V raw input and 16,000 µF on the +12 V raw input. The latter also carries a 2.5 Ω raw lamp-load envelope. Output loads are resistors sized for the stated current at nominal voltage; they are not complete models of the CPU and other connected boards during reset. These are assumed source/load conditions, not measured transformer parameters.

A separate 254-check audit matches the saved fixtures to the final netlist: regulator port order, feedback/UVLO/compensation R/C values and connections, inductor and output capacitor values, catch-diode identity/polarity, and the actual raw-rail bridge/reservoir assignment. All pass. Explicit ESR/DCR nodes are collapsed only for connectivity matching; their numerical values and the external source/load remain stated model assumptions.

The voltage screens are +5 V peak ≤5.25 V and final five-millisecond average 4.95–5.20 V; +12 V peak ≤12.60 V and final average 11.40–12.60 V. They also reject negative output below −0.3 V, reverse inductor current below −1 A, excessive forward current and incomplete transients. The reverse-current threshold is an engineering screen, not a vendor SOA rating.

All six full-input transients complete without a simulator error. The +5 V nominal 3 A loss/restart case passes every screen: 5.131 V peak, 5.103 V final average and −0.013 A minimum inductor current. Its final three-cycle output range is 5.097–5.115 V. The other five cases fail the criteria listed below.

| Rail / nominal load | Scenario | Peak output | Minimum inductor current | Final 5 ms average | Screen |
|---|---|---:|---:|---:|---|
| +5 V / 3 A | AC loss/restart | 5.131 V | −0.013 A | 5.103 V | PASS |
| +12 V / 20 mA | AC loss/restart | 12.819 V | −0.700 A | 11.496 V | FAIL: peak |
| +12 V / 0.75 A | AC loss/restart | 12.785 V | −0.068 A | 11.841 V | FAIL: peak |
| +12 V / 2 A | AC loss/restart, overload | 12.669 V | −0.029 A | 11.294 V | FAIL: peak and final average |
| +5 V / 1 A | Precharged output | 5.119 V | −19.709 A | 5.104 V | FAIL: reverse current |
| +12 V / 0.75 A | Precharged output | 12.596 V | −48.056 A | 11.875 V | FAIL: reverse current and negative output |

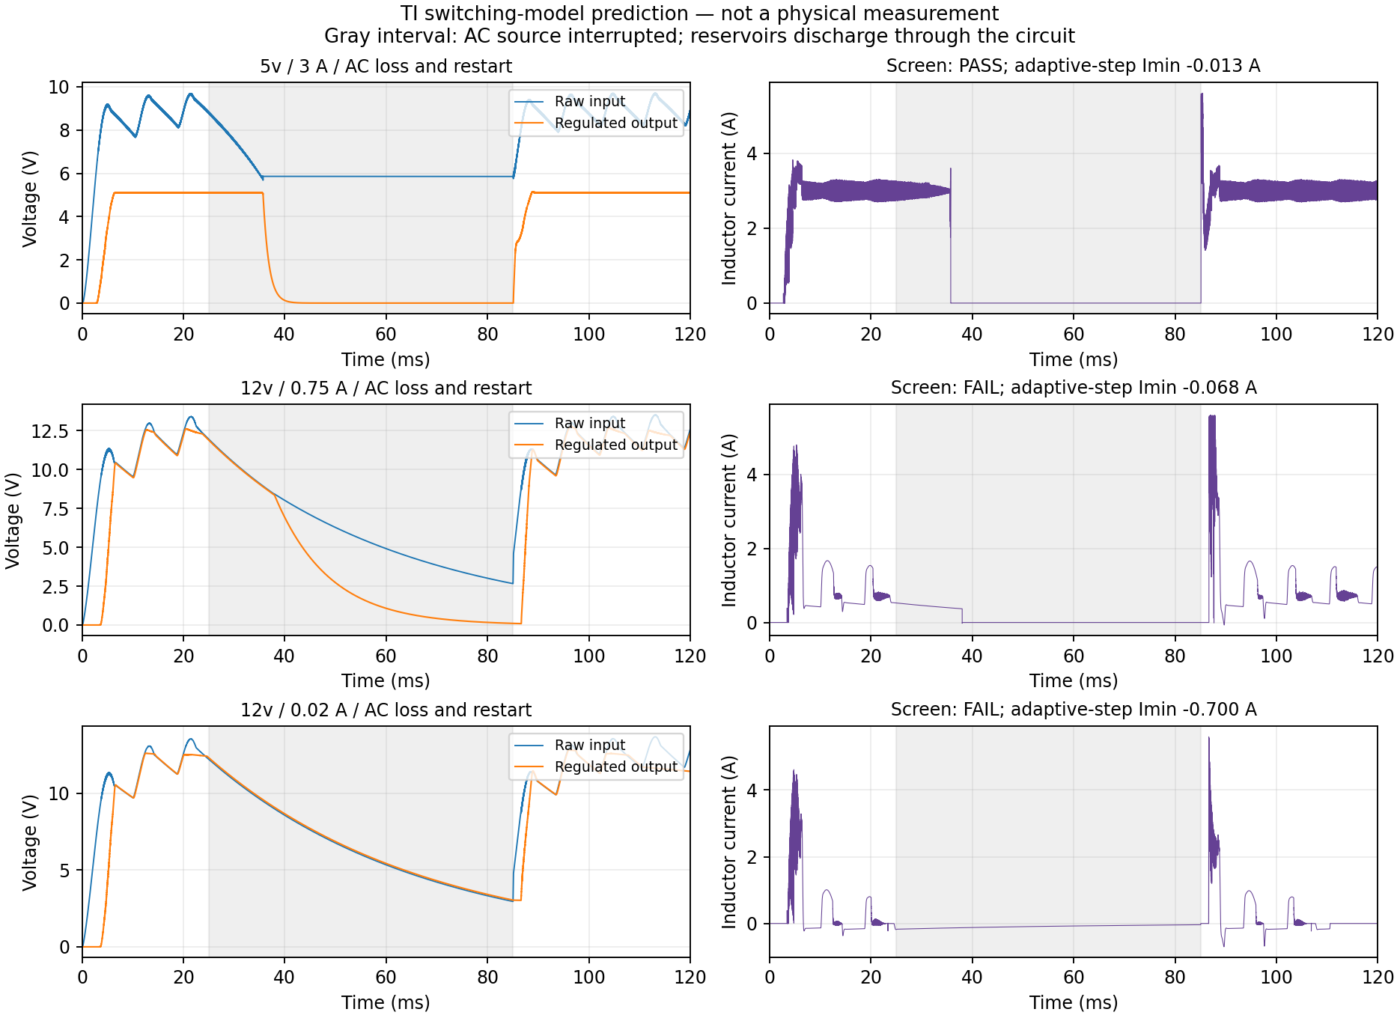
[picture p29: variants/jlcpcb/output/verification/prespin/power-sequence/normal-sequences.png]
Intended-load interruption and restart predictions


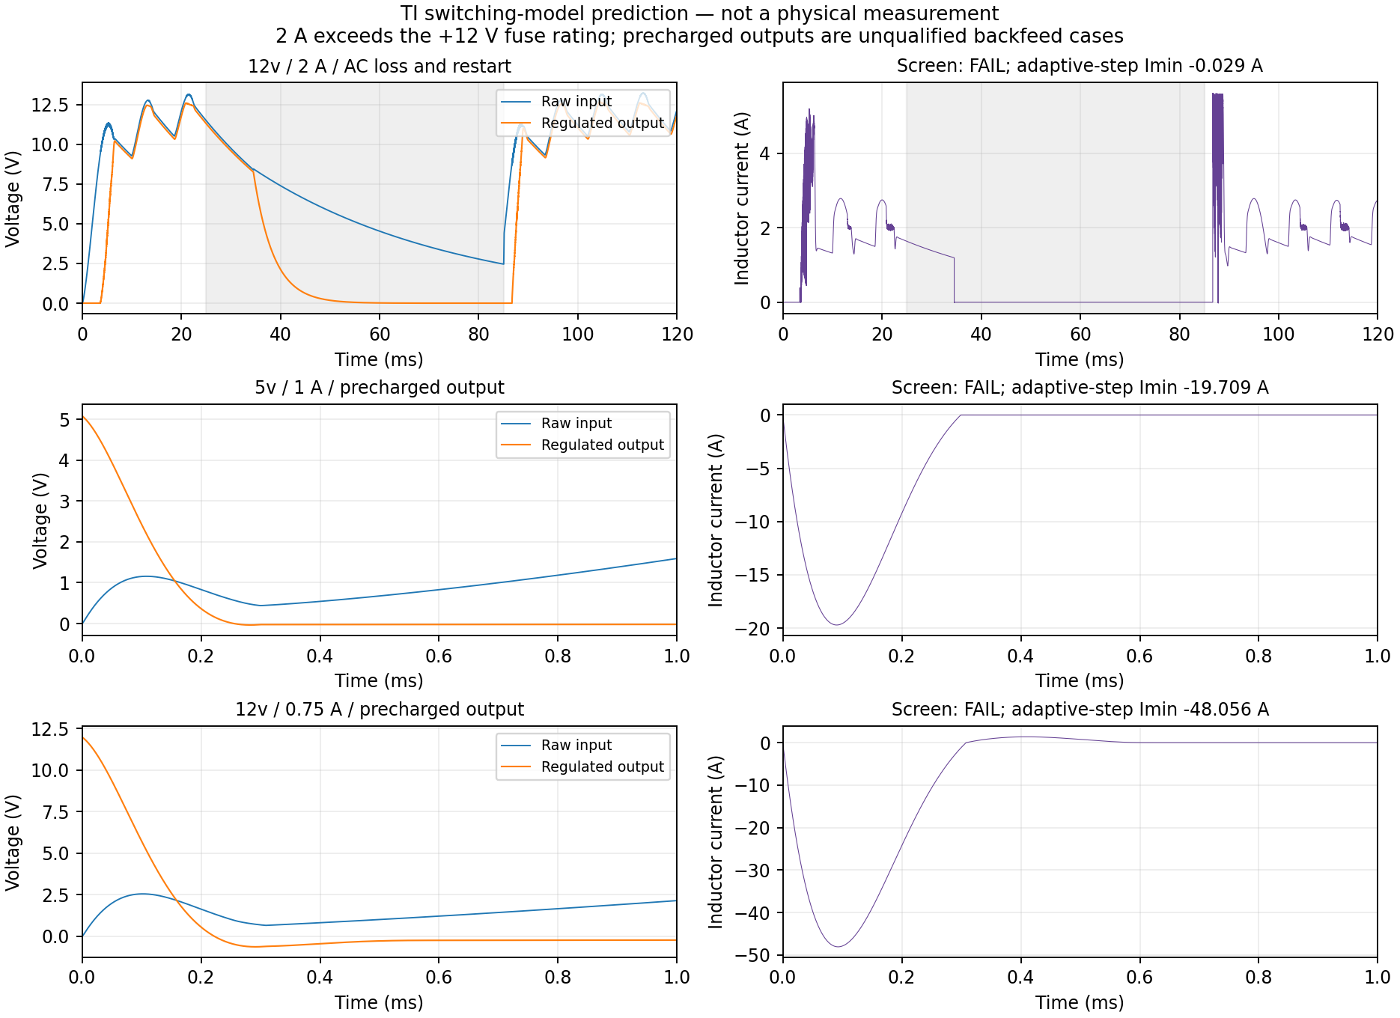
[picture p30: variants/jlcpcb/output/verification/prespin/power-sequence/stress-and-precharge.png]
Overload and precharged-output predictions


The precharged-output cases begin with the regulated output capacitors charged and the raw reservoir empty, then apply AC. Both complete numerically, predicting approximately −19.709 A in the +5 V inductor and −48.056 A in the +12 V inductor. The latter output also reaches approximately −0.636 V. These fail the retained limits. This is an unqualified reverse-power condition; the model does not establish the real failure current or survival time. The rail capacitors, ESR and inductor path are present in the fixture, so the result cannot be dismissed solely as the earlier ideal sinking-source artifact.

Both intended +12 V loss/restart cases complete but fail the peak-voltage screen: 12.819 V at 20 mA and 12.785 V at 0.75 A. Their final averages recover within the 11.40–12.60 V limits. The 20 mA maximum occurs near 96.024 ms. The +12 V 2 A stress case peaks at 12.669 V and recovers to an 11.294 V final average; 2 A exceeds that rail's 0.75 A fuse rating and is not an intended continuous load. The final summary records every failed check.

The original final-five-millisecond averages do not describe the full ripple cycle. Over 95–120 ms (three rectified line cycles), the +12 V output ranges from 11.295 to 12.819 V at 20 mA and from 10.918 to 12.785 V at 0.75 A. The latter raw input falls to approximately 10.991 V, leaving insufficient headroom for a buck converter to maintain 12 V. These supplementary observations use the saved 1 µs samples; they preserve the original tests and reveal their limited averaging window. The assumed heavy lamp load, transformer impedance, actual downstream voltage tolerance and dropout/recovery behavior need disposition together.

The `body_reverse_peak` output is instantaneous diode terminal current including displacement current; it is not a separately qualified carrier-current or SOA measurement. Use the inductor-current results and saved waveforms for the reverse-power finding. Exact source files and manufacturer download URLs are identified in `research/vendor-model-sources.json`.

## Revised-board checks

Fresh ERC and DRC have zero errors, zero open connections and zero schematic-parity issues. All 77 warnings have an explicit geometry review. Independent filled-copper analysis verifies 1,393 pads on 363 nets. The source audit checks 10,997 conditions, including the documented clamp-net changes and preservation of original files. The 2,188 static interface checks include the nine connected flasher clamps. Independent Gerber/drill/BOM/CPL parsing passes. Mechanical model inputs are byte-identical to the previously checked 425-instance assembly; no new physical bodies were introduced.

The refreshed +5 V copper model predicts 30.338 mV drop at 3 A and 75 °C on the finer 0.25 mm mesh. The refreshed thermal screening peaks at 121.148 °C, below its 125 °C target, but the small model margin must be correlated on hardware.

## Remaining physical work

Use the staged first-article procedure in `ASSEMBLY_AND_FIRST_ARTICLE.md`. Begin with isolated, current-limited inputs and dummy loads. Verify regulation, actual shutdown/restart currents, physical BLANKING and partial-power behavior before connecting the CPU or playfield. Do not externally energize regulated outputs while their raw inputs are low; reverse-power survival is not qualified. Establish real load/current/temperature and fuse-clearing limits, then verify harness and cabinet fit. None of these physical tests can be replaced by a passing simulator report.

Primary references: [Williams STTNG operations manual](https://archive.org/download/arcademanual_Star_Trek_TNG_OPS/Star_Trek_TNG_OPS.pdf), [pinned PinMAME source](https://github.com/vpinball/pinmame/tree/2e64cfa9f92955952489854a60ec23397294417e), [TI reverse-power guidance](https://e2e.ti.com/support/power-management-group/power-management/f/power-management-forum/1308507/tps54360b-power-output-without-input-in-test-environment). Exact local inputs, commands and hashes accompany the reports; the ROM and manual are not redistributed.

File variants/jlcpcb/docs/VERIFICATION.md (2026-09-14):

> Current revision: JLC-3. See [prototype changes and current evidence](PROTOTYPE_JLC3.md); historical regulator results below describe the superseded JLC-2 circuit. Use the current exported BOM.

# JLC-2 verification

Fresh Linux verification uses KiCad 10.0.6, ngspice 47, the supplied STTNG L7 ROM and the final routed JLC-2 native source. Exact inputs and report hashes are bound by `output/release-candidate/reports/verification-manifest.json`. No previous Mac run is presented as fresh evidence.

The additional pre-spin review found and corrected disconnected flasher-clamp returns, producing JLC-2. See [continued verification](PRESPIN_VERIFICATION.md) for fresh PinMAME gameplay, netlist-driven ROM logic, auxiliary outputs and regulator-sequence investigations. The earlier failed fixtures are retained.

The [subsequent analog-review addendum](CONTINUED_ANALOG_REVIEW.md) establishes convergence of the selected coil replay and adds an energy balance, 72 source-headroom cases and 16 CPU switch-margin cases. Its input-isolation proposal is unbuilt; the native board and the original JLC-2 archives are unchanged.
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

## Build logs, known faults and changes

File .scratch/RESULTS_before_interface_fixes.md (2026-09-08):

# SPICE verification results - cost-optimised board

ngspice (KiCad 10 bundled libngspice) transient runs of each circuit block; MOSFET/diode models in `tools/spice/models.lib` are level-1 fits to datasheet Rds(on)/Qg
(functional fidelity, not vendor-exact); the TPS54360B is a behavioural peak-current-mode model (12 A/V, 4.5 A minimum current limit, 400 kHz). Waveform CSVs are next to this file.
Each limit is explained in its description column (see also README.md).

## buck_12v

| measurement | value | expected | result |
|---|---|---|---|
| steady-state output at 1 A (V) (`vout_ss`) | 11.93 | 11.8 … 12.2 | PASS |
| output ripple p-p at 1 A (V) (`vout_ripple`) | 0.04351 | 0 … 0.1 | PASS |
| undershoot on a 1 -> 2 A load step (V): 11.4 V keeps the switch matrix / CPU +12V loads (LM7805 pre-regulators, opto emitters) happy (`vout_step_min`) | 11.82 | 11.4 … 12.2 | PASS |
| overshoot on the 2 -> 1 A step (V) (`vout_step_max`) | 12.03 | 11.8 … 12.6 | PASS |
| peak inductor current at 2 A from 15.7 V (A): below the 4.5 A minimum current limit (`il_peak`) | 3.282 | 2 … 4.3 | PASS |
| output at 2 A (V) (`vout_2a`) | 11.92 | 11.8 … 12.2 | PASS |
| input current at 2 A out from 15.7 V (A) (`iin_2a`) | -1.549 | -2.2 … -1 | PASS |

## buck_5v

| measurement | value | expected | result |
|---|---|---|---|
| steady-state output at 1 A (V) (`vout_ss`) | 5 | 4.9 … 5.1 | PASS |
| output ripple p-p at 1 A (V) (`vout_ripple`) | 0.02705 | 0 … 0.08 | PASS |
| undershoot on a 1 -> 3 A load step (V): 4.6 V is the 74HCT / CPU-board minimum with margin (`vout_step_min`) | 4.898 | 4.6 … 5.1 | PASS |
| overshoot on the 3 -> 1 A step (V) (`vout_step_max`) | 5.092 | 4.9 … 5.4 | PASS |
| peak inductor current at 3 A (A): must stay below the 4.5 A minimum current limit of the TPS54360B (SRP1265A-100M rated 10 A) (`il_peak`) | 3.65 | 3 … 4.3 | PASS |
| output at 3 A (V) (`vout_3a`) | 4.986 | 4.9 … 5.1 | PASS |
| input current at 3 A out from 8 V (A, negative = drawn from Vin) (`iin_3a`) | -2.026 | -3 … -1.5 | PASS |

## flasher

| measurement | value | expected | result |
|---|---|---|---|
| cold-lamp inrush (A) (`ilamp_inrush`) | 6.615 | 3 … 8 | PASS |
| hot lamp current (A) (`ilamp_hot`) | 1.111 | 0.7 … 1.4 | PASS |
| IRLR3110Z Vds with the lamp on (V): 1.1 A x 18 mOhm = 0.02 V (`vsat`) | 0.02035 | 0 … 0.1 | PASS |

## gi_gate

| measurement | value | expected | result |
|---|---|---|---|
| triac gate current (A) - above the 50 mA worst-case Q IV Igt of the BTA16-600C (`ig_peak`) | 0.07841 | 0.06 … 0.13 | PASS |
| string current before trigger (A) (`istr_off`) | 6.092e-06 | 0 … 0.05 | PASS |
| string current while enabled (A peak) (`istr_on`) | 6.138 | 4 … 8 | PASS |
| string current after latch released (A) (`istr_after`) | 8.9e-06 | 0 … 0.3 | PASS |
| MMBT4401 dissipation (W, SOT-23 limit 0.31 W) (`p_npn`) | 0.1245 | 0 … 0.25 | PASS |
| base current sourced by the 74HCT574 (A, negative = out of the latch) (`i_latch`) | -0.003665 | -0.004 … -0.0001 | PASS |

## lamp_matrix

| measurement | value | expected | result |
|---|---|---|---|
| row current, normal lamp incl. cold inrush (A) (`irow_normal`) | 2.438 | 0.3 … 3.5 | PASS |
| sense voltage stays below the 1.4 V trip (V) (`vsense_normal`) | 0.5026 | 0 … 1.3 | PASS |
| 1.4 V reference (V) (`vref`) | 1.29 | 1.2 … 1.6 | PASS |
| column IRFR5305 drop with the lamp on (V): ~2 A x 65 mOhm = 0.13 V; 0.3 V = 150 mOhm (hot, low Vgs) (`vcol_drop`) | 0.1205 | 0 … 0.3 | PASS |
| row driver drop incl. the 0.22 R sense resistor (V): 2 A x (0.22 + 0.08) = 0.6 V; 0.8 V keeps > 17 V on the 18 V lamp string (`vrow_on`) | 0.6228 | 0 … 0.8 | PASS |
| comparator never clears the row flip-flop in normal operation (V) (`clr_min`) | 4.999 | 3 … 5.5 | PASS |
| column MOSFET Vgs from the 1k/1.5k divider (V): IRFR5305 needs <= -7 V for its rated 65 mOhm (`vgs_col`) | -10.8 | -13 … -7 | PASS |

## lamp_matrix_trip

| measurement | value | expected | result |
|---|---|---|---|
| shorted lamp: row current exceeds the 6.4 A trip (A) (`irow_fault`) | 8.365 | 6.4 … 80 | PASS |
| row flip-flop cleared (s): short applied at 32.5 ms, column strobe (fault current) starts at 33.0 ms -> cleared within 0.2 ms (`t_trip`) | 0.03316 | 0.033 … 0.0332 | PASS |
| row current after shutdown until the next strobe (A) (`irow_after`) | 0.002529 | 0 … 0.5 | PASS |
| fault current returns at the next strobe and trips again (A) - per-strobe shutdown as in the original (`irow_next`) | 8.365 | 2 … 80 | PASS |

## psu

| measurement | value | expected | result |
|---|---|---|---|
| +18V lamp rail average at 2.8 A / 5 ohm (V): the lamp matrix needs >= 13 V for full brightness (`v18_avg`) | 13.98 | 13 … 20 | PASS |
| +18V ripple p-p with 2 x 10000 uF (V): 3 V = 20 % of the rail, the largest brightness flicker acceptable at 120 Hz (`v18_ripple`) | 0.7756 | 0 … 3 | PASS |
| +5V buck input minimum at 3 A output with 10000 uF (V): TPS54360B needs 5.6 V for 5 V out, the 6.0 V UVLO start + 0.5 V (`vin5_min`) | 8.336 | 6.5 … 14 | PASS |
| +5V raw ripple p-p (V): 10000 uF at ~3.9 A input current -> ~2.5 V; must stay below vin5_min - 5.6 V headroom (`vin5_ripple`) | 1.027 | 0 … 3.5 | PASS |
| +5V minimum at 3 A load (V) (`v5_min`) | 5 | 4.95 … 5.05 | PASS |
| +50V idle (V) (`v50_idle`) | 48.82 | 45 … 55 | PASS |
| +50V average during a 12 A coil pulse with 4400 uF (V) - unchanged from the modern board (`v50_avg_pulse`) | 38.05 | 38 … 50 | PASS |
| +50V minimum during the pulse (V) (`v50_min_pulse`) | 31.96 | 30 … 50 | PASS |
| peak coil current (A) (`icoil_max`) | 9.912 | 9 … 14 | PASS |
| +20V minimum during a 4 A flasher burst with 10000 uF (V): the +12V buck needs >= 12.9 V (Vout + Vf + Rds Iout) to stay in regulation (`v20_min`) | 15.22 | 13 … 22 | PASS |
| +20V ripple p-p during the burst (V) (`v20_ripple`) | 2.557 | 0 … 3 | PASS |
| +12V minimum during the flasher burst (V) (`v12_min`) | 12 | 11.95 … 12.05 | PASS |
| +12V maximum (V) (`v12_max`) | 12 | 11.95 … 12.05 | PASS |

## psu_brownout

| measurement | value | expected | result |
|---|---|---|---|
| +5V buck input minimum at 88 % mains and the rated 3 A (V): must stay above the UVLO stop level - 5.5 V nominal, 6.0 V worst case (Vena 1.3 V) - so the converter keeps regulating (sweep: output/spice/uvlo_sweep.md) (`vraw_min`) | 6.482 | 6 … 12 | PASS |
| +5V holds through an 88 % brownout at 3 A (V) - the LM323K needed 7.5 V raw and would have dropped out (`v5_min`) | 5 | 4.95 … 5.05 | PASS |
| +20V minimum at 88 % mains with 8 flashers hot and 10000 uF (V): above the 9.1 V worst-case UVLO stop of the +12V buck (`v20_min`) | 11.35 | 9.5 … 22 | PASS |
| +12V at 88 % mains with flashers hot (V): droops (0.97 Vin - 0.5) when +20V is under 12.9 V; 10 V still runs the switch-matrix / opto loads and the CPU-board 5 V pre-regulators (`v12_min`) | 10.51 | 10 … 12.05 | PASS |

## psu_maxload

| measurement | value | expected | result |
|---|---|---|---|
| +18V minimum with all 64 lamps lit (2.5 ohm, ~5.5 A) and 2 x 10000 uF (V): lamps stay usable above ~10 V (`v18_min`) | 12.01 | 10 … 20 | PASS |
| +5V buck input minimum with everything on (V): converter needs 5.6 V, worst-case UVLO stop 6.0 V (`vin5_min`) | 8.336 | 6 … 14 | PASS |
| +5V minimum at 3 A with everything on (V) (`v5_min`) | 5 | 4.95 … 5.05 | PASS |
| +20V minimum during the 8-flasher cold inrush with 10000 uF (V): must stay above the 8.5 V UVLO stop of the +12V buck (9.1 V worst case) (`v20_min`) | 10.95 | 9 … 22 | PASS |
| combined cold inrush of 8 flashers (A) - within the F111 5 A slow-blow 40 ms envelope (`iflash_peak`) | 50.89 | 20 … 60 | PASS |
| +12V minimum during the flasher inrush (V): the buck droops (never shuts down) when +20V is below 12.9 V; 8 V keeps the CPU-board 5 V pre-regulators alive (`v12_min`) | 10.12 | 8 … 12.05 | PASS |
| +50V average with 2 HP + 4 LP coils fired together (V) - informational, an unrealistic firmware case; parts unchanged from the modern board (`v50_avg_pulse`) | 27.68 | 20 … 50 | PASS |
| total coil current, six coils at once (A) (`itot50_max`) | 31.21 | 20 … 60 | PASS |
| peak current through the +50V bridge (A): GBPC3510 surge rating 400 A (this is a single 40 ms event) (`ibr50_peak`) | 60.89 | 0 … 400 | PASS |
| repetitive peak current in the +18V GBJ1510 with all lamps lit (A): capacitor-input rectifiers run at 3-5 x Io, limit 4 x the 15 A rating; surge rating 240 A (`ibr18_peak`) | 17.66 | 0 … 60 | PASS |
| peak current in the +20V GBJ1510 during the flasher inrush (A): 4 x the 15 A rating for the repetitive part; the 240 A surge rating covers the first cycles (`ibr20_peak`) | 32.01 | 0 … 60 | PASS |
| repetitive peak current in the +5V-raw GBU8J at 3 A output (A): 4 x the 8 A rating; surge rating 200 A (`ibr5_peak`) | 7.681 | 0 … 32 | PASS |

## sol_high

| measurement | value | expected | result |
|---|---|---|---|
| coil current with 4 ohm coil on 50 V (A) (`icoil_max`) | 12.44 | 9 … 13.5 | PASS |
| IRLR3110Z Vds while ON (V): 12 A x 18 mOhm = 0.22 V; 0.3 V = 25 mOhm, above the 4.5 V datasheet max incl. heating (`vout_on`) | 0.2315 | 0 … 0.3 | PASS |
| output clamped by the S3M tie-back diode (V) (`vout_peak`) | 51.35 | 49 … 53 | PASS |
| MOSFET dissipation during the pulse (W): 2.6 W for 40 ms is 0.1 J into the DPAK die/tab (~0.2 C/J x 40 ms ... < 5 C rise); pulsed at <= 10 % duty the average stays < 0.4 W (`p_fet`) | 2.88 | 0 … 3.5 | PASS |

## sol_low

| measurement | value | expected | result |
|---|---|---|---|
| coil current with 9 ohm coil on 50 V (A) (`icoil_max`) | 5.544 | 3.5 … 6 | PASS |
| IRLR3110Z Vds while ON at 4.6 V gate drive (V): 5.5 A x 18 mOhm = 0.1 V, limit = 2x model (36 mOhm, the datasheet max at 4.5 V is 16 mOhm) (`vce_on`) | 0.1022 | 0 … 0.2 | PASS |
| drain voltage clamped by the S1M tie-back diode at turn-off (V) (`vcol_peak`) | 51.41 | 49 … 53 | PASS |
| steady current drawn from the 74HCT574 output (A) (`i_latch`) | 0.0004536 | -0.001 … 0.001 | PASS |
| coil current 15 ms after turn-off (A) (`icoil_off`) | 1.882e-07 | -0.01 … 0.05 | PASS |
| MOSFET dissipation while ON (W): 1 W continuous is what a DPAK on 1 sq. in. of copper (~50 C/W) can hold at 50 C rise (`p_fet`) | 0.5664 | 0 … 1 | PASS |

## zero_cross

| measurement | value | expected | result |
|---|---|---|---|
| +12VU average (V) - only feeds the LED/test point (`vu_avg`) | 11.81 | 10 … 16 | PASS |
| +12VU ripple p-p (V) (`vu_ripple`) | 0.3082 | 0 … 2 | PASS |
| ZC output low level (V) (`zc_low`) | 0.09804 | 0 … 0.5 | PASS |
| sample node minimum (V, must stay > -0.3 for LM339) (`smp_min`) | 1.226e-05 | -0.35 … 0.3 | PASS |
| ZC low-pulse width (s) (`zc_width`) | 0.001272 | 0.0003 … 0.002 | PASS |
| pulse centre vs true zero crossing (s) (`zc_center_err`) | 2.115e-05 | -0.0005 … 0.0005 | PASS |

**Overall: ALL CHECKS PASS**

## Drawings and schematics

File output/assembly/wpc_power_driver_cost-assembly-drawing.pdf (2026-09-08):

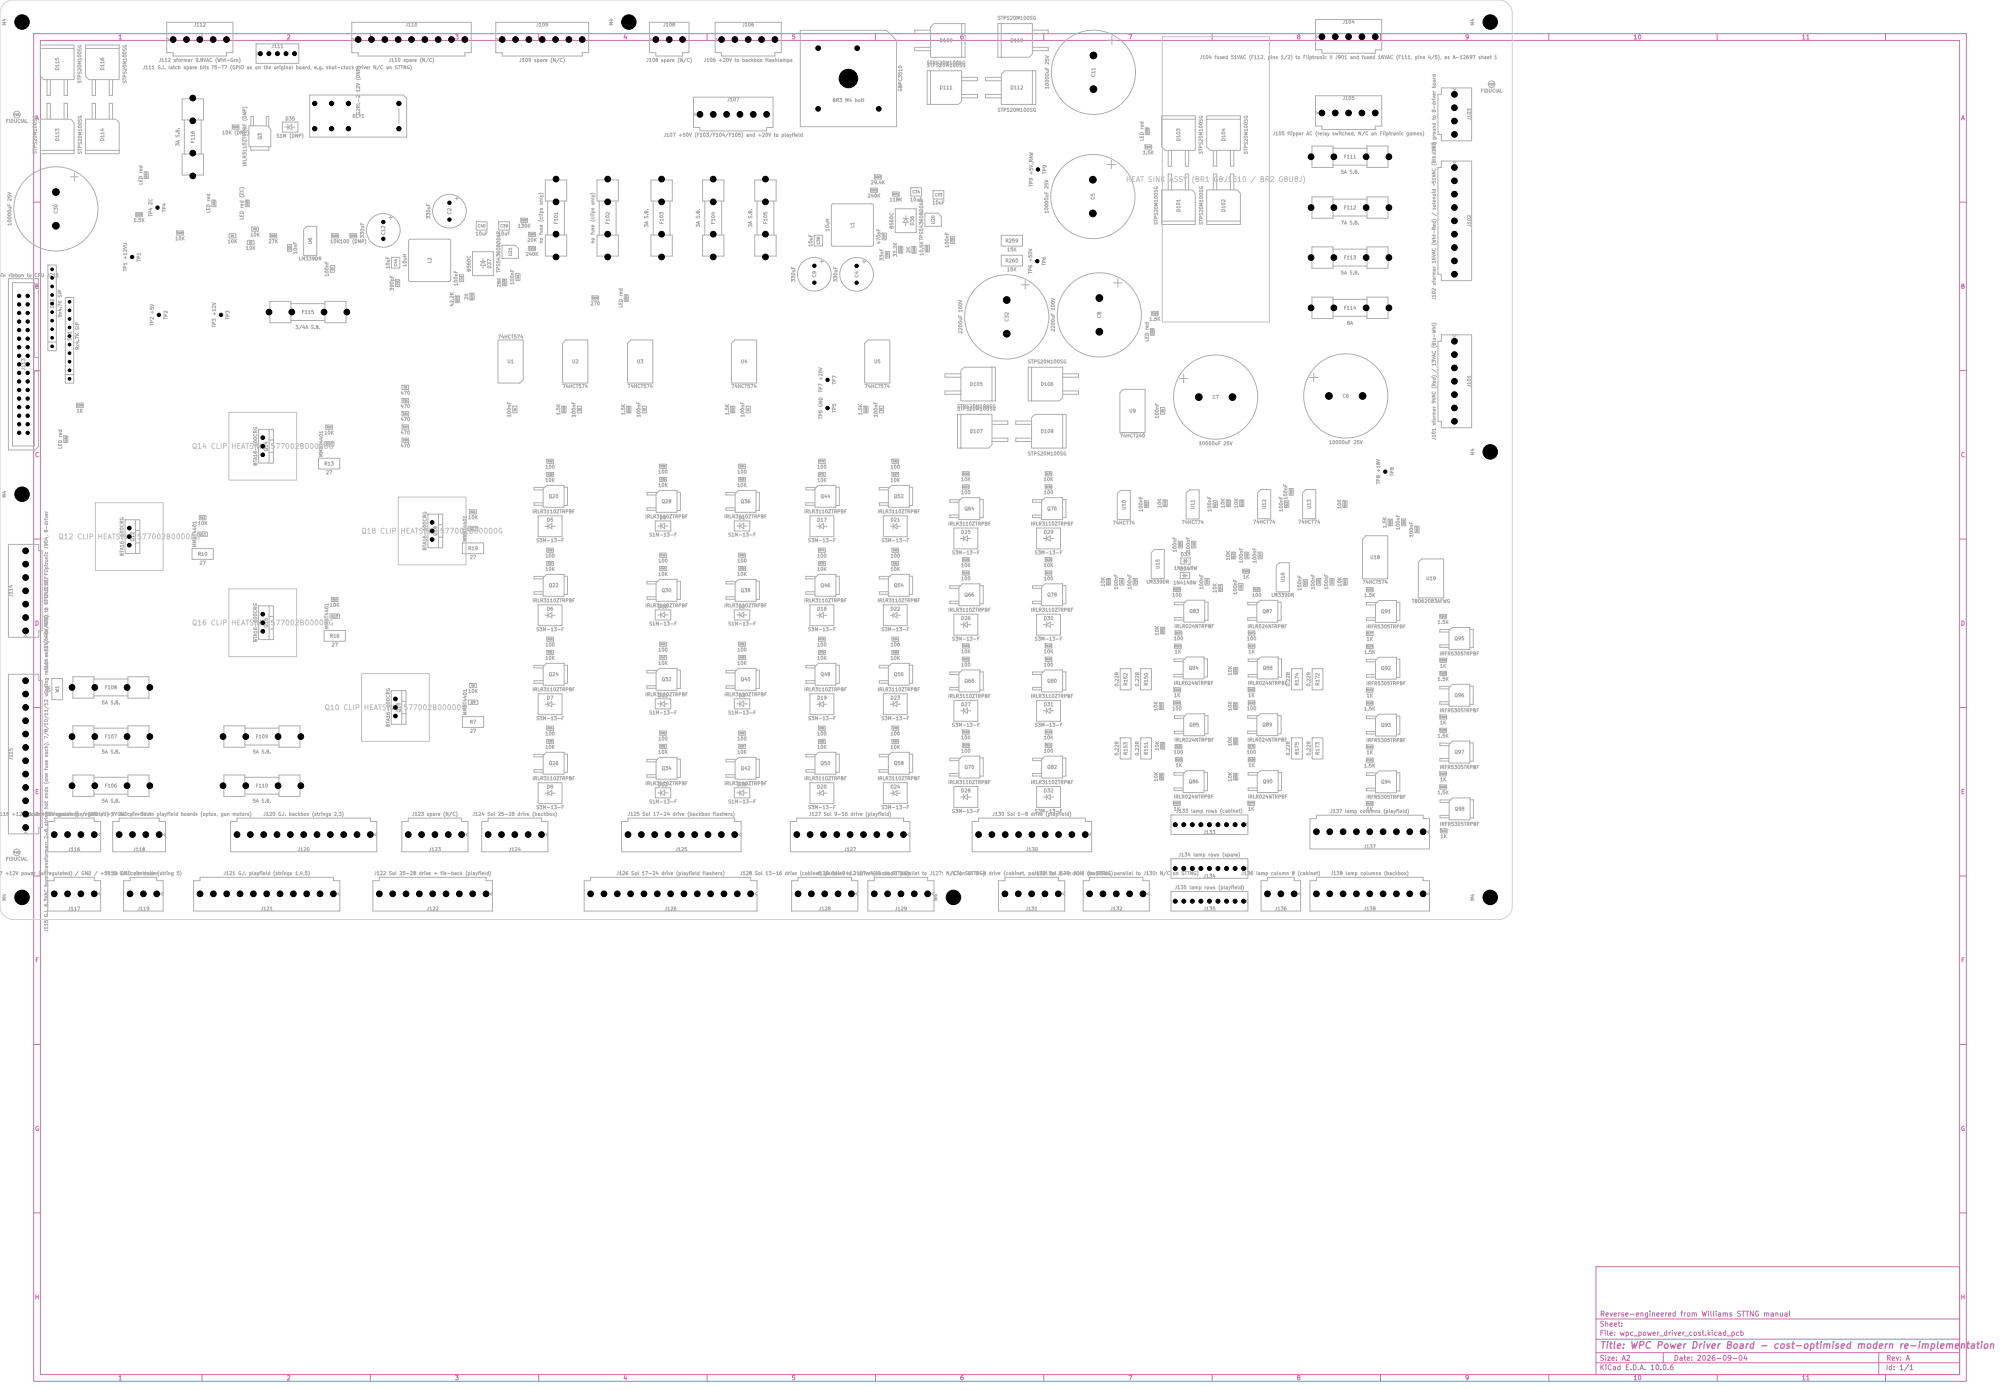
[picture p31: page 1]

J105 flipper AC (relay switched, N/C on Fliptronic games) J105

R139 J117 +12V power (unregulated) / GND / +5V to DMD controller J117

R189 J128 Sol 13-16 drive (cabinet, parallel to J127; N/C on STTNG) J128

J125 Sol 17-24 drive (backbox flashers) J125

J126 Sol 17-24 drive (playfield flashers) J126

Reverse-engineered from Williams STTNG manual
Sheet:
File: wpc_power_driver_cost.kicad_pcb
Title: WPC Power Driver Board - cost-optimised modern re-implementation (A-12697-3 form factor)

Size: A2 | Rev: A
KiCad E.D.A. 10.0.6 | Id: 1/1

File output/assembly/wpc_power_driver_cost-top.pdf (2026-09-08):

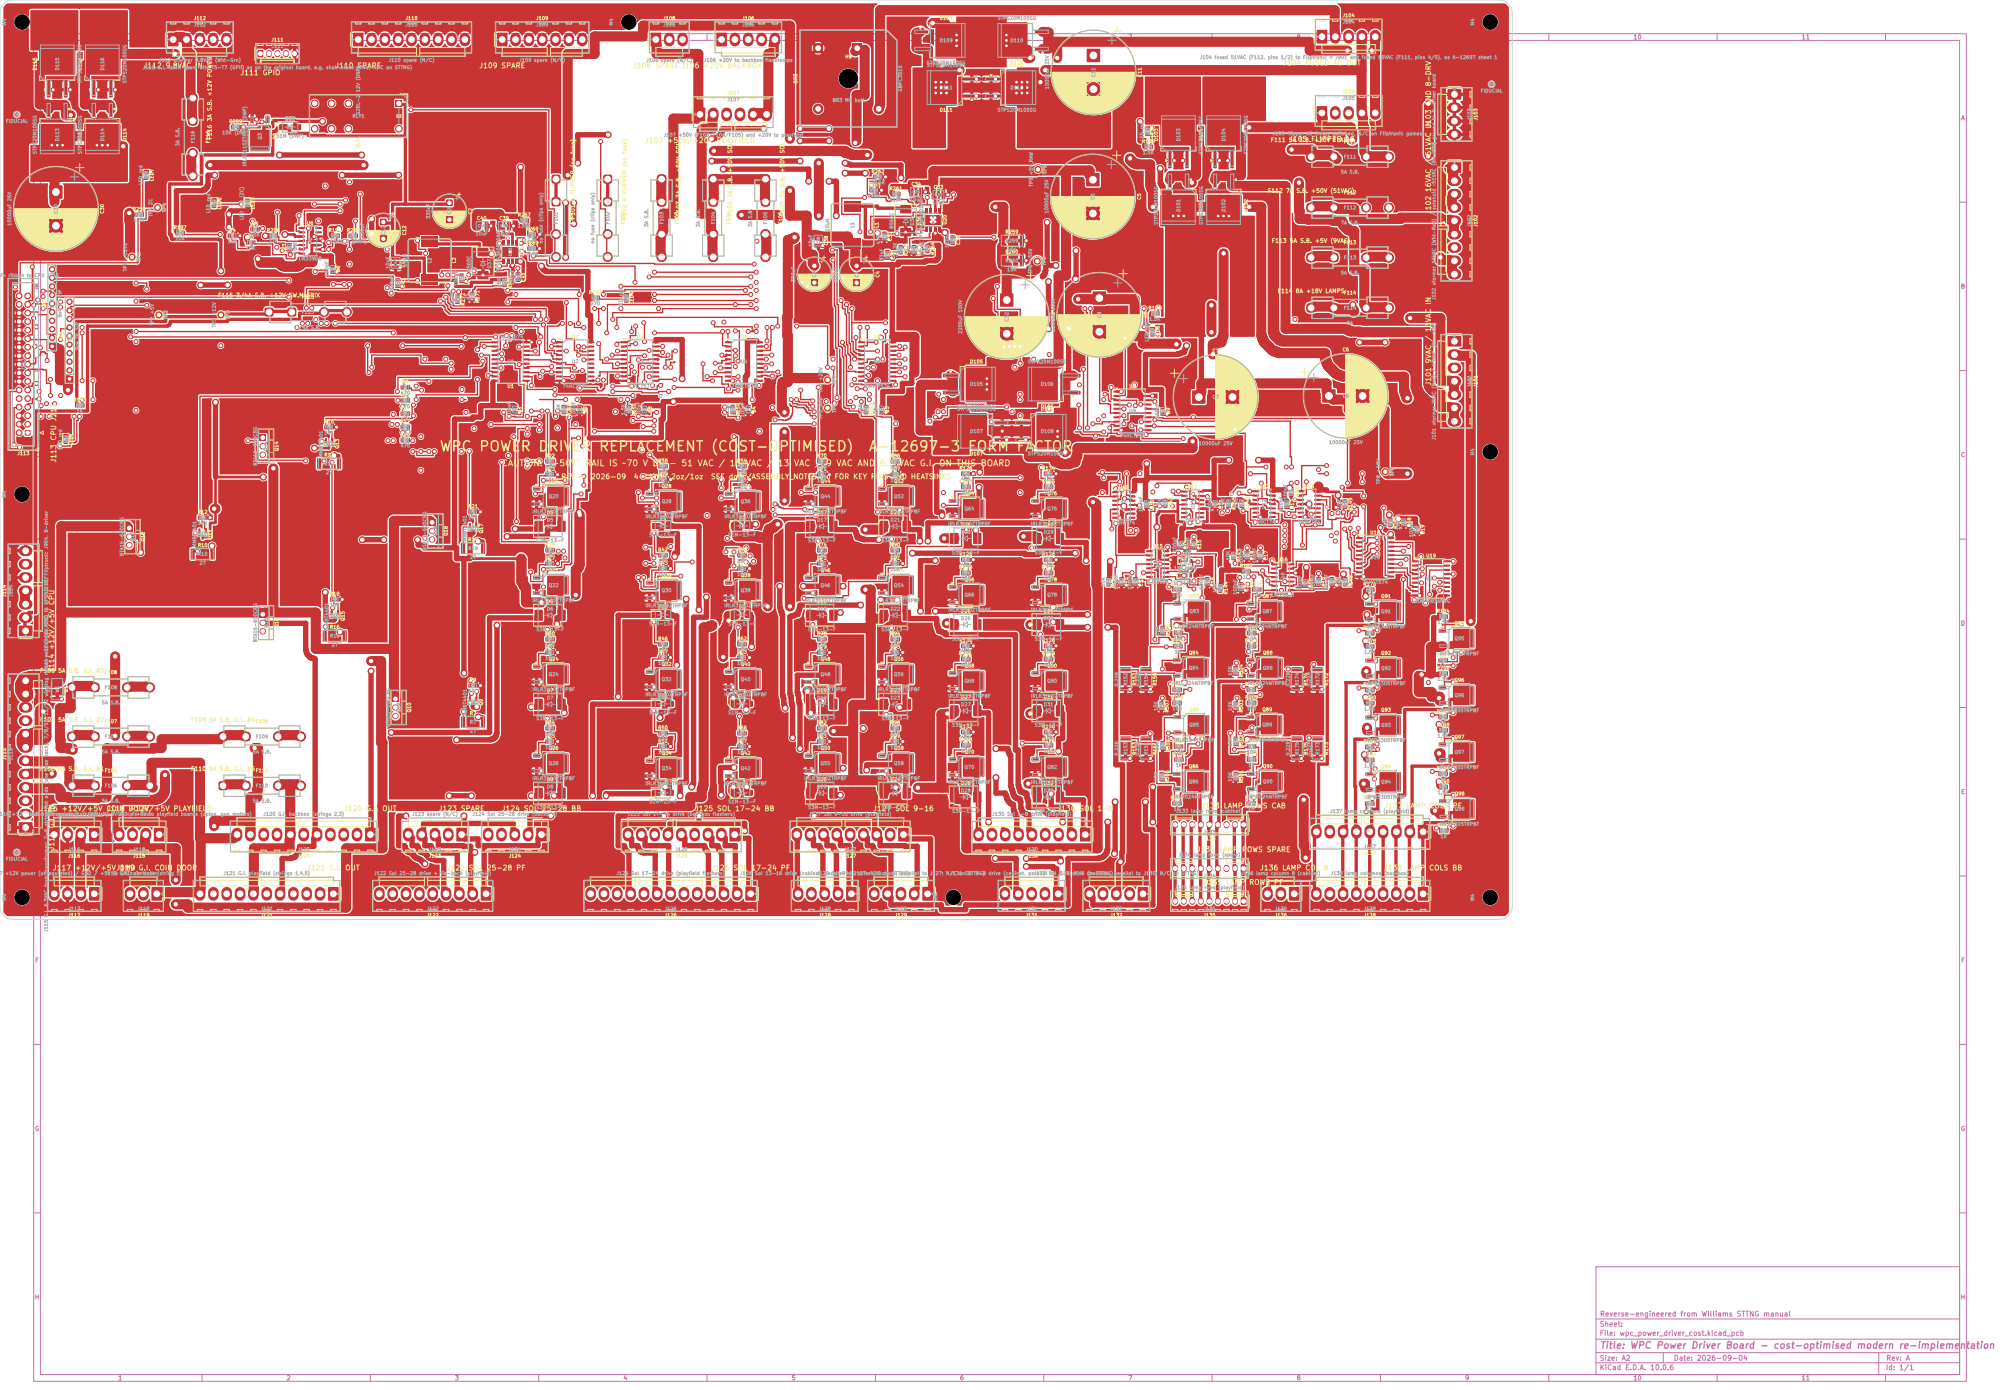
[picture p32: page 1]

J105 flipper AC (relay switched, N/C on Fliptronic games) J105

R55 LED4
J129 Sol 9-12 drive (backbox, parallel to J127; N/C on STTNG) J129 1.5K R254

WPC POWER DRIVER REPLACEMENT (COST-OPTIMISED) A-12697-3 FORM FACTOR

IRLR3110ZTRPBF Q20 LED red LED1 J114 +12V/+5V/GND to CPU J210, Fliptronic J904, 8-driver J114
Q20 LED1 J114

R189 J128 Sol 13-16 drive (cabinet, parallel to J127; N/C on STTNG) J128

J125 Sol 17-24 drive (backbox flashers) J125

J126 Sol 17-24 drive (playfield flashers) J126

J132 Sol 1-4 drive (backbox, parallel to J130; N/C on STTNG) J132

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

Size: A2 | Rev: A
KiCad E.D.A. 10.0.6 | Id: 1/1

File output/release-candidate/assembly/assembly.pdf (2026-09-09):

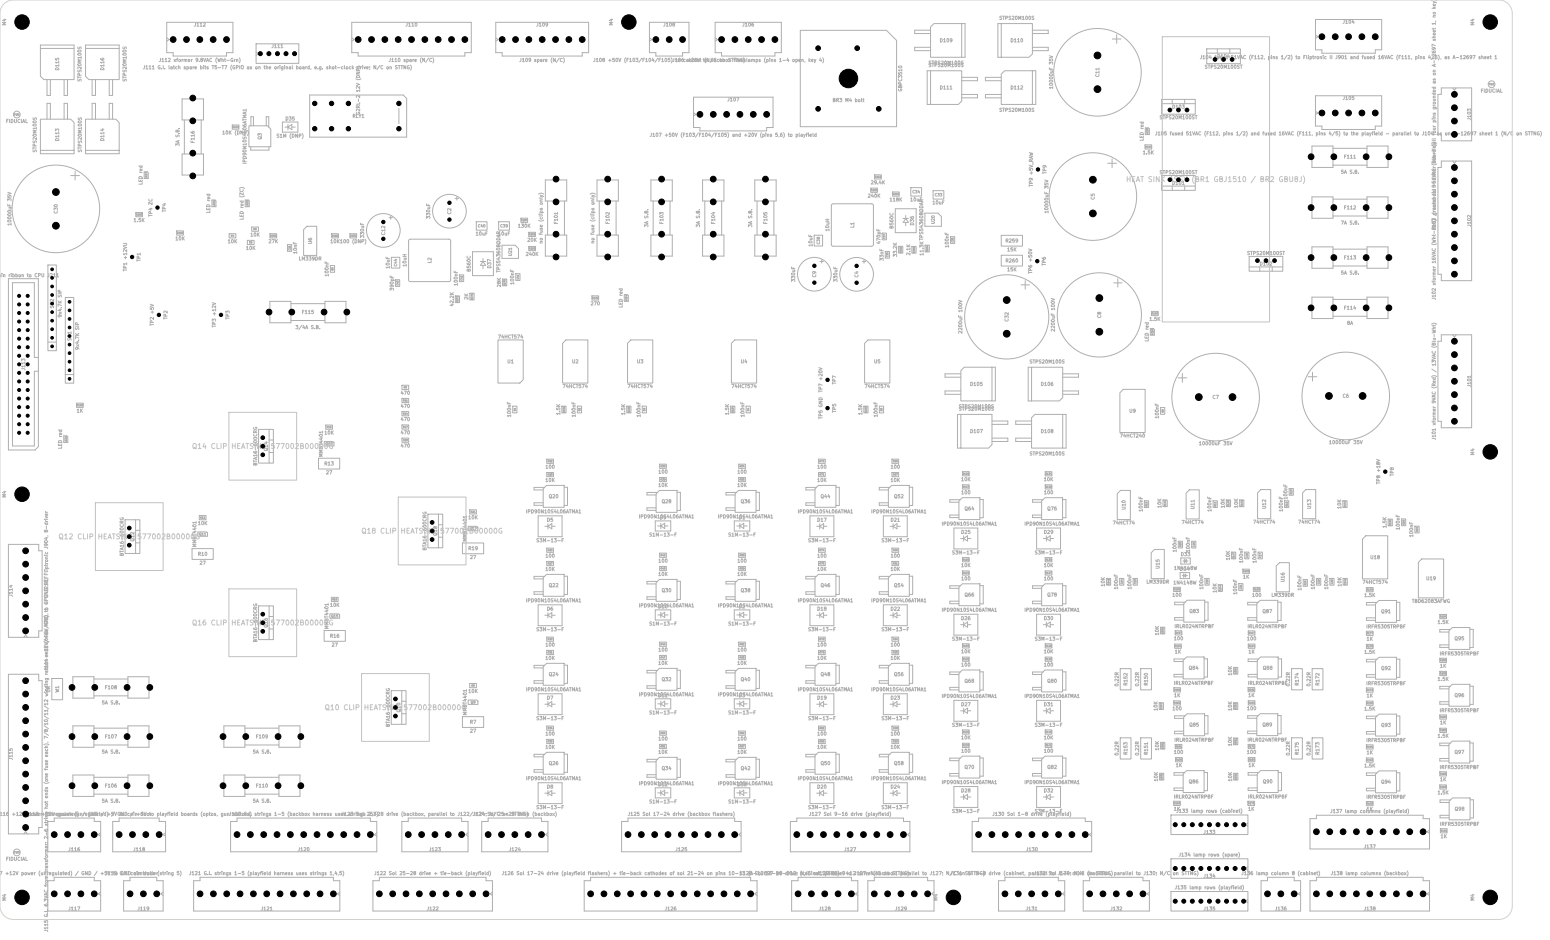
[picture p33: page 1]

J105 fused 51VAC (F112, pins 1/2) and fused 16VAC (F111, pins 4/5) to the playfield - parallel to J104 as on A-12697 sheet 1 (N/C on STTNG) J105

J107 +50V (F103/F104/F105) and +20V (pins 5,6) to playfield

R139 J117 +12V power (unregulated) / GND / +5V to DMD controller J117

R189 J128 Sol 13-16 drive (cabinet, parallel to J127; N/C on STTNG) J128

J120 G.I. strings 1-5 (backbox harness uses strings 2,3) J120

J123 Sol 25-28 drive (backbox, parallel to J122/J124; N/C on STTNG) J123

J125 Sol 17-24 drive (backbox flashers) J125

J121 G.I. strings 1-5 (playfield harness uses strings 1,4,5) J121

J126 Sol 17-24 drive (playfield flashers) + tie-back cathodes of sol 21-24 on pins 10-13 (A-12697 D9-D12; N/C on STTNG) J126

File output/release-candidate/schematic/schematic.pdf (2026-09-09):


WPC POWER DRIVER BOARD - COST-OPTIMISED MODERN VERSION - functional replacement for Williams A-12697-3 (same outline, connectors, fuses).
DPAK MOSFET solenoid/lamp drivers, TPS54360B buck regulators for +5V/+12V, 4-quadrant insulated triacs, SMD passives, 5x20 mm fuses.
Sheets: Power_Supply, CPU_Interface, Sol_HighPower (1-8), Sol_LowPower (9-16), Sol_Flashers (17-24), Sol_GeneralPurpose (25-28),
Lamp_Columns, Lamp_Rows, GI_Triacs. Every part carries Manufacturer / MPN / DigiKey link / Price / Price100 fields (see BOM). See README.md.

Modern re-implementation of the Williams A-12697-3 (same form factor)
Sheet: /
File: wpc_power_driver_cost.kicad_sch
Title: WPC Power Driver Board - cost-optimised modern re-implementation

Size: A3 | Rev: A | F Date: 2026-09-04
KiCad E.D.A. 10.0.6 | Id: 1/10

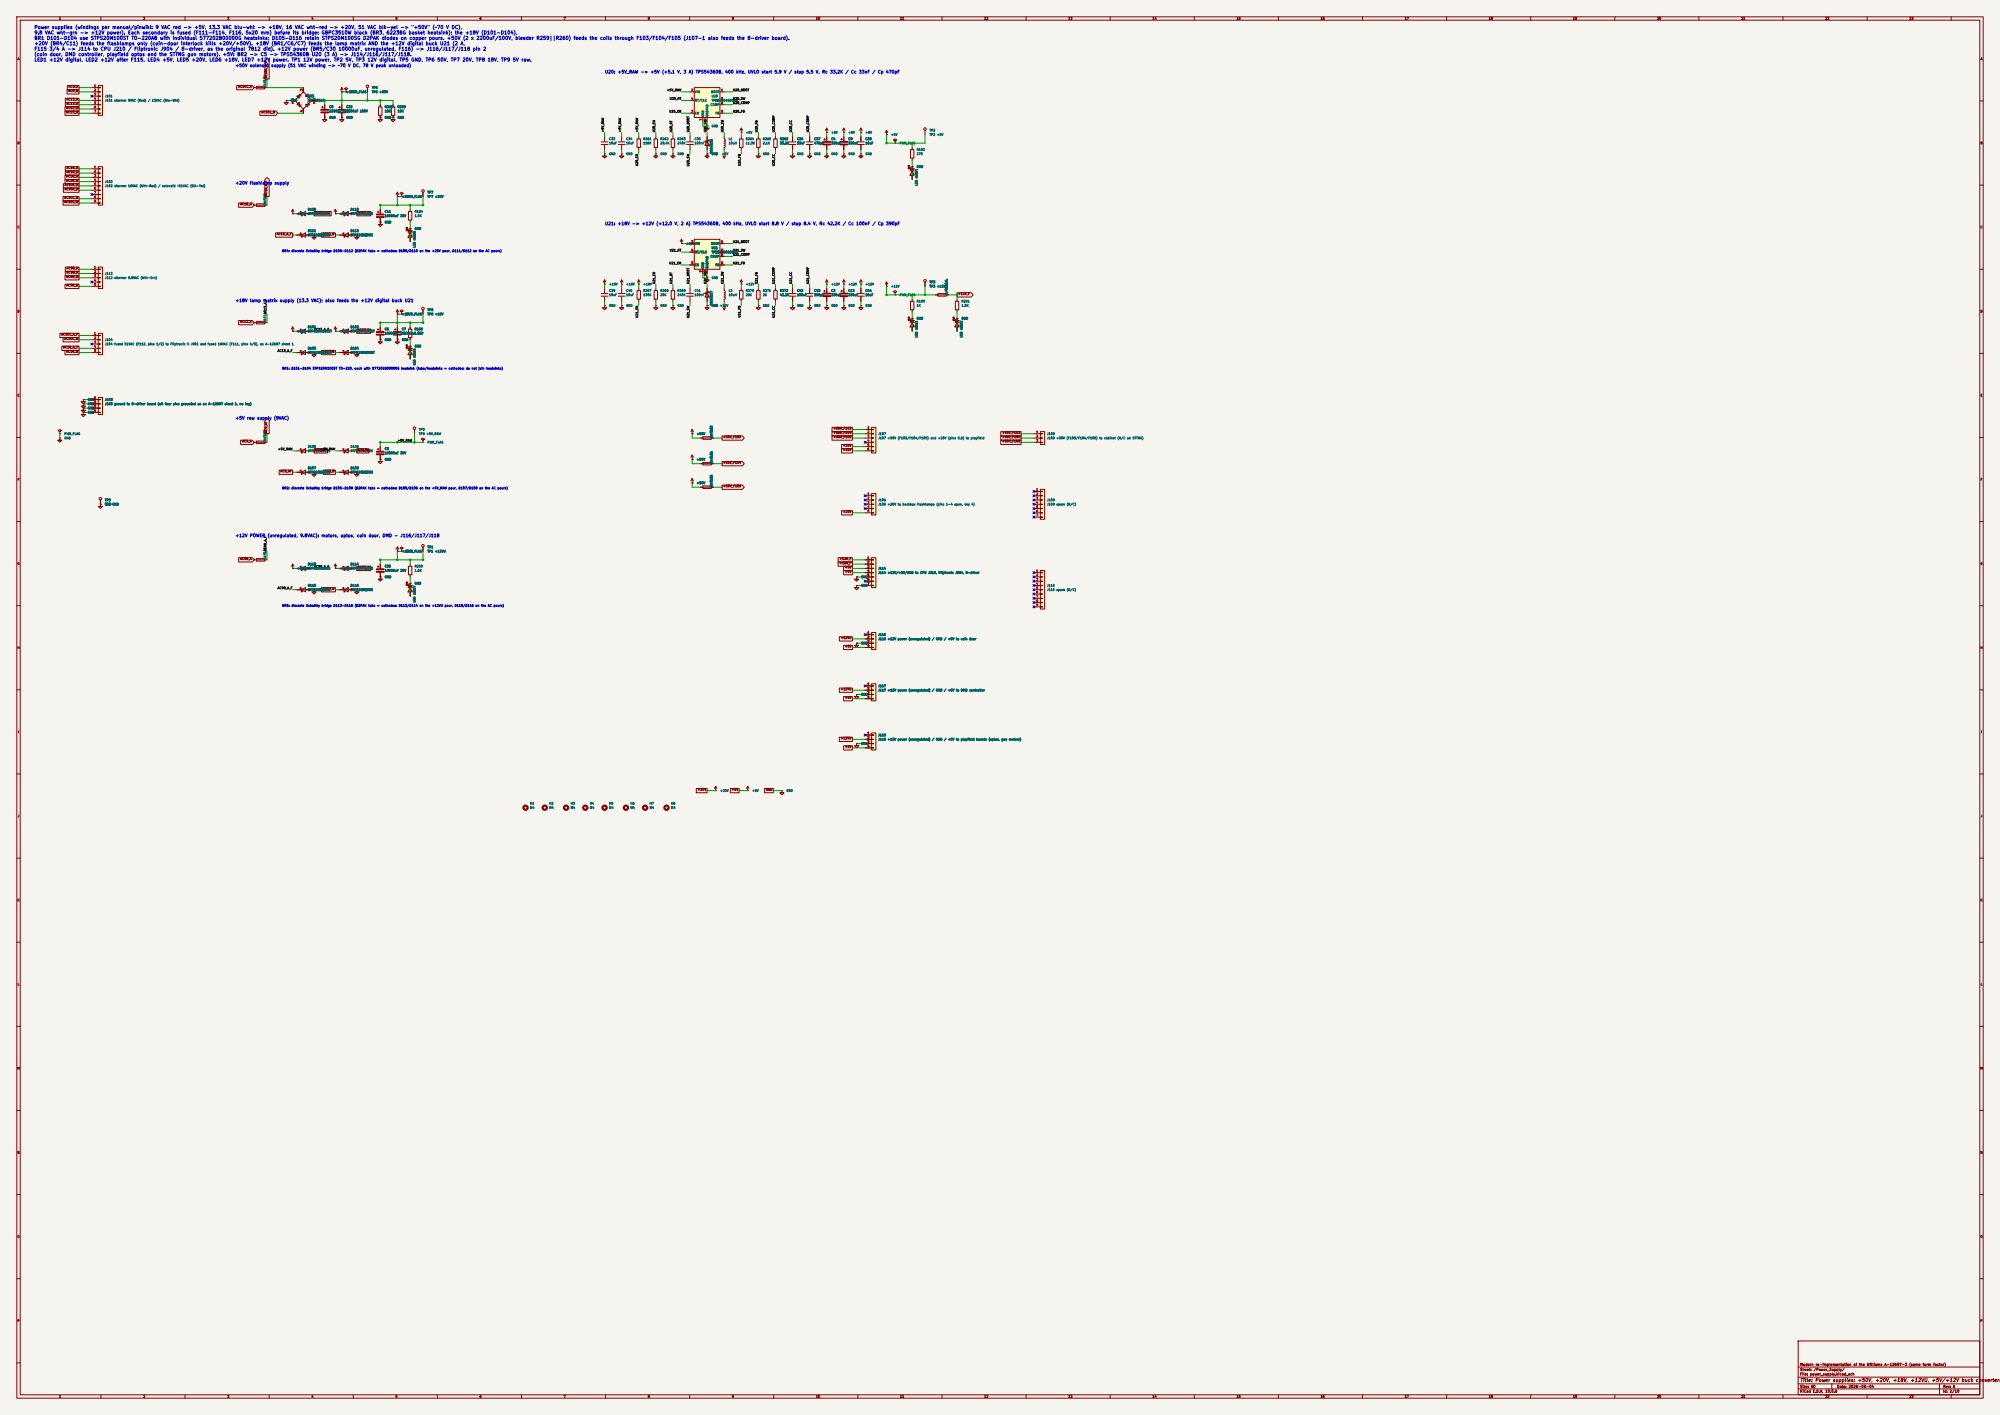
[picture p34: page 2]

Power supplies (windings per manual/pinwiki: 9 VAC red -> +5V, 13.3 VAC blu-wht -> +18V, 16 VAC wht-red -> +20V, 51 VAC blk-yel -> "+50V" (~70 V DC),
9.8 VAC wht-grn -> +12V power). Each secondary is fused (F111-F114, F116, 5x20 mm) before its bridge: GBPC3510W block (BR3, 6223BG basket heatsink); the +18V (D101-D104),
BR1 D101-D104 use STPS20M100ST TO-220AB with individual 577202B00000G heatsinks; D105-D116 retain STPS20M100SG D2PAK diodes on copper pours. +50V (2 x 2200uF/100V, bleeder R259||R260) feeds the coils through F103/F104/F105 (J107-1 also feeds the 8-driver board).
+20V (BR4/C11) feeds the flashlamps only (coin-door interlock kills +20V/+50V). +18V (BR1/C6/C7) feeds the lamp matrix AND the +12V digital buck U21 (2 A,
F115 3/4 A -> J114 to CPU J210 / Fliptronic J904 / 8-driver, as the original 7812 did). +12V power (BR5/C30 10000uF, unregulated, F116) -> J116/J117/J118 pin 2
(coin door, DMD controller, playfield optos and the STTNG gun motors). +5V: BR2 -> C5 -> TPS54360B U20 (3 A) -> J114/J116/J117/J118.
LED1 +12V digital, LED2 +12V after F115, LED4 +5V, LED5 +20V, LED6 +18V, LED7 +12V power. TP1 12V power, TP2 5V, TP3 12V digital, TP5 GND, TP6 50V, TP7 20V, TP8 18V, TP9 5V raw.

+50V solenoid supply (51 VAC winding -> ~70 V DC, 78 V peak unloaded)

TP3 +12V F115 3/4A S.B. LED4 LED red GND
J108 +50V (F103/F104/F105) to cabinet (N/C on STTNG) LED4 LED red

U21: +18V -> +12V (+12.0 V, 2 A) TPS54360B, 400 kHz, UVLO start 8.8 V / stop 8.4 V, Rc 42.2K / Cc 100nF / Cp 390pF

GND
J107 +50V (F103/F104/F105) and +20V (pins 5,6) to playfield LED5 LED red

BR1: D101-D104 STPS20M100ST TO-220, each with 577202B00000G heatsink (tabs/heatsinks = cathodes; do not join heatsinks) BR4: discrete Schottky bridge D109-D112 (D2PAK tabs = cathodes: D109/D110 on the +20V pour, D111/D112 on the AC pours)

+18V lamp matrix supply (13.3 VAC); also feeds the +12V digital buck U21

J109 spare (N/C) LED1 LED red GND

J103 ground to 8-driver board (all four pins grounded as on A-12697 sheet 1, no key) 1

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

BR2: discrete Schottky bridge D105-D108 (D2PAK tabs = cathodes: D105/D106 on the +5V_RAW pour, D107/D108 on the AC pours)

J106 +20V to backbox flashlamps (pins 1-4 open, key 4)

+12V POWER (unregulated, 9.8VAC): motors, optos, coin door, DMD - J116/J117/J118

J114 +12V/+5V/GND to CPU J210, Fliptronic J904, 8-driver

BR5: discrete Schottky bridge D113-D116 (D2PAK tabs = cathodes: D113/D114 on the +12VU pour, D115/D116 on the AC pours)

J116 +12V power (unregulated) / GND / +5V to coin door

J117 +12V power (unregulated) / GND / +5V to DMD controller

J118 +12V power (unregulated) / GND / +5V to playfield boards (optos, gun motors) 1
4 GND

J118 +12V power (unregulated) / GND / +5V to playfield boards (optos, gun motors)

Modern re-implementation of the Williams A-12697-3 (same form factor)
Sheet: /Power_Supply/
File: power_supply.kicad_sch
Title: Power supplies: +50V, +20V, +18V, +12VU, +5V/+12V buck converters, distribution

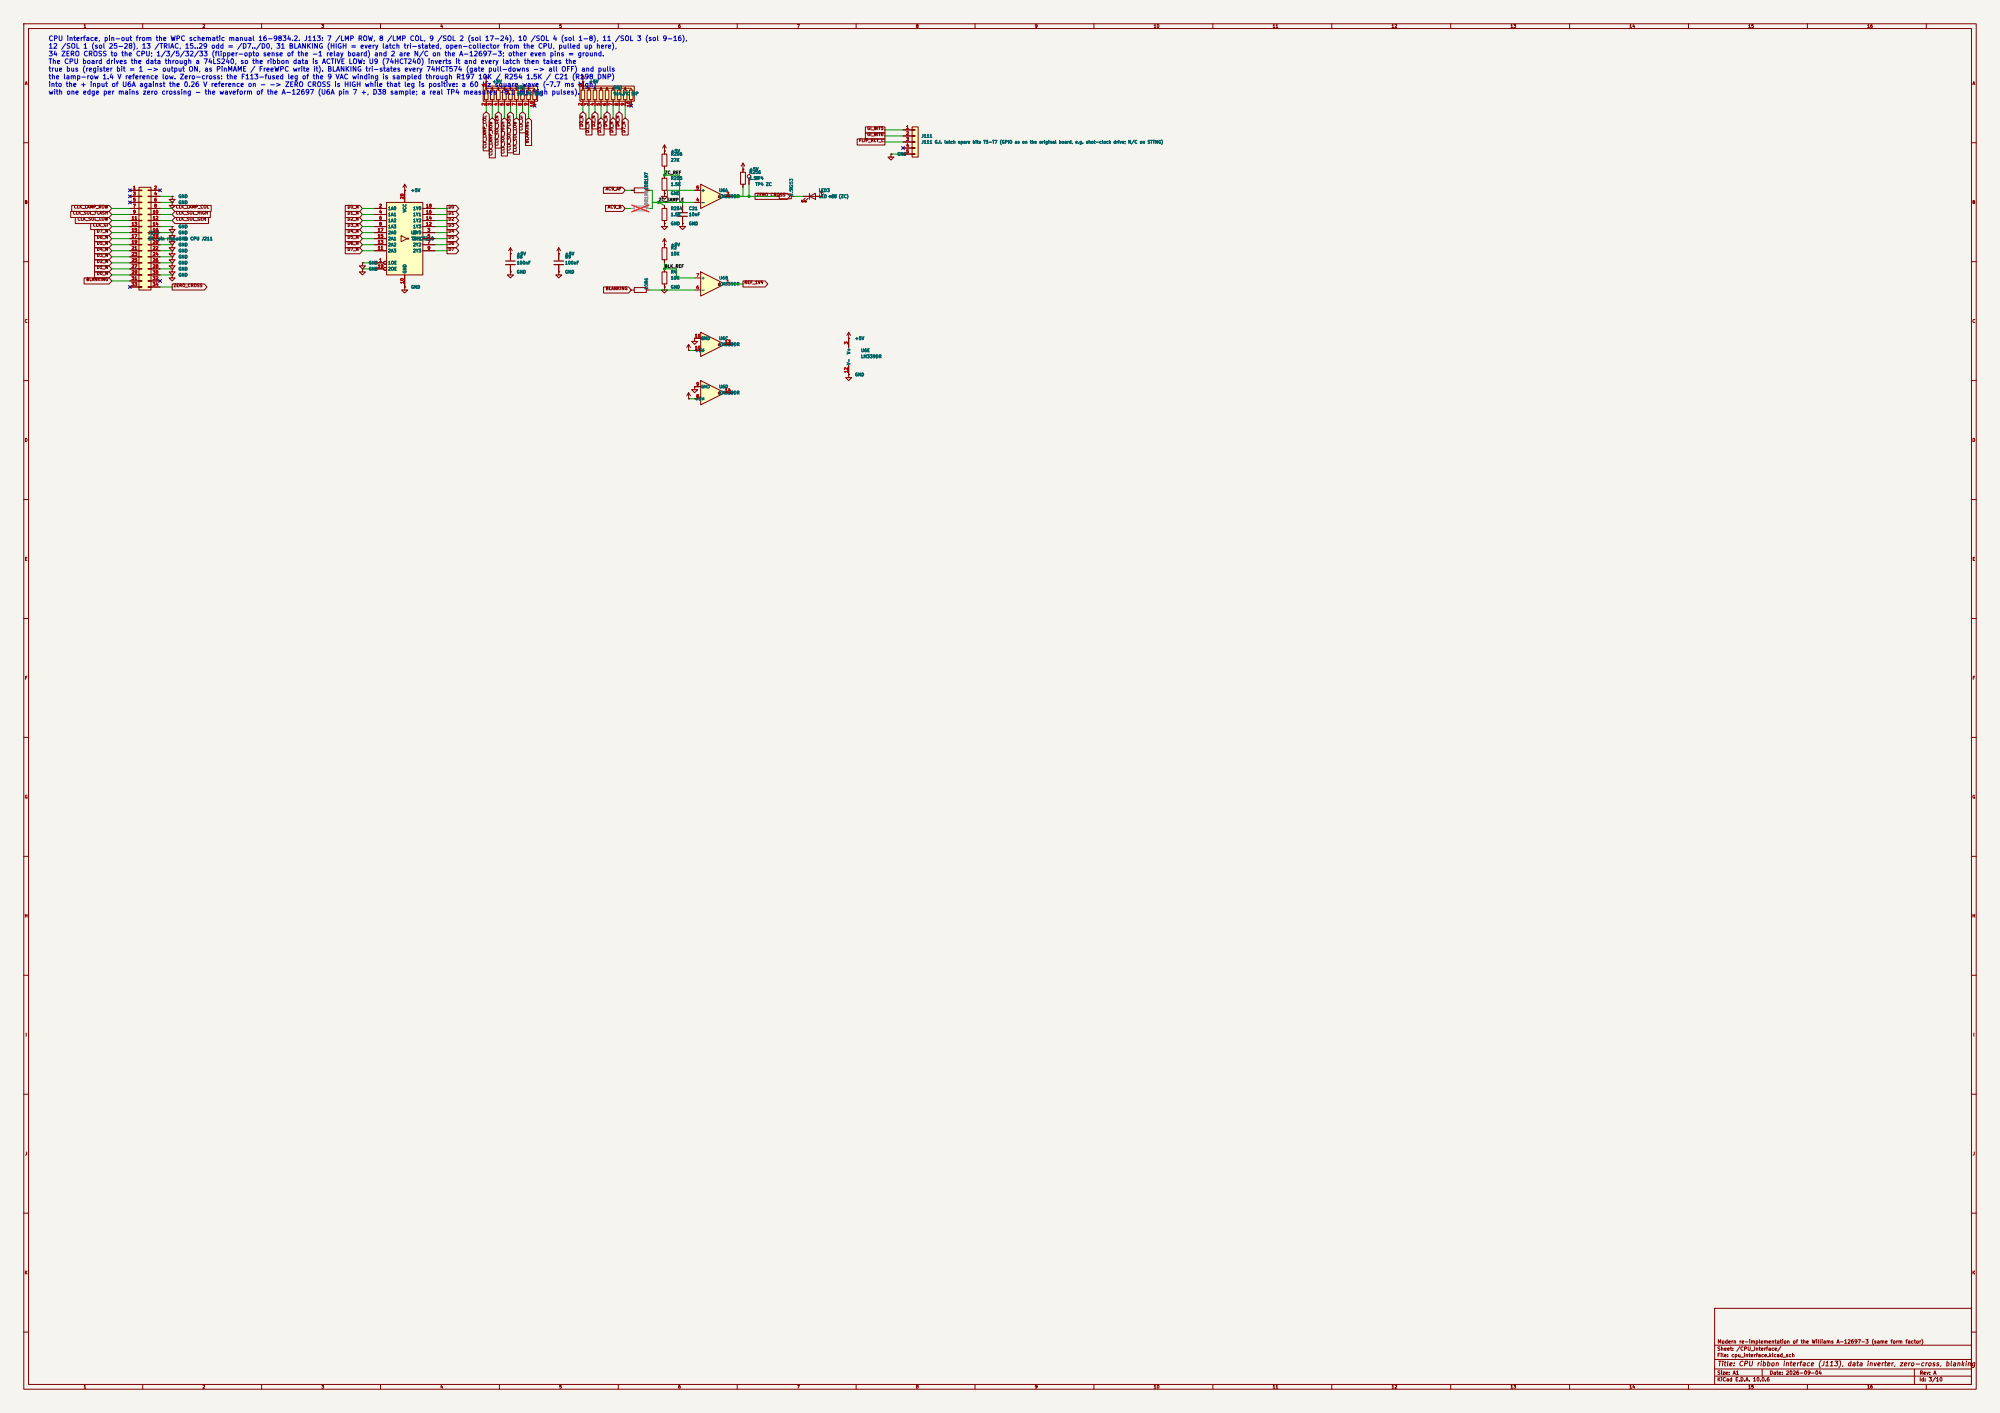
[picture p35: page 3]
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

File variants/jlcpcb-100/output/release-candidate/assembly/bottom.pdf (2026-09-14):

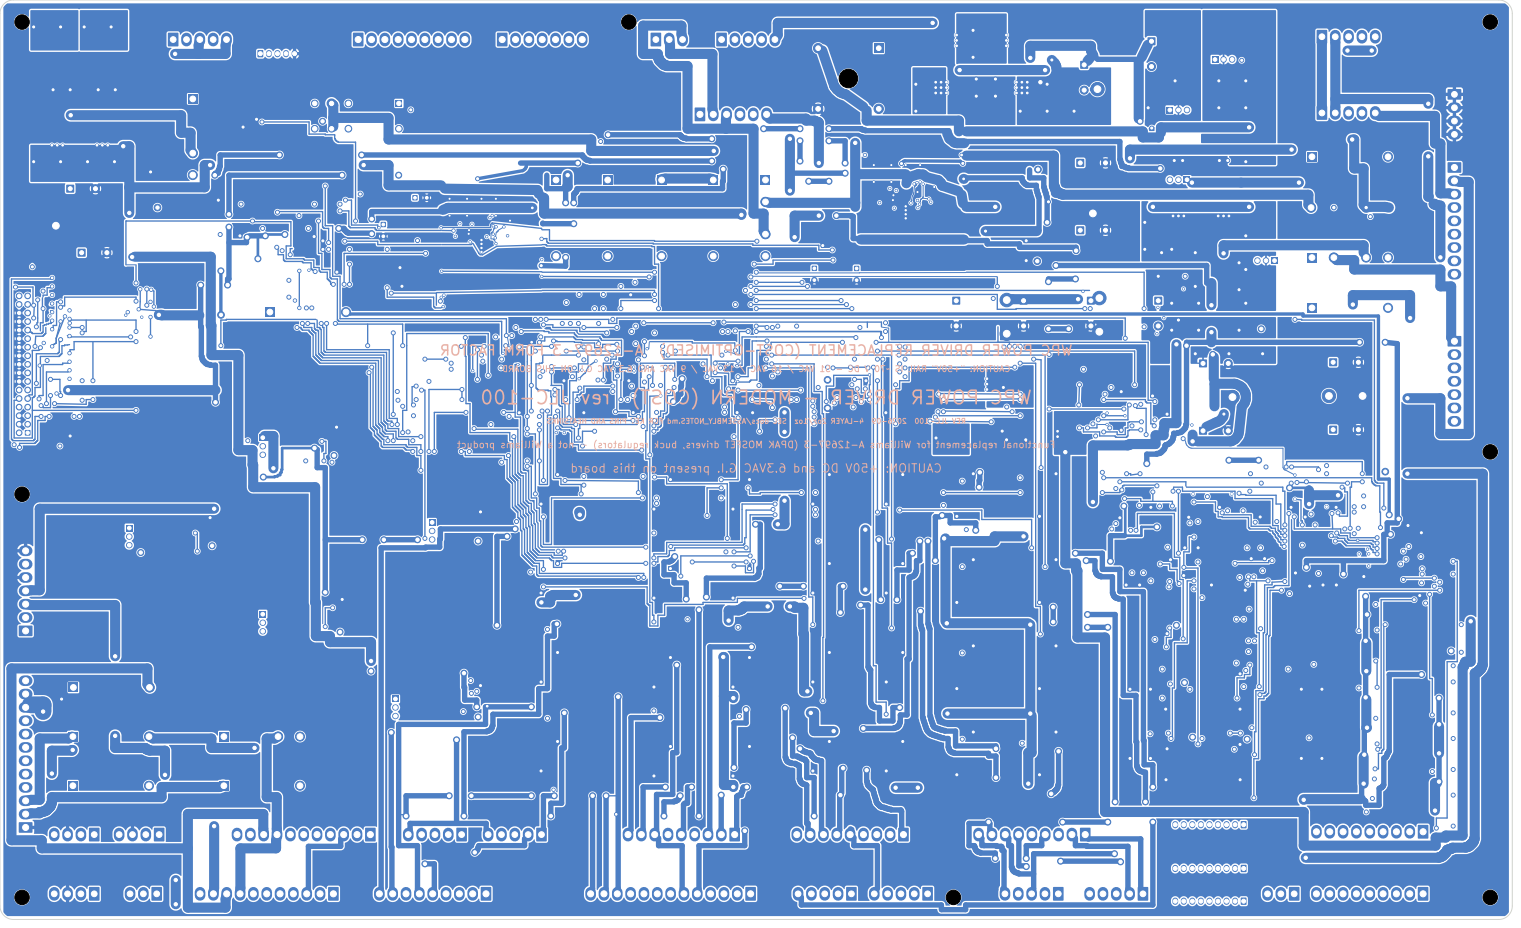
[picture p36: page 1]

FACTOR FORM A-12697-3 (COST-OPTIMISED) REPLACEMENT DRIVER POWER WPC

BOARD THIS ON G.I. VAC 6.3 AND VAC 9 / VAC 13 / VAC 16 / VAC 51 - DC V ~70 IS RAIL "+50V" CAUTION:

JLC-100 rev (COST) MODERN - DRIVER POWER WPC

HEATSINKS AND PINS KEY FOR docs/ASSEMBLY_NOTES.md SEE 2oz/1oz 4-LAYER 2026-09 JLC-100 REV

product Williams a not - regulators) buck drivers, MOSFET (DPAK A-12697-3 Williams for replacement Functional

board this on present G.I. 6.3VAC and DC +50V CAUTION:

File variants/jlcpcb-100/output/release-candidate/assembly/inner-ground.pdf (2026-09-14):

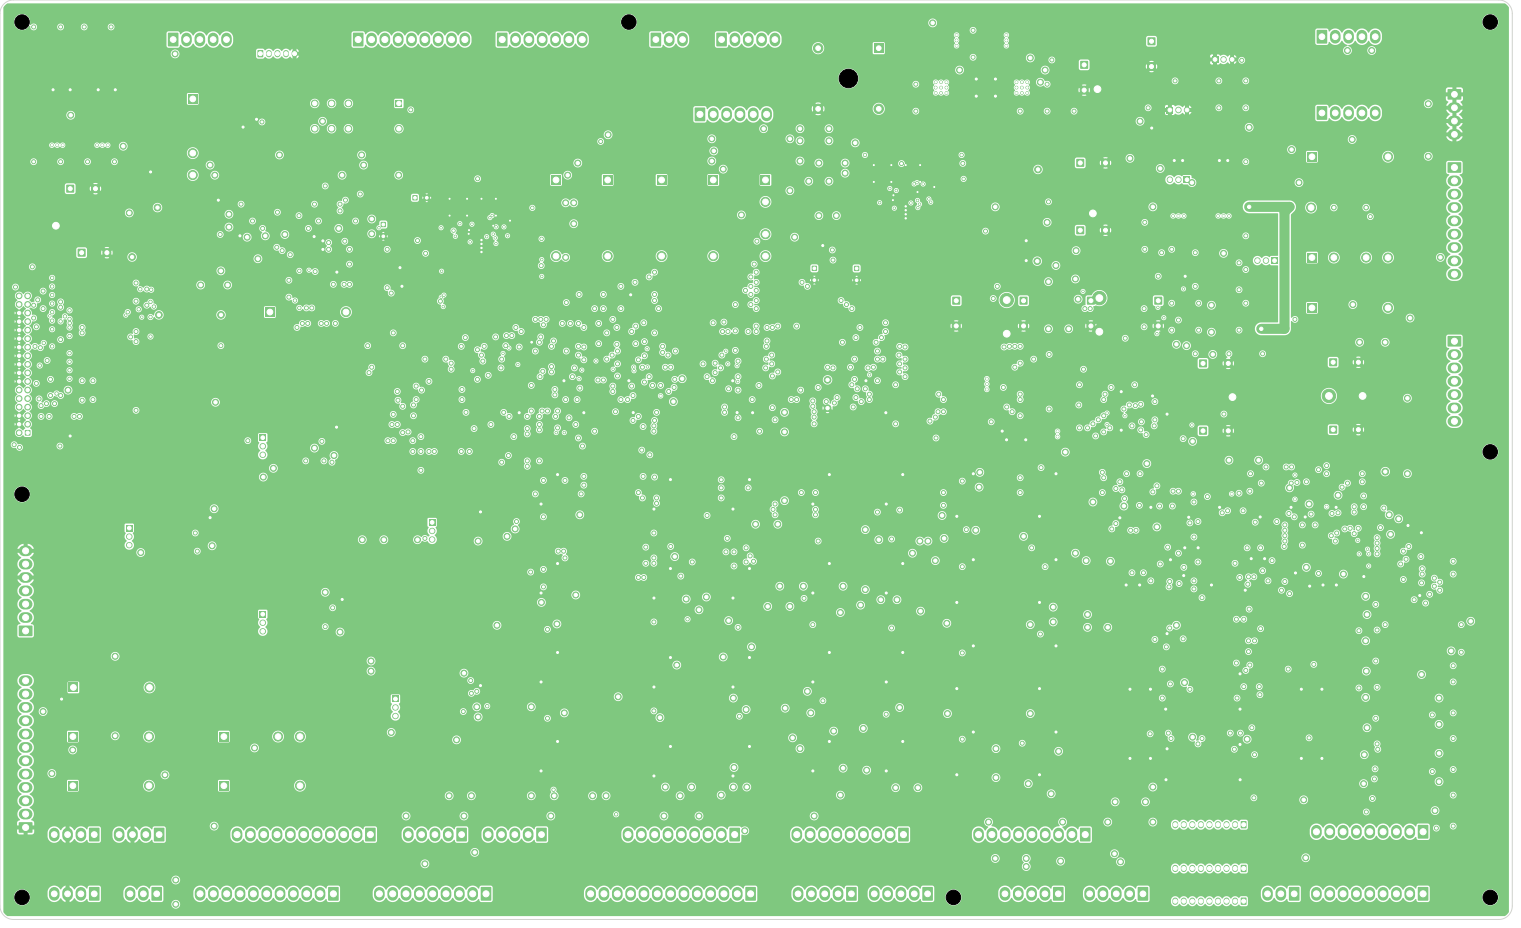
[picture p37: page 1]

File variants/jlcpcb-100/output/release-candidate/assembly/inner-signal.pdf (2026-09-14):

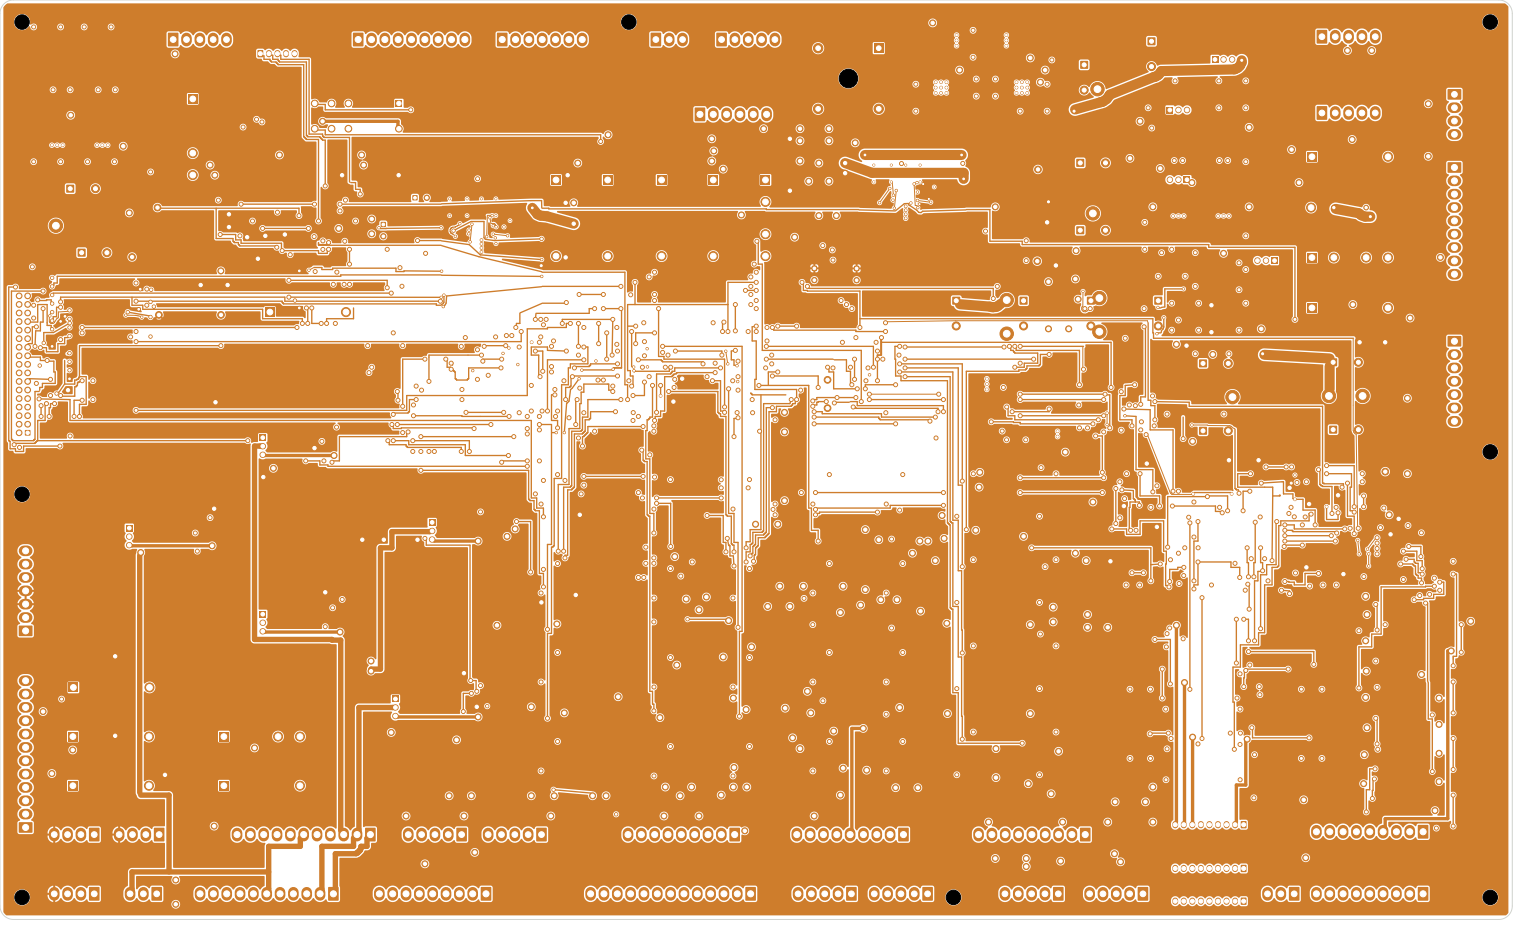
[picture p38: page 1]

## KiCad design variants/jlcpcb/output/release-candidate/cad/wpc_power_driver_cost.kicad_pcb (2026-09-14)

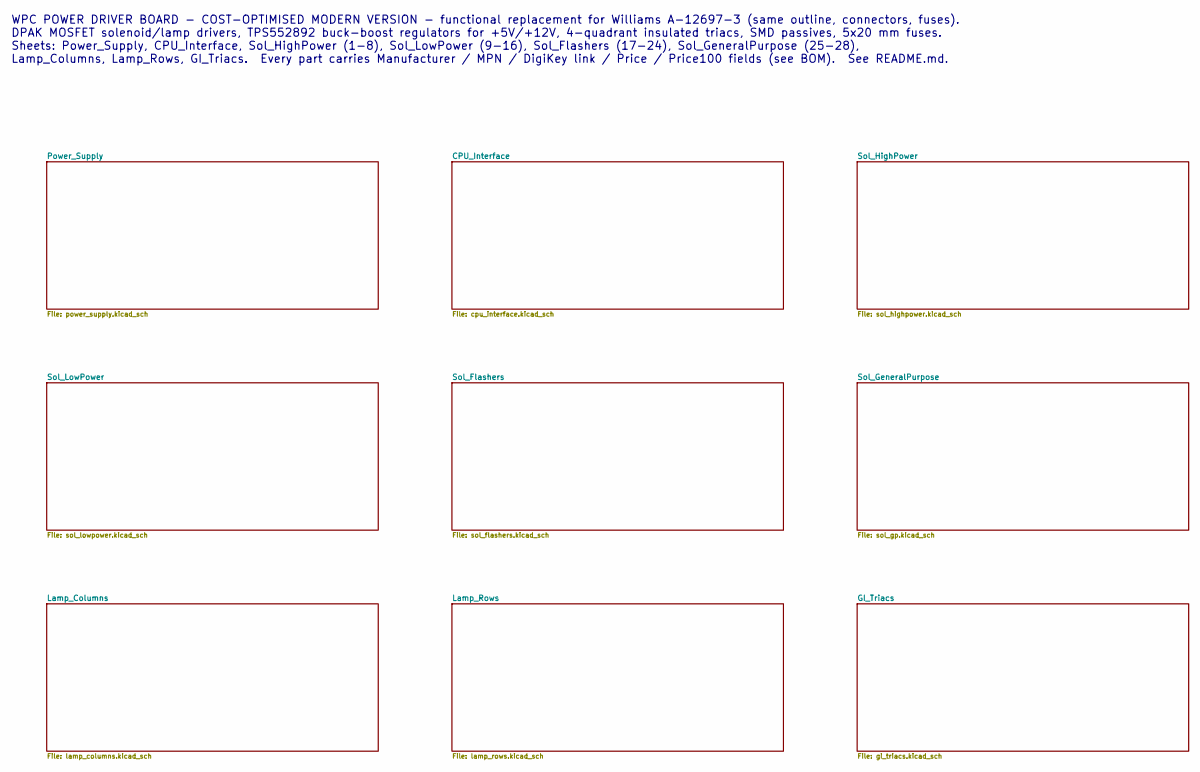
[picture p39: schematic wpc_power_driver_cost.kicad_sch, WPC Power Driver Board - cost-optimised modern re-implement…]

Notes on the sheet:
WPC POWER DRIVER BOARD - COST-OPTIMISED MODERN VERSION - functional replacement for Williams A-12697-3 (same outline, connectors, fuses). DPAK MOSFET solenoid/lamp drivers, TPS552892 buck-boost regulators for +5V/+12V, 4-quadrant insulated triacs, SMD passives, 5x20 mm fuses. Sheets: Power_Supply, 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

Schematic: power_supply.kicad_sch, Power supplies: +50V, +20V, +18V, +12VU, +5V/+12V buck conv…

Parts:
BR3: GBPC3510; Diode_Bridge_28.6x28.6x7.3mm_P18.0mm_P11.6mm; MPN GBPC3510W-E4/51; JLCPCB Part C435891
C2, C4, C9, C12: 330uF; CP_Radial_D8.0mm_P5.00mm; MPN EEU-FR1E331B; JLCPCB Part C1579638
C5, C6, C7, C11, C30: 10000uF 35V; CP_Radial_D26.0mm_P10.00mm_SnapIn; MPN B41252A7109M000; JLCPCB Part C6130373
C8, C32: 2200uF 100V; CP_Radial_D25.0mm_P10.00mm_SnapIn; MPN LLS2A222MELA; JLCPCB Part C1582025
C33, C34, C38, C39, C40, C44, C46, C49, C50, C51, C53, C56, C57, C58: 10uF; C_1210_3225Metric; MPN CL32B106KBJNNWE; JLCPCB Part C3844168
C35, C41, C45, C47, C48, C52, C54, C55: 100nF; C_0402_1005Metric; MPN GRM155R71H104KE14D; JLCPCB Part C77020
C36: 100nF; C_0805_2012Metric; MPN CC0805KRX7R9BB104; JLCPCB Part C49678
C37: 680pF; C_0805_2012Metric; MPN CC0805JRNPO9BN681; JLCPCB Part C107121
C42: 330nF; C_0805_2012Metric; MPN CL21B334KBFNNNE; JLCPCB Part C73142
C43: 1nF; C_0805_2012Metric; MPN CC0805JRNPO9BN102; JLCPCB Part C62774
D101, D102, D103, D104: STPS20M100ST; TO220_Schottky_AKA_5772; MPN STPS20M100ST; JLCPCB Part C222114
D105, D106, D107, D108, D109, D110, D111, D112, D113, D114, D115, D116: STPS20M100S; D2PAK_Schottky_AKA; MPN STPS20M100SG-TR; JLCPCB Part C969989
F103, F104, F105, F116: 3A S.B.; Fuseholder_Clip-5x20mm_Keystone_3517_Inline_P23.11x6.76mm_D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; MPN 0239003.MXP; JLCPCB Part C142824
F111, F113: 5A S.B.; Fuseholder_Clip-5x20mm_Keystone_3517_Inline_P23.11x6.76mm_D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; MPN 0239005.MXP; JLCPCB Part C151086
F112: 7A S.B.; Fuseholder_Clip-5x20mm_Keystone_3517_Inline_P23.11x6.76mm_D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; MPN 0239007.MXP; JLCPCB Part C3161084
F114: 8A; Fuseholder_Clip-5x20mm_Keystone_3517_Inline_P23.11x6.76mm_D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; MPN 0217008.MXP; JLCPCB Part C2936126
F115: 3/4A S.B.; Fuseholder_Clip-5x20mm_Keystone_3517_Inline_P23.11x6.76mm_D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; MPN 0239.750MXP; JLCPCB Part C3157012
H1, H2, H3, H4, H5, H6, H7, H8: M4; MountingHole_4.3mm_M4
J101: J101 xformer 9VAC (Red) / 13VAC (Blu-Wht); Molex_KK-396_A-41791-0007_1x07_P3.96mm_Vertical; MPN 26604070; JLCPCB Part C587091
J102: J102 xformer 16VAC (Wht-Red) / solenoid ~51VAC (B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; Molex_KK-396_A-41791-0009_1x09_P3.96mm_Vertical; MPN 0026604090; JLCPCB Part C17420444
J103: J103 ground to 8-driver board (all four pins grou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; Molex_KK-396_A-41791-0004_1x04_P3.96mm_Vertical; MPN 26604040; JLCPCB Part C240824
J104: J104 fused 51VAC (F112, pins 1/2) to Fliptronic I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; Molex_KK-396_A-41791-0005_1x05_P3.96mm_Vertical; MPN 26604050; JLCPCB Part C505166
J106: J106 +20V to backbox flashlamps (pins 1-4 open, k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; Molex_KK-396_A-41791-0005_1x05_P3.96mm_Vertical; MPN 26604050; JLCPCB Part C505166
J107: J107 +50V (F103/F104/F105) and +20V (pins 5,6) to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; Molex_KK-396_A-41791-0006_1x06_P3.96mm_Vertical; MPN 0026604060; JLCPCB Part C17656945
J108: J108 +50V (F103/F104/F105) to cabinet (N/C on STT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; Molex_KK-396_A-41791-0003_1x03_P3.96mm_Vertical; MPN 26604030; JLCPCB Part C240823
J109: J109 spare (N/C); Molex_KK-396_A-41791-0007_1x07_P3.96mm_Vertical; MPN 26604070; JLCPCB Part C587091
J110: J110 spare (N/C); Molex_KK-396_A-41791-0009_1x09_P3.96mm_Vertical; MPN 0026604090; JLCPCB Part C17420444
J112: J112 xformer 9.8VAC (Wht-Grn); Molex_KK-396_A-41791-0005_1x05_P3.96mm_Vertical; MPN 26604050; JLCPCB Part C505166
J114: J114 +12V/+5V/GND to CPU J210, Fliptronic J904, 8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; Molex_KK-396_A-41791-0007_1x07_P3.96mm_Vertical; MPN 26604070; JLCPCB Part C587091
J116: J116 +12V power (unregulated) / GND / +5V to coin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; Molex_KK-396_A-41791-0004_1x04_P3.96mm_Vertical; MPN 26604040; JLCPCB Part C240824
J117: J117 +12V power (unregulated) / GND / +5V to DMD 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; Molex_KK-396_A-41791-0004_1x04_P3.96mm_Vertical; MPN 26604040; JLCPCB Part C240824
J118: J118 +12V power (unregulated) / GND / +5V to play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; Molex_KK-396_A-41791-0004_1x04_P3.96mm_Vertical; MPN 26604040; JLCPCB Part C240824
L1, L2: 10uH; L_Bourns_SRP1245A; MPN SRP1265A-100M; JLCPCB Part C840531
LED1, LED2, LED4, LED5, LED6, LED7: LED red; LED_0805_2012Metric; MPN NCD0805R1; JLCPCB Part C84256
R192: 470; R_0805_2012Metric; MPN 0805W8F4700T5E; JLCPCB Part C17710
R193: 1K; R_0805_2012Metric; MPN 0805W8F1001T5E; JLCPCB Part C17513
R194, R196, R250, R251: 1.5K; R_0805_2012Metric; MPN 0805W8F1501T5E; JLCPCB Part C4310
R259, R260: 15K; R_2512_6332Metric; MPN RC2512JK-0715KL; JLCPCB Part C1882622
R261: 118K; R_0805_2012Metric; MPN RC0805FR-07118KL; JLCPCB Part C274001
R262: 29.4K; R_0805_2012Metric; MPN RC0805FR-0729K4L; JLCPCB Part C273956
R263, R269: 49.9K; R_0805_2012Metric; MPN 0805W8F4992T5E; JLCPCB Part C17719
R264: 6.65K; R_0805_2012Metric; MPN RT0805BRD076K65L; JLCPCB Part C865625
R265: 2.1K; R_0805_2012Metric; MPN RT0805BRD072K1L; JLCPCB Part C865367
R266: 33.2K; R_0805_2012Metric; MPN 0805W8F3322T5E; JLCPCB Part C37252
R267: 130K; R_0805_2012Metric; MPN RC0805FR-07130KL; JLCPCB Part C483008
R268: 20K; R_0805_2012Metric; MPN 0805W8F2002T5E; JLCPCB Part C4328
R270: 18K; R_0805_2012Metric; MPN RT0805BRD0718KL; JLCPCB Part C706223
R271: 2K; R_0805_2012Metric; MPN RT0805BRD072KL; JLCPCB Part C865384
R272: 42.2K; R_0805_2012Metric; MPN 0805W8F4222T5E; JLCPCB Part C17686
R326: 13m; R_2512_6332Metric; MPN RL2512FK-070R013L; JLCPCB Part C705606
R327: 33m; R_2512_6332Metric; MPN RL2512FK-070R033L; JLCPCB Part C705608
TP1: TP1 +12VU; TestPoint_THTPad_D2.0mm_Drill1.0mm
TP2: TP2 +5V; TestPoint_THTPad_D2.0mm_Drill1.0mm
TP3: TP3 +12V; TestPoint_THTPad_D2.0mm_Drill1.0mm
TP5: TP5 GND; TestPoint_THTPad_D2.0mm_Drill1.0mm
TP6: TP6 +50V; TestPoint_THTPad_D2.0mm_Drill1.0mm
TP7: TP7 +20V; TestPoint_THTPad_D2.0mm_Drill1.0mm
TP8: TP8 +18V; TestPoint_THTPad_D2.0mm_Drill1.0mm
TP9: TP9 +5V_RAW; TestPoint_THTPad_D2.0mm_Drill1.0mm
U20, U21: TPS552892RYQR; TI_RYQ0021B_5x3mm; MPN TPS552892RYQR; JLCPCB Part C19272254

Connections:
+5V: C4.1, C9.1, J114.3, J114.4, J116.4, J117.4, J118.4, R192.1, R264.1, R326.2, TP2.1, U20.13 (ISN); also elsewhere on the board
+12V: C2.1, C12.1, F115.1, R193.1, R270.1, R327.2, TP3.1, U21.13 (ISN); also elsewhere on the board
+12VU: C30.1, D113.1 (K), D114.1 (K), J116.2, J117.2, J118.2, R250.1, TP1.1
+12V_F: F115.2, J114.1, J114.2, R251.1
+18V: C6.1, C7.1, C39.1, C40.1, C54.1, C56.1, C57.1, D101.1 (K), D102.1 (K), R196.1, R267.1, TP8.1, U21.7 (VIN); also elsewhere on the board
+20V: C11.1, D109.1 (K), D110.1 (K), J106.5, J107.5, J107.6, R194.1, TP7.1; also elsewhere on the board
+50V: BR3.1 (+), C8.1, C32.1, F103.1, F104.1, F105.1, R259.1, R260.1, TP6.1; also elsewhere on the board
+50V_F103: F103.2, J107.1, J108.1
+50V_F104: F104.2, J107.2, J108.2
+50V_F105: F105.2, J107.3, J108.3
/Power_Supply/+5V_RAW: C5.1, C33.1, C34.1, C47.1, C49.1, C50.1, D105.1 (K), D106.1 (K), R261.1, TP9.1, U20.7 (VIN)
/Power_Supply/AC13_A_F: D101.2 (A), D103.1 (K), F114.2
/Power_Supply/AC98_A_F: D113.2 (A), D115.1 (K), F116.2
/Power_Supply/U20_BOOT1: C35.1, U20.20 (BOOT1)
/Power_Supply/U20_BOOT2: C45.1, U20.19 (BOOT2)
/Power_Supply/U20_CC: C36.1, R266.2
/Power_Supply/U20_COMP: C37.1, R266.1, U20.15 (COMP)
/Power_Supply/U20_EN: R261.2, R262.1, U20.1 (EN)
/Power_Supply/U20_FB: R264.2, R265.1, U20.14 (FB)
/Power_Supply/U20_REG: C38.1, C48.1, C51.1, R326.1, U20.11 (VOUT), U20.12 (ISP)
/Power_Supply/U20_RT: R263.1, U20.6 (FSW)
/Power_Supply/U20_SW1: C35.2, L1.1, U20.8 (SW1)
/Power_Supply/U20_SW2: C45.2, L1.2, U20.10 (SW2)
/Power_Supply/U20_VCC: C46.1, U20.18 (VCC)
/Power_Supply/U21_BOOT1: C41.1, U21.20 (BOOT1)
/Power_Supply/U21_BOOT2: C52.1, U21.19 (BOOT2)
/Power_Supply/U21_CC: C42.1, R272.2
/Power_Supply/U21_COMP: C43.1, R272.1, U21.15 (COMP)
/Power_Supply/U21_EN: R267.2, R268.1, U21.1 (EN)
/Power_Supply/U21_FB: R270.2, R271.1, U21.14 (FB)
/Power_Supply/U21_REG: C44.1, C55.1, C58.1, R327.1, U21.11 (VOUT), U21.12 (ISP)
/Power_Supply/U21_RT: R269.1, U21.6 (FSW)
/Power_Supply/U21_SW1: C41.2, L2.1, U21.8 (SW1)
/Power_Supply/U21_SW2: C52.2, L2.2, U21.10 (SW2)
/Power_Supply/U21_VCC: C53.1, U21.18 (VCC)
AC9_A: F113.1, J101.1
AC9_AF: D105.2 (A), D107.1 (K), F113.2; also elsewhere on the board
AC9_B: D106.2 (A), D108.1 (K), J101.2; also elsewhere on the board
AC13_A: F114.1, J101.4, J101.5
AC13_B: D102.2 (A), D104.1 (K), J101.6, J101.7
AC16_A: F111.1, J102.1, J102.2
AC16_A_F: D109.2 (A), D111.1 (K), F111.2, J104.4; also elsewhere on the board
AC16_B: D110.2 (A), D112.1 (K), J102.3, J102.4, J104.5; also elsewhere on the board
AC98_A: F116.1, J112.1, J112.2
AC98_B: D114.2 (A), D116.1 (K), J112.3, J112.5
ACSOL_A: F112.1, J102.5, J102.6; also elsewhere on the board
ACSOL_A_F: BR3.3, F112.2, J104.1; also elsewhere on the board
ACSOL_B: BR3.4, J102.8, J102.9, J104.2; also elsewhere on the board

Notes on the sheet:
+50V solenoid supply (51 VAC winding -> ~70 V DC, 78 V peak unloaded)
BR4: discrete Schottky bridge D109-D112 (D2PAK tabs = cathodes: D109/D110 on the +20V pour, D111/D112 on the AC pours)
+20V flashlamp supply
BR1: D101-D104 STPS20M100ST TO-220, each with 577202B00000G heatsink (tabs/heatsinks = cathodes; do not join heatsinks)
+18V lamp matrix supply (13.3 VAC); also feeds the +12V digital buck-boost U21
BR2: discrete Schottky bridge D105-D108 (D2PAK tabs = cathodes: D105/D106 on the +5V_RAW pour, D107/D108 on the AC pours)
+5V raw supply (9VAC)
BR5: discrete Schottky bridge D113-D116 (D2PAK tabs = cathodes: D113/D114 on the +12VU pour, D115/D116 on the AC pours)
+12V POWER (unregulated, 9.8VAC): motors, optos, coin door, DMD - J116/J117/J118
Power supplies (windings per manual/pinwiki: 9 VAC red -> +5V, 13.3 VAC blu-wht -> +18V, 16 VAC wht-red -> +20V, 51 VAC blk-yel -> "+50V" (~70 V DC), 9.8 VAC wht-grn -> +12V power). Each secondary is fused (F111-F114, F116, 5x20 mm) before its bridge: GBPC3510W block (BR3, 6223BG basket heatsink); 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
U20: TPS552892 buck-boost / 395 kHz / PFM / +5V / current limit 3.85 A nominal
Local output ceramics precede the sense resistor; bulk capacitors and feedback follow it. EXTVCC open selects internal VCC.
U21: TPS552892 buck-boost / 395 kHz / PFM / +12V / current limit 1.52 A nominal

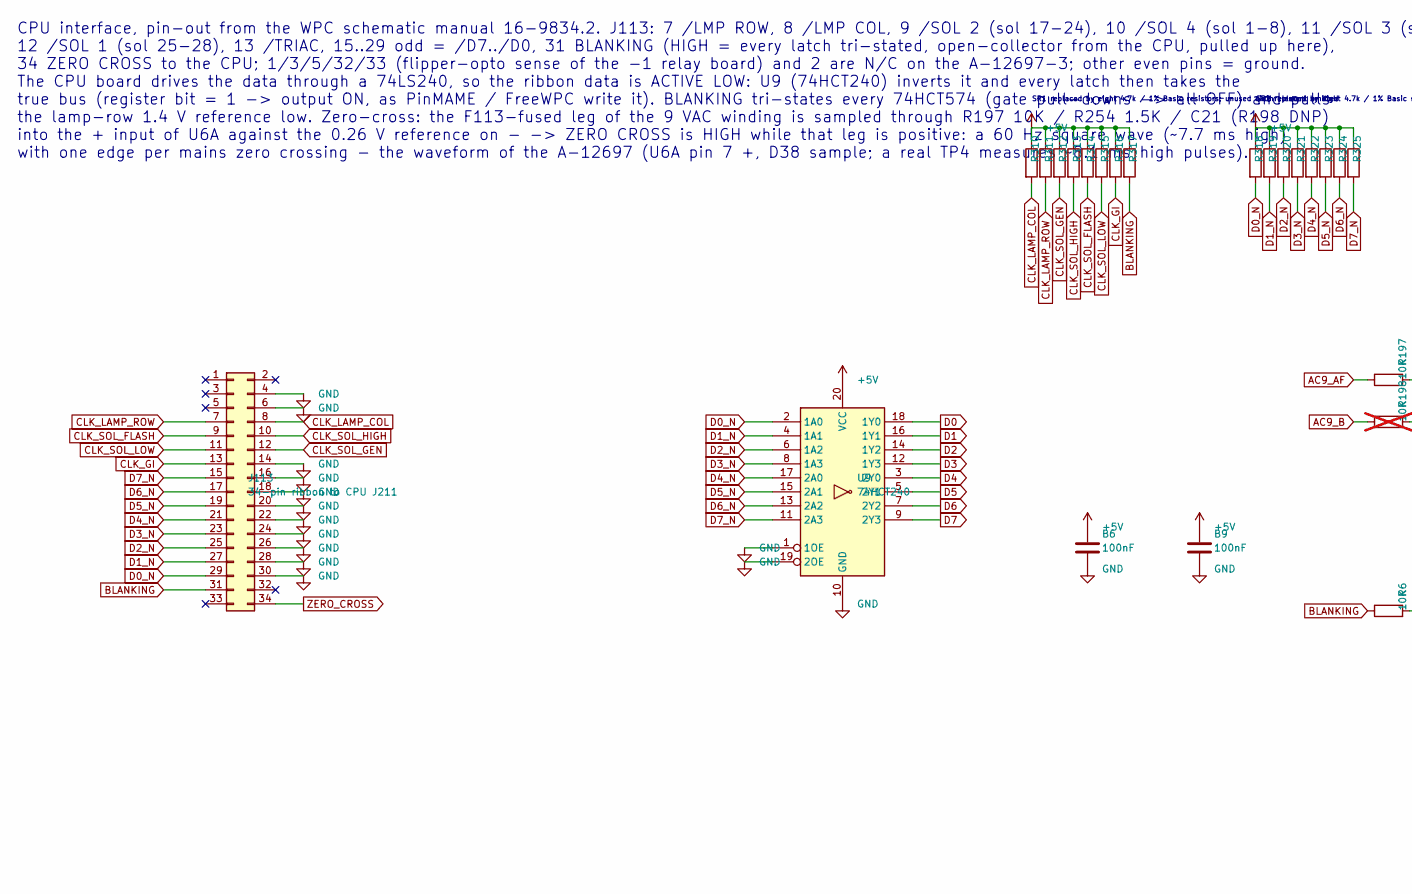
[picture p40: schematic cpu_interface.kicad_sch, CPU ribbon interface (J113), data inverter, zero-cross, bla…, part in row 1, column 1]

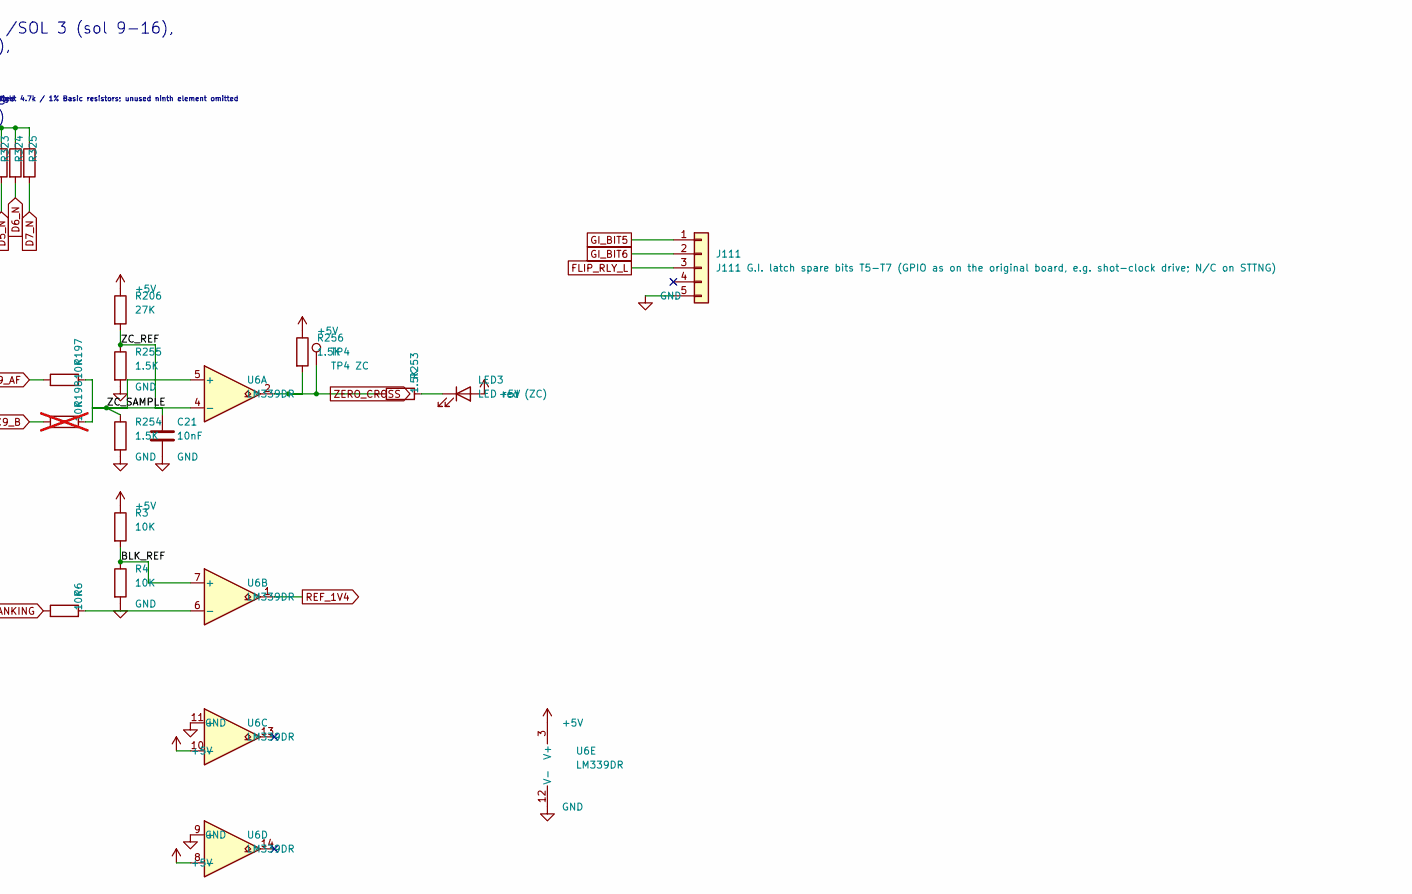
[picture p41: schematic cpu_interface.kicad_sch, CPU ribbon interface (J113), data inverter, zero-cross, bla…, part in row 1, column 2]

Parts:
B6, B9: 100nF; C_0805_2012Metric; MPN CC0805KRX7R9BB104; JLCPCB Part C49678
C21: 10nF; C_0805_2012Metric; MPN CL21B103KBANNNC; JLCPCB Part C1710
J111: J111 G.I. latch spare bits T5-T7 (GPIO as on the 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; Molex_KK-254_AE-6410-05A_1x05_P2.54mm_Vertical; MPN 22232051; JLCPCB Part C588986
J113: 34-pin ribbon to CPU J211; 3M_N2534_6002_RB; MPN N2534-6002-RB; JLCPCB Part C17502444
LED3: LED red (ZC); LED_0805_2012Metric; MPN NCD0805R1; JLCPCB Part C84256
R3, R4, R6, R197: 10K; R_0805_2012Metric; MPN 0805W8F1002T5E; JLCPCB Part C17414
R198: 10K; R_0805_2012Metric; MPN RC0805FR-0710KL; not fitted
R206: 27K; R_0805_2012Metric; MPN 0805W8F2702T5E; JLCPCB Part C17593
R253, R254, R255, R256: 1.5K; R_0805_2012Metric; MPN 0805W8F1501T5E; JLCPCB Part C4310
R310, R311, R312, R313, R314, R315, R316, R317, R318, R319, R320, R321, R322, R323, R324, R325: 4.7K; R_0805_2012Metric; MPN 0805W8F4701T5E; JLCPCB Part C17673
TP4: TP4 ZC; TestPoint_THTPad_D2.0mm_Drill1.0mm
U6: LM339DR; SOIC-14_3.9x8.7mm_P1.27mm; MPN LM339DR; JLCPCB Part C7948
U9: 74HCT240; SOIC-20W_7.5x12.8mm_P1.27mm; MPN SN74HCT240DWR; JLCPCB Part C132264

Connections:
+5V: B6.1, B9.1, LED3.2 (A), R3.1, R206.1, R256.1, R310.1, R311.1, R312.1, R313.1, R314.1, R315.1, R316.1, R317.1, R318.1, R319.1, R320.1, R321.1, R322.1, R323.1, R324.1, R325.1, U6.3 (V+), U6.8 (-), U6.10 (-), U9.20 (VCC); also elsewhere on the board
/CPU_Interface/BLK_REF: R3.2, R4.1, U6.7 (+)
/CPU_Interface/ZC_REF: R206.2, R255.1, U6.4 (-)
/CPU_Interface/ZC_SAMPLE: C21.1, R197.2, R198.2, R254.1, U6.5 (+)
AC9_AF: R197.1; also elsewhere on the board
AC9_B: R198.1; also elsewhere on the board
BLANKING: J113.31, R6.1, R317.2; also elsewhere on the board
CLK_GI: J113.13, R316.2; also elsewhere on the board
CLK_LAMP_COL: J113.8, R310.2; also elsewhere on the board
CLK_LAMP_ROW: J113.7, R311.2; also elsewhere on the board
CLK_SOL_FLASH: J113.9, R314.2; also elsewhere on the board
CLK_SOL_GEN: J113.12, R312.2; also elsewhere on the board
CLK_SOL_HIGH: J113.10, R313.2; also elsewhere on the board
CLK_SOL_LOW: J113.11, R315.2; also elsewhere on the board
D0: U9.18 (1Y0); also elsewhere on the board
D0_N: J113.29, R318.2, U9.2 (1A0)
D1: U9.16 (1Y1); also elsewhere on the board
D1_N: J113.27, R319.2, U9.4 (1A1)
D2: U9.14 (1Y2); also elsewhere on the board
D2_N: J113.25, R320.2, U9.6 (1A2)
D3: U9.12 (1Y3); also elsewhere on the board
D3_N: J113.23, R321.2, U9.8 (1A3)
D4: U9.3 (2Y0); also elsewhere on the board
D4_N: J113.21, R322.2, U9.17 (2A0)
D5: U9.5 (2Y1); also elsewhere on the board
D5_N: J113.19, R323.2, U9.15 (2A1)
D6: U9.7 (2Y2); also elsewhere on the board
D6_N: J113.17, R324.2, U9.13 (2A2)
D7: U9.9 (2Y3); also elsewhere on the board
D7_N: J113.15, R325.2, U9.11 (2A3)
FLIP_RLY_L: J111.3; also elsewhere on the board
GI_BIT5: J111.1; also elsewhere on the board
GI_BIT6: J111.2; also elsewhere on the board
unnamed: LED3.1 (K), R253.2
unnamed: R6.2, U6.6 (-)
REF_1V4: U6.1; also elsewhere on the board
ZERO_CROSS: J113.34, R253.1, R256.2, TP4.1, U6.2

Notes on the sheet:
CPU interface, pin-out from the WPC schematic manual 16-9834.2. J113: 7 /LMP ROW, 8 /LMP COL, 9 /SOL 2 (sol 17-24), 10 /SOL 4 (sol 1-8), 11 /SOL 3 (sol 9-16), 12 /SOL 1 (sol 25-28), 13 /TRIAC, 15..29 odd = /D7../D0, 31 BLANKING (HIGH = every latch tri-stated, open-collector from the CPU, pulled up 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
SR1 replaced by eight 4.7k / 1% Basic resistors; unused ninth element omitted
SR2 replaced by eight 4.7k / 1% Basic resistors; unused ninth element omitted

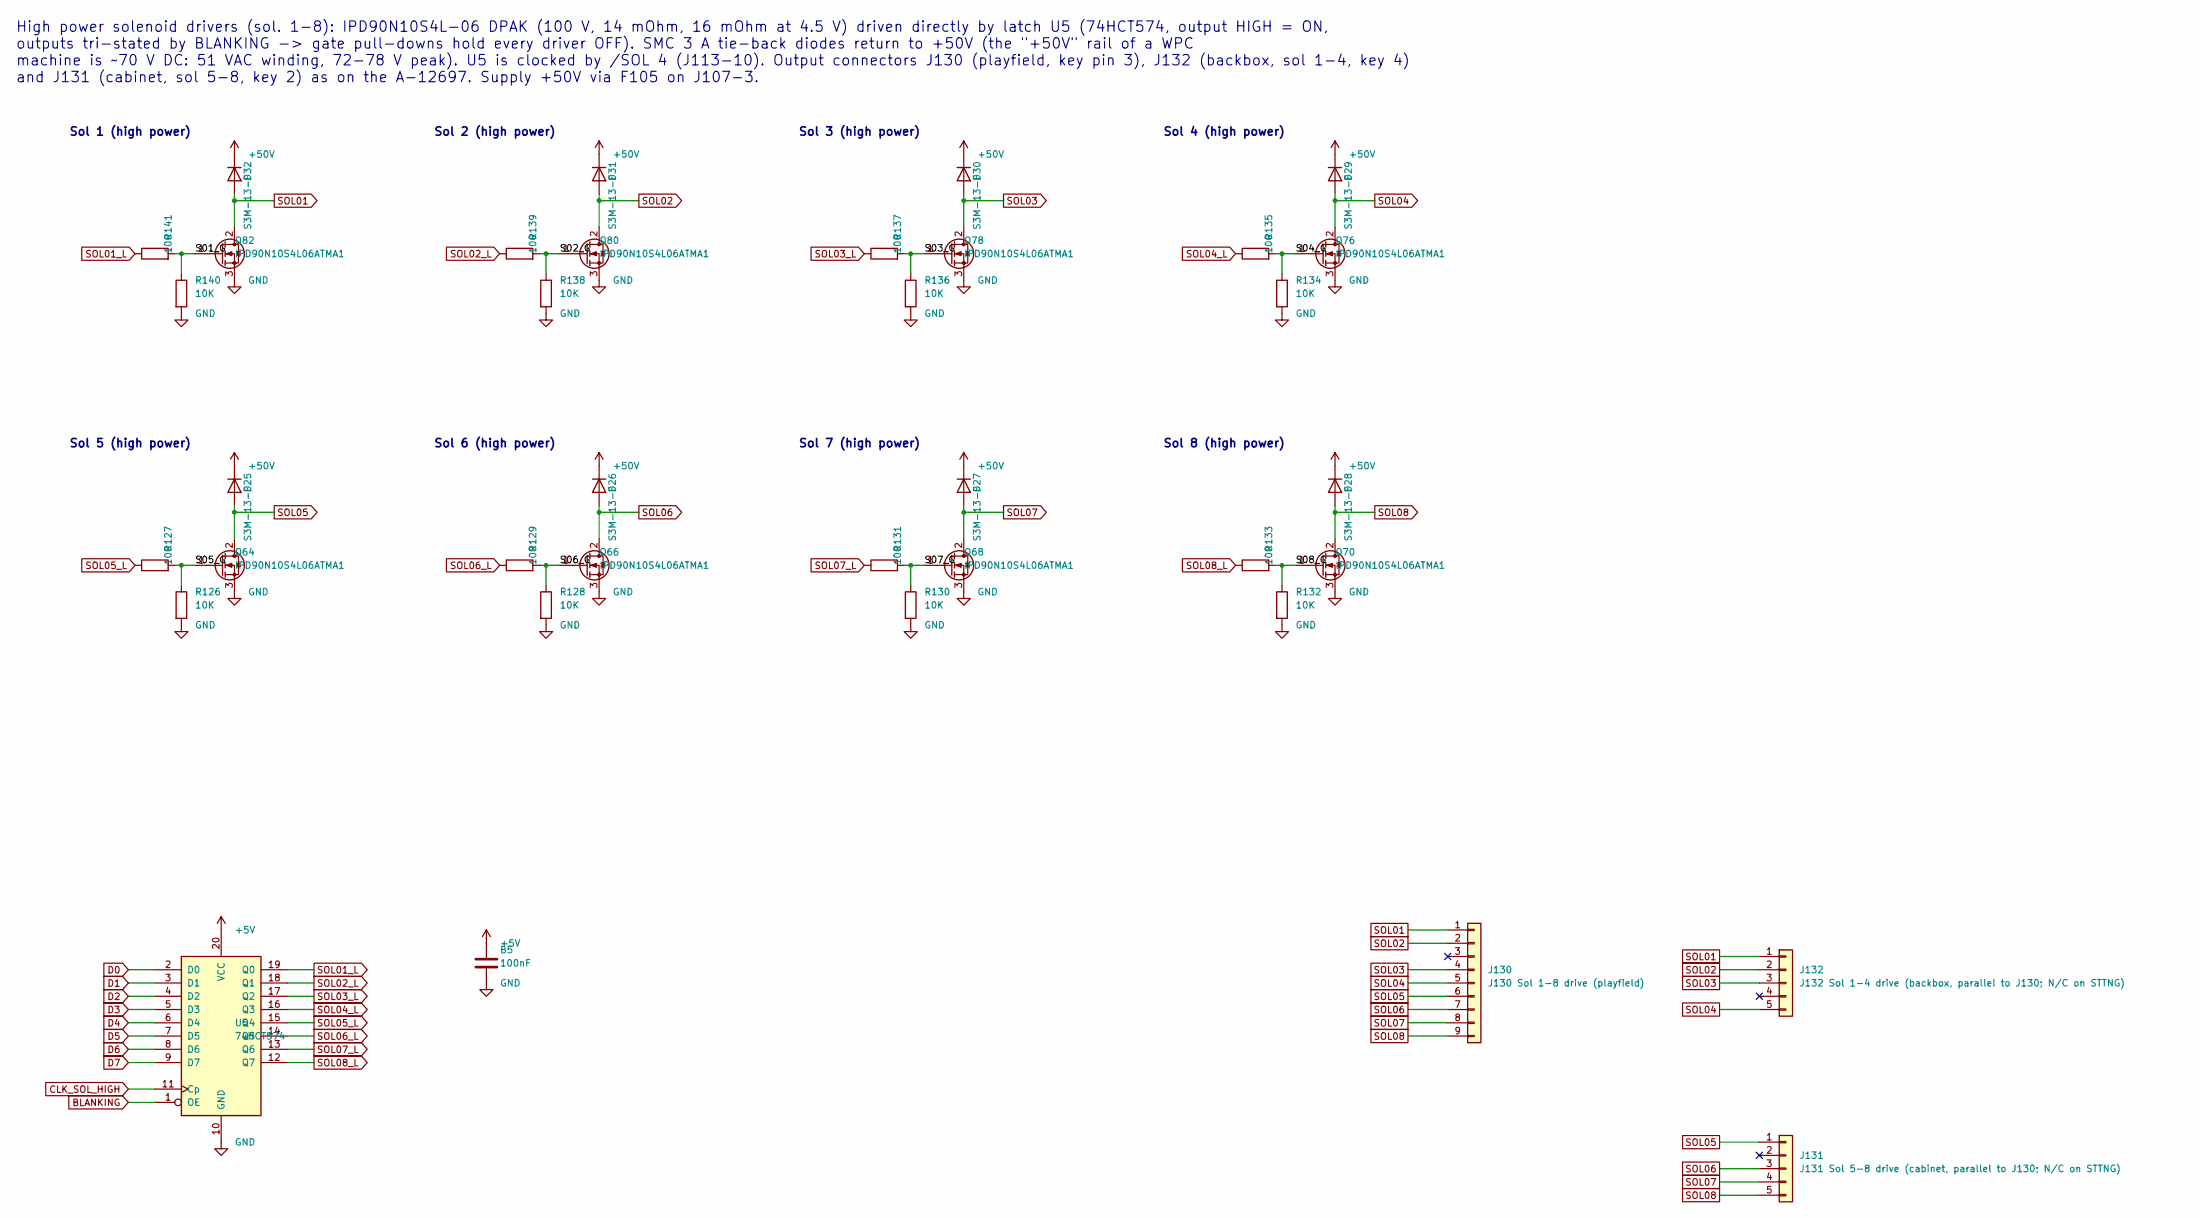
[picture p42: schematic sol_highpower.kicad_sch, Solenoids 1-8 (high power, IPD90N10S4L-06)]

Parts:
B5: 100nF; C_0805_2012Metric; MPN CC0805KRX7R9BB104; JLCPCB Part C49678
D25, D26, D27, D28, D29, D30, D31, D32: S3M-13-F; D_SMC; MPN S3M-13-F; JLCPCB Part C460944
J130: J130 Sol 1-8 drive (playfield); Molex_KK-396_A-41791-0009_1x09_P3.96mm_Vertical; MPN 0026604090; JLCPCB Part C17420444
J131: J131 Sol 5-8 drive (cabinet, parallel to J130; N/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; Molex_KK-396_A-41791-0005_1x05_P3.96mm_Vertical; MPN 26604050; JLCPCB Part C505166
J132: J132 Sol 1-4 drive (backbox, parallel to J130; N/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; Molex_KK-396_A-41791-0005_1x05_P3.96mm_Vertical; MPN 26604050; JLCPCB Part C505166
Q64, Q66, Q68, Q70, Q76, Q78, Q80, Q82: IPD90N10S4L06ATMA1; TO-252-2; MPN IPD90N10S4L06ATMA1; JLCPCB Part C5440942
R126, R128, R130, R132, R134, R136, R138, R140: 10K; R_0805_2012Metric; MPN 0805W8F1002T5E; JLCPCB Part C17414
R127, R129, R131, R133, R135, R137, R139, R141: 100; R_0805_2012Metric; MPN 0805W8F1000T5E; JLCPCB Part C17408
U5: 74HCT574; SOIC-20W_7.5x12.8mm_P1.27mm; MPN SN74HCT574DWR; JLCPCB Part C6788

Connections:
+5V: B5.1, U5.20 (VCC); also elsewhere on the board
+50V: D25.1 (K), D26.1 (K), D27.1 (K), D28.1 (K), D29.1 (K), D30.1 (K), D31.1 (K), D32.1 (K); also elsewhere on the board
/Sol_HighPower/S01_G: Q82.1 (G), R140.1, R141.2
/Sol_HighPower/S02_G: Q80.1 (G), R138.1, R139.2
/Sol_HighPower/S03_G: Q78.1 (G), R136.1, R137.2
/Sol_HighPower/S04_G: Q76.1 (G), R134.1, R135.2
/Sol_HighPower/S05_G: Q64.1 (G), R126.1, R127.2
/Sol_HighPower/S06_G: Q66.1 (G), R128.1, R129.2
/Sol_HighPower/S07_G: Q68.1 (G), R130.1, R131.2
/Sol_HighPower/S08_G: Q70.1 (G), R132.1, R133.2
BLANKING: U5.1 (OE); also elsewhere on the board
CLK_SOL_HIGH: U5.11 (Cp); also elsewhere on the board
D0: U5.2 (D0); also elsewhere on the board
D1: U5.3 (D1); also elsewhere on the board
D2: U5.4 (D2); also elsewhere on the board
D3: U5.5 (D3); also elsewhere on the board
D4: U5.6 (D4); also elsewhere on the board
D5: U5.7 (D5); also elsewhere on the board
D6: U5.8 (D6); also elsewhere on the board
D7: U5.9 (D7); also elsewhere on the board
SOL01: D32.2 (A), J130.1, J132.1, Q82.2 (D)
SOL01_L: R141.1, U5.19 (Q0)
SOL02: D31.2 (A), J130.2, J132.2, Q80.2 (D)
SOL02_L: R139.1, U5.18 (Q1)
SOL03: D30.2 (A), J130.4, J132.3, Q78.2 (D)
SOL03_L: R137.1, U5.17 (Q2)
SOL04: D29.2 (A), J130.5, J132.5, Q76.2 (D)
SOL04_L: R135.1, U5.16 (Q3)
SOL05: D25.2 (A), J130.6, J131.1, Q64.2 (D)
SOL05_L: R127.1, U5.15 (Q4)
SOL06: D26.2 (A), J130.7, J131.3, Q66.2 (D)
SOL06_L: R129.1, U5.14 (Q5)
SOL07: D27.2 (A), J130.8, J131.4, Q68.2 (D)
SOL07_L: R131.1, U5.13 (Q6)
SOL08: D28.2 (A), J130.9, J131.5, Q70.2 (D)
SOL08_L: R133.1, U5.12 (Q7)

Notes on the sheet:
Sol 1 (high power)
Sol 2 (high power)
Sol 3 (high power)
Sol 4 (high power)
Sol 5 (high power)
Sol 6 (high power)
Sol 7 (high power)
Sol 8 (high power)
High power solenoid drivers (sol. 1-8): IPD90N10S4L-06 DPAK (100 V, 14 mOhm, 16 mOhm at 4.5 V) driven directly by latch U5 (74HCT574, output HIGH = ON, outputs tri-stated by BLANKING -> gate pull-downs hold every driver OFF). SMC 3 A tie-back diodes return to +50V (the "+50V" rail of a WPC machine 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

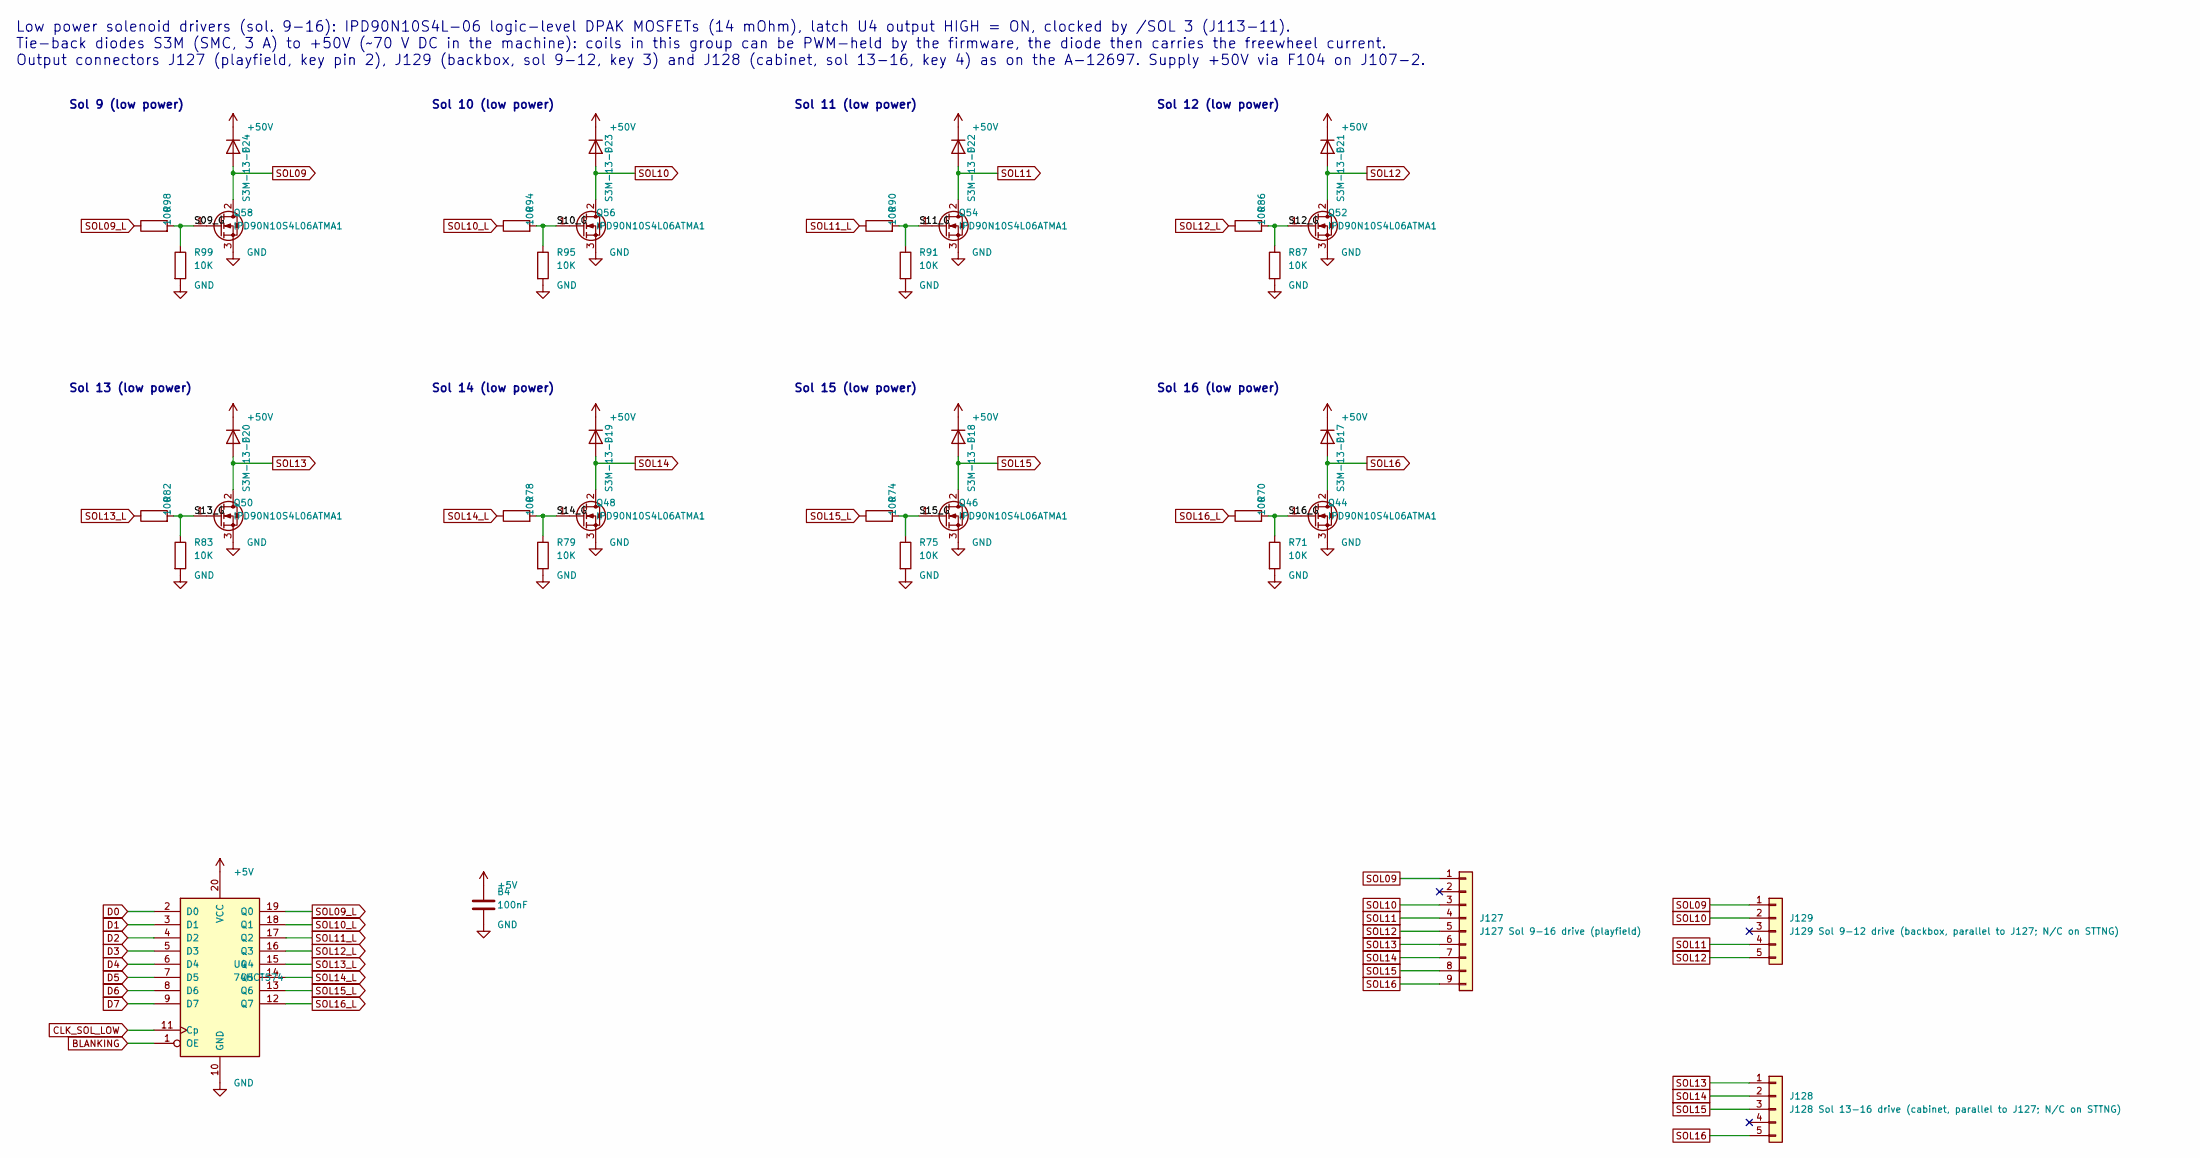
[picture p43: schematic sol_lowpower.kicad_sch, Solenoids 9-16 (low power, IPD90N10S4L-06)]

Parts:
B4: 100nF; C_0805_2012Metric; MPN CC0805KRX7R9BB104; JLCPCB Part C49678
D17, D18, D19, D20, D21, D22, D23, D24: S3M-13-F; D_SMC; MPN S3M-13-F; JLCPCB Part C460944
J127: J127 Sol 9-16 drive (playfield); Molex_KK-396_A-41791-0009_1x09_P3.96mm_Vertical; MPN 0026604090; JLCPCB Part C17420444
J128: J128 Sol 13-16 drive (cabinet, parallel to J127; 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; Molex_KK-396_A-41791-0005_1x05_P3.96mm_Vertical; MPN 26604050; JLCPCB Part C505166
J129: J129 Sol 9-12 drive (backbox, parallel to J127; N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; Molex_KK-396_A-41791-0005_1x05_P3.96mm_Vertical; MPN 26604050; JLCPCB Part C505166
Q44, Q46, Q48, Q50, Q52, Q54, Q56, Q58: IPD90N10S4L06ATMA1; TO-252-2; MPN IPD90N10S4L06ATMA1; JLCPCB Part C5440942
R70, R74, R78, R82, R86, R90, R94, R98: 100; R_0805_2012Metric; MPN 0805W8F1000T5E; JLCPCB Part C17408
R71, R75, R79, R83, R87, R91, R95, R99: 10K; R_0805_2012Metric; MPN 0805W8F1002T5E; JLCPCB Part C17414
U4: 74HCT574; SOIC-20W_7.5x12.8mm_P1.27mm; MPN SN74HCT574DWR; JLCPCB Part C6788

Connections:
+5V: B4.1, U4.20 (VCC); also elsewhere on the board
+50V: D17.1 (K), D18.1 (K), D19.1 (K), D20.1 (K), D21.1 (K), D22.1 (K), D23.1 (K), D24.1 (K); also elsewhere on the board
/Sol_LowPower/S09_G: Q58.1 (G), R98.2, R99.1
/Sol_LowPower/S10_G: Q56.1 (G), R94.2, R95.1
/Sol_LowPower/S11_G: Q54.1 (G), R90.2, R91.1
/Sol_LowPower/S12_G: Q52.1 (G), R86.2, R87.1
/Sol_LowPower/S13_G: Q50.1 (G), R82.2, R83.1
/Sol_LowPower/S14_G: Q48.1 (G), R78.2, R79.1
/Sol_LowPower/S15_G: Q46.1 (G), R74.2, R75.1
/Sol_LowPower/S16_G: Q44.1 (G), R70.2, R71.1
BLANKING: U4.1 (OE); also elsewhere on the board
CLK_SOL_LOW: U4.11 (Cp); also elsewhere on the board
D0: U4.2 (D0); also elsewhere on the board
D1: U4.3 (D1); also elsewhere on the board
D2: U4.4 (D2); also elsewhere on the board
D3: U4.5 (D3); also elsewhere on the board
D4: U4.6 (D4); also elsewhere on the board
D5: U4.7 (D5); also elsewhere on the board
D6: U4.8 (D6); also elsewhere on the board
D7: U4.9 (D7); also elsewhere on the board
SOL09: D24.2 (A), J127.1, J129.1, Q58.2 (D)
SOL09_L: R98.1, U4.19 (Q0)
SOL10: D23.2 (A), J127.3, J129.2, Q56.2 (D)
SOL10_L: R94.1, U4.18 (Q1)
SOL11: D22.2 (A), J127.4, J129.4, Q54.2 (D)
SOL11_L: R90.1, U4.17 (Q2)
SOL12: D21.2 (A), J127.5, J129.5, Q52.2 (D)
SOL12_L: R86.1, U4.16 (Q3)
SOL13: D20.2 (A), J127.6, J128.1, Q50.2 (D)
SOL13_L: R82.1, U4.15 (Q4)
SOL14: D19.2 (A), J127.7, J128.2, Q48.2 (D)
SOL14_L: R78.1, U4.14 (Q5)
SOL15: D18.2 (A), J127.8, J128.3, Q46.2 (D)
SOL15_L: R74.1, U4.13 (Q6)
SOL16: D17.2 (A), J127.9, J128.5, Q44.2 (D)
SOL16_L: R70.1, U4.12 (Q7)

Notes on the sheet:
Sol 9 (low power)
Sol 10 (low power)
Sol 11 (low power)
Sol 12 (low power)
Sol 13 (low power)
Sol 14 (low power)
Sol 15 (low power)
Sol 16 (low power)
Low power solenoid drivers (sol. 9-16): IPD90N10S4L-06 logic-level DPAK MOSFETs (14 mOhm), latch U4 output HIGH = ON, clocked by /SOL 3 (J113-11). Tie-back diodes S3M (SMC, 3 A) to +50V (~70 V DC in the machine): coils in this group can be PWM-held by the firmware, the diode then carries the freewh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

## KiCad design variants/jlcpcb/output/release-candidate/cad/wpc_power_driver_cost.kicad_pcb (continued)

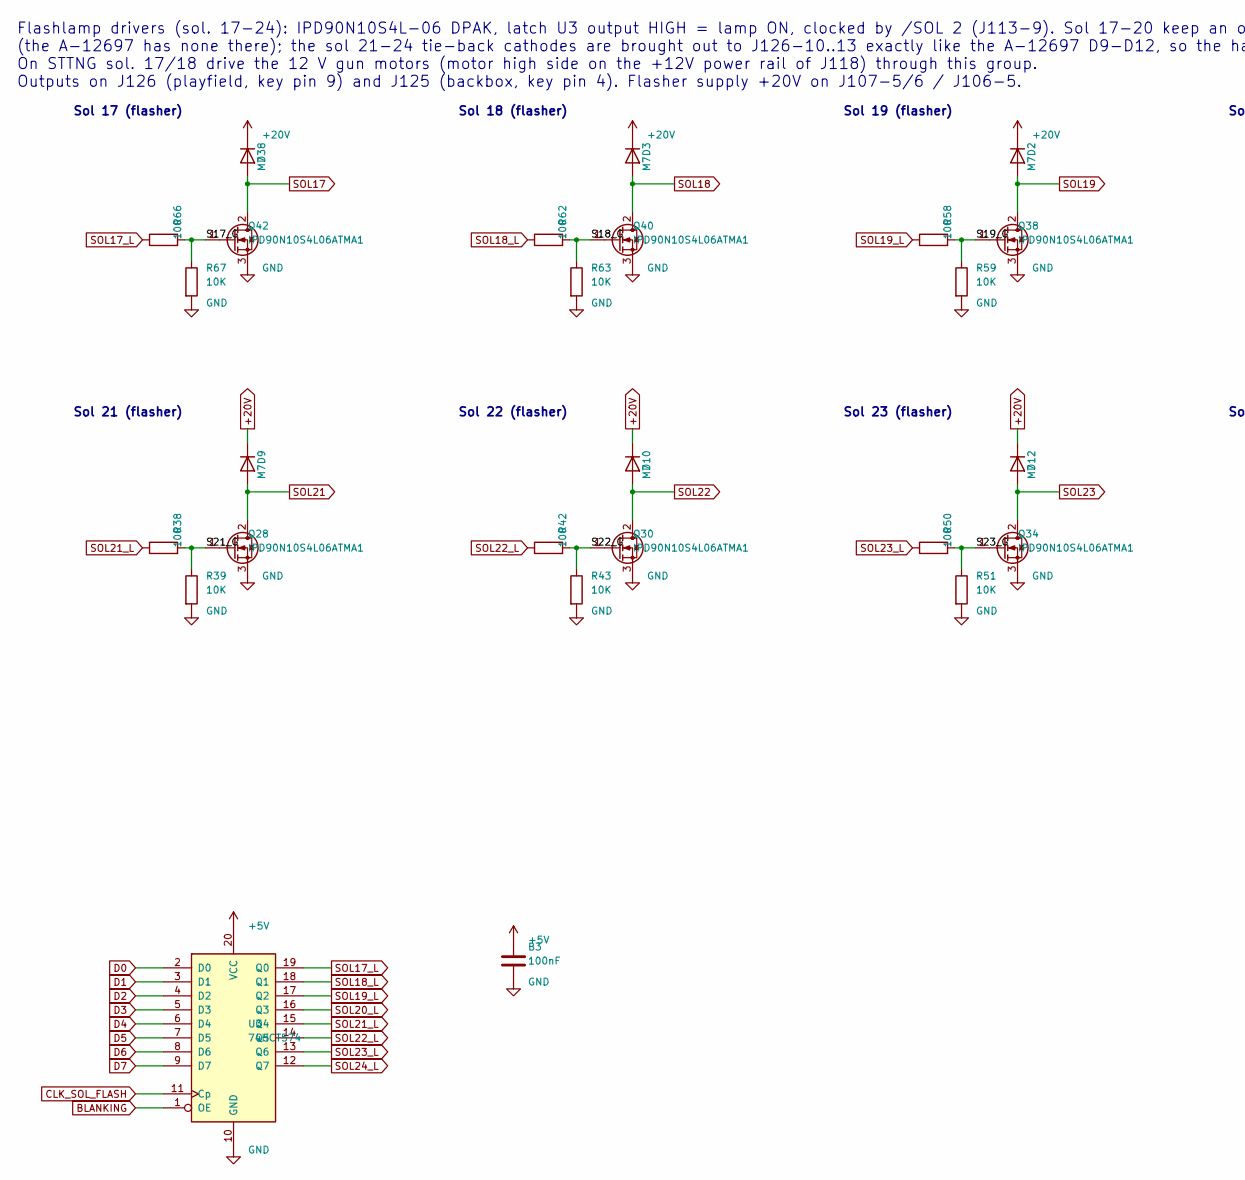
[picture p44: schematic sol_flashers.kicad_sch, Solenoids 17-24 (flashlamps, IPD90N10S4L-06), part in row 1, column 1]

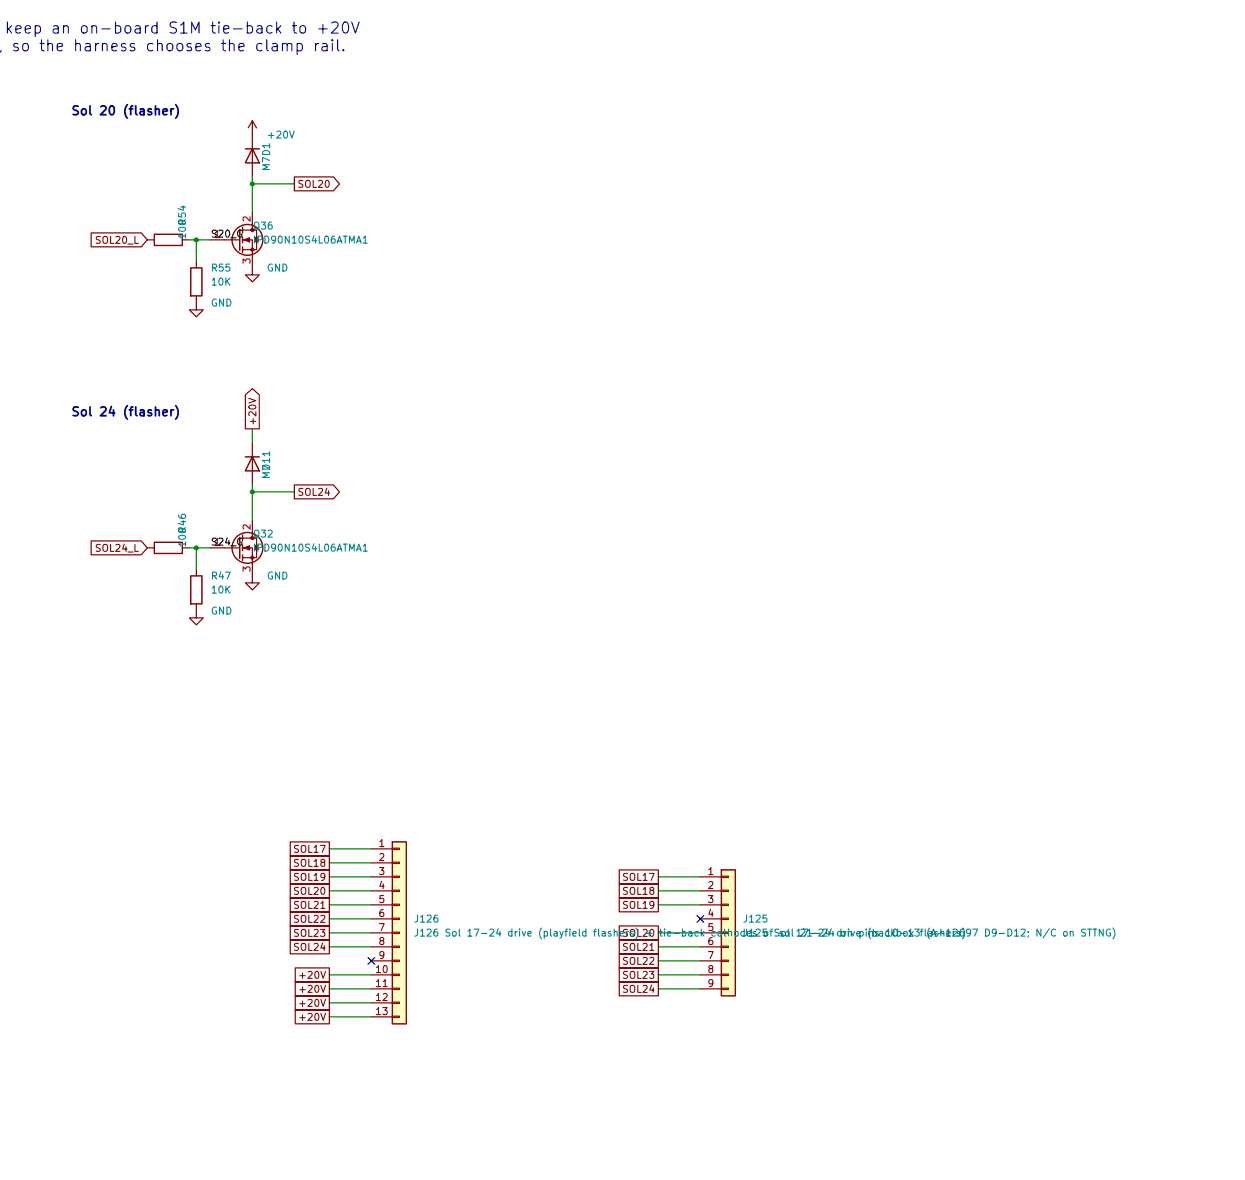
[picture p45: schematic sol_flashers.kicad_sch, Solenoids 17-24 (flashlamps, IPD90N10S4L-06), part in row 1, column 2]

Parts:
B3: 100nF; C_0805_2012Metric; MPN CC0805KRX7R9BB104; JLCPCB Part C49678
D1, D2, D3, D9, D10, D11, D12, D38: M7; D_SMA; MPN M7; JLCPCB Part C95872
J125: J125 Sol 17-24 drive (backbox flashers); Molex_KK-396_A-41791-0009_1x09_P3.96mm_Vertical; MPN 0026604090; JLCPCB Part C17420444
J126: J126 Sol 17-24 drive (playfield flashers) + tie-b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; Molex_KK-396_A-41791-0013_1x13_P3.96mm_Vertical; MPN 0026604130; JLCPCB Part C17226055
Q28, Q30, Q32, Q34, Q36, Q38, Q40, Q42: IPD90N10S4L06ATMA1; TO-252-2; MPN IPD90N10S4L06ATMA1; JLCPCB Part C5440942
R38, R42, R46, R50, R54, R58, R62, R66: 100; R_0805_2012Metric; MPN 0805W8F1000T5E; JLCPCB Part C17408
R39, R43, R47, R51, R55, R59, R63, R67: 10K; R_0805_2012Metric; MPN 0805W8F1002T5E; JLCPCB Part C17414
U3: 74HCT574; SOIC-20W_7.5x12.8mm_P1.27mm; MPN SN74HCT574DWR; JLCPCB Part C6788

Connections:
+5V: B3.1, U3.20 (VCC); also elsewhere on the board
+20V: D1.1 (K), D2.1 (K), D3.1 (K), D9.1 (K), D10.1 (K), D11.1 (K), D12.1 (K), D38.1 (K), J126.10, J126.11, J126.12, J126.13; also elsewhere on the board
/Sol_Flashers/S17_G: Q42.1 (G), R66.2, R67.1
/Sol_Flashers/S18_G: Q40.1 (G), R62.2, R63.1
/Sol_Flashers/S19_G: Q38.1 (G), R58.2, R59.1
/Sol_Flashers/S20_G: Q36.1 (G), R54.2, R55.1
/Sol_Flashers/S21_G: Q28.1 (G), R38.2, R39.1
/Sol_Flashers/S22_G: Q30.1 (G), R42.2, R43.1
/Sol_Flashers/S23_G: Q34.1 (G), R50.2, R51.1
/Sol_Flashers/S24_G: Q32.1 (G), R46.2, R47.1
BLANKING: U3.1 (OE); also elsewhere on the board
CLK_SOL_FLASH: U3.11 (Cp); also elsewhere on the board
D0: U3.2 (D0); also elsewhere on the board
D1: U3.3 (D1); also elsewhere on the board
D2: U3.4 (D2); also elsewhere on the board
D3: U3.5 (D3); also elsewhere on the board
D4: U3.6 (D4); also elsewhere on the board
D5: U3.7 (D5); also elsewhere on the board
D6: U3.8 (D6); also elsewhere on the board
D7: U3.9 (D7); also elsewhere on the board
SOL17: D38.2 (A), J125.1, J126.1, Q42.2 (D)
SOL17_L: R66.1, U3.19 (Q0)
SOL18: D3.2 (A), J125.2, J126.2, Q40.2 (D)
SOL18_L: R62.1, U3.18 (Q1)
SOL19: D2.2 (A), J125.3, J126.3, Q38.2 (D)
SOL19_L: R58.1, U3.17 (Q2)
SOL20: D1.2 (A), J125.5, J126.4, Q36.2 (D)
SOL20_L: R54.1, U3.16 (Q3)
SOL21: D9.2 (A), J125.6, J126.5, Q28.2 (D)
SOL21_L: R38.1, U3.15 (Q4)
SOL22: D10.2 (A), J125.7, J126.6, Q30.2 (D)
SOL22_L: R42.1, U3.14 (Q5)
SOL23: D12.2 (A), J125.8, J126.7, Q34.2 (D)
SOL23_L: R50.1, U3.13 (Q6)
SOL24: D11.2 (A), J125.9, J126.8, Q32.2 (D)
SOL24_L: R46.1, U3.12 (Q7)

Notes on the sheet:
Sol 17 (flasher)
Sol 18 (flasher)
Sol 19 (flasher)
Sol 20 (flasher)
Sol 21 (flasher)
Sol 22 (flasher)
Sol 23 (flasher)
Sol 24 (flasher)
Flashlamp drivers (sol. 17-24): IPD90N10S4L-06 DPAK, latch U3 output HIGH = lamp ON, clocked by /SOL 2 (J113-9). Sol 17-20 keep an on-board S1M tie-back to +20V (the A-12697 has none there); the sol 21-24 tie-back cathodes are brought out to J126-10..13 exactly like the A-12697 D9-D12, so the harne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

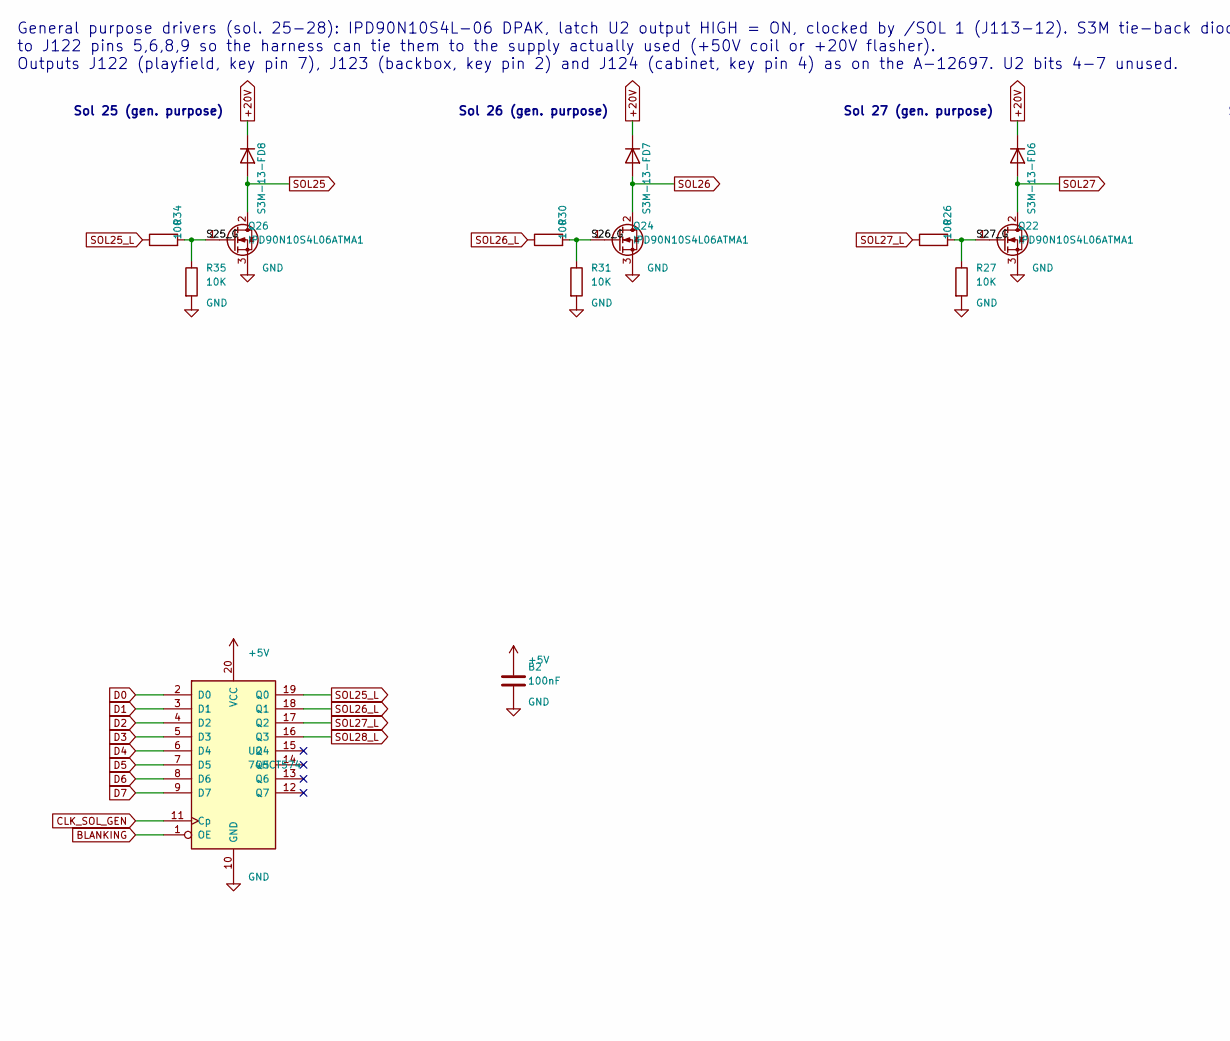
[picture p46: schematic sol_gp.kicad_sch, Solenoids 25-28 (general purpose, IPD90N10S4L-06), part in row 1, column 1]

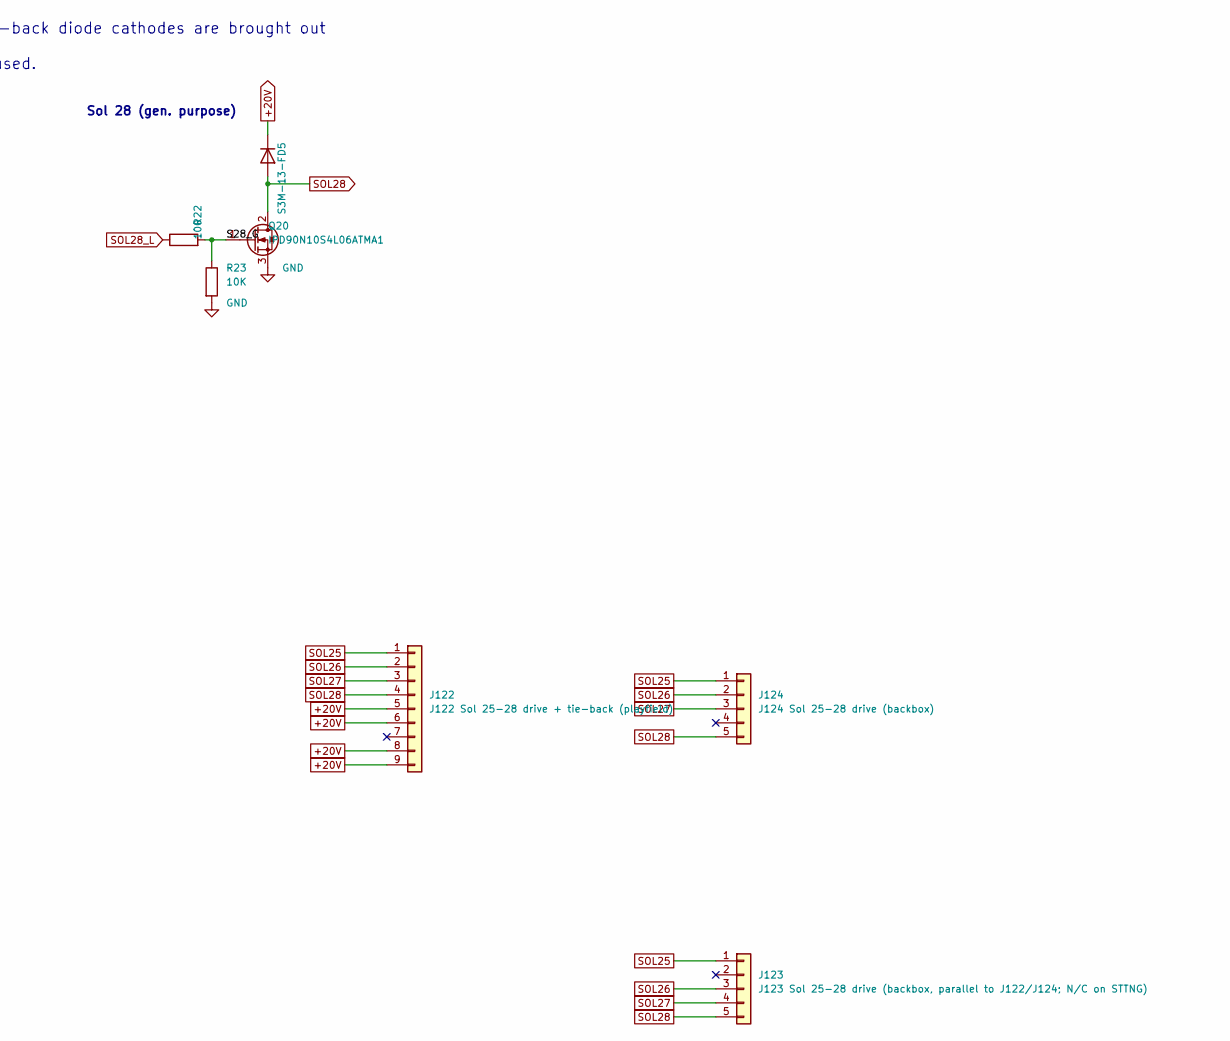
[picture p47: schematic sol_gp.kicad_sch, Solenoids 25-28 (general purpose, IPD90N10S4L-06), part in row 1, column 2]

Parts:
B2: 100nF; C_0805_2012Metric; MPN CC0805KRX7R9BB104; JLCPCB Part C49678
D5, D6, D7, D8: S3M-13-F; D_SMC; MPN S3M-13-F; JLCPCB Part C460944
J122: J122 Sol 25-28 drive + tie-back (playfield); Molex_KK-396_A-41791-0009_1x09_P3.96mm_Vertical; MPN 0026604090; JLCPCB Part C17420444
J123: J123 Sol 25-28 drive (backbox, parallel to J122/J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; Molex_KK-396_A-41791-0005_1x05_P3.96mm_Vertical; MPN 26604050; JLCPCB Part C505166
J124: J124 Sol 25-28 drive (backbox); Molex_KK-396_A-41791-0005_1x05_P3.96mm_Vertical; MPN 26604050; JLCPCB Part C505166
Q20, Q22, Q24, Q26: IPD90N10S4L06ATMA1; TO-252-2; MPN IPD90N10S4L06ATMA1; JLCPCB Part C5440942
R22, R26, R30, R34: 100; R_0805_2012Metric; MPN 0805W8F1000T5E; JLCPCB Part C17408
R23, R27, R31, R35: 10K; R_0805_2012Metric; MPN 0805W8F1002T5E; JLCPCB Part C17414
U2: 74HCT574; SOIC-20W_7.5x12.8mm_P1.27mm; MPN SN74HCT574DWR; JLCPCB Part C6788

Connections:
+5V: B2.1, U2.20 (VCC); also elsewhere on the board
+20V: D5.1 (K), D6.1 (K), D7.1 (K), D8.1 (K), J122.5, J122.6, J122.8, J122.9; also elsewhere on the board
/Sol_GeneralPurpose/S25_G: Q26.1 (G), R34.2, R35.1
/Sol_GeneralPurpose/S26_G: Q24.1 (G), R30.2, R31.1
/Sol_GeneralPurpose/S27_G: Q22.1 (G), R26.2, R27.1
/Sol_GeneralPurpose/S28_G: Q20.1 (G), R22.2, R23.1
BLANKING: U2.1 (OE); also elsewhere on the board
CLK_SOL_GEN: U2.11 (Cp); also elsewhere on the board
D0: U2.2 (D0); also elsewhere on the board
D1: U2.3 (D1); also elsewhere on the board
D2: U2.4 (D2); also elsewhere on the board
D3: U2.5 (D3); also elsewhere on the board
D4: U2.6 (D4); also elsewhere on the board
D5: U2.7 (D5); also elsewhere on the board
D6: U2.8 (D6); also elsewhere on the board
D7: U2.9 (D7); also elsewhere on the board
SOL25: D8.2 (A), J122.1, J123.1, J124.1, Q26.2 (D)
SOL25_L: R34.1, U2.19 (Q0)
SOL26: D7.2 (A), J122.2, J123.3, J124.2, Q24.2 (D)
SOL26_L: R30.1, U2.18 (Q1)
SOL27: D6.2 (A), J122.3, J123.4, J124.3, Q22.2 (D)
SOL27_L: R26.1, U2.17 (Q2)
SOL28: D5.2 (A), J122.4, J123.5, J124.5, Q20.2 (D)
SOL28_L: R22.1, U2.16 (Q3)

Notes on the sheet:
Sol 25 (gen. purpose)
Sol 26 (gen. purpose)
Sol 27 (gen. purpose)
Sol 28 (gen. purpose)
General purpose drivers (sol. 25-28): IPD90N10S4L-06 DPAK, latch U2 output HIGH = ON, clocked by /SOL 1 (J113-12). S3M tie-back diode cathodes are brought out to J122 pins 5,6,8,9 so the harness can tie them to the supply actually used (+50V coil or +20V flasher). Outputs J122 (playfield, key pin 7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

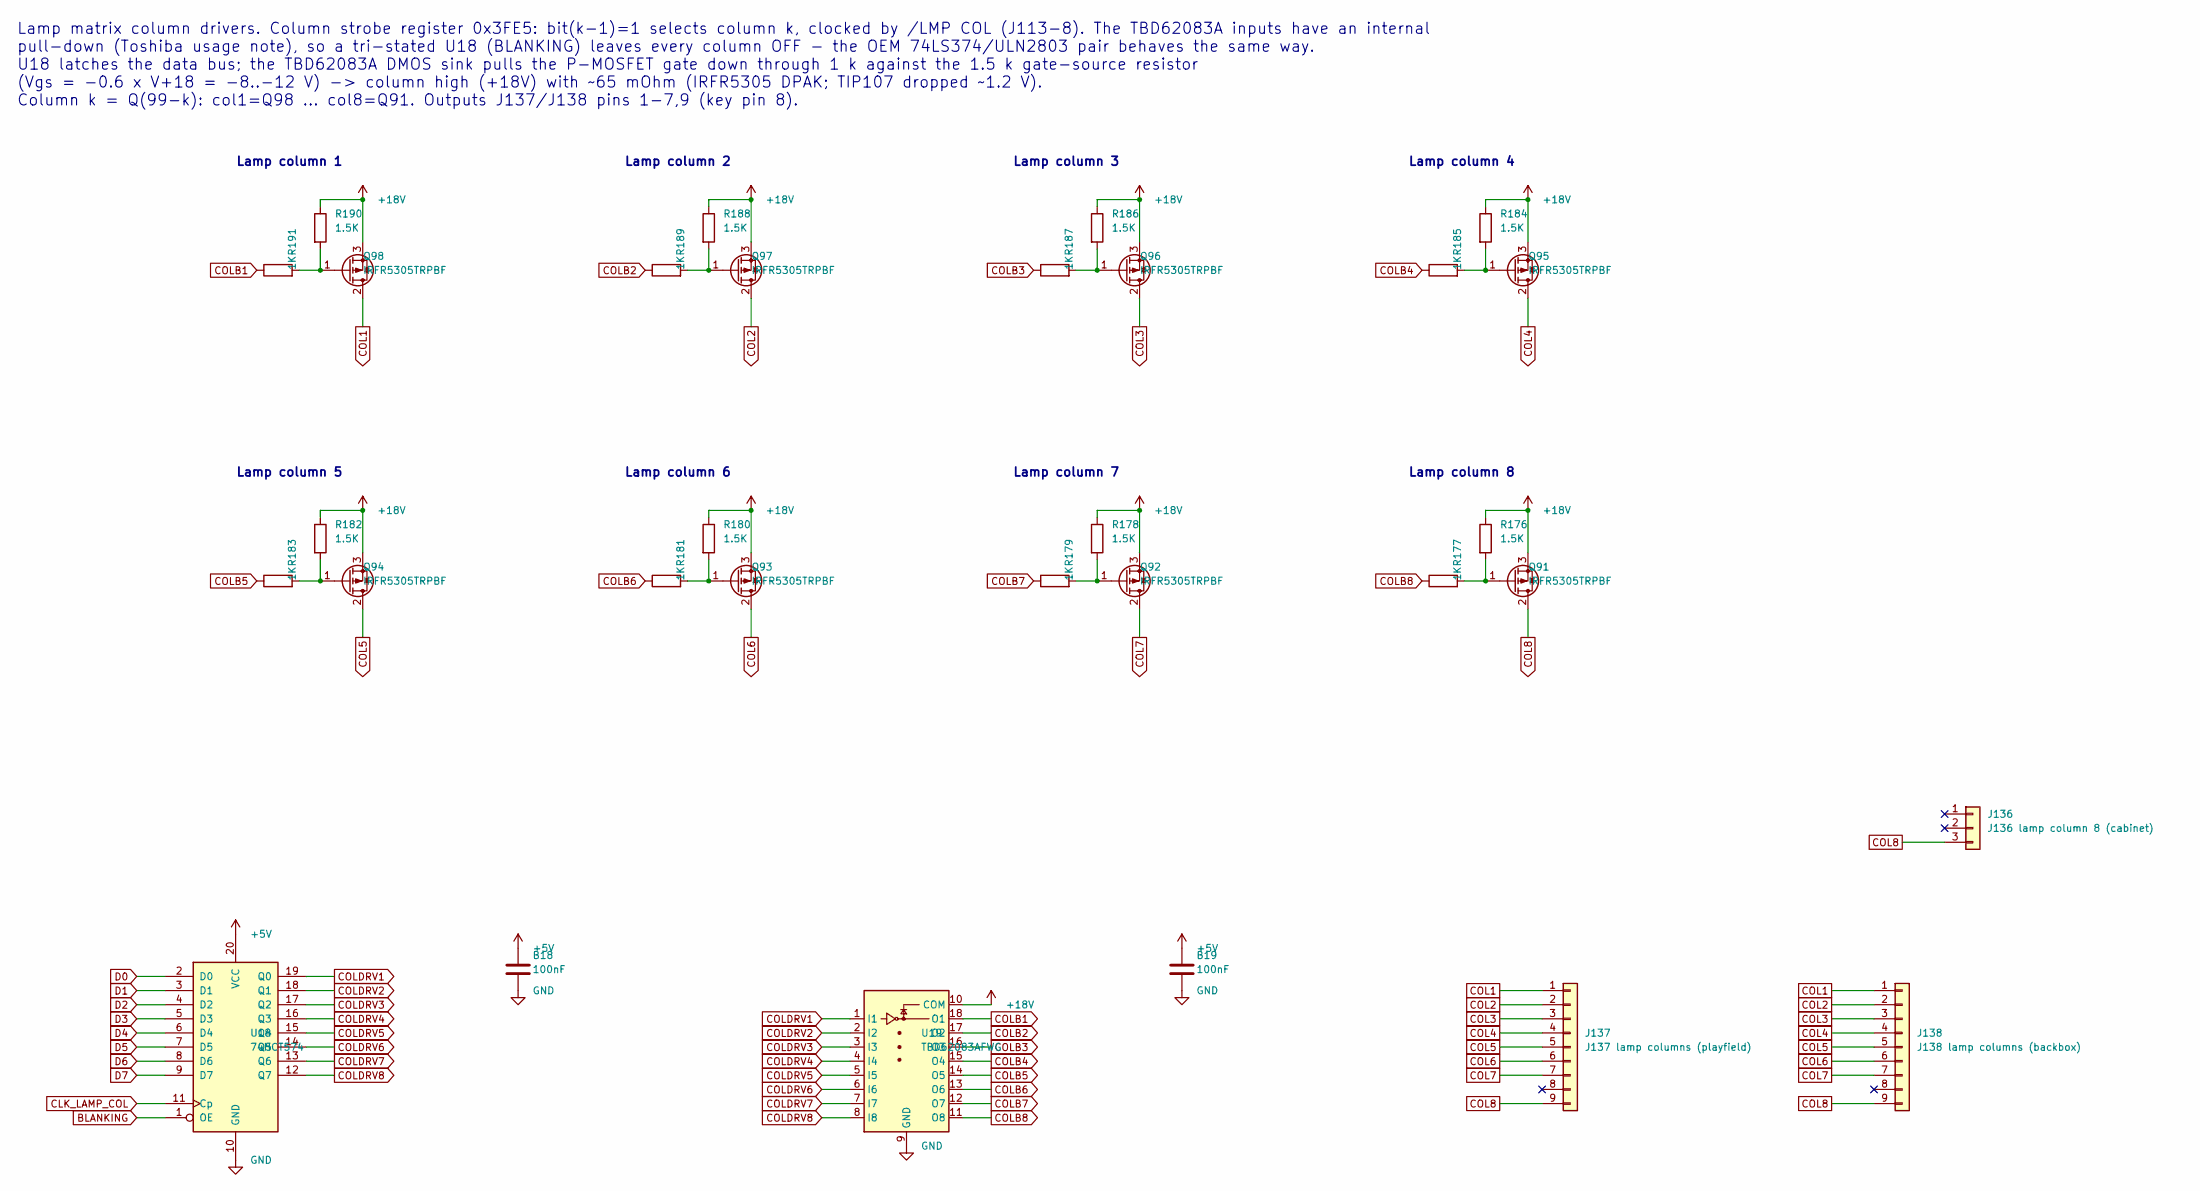
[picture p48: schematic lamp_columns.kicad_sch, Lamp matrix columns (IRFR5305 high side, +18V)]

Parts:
B18, B19: 100nF; C_0805_2012Metric; MPN CC0805KRX7R9BB104; JLCPCB Part C49678
J136: J136 lamp column 8 (cabinet); Molex_KK-396_A-41791-0003_1x03_P3.96mm_Vertical; MPN 26604030; JLCPCB Part C240823
J137: J137 lamp columns (playfield); Molex_KK-396_A-41791-0009_1x09_P3.96mm_Vertical; MPN 0026604090; JLCPCB Part C17420444
J138: J138 lamp columns (backbox); Molex_KK-396_A-41791-0009_1x09_P3.96mm_Vertical; MPN 0026604090; JLCPCB Part C17420444
Q91, Q92, Q93, Q94, Q95, Q96, Q97, Q98: IRFR5305TRPBF; TO-252-2; MPN IRFR5305TRPBF; JLCPCB Part C2624
R176, R178, R180, R182, R184, R186, R188, R190: 1.5K; R_0805_2012Metric; MPN 0805W8F1501T5E; JLCPCB Part C4310
R177, R179, R181, R183, R185, R187, R189, R191: 1K; R_0805_2012Metric; MPN 0805W8F1001T5E; JLCPCB Part C17513
U18: 74HCT574; SOIC-20W_7.5x12.8mm_P1.27mm; MPN SN74HCT574DWR; JLCPCB Part C6788
U19: TBD62083AFWG; SOIC-18W_7.5x11.6mm_P1.27mm; MPN TBD62083AFWG,EL; JLCPCB Part C165895

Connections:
+5V: B18.1, B19.1, U18.20 (VCC); also elsewhere on the board
+18V: Q91.3 (S), Q92.3 (S), Q93.3 (S), Q94.3 (S), Q95.3 (S), Q96.3 (S), Q97.3 (S), Q98.3 (S), R176.1, R178.1, R180.1, R182.1, R184.1, R186.1, R188.1, R190.1, U19.10 (COM); also elsewhere on the board
BLANKING: U18.1 (OE); also elsewhere on the board
CLK_LAMP_COL: U18.11 (Cp); also elsewhere on the board
COL1: J137.1, J138.1, Q98.2 (D)
COL2: J137.2, J138.2, Q97.2 (D)
COL3: J137.3, J138.3, Q96.2 (D)
COL4: J137.4, J138.4, Q95.2 (D)
COL5: J137.5, J138.5, Q94.2 (D)
COL6: J137.6, J138.6, Q93.2 (D)
COL7: J137.7, J138.7, Q92.2 (D)
COL8: J136.3, J137.9, J138.9, Q91.2 (D)
COLB1: R191.1, U19.18 (O1)
COLB2: R189.1, U19.17 (O2)
COLB3: R187.1, U19.16 (O3)
COLB4: R185.1, U19.15 (O4)
COLB5: R183.1, U19.14 (O5)
COLB6: R181.1, U19.13 (O6)
COLB7: R179.1, U19.12 (O7)
COLB8: R177.1, U19.11 (O8)
COLDRV1: U18.19 (Q0), U19.1 (I1)
COLDRV2: U18.18 (Q1), U19.2 (I2)
COLDRV3: U18.17 (Q2), U19.3 (I3)
COLDRV4: U18.16 (Q3), U19.4 (I4)
COLDRV5: U18.15 (Q4), U19.5 (I5)
COLDRV6: U18.14 (Q5), U19.6 (I6)
COLDRV7: U18.13 (Q6), U19.7 (I7)
COLDRV8: U18.12 (Q7), U19.8 (I8)
D0: U18.2 (D0); also elsewhere on the board
D1: U18.3 (D1); also elsewhere on the board
D2: U18.4 (D2); also elsewhere on the board
D3: U18.5 (D3); also elsewhere on the board
D4: U18.6 (D4); also elsewhere on the board
D5: U18.7 (D5); also elsewhere on the board
D6: U18.8 (D6); also elsewhere on the board
D7: U18.9 (D7); also elsewhere on the board
unnamed: Q91.1 (G), R176.2, R177.2
unnamed: Q92.1 (G), R178.2, R179.2
unnamed: Q93.1 (G), R180.2, R181.2
unnamed: Q94.1 (G), R182.2, R183.2
unnamed: Q95.1 (G), R184.2, R185.2
unnamed: Q96.1 (G), R186.2, R187.2
unnamed: Q97.1 (G), R188.2, R189.2
unnamed: Q98.1 (G), R190.2, R191.2

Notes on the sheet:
Lamp column 1
Lamp column 2
Lamp column 3
Lamp column 4
Lamp column 5
Lamp column 6
Lamp column 7
Lamp column 8
Lamp matrix column drivers. Column strobe register 0x3FE5: bit(k-1)=1 selects column k, clocked by /LMP COL (J113-8). The TBD62083A inputs have an internal pull-down (Toshiba usage note), so a tri-stated U18 (BLANKING) leaves every column OFF - the OEM 74LS374/ULN2803 pair behaves the same way. U18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

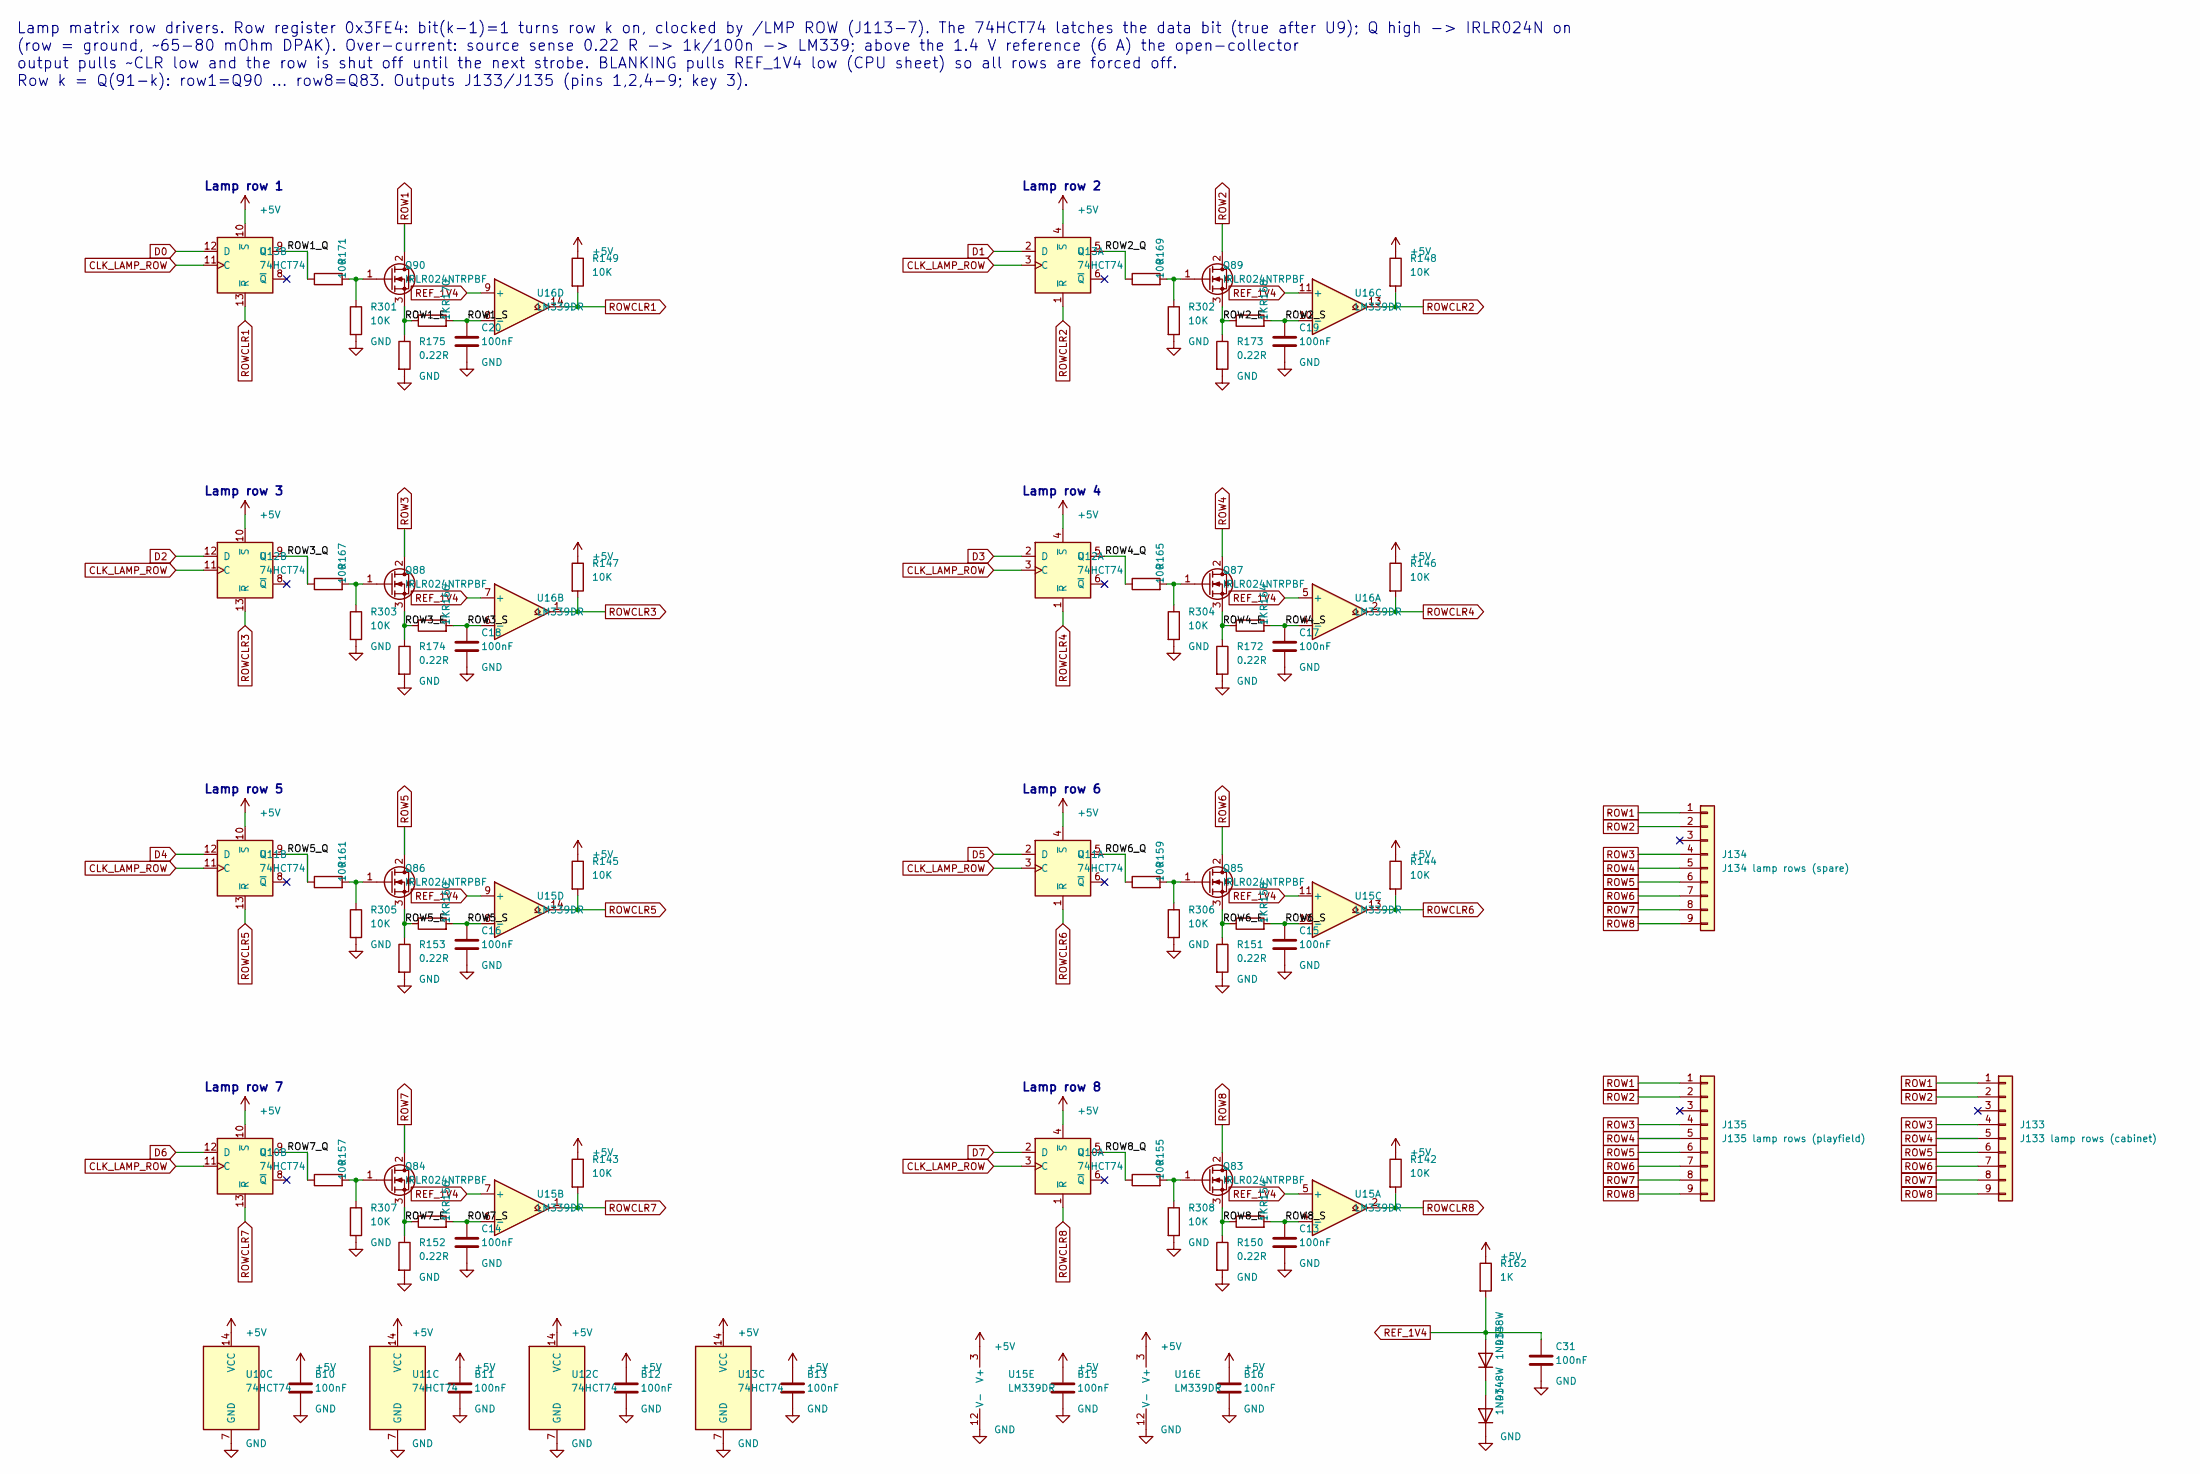
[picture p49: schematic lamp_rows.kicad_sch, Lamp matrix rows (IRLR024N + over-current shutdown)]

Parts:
B10, B11, B12, B13, B15, B16: 100nF; C_0805_2012Metric; MPN CC0805KRX7R9BB104; JLCPCB Part C49678
C13, C14, C15, C16, C17, C18, C19, C20, C31: 100nF; C_0805_2012Metric; MPN CC0805KRX7R9BB104; JLCPCB Part C49678
D33, D34: 1N4148W; D_SOD-123; MPN 1N4148W; JLCPCB Part C81598
J133: J133 lamp rows (cabinet); Molex_KK-254_AE-6410-09A_1x09_P2.54mm_Vertical; MPN 22232091; JLCPCB Part C587032
J134: J134 lamp rows (spare); Molex_KK-254_AE-6410-09A_1x09_P2.54mm_Vertical; MPN 22232091; JLCPCB Part C587032
J135: J135 lamp rows (playfield); Molex_KK-254_AE-6410-09A_1x09_P2.54mm_Vertical; MPN 22232091; JLCPCB Part C587032
Q83, Q84, Q85, Q86, Q87, Q88, Q89, Q90: IRLR024NTRPBF; TO-252-2; MPN IRLR024NTRPBF; JLCPCB Part C3007
R142, R143, R144, R145, R146, R147, R148, R149, R301, R302, R303, R304, R305, R306, R307, R308: 10K; R_0805_2012Metric; MPN 0805W8F1002T5E; JLCPCB Part C17414
R150, R151, R152, R153, R172, R173, R174, R175: 0.22R; R_2512_6332Metric; MPN RL2512FK-070R22L; JLCPCB Part C705613
R154, R156, R158, R160, R162, R164, R166, R168, R170: 1K; R_0805_2012Metric; MPN 0805W8F1001T5E; JLCPCB Part C17513
R155, R157, R159, R161, R165, R167, R169, R171: 100; R_0805_2012Metric; MPN 0805W8F1000T5E; JLCPCB Part C17408
U10, U11, U12, U13: 74HCT74; SOIC-14_3.9x8.7mm_P1.27mm; MPN SN74HCT74DR; JLCPCB Part C352961
U15, U16: LM339DR; SOIC-14_3.9x8.7mm_P1.27mm; MPN LM339DR; JLCPCB Part C7948

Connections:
+5V: B10.1, B11.1, B12.1, B13.1, B15.1, B16.1, R142.1, R143.1, R144.1, R145.1, R146.1, R147.1, R148.1, R149.1, R162.1, U10.4 (~S), U10.10 (~S), U10.14 (VCC), U11.4 (~S), U11.10 (~S), U11.14 (VCC), U12.4 (~S), U12.10 (~S), U12.14 (VCC), U13.4 (~S), U13.10 (~S), U13.14 (VCC), U15.3 (V+), U16.3 (V+); also elsewhere on the board
/Lamp_Rows/ROW1_E: Q90.3 (S), R170.1, R175.1
/Lamp_Rows/ROW1_Q: R171.1, U13.9 (Q)
/Lamp_Rows/ROW1_S: C20.1, R170.2, U16.8 (-)
/Lamp_Rows/ROW2_E: Q89.3 (S), R168.1, R173.1
/Lamp_Rows/ROW2_Q: R169.1, U13.5 (Q)
/Lamp_Rows/ROW2_S: C19.1, R168.2, U16.10 (-)
/Lamp_Rows/ROW3_E: Q88.3 (S), R166.1, R174.1
/Lamp_Rows/ROW3_Q: R167.1, U12.9 (Q)
/Lamp_Rows/ROW3_S: C18.1, R166.2, U16.6 (-)
/Lamp_Rows/ROW4_E: Q87.3 (S), R164.1, R172.1
/Lamp_Rows/ROW4_Q: R165.1, U12.5 (Q)
/Lamp_Rows/ROW4_S: C17.1, R164.2, U16.4 (-)
/Lamp_Rows/ROW5_E: Q86.3 (S), R153.1, R160.1
/Lamp_Rows/ROW5_Q: R161.1, U11.9 (Q)
/Lamp_Rows/ROW5_S: C16.1, R160.2, U15.8 (-)
/Lamp_Rows/ROW6_E: Q85.3 (S), R151.1, R158.1
/Lamp_Rows/ROW6_Q: R159.1, U11.5 (Q)
/Lamp_Rows/ROW6_S: C15.1, R158.2, U15.10 (-)
/Lamp_Rows/ROW7_E: Q84.3 (S), R152.1, R156.1
/Lamp_Rows/ROW7_Q: R157.1, U10.9 (Q)
/Lamp_Rows/ROW7_S: C14.1, R156.2, U15.6 (-)
/Lamp_Rows/ROW8_E: Q83.3 (S), R150.1, R154.1
/Lamp_Rows/ROW8_Q: R155.1, U10.5 (Q)
/Lamp_Rows/ROW8_S: C13.1, R154.2, U15.4 (-)
CLK_LAMP_ROW: U10.3 (C), U10.11 (C), U11.3 (C), U11.11 (C), U12.3 (C), U12.11 (C), U13.3 (C), U13.11 (C); also elsewhere on the board
D0: U13.12 (D); also elsewhere on the board
D1: U13.2 (D); also elsewhere on the board
D2: U12.12 (D); also elsewhere on the board
D3: U12.2 (D); also elsewhere on the board
D4: U11.12 (D); also elsewhere on the board
D5: U11.2 (D); also elsewhere on the board
D6: U10.12 (D); also elsewhere on the board
D7: U10.2 (D); also elsewhere on the board
unnamed: D33.1 (K), D34.2 (A)
unnamed: Q83.1 (G), R155.2, R308.1
unnamed: Q84.1 (G), R157.2, R307.1
unnamed: Q85.1 (G), R159.2, R306.1
unnamed: Q86.1 (G), R161.2, R305.1
unnamed: Q87.1 (G), R165.2, R304.1
unnamed: Q88.1 (G), R167.2, R303.1
unnamed: Q89.1 (G), R169.2, R302.1
unnamed: Q90.1 (G), R171.2, R301.1
REF_1V4: C31.1, D33.2 (A), R162.2, U15.5 (+), U15.7 (+), U15.9 (+), U15.11 (+), U16.5 (+), U16.7 (+), U16.9 (+), U16.11 (+); also elsewhere on the board
ROW1: J133.1, J134.1, J135.1, Q90.2 (D)
ROW2: J133.2, J134.2, J135.2, Q89.2 (D)
ROW3: J133.4, J134.4, J135.4, Q88.2 (D)
ROW4: J133.5, J134.5, J135.5, Q87.2 (D)
ROW5: J133.6, J134.6, J135.6, Q86.2 (D)
ROW6: J133.7, J134.7, J135.7, Q85.2 (D)
ROW7: J133.8, J134.8, J135.8, Q84.2 (D)
ROW8: J133.9, J134.9, J135.9, Q83.2 (D)
ROWCLR1: R149.2, U13.13 (~R), U16.14
ROWCLR2: R148.2, U13.1 (~R), U16.13
ROWCLR3: R147.2, U12.13 (~R), U16.1
ROWCLR4: R146.2, U12.1 (~R), U16.2
ROWCLR5: R145.2, U11.13 (~R), U15.14
ROWCLR6: R144.2, U11.1 (~R), U15.13
ROWCLR7: R143.2, U10.13 (~R), U15.1
ROWCLR8: R142.2, U10.1 (~R), U15.2

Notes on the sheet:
Lamp row 1
Lamp row 2
Lamp row 3
Lamp row 4
Lamp row 5
Lamp row 6
Lamp row 7
Lamp row 8
Lamp matrix row drivers. Row register 0x3FE4: bit(k-1)=1 turns row k on, clocked by /LMP ROW (J113-7). The 74HCT74 latches the data bit (true after U9); Q high -> IRLR024N on (row = ground, ~65-80 mOhm DPAK). Over-current: source sense 0.22 R -> 1k/100n -> LM339; above the 1.4 V reference (6 A) the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

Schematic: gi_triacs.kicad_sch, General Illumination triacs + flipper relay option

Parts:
B1: 100nF; C_0805_2012Metric; MPN CC0805KRX7R9BB104; JLCPCB Part C49678
D35: S1M (DNP); D_SMA; MPN S1M-13-F; not fitted
F101, F102: no fuse (clips only); Fuseholder_Clip-5x20mm_Keystone_3517_Inline_P23.11x6.76mm_D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; MPN 3517; JLCPCB Part C3029536
F106, F107, F108, F109, F110: 5A S.B.; Fuseholder_Clip-5x20mm_Keystone_3517_Inline_P23.11x6.76mm_D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; MPN 0239005.MXP; JLCPCB Part C151086
J105: J105 fused 51VAC (F112, pins 1/2) and fused 16VAC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; Molex_KK-396_A-41791-0005_1x05_P3.96mm_Vertical; MPN 26604050; JLCPCB Part C505166
J115: J115 G.I. 6.3VAC from transformer: 2-6 string hot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; Molex_KK-396_A-41791-0012_1x12_P3.96mm_Vertical; MPN 26-60-4120; JLCPCB Part C7426778
J119: J119 G.I. coin door (string 5); Molex_KK-396_A-41791-0003_1x03_P3.96mm_Vertical; MPN 26604030; JLCPCB Part C240823
J120: J120 G.I. strings 1-5 (backbox harness uses strin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; Molex_KK-396_A-41791-0011_1x11_P3.96mm_Vertical; MPN 26604110; JLCPCB Part C17541501
J121: J121 G.I. strings 1-5 (playfield harness uses str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; Molex_KK-396_A-41791-0011_1x11_P3.96mm_Vertical; MPN 26604110; JLCPCB Part C17541501
Q3: IPD90N10S4L06ATMA1; TO-252-2; MPN IPD90N10S4L06ATMA1; not fitted
Q9, Q11, Q13, Q15, Q17: MMBT4401; SOT-23; MPN MMBT4401-7-F; JLCPCB Part C151826
Q10, Q12, Q14, Q16, Q18: BTA16-600CRG; TO-220-3_Vertical; MPN BTA16-600CRG; JLCPCB Part C39797
R7, R10, R13, R16, R19: 27; R_2512_6332Metric; MPN RC2512JK-0727RL; JLCPCB Part C1882619
R8, R11, R14, R17, R20: 470; R_0805_2012Metric; MPN 0805W8F4700T5E; JLCPCB Part C17710
R9, R12, R15, R18, R21: 10K; R_0805_2012Metric; MPN 0805W8F1002T5E; JLCPCB Part C17414
R202: 100 (DNP); R_0805_2012Metric; MPN RC0805FR-07100RL; not fitted
R209: 10K (DNP); R_0805_2012Metric; MPN RC0805FR-0710KL; not fitted
RLY1: G2RL-2 12V (DNP); Relay_DPDT_Omron_G2RL-2; MPN G2RL-2 DC12; not fitted
U1: 74HCT574; SOIC-20W_7.5x12.8mm_P1.27mm; MPN SN74HCT574DWR; JLCPCB Part C6788
W1: 0R; R_2512_6332Metric; MPN RC2512JK-070RL; JLCPCB Part C189505

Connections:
+5V: B1.1, Q9.3 (C), Q11.3 (C), Q13.3 (C), Q15.3 (C), Q17.3 (C), U1.20 (VCC); also elsewhere on the board
+12V: D35.1 (K), RLY1.A1; also elsewhere on the board
/GI_Triacs/GI1_G: Q18.3 (G), R19.2
/GI_Triacs/GI2_G: Q10.3 (G), R7.2
/GI_Triacs/GI3_G: Q14.3 (G), R13.2
/GI_Triacs/GI4_G: Q16.3 (G), R16.2
/GI_Triacs/GI5_G: Q12.3 (G), R10.2
/GI_Triacs/RLY_COIL: D35.2 (A), Q3.2 (D), RLY1.A2
AC16_A_F: J105.4; also elsewhere on the board
AC16_B: J105.5; also elsewhere on the board
ACSOL_A: RLY1.11, RLY1.21; also elsewhere on the board
ACSOL_A_F: J105.1; also elsewhere on the board
ACSOL_B: J105.2; also elsewhere on the board
BLANKING: U1.1 (OE); also elsewhere on the board
CLK_GI: U1.11 (Cp); also elsewhere on the board
D0: U1.2 (D0); also elsewhere on the board
D1: U1.3 (D1); also elsewhere on the board
D2: U1.4 (D2); also elsewhere on the board
D3: U1.5 (D3); also elsewhere on the board
D4: U1.6 (D4); also elsewhere on the board
D5: U1.7 (D5); also elsewhere on the board
D6: U1.8 (D6); also elsewhere on the board
D7: U1.9 (D7); also elsewhere on the board
FLIP_RLY_L: R202.1, U1.12 (Q7); also elsewhere on the board
GI1_IN: F110.1, J115.2
GI1_L: R20.1, U1.19 (Q0)
GI1_OUT: F110.2, J120.7, J121.7
GI1_RET: J120.1, J121.1, Q18.2 (A2)
GI2_IN: F109.1, J115.4
GI2_L: R8.1, U1.18 (Q1)
GI2_OUT: F109.2, J120.8, J121.8
GI2_RET: J120.2, J121.2, Q10.2 (A2)
GI3_IN: F108.1, J115.5
GI3_L: R14.1, U1.17 (Q2)
GI3_OUT: F108.2, J120.9, J121.9
GI3_RET: J120.3, J121.3, Q14.2 (A2)
GI4_IN: F107.1, J115.3
GI4_L: R17.1, U1.16 (Q3)
GI4_OUT: F107.2, J120.10, J121.10
GI4_RET: J120.5, J121.5, Q16.2 (A2)
GI5_IN: F106.1, J115.6
GI5_L: R11.1, U1.15 (Q4)
GI5_OUT: F106.2, J119.1, J120.11, J121.11
GI5_RET: J119.3, J120.6, J121.6, Q12.2 (A2)
GI_BIT5: U1.14 (Q5); also elsewhere on the board
GI_BIT6: U1.13 (Q6); also elsewhere on the board
GI_RET: J115.7, J115.8, J115.10, J115.11, J115.12, Q10.1 (A1), Q12.1 (A1), Q14.1 (A1), Q16.1 (A1), Q18.1 (A1), W1.1
unnamed: F101.2, RLY1.14
unnamed: F102.2, RLY1.24
unnamed: Q3.1 (G), R202.2, R209.1
unnamed: Q9.1 (B), R8.2, R9.1
unnamed: Q9.2 (E), R7.1
unnamed: Q11.1 (B), R11.2, R12.1
unnamed: Q11.2 (E), R10.1
unnamed: Q13.1 (B), R14.2, R15.1
unnamed: Q13.2 (E), R13.1
unnamed: Q15.1 (B), R17.2, R18.1
unnamed: Q15.2 (E), R16.1
unnamed: Q17.1 (B), R20.2, R21.1
unnamed: Q17.2 (E), R19.1

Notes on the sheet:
G.I. string #1 (Wht-Brn / Brn)
G.I. string #2 (Wht-Org / Org)
G.I. string #3 (Wht-Yel / Yel)
G.I. string #4 (Wht-Grn / Grn)
G.I. string #5 (Wht-Vio / Vio)
General illumination: each 6.3VAC string is fused (F106-F110) on the hot side and switched by a triac in the RETURN path; MT1 of the five triacs form the GI_RET bus that goes back to the transformer on J115-7/8/10/11/12 and is referenced to logic ground by W1 (OEM: J115-1 GND REF), so the 5 x 5 A r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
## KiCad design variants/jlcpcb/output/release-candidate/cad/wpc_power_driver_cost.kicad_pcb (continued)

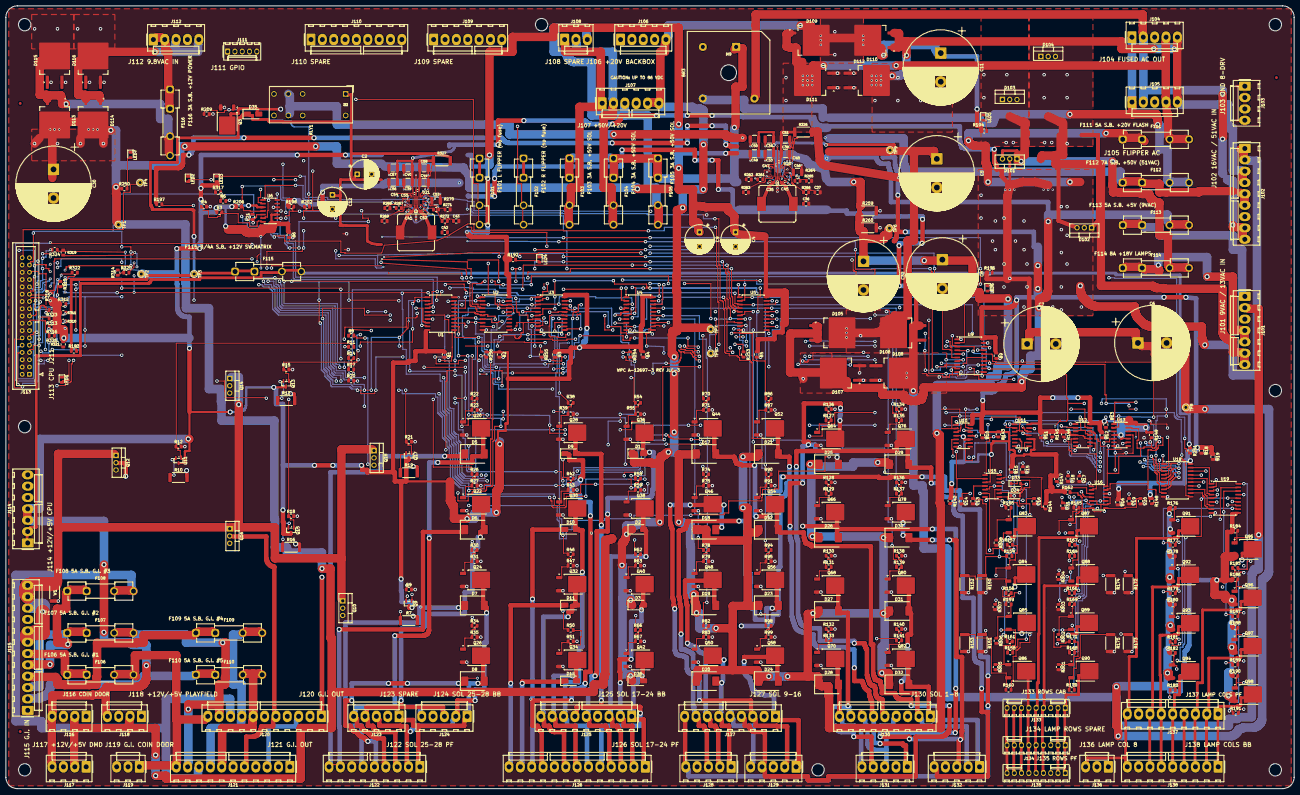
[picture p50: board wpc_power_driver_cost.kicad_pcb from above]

Board: 4 copper layers, 449.2 x 272.9 mm, 446 parts (0 on the bottom side), 294 nets.

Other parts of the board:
FID1, FID2, FID3: FIDUCIAL; Fiducial_1mm_Mask2mm
H9: BR3 M4 bolt; MountingHole_5.5mm

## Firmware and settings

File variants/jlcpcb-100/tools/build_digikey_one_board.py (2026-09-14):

#!/usr/bin/env python3
"""Build a one-board sourcing estimate from recorded public DigiKey facts.

No network access, cart changes, PCB edits, or qualification of substitutes.
"""
import csv
import hashlib
import json
import re
from collections import Counter, defaultdict
from decimal import Decimal, ROUND_HALF_UP
from pathlib import Path

ROOT = Path(__file__).resolve().parents[1]
RESEARCH = ROOT / "research/digikey-1"
OUT = ROOT / "output/digikey-1"
CENT = Decimal("0.01")


def read_csv(path):
    with path.open(newline="", encoding="utf-8-sig") as f:
        return list(csv.DictReader(f))


def write_csv(name, fields, rows):
    with (OUT / name).open("w", newline="", encoding="utf-8-sig") as f:
        writer = csv.DictWriter(f, fieldnames=fields, extrasaction="raise")
        writer.writeheader()
        writer.writerows(rows)


def money(amount):
    return str(amount.quantize(CENT, rounding=ROUND_HALF_UP))


def unique_text(values):
    return " | ".join(dict.fromkeys(v for v in values if v))


def crawl_text(record):
    match = re.search(r"Crawled: ([^;]+)", record.get("source_metadata", ""))
    return match.group(1) if match else "not reported"


def main():
    OUT.mkdir(parents=True, exist_ok=True)
    source = read_csv(ROOT / "output/release-candidate/bom/all-components.csv")
    placements = read_csv(ROOT / "output/release-candidate/jlcpcb-assembly/placement-map.csv")
    catalog = json.loads((RESEARCH / "catalog.json").read_text())
    selection = json.loads((RESEARCH / "selection.json").read_text())
    source_hashes = json.loads((RESEARCH / "source-hashes.json").read_text())
    for name, digest in source_hashes.items():
        assert hashlib.sha256((ROOT / name).read_bytes()).hexdigest() == digest, name

    groups = defaultdict(list)
    place_groups = defaultdict(list)
    for row in source:
        groups[row["JLCPCB_part"] or row["Designator"]].append(row)
    for row in placements:
        place_groups[row["LCSC_part"]].append(row)
    assert len(place_groups) == 69
    assert len(placements) == 440
    assert len({p["Upload_designator"] for p in placements}) == 440
    assert set(selection) <= set(groups)

    bom, prices, reference_map = [], [], []
    required_electronics = 0
    for key, rows in groups.items():
        first = rows[0]
        dnp = all(r["DNP"] == "yes" for r in rows)
        assert len({r["MPN"] for r in rows}) == 1
        choice = selection.get(key, {"mpn": first["MPN"], "status": "exact"})
        status = "DNP_or_board_feature" if dnp else choice["status"]
        selected_mpn = "" if dnp else choice["mpn"] or ""
        record = catalog.get(selected_mpn)
        notes = choice.get("notes", "")
        if status == "candidate_parametric":
            notes = "Yageo RC0805 thick-film candidate: same resistance, +/-1%, 1/8W, 0805. Review working voltage, pulse loading and temperature coefficient. Quote only."
        if key in place_groups:
            positions = place_groups[key]
            required = sum(int(r["Quantity_per_board"]) for r in rows)
            assert required == len(positions), key
            required_electronics += required
            refs = " ".join(r["Upload_designator"] for r in positions)
            native = " ".join(dict.fromkeys(r["Native_reference"] for r in positions))
            assembly_types = {p["Assembly"] for p in positions}
            assembly = "SMT" if assembly_types == {"SMT"} else (
                "Fuse cartridge insertion" if assembly_types == {"Fuse cartridge insertion"} else "Through-hole soldered")
            category = "Electronics"
            assembly_notes = []
            for p in positions:
                note = p["Assembly_note"]
                if note and "CPL" not in note:
                    assembly_notes.append(p["Upload_designator"] + ": " + note)
            notes = unique_text([notes, *[r["Assembly_note"] for r in rows], *assembly_notes])
        else:
            refs = first["Designator"]
            native = first["Parent"]
            required = 0 if dnp else (1 if key == "THERMALPASTE" else int(first["Quantity_per_board"]))
            assembly = first["Assembly"]
            category = "Not purchased" if dnp else ("Consumable" if key == "THERMALPASTE" else "Hardware")
            if dnp:
                notes = first["Assembly_note"]
            elif key == "THERMALPASTE":
                notes = "One complete 3mL syringe charged as initial provision for this one-board build. Actual paste consumption is as needed; remaining paste is reusable. No batch spare allowance."
        needs_review = "yes" if status.startswith("candidate") or status == "unresolved" else "no"
        entry = {
            "Line": len(bom) + 1, "Group_ID": key, "Category": category,
            "Assembly": assembly, "References": refs, "Native_References": native,
            "Value_or_Description": unique_text(r["Value"] for r in rows), "Original_MPN": first["MPN"],
            "Original_Manufacturer": first["Manufacturer"], "Selected_MPN": selected_mpn,
            "Selected_Manufacturer": record["manufacturer"] if record else "",
            "DigiKey_Part_Number": record["sku"] if record else "",
            "Required_Qty_1_Board": required, "Purchase_Qty": "", "Surplus_Qty": "",
            "DNP": "yes" if dnp else "no", "Match_Status": status,
            "Engineering_Review_Required": needs_review, "Original_Footprint": unique_text(r["Footprint"] for r in rows),
            "Notes": notes, "Product_URL": record["url"].split("?")[0] if record else "",
        }
        bom.append(entry)
        for r in rows:
            reference_map.append({"Source_Designator": r["Designator"], "Parent": r["Parent"],
                                  "Source_Quantity": r["Quantity_per_board"], "BOM_Group_ID": key,
                                  "DNP": r["DNP"], "Selected_MPN": selected_mpn})

    cover = catalog["0853.0551"]
    bom.append({
        "Line": len(bom) + 1, "Group_ID": "FUSE_COVERS", "Category": "Added accessory",
        "Assembly": "Manual cover installation", "References": " ".join(p["Upload_designator"] + "_COVER" for p in place_groups["C268204"]),
        "Native_References": " ".join(dict.fromkeys(p["Native_reference"] for p in place_groups["C268204"])),
        "Value_or_Description": "Cover for SCHURTER OGN 5x20mm fuse block",
        "Original_MPN": "Included with FH1-200CK-G", "Original_Manufacturer": "HONGJU",
        "Selected_MPN": "0853.0551", "Selected_Manufacturer": cover["manufacturer"],
        "DigiKey_Part_Number": cover["sku"], "Required_Qty_1_Board": 15,
        "Purchase_Qty": "", "Surplus_Qty": "", "DNP": "no", "Match_Status": "candidate_accessory",
        "Engineering_Review_Required": "yes", "Original_Footprint": "Accessory; no independent PCB pads",
        "Notes": "One cover per selected 0031.8201 fuse block, including two empty holders. Original Hongju holder includes a cover. SCHURTER OGN drawing associates 0853.0551 with 0031.8201. Verify assembled cover envelope. https://media.digikey.com/pdf/Data%20Sheets/Schurter%20PDFs/DS_486_Fuseholders.pdf",
        "Product_URL": cover["url"],
    })

    assert required_electronics == 440
    for entry in bom:
        qty = entry["Required_Qty_1_Board"]
        if entry["DNP"] == "yes":
            entry.update(Purchase_Qty=0, Surplus_Qty=0)
            continue
        record = catalog.get(entry["Selected_MPN"])
        price = {"Row_Type": "ITEM", "Group_ID": entry["Group_ID"], "Category": entry["Category"],
                 "References": entry["References"], "Selected_MPN": entry["Selected_MPN"],
                 "DigiKey_Part_Number": entry["DigiKey_Part_Number"], "Board_Qty": 1,
                 "Required_Qty": qty, "Purchase_Qty": "", "Surplus_Qty": "",
                 "Minimum_Priced_Order_Qty": "", "Applied_Price_Break_Qty": "",
                 "Unit_Price_USD": "", "Required_Parts_Cost_USD": "", "Purchase_Cost_USD": "",
                 "Stock_Snapshot": "", "Stock_Covers_Purchase_Qty": "unknown",
                 "Match_Status": entry["Match_Status"], "Engineering_Review_Required": entry["Engineering_Review_Required"],
                 "Pricing_Status": "UNPRICED_UNRESOLVED", "Product_URL": entry["Product_URL"],
                 "Retrieved_UTC": "", "Source_Crawl_Age": "", "Notes": entry["Notes"]}
        if record:
            assert record["sku"] and record["manufacturer"] and record["prices"], entry
            assert re.fullmatch(r"[A-Za-z0-9][A-Za-z0-9.,+/_-]*-ND", record["sku"]), record["sku"]
            # A page can list CT, reel and Digi-Reel prices. Use the first occurrence
            # of each quantity; CT precedes Digi-Reel when their tables are separate.
            tiers = {}
            for tier in record["prices"]:
                tiers.setdefault(tier["quantity"], Decimal(tier["unit_price_usd"]))
            minimum = min(tiers)
            buy = max(qty, minimum)
            applicable = max(t for t in tiers if t <= buy)
            unit = tiers[applicable]
            assert unit > 0 and minimum <= buy
            # Five fasteners have 100-piece minimum published price tiers.
            # Keep exact required quantities for every other part; no spares/discount overbuy.
            assert minimum == 1 or entry["Group_ID"] in {"M3X8", "M3X12", "M3NUT", "M4X20", "M4NUT"}
            if minimum > 1:
                assert minimum == 100 and buy % 100 == 0
                entry["Notes"] += " Purchase quantity uses the lowest published DigiKey price tier of 100 pieces; excess is retained stock, not a 100-board build."
            price.update(Purchase_Qty=buy, Surplus_Qty=buy-qty,
                         Minimum_Priced_Order_Qty=minimum, Applied_Price_Break_Qty=applicable,
                         Unit_Price_USD=str(unit), Required_Parts_Cost_USD=money(unit * qty),
                         Purchase_Cost_USD=money(unit * buy), Stock_Snapshot=record["stock"],
                         Stock_Covers_Purchase_Qty="yes" if record["stock"] is not None and record["stock"] >= buy else "no",
                         Pricing_Status="PUBLIC_PAGE_ESTIMATE", Retrieved_UTC=record["retrieved_utc"],
                         Source_Crawl_Age=crawl_text(record), Notes=entry["Notes"])
            entry.update(Purchase_Qty=buy, Surplus_Qty=buy-qty)
        prices.append(price)

    priced = [p for p in prices if p["Purchase_Cost_USD"]]
    unresolved = [p for p in prices if not p["Purchase_Cost_USD"]]
    shortfalls = [p for p in priced if p["Stock_Covers_Purchase_Qty"] != "yes"]
    purchase_total = sum((Decimal(p["Purchase_Cost_USD"]) for p in priced), Decimal(0))
    required_total = sum((Decimal(p["Required_Parts_Cost_USD"]) for p in priced), Decimal(0))
    totals = []
    for category in ["Electronics", "Hardware", "Consumable", "Added accessory"]:
        category_rows = [p for p in prices if p["Category"] == category]
        totals.append({"Metric": category + " priced subtotal", "Value": money(sum((Decimal(p["Purchase_Cost_USD"]) for p in category_rows if p["Purchase_Cost_USD"]), Decimal(0))),
                       "Unit": "USD", "Notes": f"{sum(bool(p['Purchase_Cost_USD']) for p in category_rows)} of {len(category_rows)} required lines priced; includes unqualified candidates."})
    totals.extend([
        {"Metric": "Board quantity", "Value": 1, "Unit": "board", "Notes": "No production spare allowance."},
        {"Metric": "Priced parts allocated to one board", "Value": money(required_total), "Unit": "USD", "Notes": "Required quantities valued at applied purchase-tier prices; includes one complete thermal-paste syringe and added covers; excludes unresolved fuse."},
        {"Metric": "Minimum-purchase excess cost", "Value": money(purchase_total-required_total), "Unit": "USD", "Notes": "Extra fasteners required to reach published minimum price tiers."},
        {"Metric": "Priced purchase subtotal", "Value": money(purchase_total), "Unit": "USD", "Notes": "Estimate including candidates and minimum purchases; excludes unresolved fuse."},
        {"Metric": "Required procurement lines", "Value": len(prices), "Unit": "lines", "Notes": "69 original electronic groups + 9 hardware/consumable groups + 1 added cover group."},
        {"Metric": "Priced procurement lines", "Value": len(priced), "Unit": "lines", "Notes": "Every priced line has DigiKey SKU, price tier, source URL and stock snapshot."},
        {"Metric": "Unpriced required lines", "Value": len(unresolved), "Unit": "lines", "Notes": "; ".join(p["References"] + ": " + p["Notes"] for p in unresolved)},
        {"Metric": "Priced stock shortfall lines", "Value": len(shortfalls), "Unit": "lines", "Notes": "Public cached snapshots; availability is not reserved."},
        {"Metric": "Lines requiring engineering review", "Value": sum(p["Engineering_Review_Required"] == "yes" for p in prices), "Unit": "lines", "Notes": "Candidates plus unresolved requirements; not qualified by the existing JLC variant's SPICE results."},
        {"Metric": "DNP or fabricated board features", "Value": sum(e["DNP"] == "yes" for e in bom), "Unit": "positions", "Notes": "Visible at zero purchase quantity in BOM; excluded from pricing."},
        {"Metric": "Final complete BOM total", "Value": "" if unresolved else money(purchase_total), "Unit": "USD", "Notes": "INCOMPLETE: F115 remains unpriced. Priced candidates also require engineering review." if unresolved else "Conditional estimate; candidates require engineering review."},
        {"Metric": "Excluded costs", "Value": "", "Unit": "", "Notes": "PCB fabrication, assembly labor, solder/process consumables other than specified thermal paste, freight, taxes, tariffs, fees and tooling."},
    ])
    for kind, required, purchase, status, note in [
        ("PRICED_SUBTOTAL", money(required_total), money(purchase_total), "PARTIAL_ESTIMATE", "Includes minimum purchase quantities and unqualified candidates; excludes F115."),
        ("FINAL_COMPLETE_BOM_TOTAL", "", "" if unresolved else money(purchase_total), "INCOMPLETE" if unresolved else "CONDITIONAL_ESTIMATE", "F115 0.75A ceramic time-delay fuse remains unresolved/unpriced. A complete board cost cannot yet be stated."),
    ]:
        summary = {k: "" for k in prices[0]}
        summary.update(Row_Type=kind, Board_Qty=1, Required_Parts_Cost_USD=required,
                       Purchase_Cost_USD=purchase, Pricing_Status=status, Notes=note)
        prices.append(summary)

    write_csv("DigiKey-BOM.csv", list(bom[0]), bom)
    write_csv("DigiKey-pricing.csv", list(prices[0]), prices)
    write_csv("DigiKey-totals.csv", ["Metric", "Value", "Unit", "Notes"], totals)
    write_csv("source-reference-coverage.csv", list(reference_map[0]), reference_map)
    assert len(reference_map) == len(source) == 471
    assert len({r["Source_Designator"] for r in reference_map}) == len(source)
    assert len(priced) + len(unresolved) == 79
    assert sum(p["Required_Qty"] for p in prices if p["Category"] == "Electronics") == 440
    assert sum(p["Required_Qty"] for p in prices if p["Category"] == "Hardware") == 30
    assert not shortfalls, shortfalls
    report = {"board_quantity": 1, "spares": 0, "source_rows_covered": len(reference_map),
              "electronic_purchase_units": 440, "assembly_units": dict(Counter(p["Assembly"] for p in placements)),
              "original_procurement_groups": 78, "added_cover_quantity": 15,
              "bom_rows": len(bom), "required_pricing_lines": len(priced)+len(unresolved),
              "priced_lines": len(priced), "unpriced_groups": [p["Group_ID"] for p in unresolved],
              "priced_purchase_subtotal_usd": money(purchase_total),
              "priced_required_parts_cost_usd": money(required_total),
              "final_complete_bom_total_usd": None if unresolved else money(purchase_total),
              "engineering_review_lines": sum(e["Engineering_Review_Required"] == "yes" for e in bom),
              "native_pcb_and_release_inputs_unchanged": True, "source_sha256": source_hashes,
              "validation": "PASS: coverage, quantities, stock snapshots, price tiers, positive prices and source hashes; NOT electrical/mechanical approval."}
    (OUT / "validation.json").write_text(json.dumps(report, indent=2) + "\n")
    print(json.dumps(report, indent=2))


if __name__ == "__main__":
    main()

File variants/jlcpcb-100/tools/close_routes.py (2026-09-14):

#!/usr/bin/env python3
"""Conservative incremental copper routing on an isolated board (Shapely/Numba).

Uses physical pads/tracks, actual project net classes, through-hole spacing,
three signal layers, and exact polygon validation after grid search. Does not
remove existing copper, alter rules, or install the candidate. KiCad DRC remains
mandatory. Filled zones are left to KiCad; ground stitching is a separate step.
"""
import argparse, fnmatch, heapq, json, math, time, uuid
from pathlib import Path
import numpy as np
from numba import njit
import shapely
from shapely.geometry import Point, LineString, box
from shapely.affinity import rotate, translate
from shapely.ops import unary_union, nearest_points
from sexp import parse, dump, find, find_all, S
LAYERS = ['F.Cu', 'In2.Cu', 'B.Cu']

@njit(cache=True)
def search(block, vias, source, target, bounds):
    L,H,W=block.shape; N=L*H*W
    dist=np.full(N,2147483647,np.int32); prev=np.full(N,-1,np.int32)
    heap=[(0,0,0)];heap.pop()
    x0,y0,x1,y1=bounds
    for l,y,x in zip(*np.where(source)):
        i=(l*H+y)*W+x;dist[i]=0
        h=10*(max(x0-x,0,x-x1)+max(y0-y,0,y-y1))
        heapq.heappush(heap,(h,0,i))
    while heap:
        _,d,i=heapq.heappop(heap)
        if dist[i]!=d:continue
        x=i%W;y=(i//W)%H;l=i//(W*H)
        if target[l,y,x]:return prev,i
        for k in range(6):
            xx=x;yy=y;ll=l;cost=10
            if k==0:xx+=1
            elif k==1:xx-=1
            elif k==2:yy+=1
            elif k==3:yy-=1
            else:
                if vias[y,x]:continue
                ll=(l+(1 if k==4 else 2))%3;cost=250
            if xx<0 or yy<0 or xx>=W or yy>=H or block[ll,yy,xx]:continue
            j=(ll*H+yy)*W+xx;nd=d+cost
            if nd<dist[j]:
                dist[j]=nd;prev[j]=i
                h=10*(max(x0-xx,0,xx-x1)+max(y0-yy,0,yy-y1))
                heapq.heappush(heap,(nd+h,nd,j))
    return prev,-1

def xy(o,k):return tuple(map(float,find(o,k)[1:3]))
def net(o):
    n=find(o,'net');return str(n[-1]) if n else ''
def uid(o):return str(find(o,'uuid')[1])
def circle(x,y,r):return Point(x,y).buffer(r,quad_segs=16)

class Board:
    def __init__(self,path):
        self.path=path;self.doc=parse(path.read_text())[0];self.items=[];self.holes=[];self.smd=[];self.new=[];self.plane_tracks=[]
        pro=json.loads(path.with_suffix('.kicad_pro').read_text())['net_settings']
        self.classes={c['name']:c for c in pro['classes']};self.patterns=pro['netclass_patterns']
        for f in find_all(self.doc,'footprint'):
            ref=next(v[2] for v in find_all(f,'property') if v[1]=='Reference')
            fa=find(f,'at');fx,fy=map(float,fa[1:3]);ang=float(fa[3]) if len(fa)>3 else 0
            for p in find_all(f,'pad'):
                a=find(p,'at');rx,ry=map(float,a[1:3]);rad=math.radians(ang)
                x=fx+rx*math.cos(rad)+ry*math.sin(rad);y=fy-rx*math.sin(rad)+ry*math.cos(rad)
                pa=float(a[3]) if len(a)>3 else ang;w,h=xy(p,'size');shape=str(p[3])
                if shape=='circle':poly=circle(0,0,w/2)
                elif shape=='oval':
                    poly=LineString([(-(w-h)/2,0),((w-h)/2,0)]).buffer(h/2) if w>=h else LineString([(0,-(h-w)/2),(0,(h-w)/2)]).buffer(w/2)
                elif shape=='roundrect':
                    r=min(w,h)*float(find(p,'roundrect_rratio')[1])
                    poly=box(-w/2+r,-h/2+r,w/2-r,h/2-r).buffer(r,quad_segs=16)
                elif shape=='rect':poly=box(-w/2,-h/2,w/2,h/2)
                else:raise ValueError(f'Unsupported pad geometry {shape}')
                poly=translate(rotate(poly,-pa,origin=(0,0)),x,y)
                ls=[str(z) for z in find(p,'layers')[1:]];layers=list(range(3)) if '*.Cu' in ls or 'F&B.Cu' in ls else [i for i,l in enumerate(LAYERS) if l in ls]
                override=find(p,'clearance')
                self.items.append(dict(id=uid(p),net=net(p),poly=poly,layers=layers,pin=f'{ref}.{p[1]}',hole_clearance=.25 if p[2]=='np_thru_hole' else 0,
                                       local_clearance=float(override[1]) if override else None))
                dr=find(p,'drill')
                if dr:
                    nums=[float(v) for v in dr[1:] if not isinstance(v,list) and v!='oval']
                    self.holes.append(circle(x,y,max(nums)/2))
                if p[2]=='smd':self.smd.append(poly)
        for t in find_all(self.doc,'segment'):
            layer=str(find(t,'layer')[1])
            if layer not in LAYERS:
                self.plane_tracks.append(LineString([xy(t,'start'),xy(t,'end')]).buffer(float(find(t,'width')[1])/2+.4));continue
            self.items.append(dict(id=uid(t),net=net(t),poly=LineString([xy(t,'start'),xy(t,'end')]).buffer(float(find(t,'width')[1])/2),layers=[LAYERS.index(layer)]))
        if find_all(self.doc,'arc'):raise ValueError('Track arcs unsupported')
        for v in find_all(self.doc,'via'):
            x,y=xy(v,'at');self.holes.append(circle(x,y,float(find(v,'drill')[1])/2))
            self.items.append(dict(id=uid(v),net=net(v),poly=circle(x,y,float(find(v,'size')[1])/2),layers=list(range(3)),via=(x,y)))
        self.contacts=[];self.contact_windows=box(0,0,0,0)
    def params(self,n):
        names=[p['netclass'] for p in self.patterns if fnmatch.fnmatchcase(n,p['pattern'])]
        return self.classes[names[0] if names else 'Default']
    def groups(self,n):
        items=[v for v in self.items if v['net']==n];parent=list(range(len(items)))
        def root(i):
            while parent[i]!=i:parent[i]=parent[parent[i]];i=parent[i]
            return i
        geoms=[v['poly'] for v in items]
        if geoms:
            pairs=shapely.STRtree(geoms).query(geoms,predicate='dwithin',distance=.00002)
            for i,j in zip(*pairs):
                if i>j and set(items[i]['layers'])&set(items[j]['layers']):parent[root(i)]=root(j)
        groups={}
        for i,v in enumerate(items):groups.setdefault(root(i),[]).append(v)
        # Small branches first, targeting all already routed copper of this net.
        return sorted(groups.values(),key=lambda g:sum(v['poly'].area for v in g))
    def route(self,n,pitch,grid_margin=None,ground_pin=None,local=True,source_pin=None):
        groups=self.groups(n)
        if len(groups)<2:return 'connected'
        source=groups[0];target=[v for g in groups[1:] for v in g]
        if source_pin:
            source=next(g for g in groups if any(v.get('pin')==source_pin for v in g))
            def original(v):return v['id'] in self.original_ids
            if any(original(v) for v in source):return 'connected to existing copper'
            target=[v for g in groups if g is not source for v in g if original(v)]
            origin=unary_union([v['poly'] for v in source]);target=sorted(target,key=lambda v:origin.distance(v['poly']))[:100]
        c=self.params(n);width=.4;dia=1.;drill=.5;clear=c['clearance']
        options=getattr(self,'routing_options',{})
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

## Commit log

2026-09-08 unverifed design
    [board_plane_v1.kicad_pcb, board_v1_fast.kicad_pcb, board_v1_narrow_bus.kicad_pcb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]
2026-09-09 Prepare WPC engineering candidate and verification tooling
    Include revised PCB and schematics, component models, fabrication exports, renders, BOM, assembly counts, and reproducible electrical and manufacturing checks. Document unresolved replay convergence,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
    [3M_N2534_6002_RB_envelope.step, Bourns_SRP1265A_envelope.step, Boyd_5771_simplified.step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]
2026-09-12 Add JLCPCB board variant and verification evidence
    Preserve the JLC-2 native CAD, JLCPCB electronics sourcing, flasher-clamp
    correction, manufacturing exports, and current review archives.
    Record Linux SPICE, MAME/PinMAME, logic, mechanical, and manufacturing
    checks, including coil convergence and the remaining regulator and matrix
    findings. Retain the prototype hold and document further verification work.
    Include PCBWay review drafts and exclude local scratch data, bulk trace
    dumps, emulator state, and obsolete JLC-1 packages. Stop tracking generated
    Python bytecode.
    [12v_loss_restart_0.02A_250n.csv, 12v_loss_restart_0.75A_250n.csv, 12v_loss_restart_2A_250n.csv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]
2026-09-14 Document experimental variants and add complete assembly sourcing files
    Preserve the JLC-3 prototype updates and add the JLC-100 inventory variant,
    native CAD, manufacturing exports, mixed SMT/through-hole BOM and CPL,
    connector orientation evidence, and recorded SPICE/verification results.
    Add the separate one-board DigiKey BOM and itemized pricing proposal,
    including hardware, minimum purchase quantities, and the unresolved F115 fuse.
    Lead the project and variant READMEs with an explicit experimental-board,
    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
    [3M_N2534_6002_RB_envelope.step, BOM.csv, Bourns_SRP1265A_envelope.step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]
